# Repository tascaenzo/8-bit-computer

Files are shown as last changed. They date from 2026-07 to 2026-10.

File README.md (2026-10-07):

# CPU 8-bit

Repository di supporto alla serie didattica YouTube in cui viene progettata e costruita una CPU a 8 bit partendo dai blocchi logici fondamentali.

In questa fase il repository contiene documentazione, una prima ISA, esempi assembly, un assembler in C e strumenti di supporto per programmare le memorie della CPU.

## Contenuto

```text
.
├── docs/
├── examples/
│   └── assembly/
├── hardware/
│   ├── alu-pcb/
│   ├── data-bus-pcb/
│   ├── address-bus-pcb/
│   └── tang-nano-9k-video/
├── tools/
│   ├── assembler/
│   ├── cu-bytecode/
│   └── eeprom-programmer/
├── wiki/
│   ├── blog/
│   └── videos/
└── README.md
```

### `docs`

Contiene la documentazione tecnica della CPU:

- [`docs/isa.md`](docs/isa.md) definisce architettura, istruzioni e opcode;
- [`docs/assembly-language.md`](docs/assembly-language.md) definisce la sintassi dei programmi assembly.
- [`docs/control-unit-microcode.md`](docs/control-unit-microcode.md) definisce segnali e microsequenze della Control Unit.
- [`docs/video-hdmi.md`](docs/video-hdmi.md) definisce VRAM e uscita HDMI della Tang Nano 9K.
- [`docs/io-ps2-timer.md`](docs/io-ps2-timer.md) definisce registri I/O, tastiera PS/2 e timer della Tang Nano 9K.

### `examples/assembly`

Contiene programmi assembly didattici usati per provare l'assembler e spiegare le istruzioni della CPU.

### Schede PCB in `hardware`

Progetti KiCad e pacchetti Gerber per l'[ALU con LED e comandi locali](hardware/alu-pcb/rev-b/README.md),
il [bus dati a otto porte con monitor LED](hardware/data-bus-pcb/README.md)
e il [bus indirizzi a 16 bit](hardware/address-bus-pcb/README.md).
I due bus usano il layout slim del 7 ottobre 2026, entrambi **REV A**:
**235 × 40 mm** per i dati e **300 × 46 mm** per gli indirizzi,
con la firma «Progettato da Enzo Tasca» sul fronte, LED ravvicinati a gruppi
di quattro bit e uno switch SW1 per spegnere gli indicatori del bus.
ALU e bus dati hanno connettori dati compatibili; il bus indirizzi usa porte 2×10 dedicate. I controlli software sono
completati; i prototipi fisici devono ancora essere montati e collaudati.

### `hardware/tang-nano-9k-video`

Contiene il progetto Gowin per la Tang Nano 9K. Il primo milestone verifica
l'uscita HDMI prima di introdurre VRAM e interfaccia al bus TTL.

### `tools/assembler`

Contiene `cpu8asm`, l'assembler in C che traduce i programmi assembly in byte macchina.

### `tools/eeprom-programmer`

Contiene sketch e documentazione per programmare EEPROM parallele usate dalla CPU, come la AT28C64.

La guida passo passo per il programmatore AT28C64 con Arduino Mega e in:

```text
docs/at28c64-arduino-mega-programmer.md
```

### `tools/cu-bytecode`

Contiene `cpu8microcode`, il generatore C delle tre Control ROM e della ROM di
dispatch. La guida di build e la mappa dei bit sono in
[`tools/cu-bytecode/README.md`](tools/cu-bytecode/README.md).

### `tools/simulator-web`

Contiene il simulatore web step-by-step della ISA: permette di assemblare ed
eseguire programmi nel browser, osservando registri, flag, RAM e la memoria
video mappata nella FPGA. La guida di avvio è in
[`tools/simulator-web/README.md`](tools/simulator-web/README.md).

### `wiki/videos`

Contiene le trascrizioni autogenerate dei video della serie.

Le trascrizioni sono materiale grezzo: possono contenere errori di riconoscimento, frasi incomplete o termini tecnici interpretati male. Servono come base di lavoro per ricostruire gli argomenti trattati nei video.

### `wiki/blog`

Contiene articoli tecnici in italiano ricavati dalle trascrizioni e dagli argomenti gia affrontati.

Gli articoli seguono il percorso reale della serie e non anticipano parti non ancora consolidate.

## Argomenti documentati

Finora la documentazione copre:

- operazioni logiche della ALU: `AND`, `OR`, `XOR`, `NOR`, `NAND`, `XNOR`, `NOT`;
- pull-up, pull-down e comportamento dei livelli logici;
- buffer tri-state e collegamento al bus dati;
- somma binaria con half adder e full adder;
- complemento a due e numeri con segno;
- somma e sottrazione con il 74283;
- flag `Carry`, `Negative`, `Zero` e `Overflow`;
- operazioni di confronto tramite flag;
- codice operazione della ALU;
- segnale di clock;
- flip-flop `SR` e `D`.

## Convenzioni

- La documentazione principale e in italiano.
- I nomi tecnici possono restare in inglese quando corrispondono meglio a datasheet, segnali o architettura.
- Le trascrizioni autogenerate non sono considerate documentazione definitiva: vanno ripulite e corrette quando vengono trasformate in articoli.

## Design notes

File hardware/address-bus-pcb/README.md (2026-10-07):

# CPU8 — bus indirizzi a 16 bit, revisione A

Layout slim con LED compatti e switch del 7 ottobre 2026: **300 × 46 mm**, rispetto ai precedenti
240 × 60 mm. I due 74HCT244 seguono la fila degli otto connettori sul lato
destro. Serigrafia sul fronte: **Progettato da Enzo Tasca**. Revisione **A**.
Le piedinature elettriche restano uguali.

Scheda di distribuzione con **otto porte parallele**, **16 LED A15…A0**,
due buffer SN74HCT244N e una spia PWR. PCB **300 × 46 mm**, due strati,
componenti through-hole, altezza ridotta per una disposizione a vista nel case.

Le porte sono equivalenti. PC, MAR o IDX possono trasmettere un indirizzo;
RAM, ROM, decoder e altri moduli possono leggerlo contemporaneamente.
La scelta della sorgente è esterna: questa scheda non genera indirizzi e
non implementa il selettore della centralina.

## File da usare

- `CPU8_ADDRESS_BUS_REV_A_GERBER.zip`: file di produzione della scheda nuda.
- `CPU8_ADDRESS_BUS_REV_A_PROJECT.zip`: progetto modificabile e documentazione.
- `source/address_bus_rev_a.kicad_pro`: progetto da aprire in KiCad.
- `address_bus_rev_a_schematic.pdf`: schema elettrico, quattro pagine.
- `address_bus_rev_a_preview.png`: anteprima del PCB senza componenti montati.
- `address_bus_rev_a_layout.svg`: piste, piazzole e serigrafia.
- `BOM.csv`: componenti, package e dimensioni di montaggio.
- `verification/`: rapporti elettrici, di layout, di verifica digitale e manifest SHA-256.

I componenti vanno acquistati e saldati separatamente. Non è stato
eseguito alcun ordine presso un produttore.

## Connettori indirizzi J1…J8

Header maschi **2×10, passo 2,54 mm, non schermati**. Guardando il lato
componenti con il titolo in alto, il pin 1 quadrato è in alto a sinistra.
Le righe sono 1/2, 3/4, ecc. Collegare i cavi pin-a-pin, senza inversioni.

| Riga | Sinistra | Destra |
| --- | --- | --- |
| 1 | 1: A0 | 2: A1 |
| 2 | 3: A2 | 4: A3 |
| 3 | 5: A4 | 6: A5 |
| 4 | 7: A6 | 8: A7 |
| 5 | 9: A8 | 10: A9 |
| 6 | 11: A10 | 12: A11 |
| 7 | 13: A12 | 14: A13 |
| 8 | 15: A14 | 16: A15 |
| 9 | 17: GND | 18: GND |
| 10 | 19: GND | 20: GND |

A0 è il bit meno significativo dell'indirizzo; A15 è il più significativo.
Queste porte **non contengono +5 V** e non hanno la stessa piedinatura delle
porte da 10 pin del bus dati. A0…A15 qui indicano indirizzi, non l'operando
A della ALU: non collegare queste porte agli ingressi A/B dell'ALU.

## Alimentazione J9

Header 2×2 con pin **1/3 = +5 V**, **2/4 = GND**. È la stessa piedinatura
del J9 del bus dati e del J6 dell'ALU. Alimentare tutte le schede da una
sorgente comune a 5 V regolati e collegare le masse. I moduli ricevono
+5 V dai loro connettori di alimentazione, non attraverso le porte indirizzi.
I pin duplicati di J9 appartengono alla stessa rete.

## Monitor LED e trasmissione degli indirizzi

U1 legge A0…A7 e U2 legge A8…A15. Le loro uscite pilotano soltanto i LED
attraverso resistori da 2,2 kΩ; nessuna uscita del monitor pilota il bus.
SW1 pilota insieme i pin 1 e 19 di U1 e U2: ON li porta a GND e abilita
i 16 LED; OFF li lascia alti tramite R18 da 10 kΩ e disabilita le uscite LED.
I due buffer separano il carico dei LED dalle linee di indirizzo; **non
rigenerano il segnale lungo i collegamenti del bus**. La piedinatura segue
il [datasheet TI SN74HCT244](https://www.ti.com/lit/ds/symlink/sn74hct244.pdf).

RN1 e RN2 aggiungono un pull-down da 10 kΩ per ogni bit, con carico
nominale di 0,5 mA per linea alta a 5 V. Con la scheda da sola e senza
una sorgente, i LED indirizzo restano spenti. Questo non distingue un
indirizzo 0000 trasmesso da un bus non pilotato.

I LED sono ordinati da sinistra **A15, A14, …, A1, A0** e mostrano il valore
istantaneo, senza memorizzarlo. Con dati statici o clock manuale si legge
il numero binario; a velocità elevate si vede una luminosità media. Per
catturare un indirizzo a un preciso istante serve un latch o un analizzatore.

**Abilitare una sola sorgente di indirizzo alla volta.** Le uscite di PC,
MAR e IDX devono raggiungere il bus tramite buffer tri-state o un selettore
appropriato. Non collegare in parallelo tre uscite push-pull sempre attive.
RAM e ROM leggono gli indirizzi dai propri ingressi; i comandi di memoria
/CE, /OE, /WE e i dati D0…D7 viaggiano separatamente.

Nel progetto CPU8, `ADDR_SEL` sceglie `00=IDX`, `01=PC`, `10=MAR`,
`11=nessuna sorgente`: vedere [la centralina](../../docs/control-unit-microcode.md).
Il decoder di queste abilitazioni resta sui moduli o nella centralina,
non su questa scheda bus. La mappa degli indirizzi e la selezione RAM/ROM/I/O
restano compito dei rispettivi decoder.

Esempio di assegnazione, modificabile perché tutte le porte sono uguali:

| Porta | Modulo |
| --- | --- |
| J1 | PC, uscita tri-state |
| J2 | MAR, uscita tri-state |
| J3 | IDX, uscita tri-state |
| J4 | RAM, ingressi indirizzo |
| J5 | ROM, ingressi indirizzo |
| J6 | Decoder di indirizzi |
| J7 | Modulo I/O o video, con adattamento dei livelli dove necessario |
| J8 | Espansione o strumento di misura |

Il bus è a 5 V: per FPGA e dispositivi a 3,3 V usare adattamento dei livelli
compatibile con i dispositivi effettivi. Iniziare con pochi moduli e cavi
corti. Frequenza massima, integrità del segnale e carichi dei cavi non sono
stati misurati sul prototipo.

## LED ravvicinati e interruttore SW1

I LED hanno un interasse di **4 mm**, con **2 mm aggiuntivi ogni quattro bit**:
A15 A14 A13 A12 | A11 A10 A9 A8 | A7 A6 A5 A4 | A3 A2 A1 A0.
I LED dati/indirizzo hanno i piedini disposti verticalmente, distanti 2,54 mm:
**pin 1 catodo in alto, pin 2 anodo in basso**. PWR mantiene i piedini
orizzontali con catodo a sinistra. Le piazzole quadrate identificano il pin 1.

**SW1 = C&K SDA01H0BD**, SPST a una posizione, through-hole, file distanti
7,62 mm; pin 1 = `LED_OE_n`, pin 2 = GND. **ON chiude il contatto**.
R18 è un resistore assiale **10 kΩ**, 1/4 W, passo 7,62 mm, tra +5 V e OE_n.
Un solo switch governa tutti i buffer LED di questa scheda.

- **ON:** OE_n basso; i LED mostrano i bit del bus.
- **OFF:** OE_n alto; le uscite dei 74HCT244 sono in alta impedenza e i LED
  dei bit sono inattivi. La spia PWR resta accesa.
- L'interruttore non interrompe dati, indirizzi o alimentazione degli altri
  moduli; i pull-down del bus restano presenti. Non è un interruttore generale.

Il livello alto/basso e lo stato tri-state seguono il
[datasheet TI SN74HCT244](https://www.ti.com/lit/ds/symlink/sn74hct244.pdf).
Ingombro e piedinatura di SW1 seguono il
[datasheet C&K SDA](https://www.ckswitches.com/media/1327/sda.pdf).

## Distinta e montaggio

52 componenti: due SN74HCT244N, otto header 2×10, un header 2×2, 17 LED
verdi da 3 mm, 17 resistori da 2,2 kΩ, due reti resistive e tre condensatori, più SW1 e il pull-up R18 da 10 kΩ.
Aggiungere **due zoccoli DIP-20**, con file distanti 7,62 mm.

- U1/U2: package PDIP-20, tacca in alto; pin 1 quadrato.
- D1…D16: rispettivamente LED dei bit A0…A15. Seguire il nome A del bit
  sotto il LED: ad esempio il componente D16 è la spia A15.
- D17: spia PWR. LED passo 2,54 mm: **pin 1 catodo**, pin 2 anodo;
  la linea piatta in serigrafia indica il catodo.
- R1…R17: 2,2 kΩ, 1/4 W, passo 7,62 mm, corpo entro 6,3 × 2,5 mm.
  Usare LED ad alta efficienza: corrente nell'ordine di 1 mA.
- RN1/RN2: **SIP-9 bussed, otto resistenze da 10 kΩ**, comune al pin 1,
  passo 2,54 mm. Le reti a resistenze isolate non sono compatibili.
- C1/C2: 100 nF ceramici, passo 2,50 mm, corpo entro 4 × 3 mm.
- C3: 10 µF, almeno 16 V, passo 2,50 mm, diametro entro 5 mm;
  **pin 1 positivo**, pin 2 GND. Il PCB riporta il simbolo +.
- I pin GND sono collegati ai piani con connessioni solide: usare una
  punta da saldatura adeguata al trasferimento di calore.

## Ordine e verifiche

| Parametro | Valore |
| --- | --- |
| Dimensioni | **300 × 46 mm** |
| Materiale / spessore | FR-4 / 1,6 mm |
| Rame | Due strati, 1 oz |
| Maschera / serigrafia | Verde / bianca sul fronte |
| Finitura | HASL senza piombo o ENIG |
| Assemblaggio / stencil | Nessuno, montaggio manuale |
| Piste / clearance | 0,30 mm, restringimenti fino a 0,15 mm / 0,25 mm |
| Minimo assoluto di clearance | 0,20 mm |
| Via | Diametro 0,70 mm, foro 0,30 mm |
| Fori componenti | 0,80 e 0,90 mm, metallizzati |
| Montaggio | Quattro fori da 3,20 mm, non metallizzati |

Caricare il solo ZIP Gerber e controllare nell'anteprima del produttore
300 × 46 mm, due strati di rame e i due file di foratura.

- ERC: **0 violazioni**.
- DRC: **0 violazioni**, **0 collegamenti mancanti**.
- Parità PCB/schema: **0 problemi**.
- Verifica di **131.072 casi**, tutti i 65.536 indirizzi da 0000 a FFFF
  con SW1 ON e OFF (indicatori inattivi e porte bus invariate quando OFF),
  con controllo delle otto porte, polarità dei LED e isolamento del monitor.
- Export KiCad 10.0.7 e integrità dei pacchetti ZIP verificata.

**Il prototipo fisico deve ancora essere montato e collaudato.** Prima di
inserire gli IC verificare alimentazione e polarità degli zoccoli. Accendere
inizialmente con corrente limitata e moduli esterni scollegati; provare poi
una sola sorgente con indirizzi statici prima di aggiungere gli altri moduli.

| Indirizzo di prova | LED accesi |
| --- | --- |
| 0000 | Nessuno, PWR resta acceso |
| 8001 | A15 e A0 |
| 5555 | A14, A12, A10, A8, A6, A4, A2, A0 |
| AAAA | A15, A13, A11, A9, A7, A5, A3, A1 |
| FFFF | Tutti i 16 LED indirizzo |

Per le prove dei LED portare **SW1 ON**. Gli indirizzi nella tabella sono esadecimali. I LED non provano da soli
che una sorgente sia disabilitata o che non esista un conflitto tra driver.

Gli script in `tools/` documentano generazione e controlli. Il generatore
preserva il PCB esistente salvo `--rebuild-unrouted`; quel comando richiede
nuovo instradamento DSN/SES, controlli ed export. Per le normali modifiche
usare i sorgenti KiCad finali, preservando le piste.

## Disposizione meccanica del layout slim

- Quattro fori di montaggio da 3,2 mm: (4,4), (296,4), (4,42), (296,42) mm; origine nell'angolo superiore sinistro.
- J1…J8: pin 1 a x=10,35,60,85,110,135,160,185 mm, y=8 mm.
- U1/U2: pin 1 rispettivamente (217,8) e (242,8) mm.
- LED da sinistra A15…A0, pin 1 a x=68,72,76,80,86,90,94,98,104,108,112,116,122,126,130,134 mm e y=39 mm; alimentazione J9 a destra.
- Componenti sempre sul fronte, integrati con tacca verso l'alto. I valori
  di header, resistori, reti resistive e switch sono sul layer F.Fab.
  I riferimenti dei LED indirizzo sono su F.Fab, lasciando soltanto A15…A0 sul fronte.
- Lo spazio per i corpi dei connettori è riferito agli header non schermati
  della BOM; verificare l'ingombro dei terminali del cavo scelti per il case.

Questa revisione A sostituisce il precedente layout A da 240 × 60 mm.
Il manifest riporta layout_id `2026-10-07-slim-led-switch` per distinguerli: usare
solo i Gerber e le forature rigenerati insieme in questa consegna.

Questa consegna sostituisce anche il precedente layout slim senza SW1.
Il manifest identifica `2026-10-07-slim-led-switch`: usare gli ZIP rigenerati
insieme allo schema e alla BOM di questa versione. Le dimensioni esterne
e i fori di montaggio restano quelli del layout slim.

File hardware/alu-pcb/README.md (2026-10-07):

# CPU8 — ALU, revisione corrente B

Il progetto corrente è in [rev-b](rev-b/README.md). Include LED degli
operandi, dei flag e dell'operazione, più selezione esterna o standalone.

- [Gerber per la produzione](rev-b/CPU8_ALU_REV_B_GERBER.zip)
- [Progetto KiCad completo](rev-b/CPU8_ALU_REV_B_PROJECT.zip)
- [Istruzioni e distinta componenti](rev-b/README.md)

La revisione A e i suoi export sono stati eliminati.

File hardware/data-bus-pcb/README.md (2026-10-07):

# CPU8 — bus dati a 8 bit, revisione A

Layout slim con LED compatti e switch del 7 ottobre 2026: **235 × 40 mm**, rispetto ai precedenti 180 × 60 mm.
Il 74HCT244 segue la fila degli otto connettori sul lato destro.
Serigrafia sul fronte: **Progettato da Enzo Tasca**. Questa versione usa la
revisione **A**, come richiesto, e sostituisce il precedente layout B.
Le piedinature elettriche rimangono compatibili con ALU J4/J6.

PCB da saldare con **otto porte bidirezionali** J1…J8, **otto LED D7…D0**,
un buffer per gli indicatori e una spia PWR. Tutte le porte sono collegate
in parallelo: qualunque porta può essere usata da un modulo che legge
oppure da un modulo che scrive. Il connettore dati è compatibile con
**J4 dell'ALU revisione A** del repository.

La scheda distribuisce dati e massa. L'alimentazione del monitor entra da
J9; il clock, i comandi LOAD e le abilitazioni delle uscite viaggiano
separatamente, dalla centralina ai rispettivi moduli.

## File consegnati

- `CPU8_DATA_BUS_REV_A_GERBER.zip`: da caricare sul servizio di produzione PCB.
- `CPU8_DATA_BUS_REV_A_PROJECT.zip`: sorgenti KiCad, librerie, schema, BOM e rapporti.
- `source/data_bus_rev_a.kicad_pro`: progetto da aprire in KiCad.
- `data_bus_rev_a_schematic.pdf`: schema elettrico, tre pagine.
- `data_bus_rev_a_preview.png`: anteprima della scheda nuda, senza modelli dei componenti.
- `data_bus_rev_a_layout.svg`: piste e serigrafia.
- `BOM.csv`: distinta con valori, package e dimensioni per il montaggio.
- `verification/`: controlli elettrici, di layout, di collegamento e integrità degli export.

Lo ZIP Gerber ordina una **scheda vuota**: i componenti e gli zoccoli vanno
acquistati e saldati separatamente. Non è stato effettuato alcun ordine.

## Piedinatura

Guardando il lato componenti con il titolo in alto, il pin 1 è la piazzola
quadrata in alto a sinistra. Tutti i connettori hanno due colonne a passo
2,54 mm: righe 1/2, 3/4, 5/6, ecc.

| Porta dati J1…J8 | Colonna sinistra | Colonna destra |
| --- | --- | --- |
| Riga 1 | Pin 1: D0 | Pin 2: D1 |
| Riga 2 | Pin 3: D2 | Pin 4: D3 |
| Riga 3 | Pin 5: D4 | Pin 6: D5 |
| Riga 4 | Pin 7: D6 | Pin 8: D7 |
| Riga 5 | Pin 9: GND | Pin 10: GND |

**Le porte dati non contengono +5 V.** Usare header maschi non schermati
2×5 e cavi con collegamento pin-a-pin. Non ruotare il connettore di 180°;
controllare i cavi con il tester prima dell'accensione.

| J9 POWER_5V | Colonna sinistra | Colonna destra |
| --- | --- | --- |
| Riga 1 | Pin 1: +5 V | Pin 2: GND |
| Riga 2 | Pin 3: +5 V | Pin 4: GND |

J9 è un header 2×2 con la stessa piedinatura di J6 dell'ALU. Alimentare
monitor e moduli da una sorgente comune a **5 V regolati** e collegare le
masse. I moduli ricevono +5 V dai loro connettori di alimentazione, non
attraverso J1…J8. I pin duplicati di J9 sono la stessa rete, non due ingressi
di alimentazione indipendenti.

## Come si legge e si scrive sul bus

**Lettura:** collegare gli ingressi dati di un registro o di un altro
circuito a una porta. Quel modulo acquisisce il dato quando riceve il suo
clock/comando LOAD. Il bus non genera questi comandi.

**Scrittura:** collegare le uscite di un buffer tri-state del modulo a una
porta. La centralina abilita quel buffer quando il modulo deve trasmettere
il dato; lo disabilita negli altri momenti. Esempi sono un registro con
buffer 74HCT244/245, l'uscita della RAM opportunamente controllata o J4
dell'ALU. **Può essere abilitato un solo modulo che scrive alla volta**;
più moduli possono leggere contemporaneamente.

Non collegare direttamente sul bus uscite push-pull sempre attive di
registri o porte logiche. Questa scheda non contiene un arbitro e non
rileva due moduli che pilotano il bus contemporaneamente. Anche se i LED
mostrano un valore, non significa che le abilitazioni siano corrette.

Il monitor U1 è un [SN74HCT244N](https://www.ti.com/lit/ds/symlink/sn74hct244.pdf):
i suoi ingressi leggono il bus, le sue uscite alimentano soltanto i LED.
Il carico dei LED è quindi separato dalle linee dati. Le due abilitazioni
del monitor, pin 1 e 19, sono collegate alla rete `LED_OE_n`: **SW1 ON**
le porta a GND e abilita gli indicatori; **SW1 OFF** le lascia alte tramite
R10 da 10 kΩ e disabilita le uscite LED. Nessuna uscita attiva del monitor pilota D0…D7.

RN1 aggiunge un pull-down da 10 kΩ per bit, con carico nominale di 0,5 mA
quando un bit è a 5 V. Con questa scheda da sola e senza un trasmettitore,
i LED dati sono spenti. Gli indicatori non distinguono uno zero trasmesso
da un bus non pilotato. Con moduli esterni, verificare il carico totale e
le tensioni effettive del bus durante il collaudo.

I LED visualizzano il valore istantaneo e non lo memorizzano: sono utili
con dati statici e clock manuale. A velocità elevate l'occhio vede una
luminosità media; per catturare un byte a un preciso istante occorre un
registro o un analizzatore logico. La scheda non include un latch del display.

Gli ingressi del monitor accettano livelli TTL. Il bus resta un'interfaccia
logica a 5 V: per FPGA e altri dispositivi a 3,3 V usare adattamento dei
livelli adeguato ai dispositivi effettivi. Nessuna frequenza massima è
stata misurata. Per iniziare usare pochi moduli e cavi corti.

## Collegamento all'ALU esistente

1. Collegare **ALU J4 → BUS J1**, pin-a-pin. J2…J8 restano disponibili.
2. Alimentare **ALU J6** e **BUS J9** con la stessa sorgente a 5 V e GND.
3. Sul bus mettere **SW1 ON** per accendere gli indicatori. Sull'ALU mettere SW4 ON per gli operandi locali, inizialmente SW5 OFF.
4. Impostare A = `00000101`, B = `00000011`, OP = `0111` (ADD).
5. Abilitare l'ALU con SW5 ON: 5 + 3 = 8, quindi si accende **D3** sul bus.
6. Disabilitare l'ALU prima di abilitare un altro modulo che scrive.

Gli ingressi A/B dell'ALU, J1/J2, normalmente ricevono i valori dai
registri A e B: **non sono le porte per l'uscita dell'ALU sul bus**.
J7 dell'ALU è un'uscita del risultato interno sempre attiva: non usarla
come porta bus al posto di J4.

Con un registro collegato, il percorso è:

```text
ALU J4 ── BUS J1 ── linee D0…D7 comuni ── BUS J2 ── ingressi del registro
                     │
                     └── U1 ── resistori ── LED D7…D0
```

Per far leggere quel byte al registro, la centralina deve inviare al
registro il suo comando di acquisizione. Per farlo scrivere in un altro
momento, serve un'uscita tri-state del registro controllata separatamente.

## LED ravvicinati e interruttore SW1

I LED hanno un interasse di **4 mm**, con **2 mm aggiuntivi ogni quattro bit**:
D7 D6 D5 D4 | D3 D2 D1 D0.
I LED dati/indirizzo hanno i piedini disposti verticalmente, distanti 2,54 mm:
**pin 1 catodo in alto, pin 2 anodo in basso**. PWR mantiene i piedini
orizzontali con catodo a sinistra. Le piazzole quadrate identificano il pin 1.

**SW1 = C&K SDA01H0BD**, SPST a una posizione, through-hole, file distanti
7,62 mm; pin 1 = `LED_OE_n`, pin 2 = GND. **ON chiude il contatto**.
R10 è un resistore assiale **10 kΩ**, 1/4 W, passo 7,62 mm, tra +5 V e OE_n.
Un solo switch governa tutti i buffer LED di questa scheda.

- **ON:** OE_n basso; i LED mostrano i bit del bus.
- **OFF:** OE_n alto; le uscite dei 74HCT244 sono in alta impedenza e i LED
  dei bit sono inattivi. La spia PWR resta accesa.
- L'interruttore non interrompe dati, indirizzi o alimentazione degli altri
  moduli; i pull-down del bus restano presenti. Non è un interruttore generale.

Il livello alto/basso e lo stato tri-state seguono il
[datasheet TI SN74HCT244](https://www.ti.com/lit/ds/symlink/sn74hct244.pdf).
Ingombro e piedinatura di SW1 seguono il
[datasheet C&K SDA](https://www.ckswitches.com/media/1327/sda.pdf).

## Componenti e montaggio

33 componenti: un SN74HCT244N, otto connettori 2×5, un connettore 2×2,
nove LED verdi da 3 mm, nove resistori da 2,2 kΩ, una rete resistiva SIP-9,
un condensatore ceramico, un elettrolitico, SW1 e un pull-up da 10 kΩ. Aggiungere uno zoccolo DIP-20
con file distanti 7,62 mm. Tutti i componenti sono through-hole.

- **U1:** PDIP-20, tacca in alto e pin 1 quadrato. Non sostituire con SOIC.
- **D1…D8:** rispettivamente D0…D7; sul PCB la fila è ordinata da sinistra
  **D7, D6, D5, D4, D3, D2, D1, D0**. La sigla componente D8 identifica
  quindi il LED del bit D7: seguire il testo del bit sotto ciascun LED.
- **D9:** spia PWR. Tutti i LED hanno **pin 1 catodo**, **pin 2 anodo**;
  la linea piatta in serigrafia indica il catodo. Passo 2,54 mm.
- **R1…R9:** 2,2 kΩ, 1/4 W, passo 7,62 mm. Corrente LED nell'ordine
  di 1 mA; usare LED ad alta efficienza.
- **RN1:** rete **bussed SIP-9, otto resistenze da 10 kΩ**, comune al pin 1
  quadrato verso GND. Passo 2,54 mm. Una rete con resistenze isolate non
  è compatibile.
- **C1:** 100 nF ceramico, passo 2,50 mm, corpo entro 4 × 3 mm.
- **C2:** 10 µF, almeno 16 V, passo 2,50 mm, diametro entro 5 mm;
  **pin 1 positivo**, pin 2 GND. Il PCB riporta anche il simbolo +.
- I piani GND usano connessioni solide: saldare i pin di massa con una
  punta adeguata e sufficiente trasferimento di calore.

## Ordine PCB e verifiche

| Parametro | Valore |
| --- | --- |
| Dimensioni | **235 × 40 mm** |
| Rame | Due strati, 1 oz |
| Materiale / spessore | FR-4 / 1,6 mm |
| Maschera / serigrafia | Verde / bianca sul fronte |
| Finitura | HASL senza piombo o ENIG |
| Assemblaggio / stencil | Nessuno, montaggio manuale |
| Piste | 0,30 mm, restringimenti minimi 0,15 mm |
| Clearance | 0,25 mm; minimo assoluto di progetto 0,20 mm |
| Via | Diametro 0,70 mm, foro 0,30 mm |
| Fori componenti | 0,80 e 0,90 mm, metallizzati |
| Montaggio | Quattro fori 3,20 mm, non metallizzati |

Caricare il solo ZIP Gerber e controllare che l'anteprima del produttore
riconosca 235 × 40 mm, due strati di rame e i due file di foratura.

- ERC: **0 violazioni**.
- DRC: **0 violazioni**, **0 collegamenti mancanti**.
- Parità PCB/schema: **0 problemi**.
- Verifica di **512 casi**: 256 valori del bus × due stati di SW1; display
  corretto quando ON, uscite LED in alta impedenza quando OFF, porte bus invariate.
- Controllo dell'isolamento del monitor: nessuna sua uscita pilota il bus.
- Export KiCad 10.0.7, pacchetti con controllo d'integrità e manifest SHA-256.

**Il prototipo fisico non è ancora stato montato e collaudato.** Prima di
inserire U1 verificare polarità e alimentazione dello zoccolo. Accendere
inizialmente con alimentatore a corrente limitata e gli altri moduli
scollegati. Provare poi un solo trasmettitore, con dati statici, prima di
aggiungere registri e clock. Misurare livelli e tempi sotto carico prima
di aumentare la frequenza.

Gli script in `tools/` documentano costruzione e controlli. Il generatore
ricrea una scheda **senza piste** soltanto con `--rebuild-unrouted`;
per le normali modifiche aprire i sorgenti KiCad finali e preservare le piste.
La ricostruzione completa richiede nuovo export XML, `prepare_board.py`
con pcbnew, instradamento DSN/SES, `finish_board.py`, verifiche ed export.

## Disposizione meccanica del layout slim

- Quattro fori di montaggio da 3,2 mm: (4,4), (231,4), (4,36), (231,36) mm; origine nell'angolo superiore sinistro.
- J1…J8: pin 1 a x=10,33,56,79,102,125,148,171 mm, y=10 mm.
- U1: pin 1 a (195,10) mm; RN1 a destra dei connettori.
- LED da sinistra D7…D0, pin 1 a x=72,76,80,84,90,94,98,102 mm e y=30 mm; alimentazione J9 a destra.
- Componenti sempre sul fronte, integrati con tacca verso l'alto. I valori
  di header, rete resistiva e switch sono sul layer F.Fab. I riferimenti
  dei LED dati sono su F.Fab, lasciando soltanto D7…D0 visibili sul fronte.
- Lo spazio per i corpi dei connettori è riferito agli header non schermati
  della BOM; verificare l'ingombro dei terminali del cavo scelti per il case.

Usare solo lo ZIP Gerber di questa consegna: gli export precedenti della
revisione B non rappresentano queste dimensioni.

Questa consegna sostituisce anche il precedente layout slim senza SW1.
Il manifest identifica `2026-10-07-slim-led-switch`: usare gli ZIP rigenerati
insieme allo schema e alla BOM di questa versione. Le dimensioni esterne
e i fori di montaggio restano quelli del layout slim.

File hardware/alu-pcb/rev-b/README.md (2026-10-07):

# CPU8 — PCB ALU rev. B

Pacchetto per fabbricare una **scheda nuda da saldare**, con sorgenti KiCad.
Versione del 7 ottobre 2026: ALU combinatoria a 8 bit, logica **74HCT a 5 V**,
registri RA/RB e registro dei flag **esterni**. La revisione B aggiunge indicatori e comandi locali alla revisione A.

## File da usare

- `CPU8_ALU_REV_B_GERBER.zip`: caricare questo ZIP nel preventivatore PCB.
- `CPU8_ALU_REV_B_PROJECT.zip`: progetto modificabile e documentazione.
- `source/alu_rev_b.kicad_pro`: aprire in KiCad per accedere a schema e PCB.
- `alu_rev_b_schematic.pdf`: schema completo, con tutti i pin e le reti.
- `BOM.csv`: componenti da acquistare per il montaggio manuale.
- `alu_rev_b_preview.png`: anteprima della scheda nuda.
- `alu_rev_b_layout.svg`: visualizzazione delle piste e della serigrafia.

Lo ZIP Gerber non include i componenti: non è un ordine di assemblaggio.
Non sono stati effettuati ordini o caricamenti sui siti dei produttori.

## Parametri per l'ordine

| Parametro | Impostazione |
| --- | --- |
| Dimensioni | 290 × 300 mm |
| Materiale | FR-4 |
| Strati rame | 2 |
| Spessore | 1,6 mm |
| Rame | 1 oz |
| Maschera | Verde, entrambi i lati |
| Serigrafia | Bianca, fronte |
| Finitura | HASL senza piombo oppure ENIG |
| Assemblaggio | Nessuno; componenti saldati a mano |
| Stencil | Nessuno |
| Via | Diametro rame 0,70 mm, foro 0,30 mm |
| Fori componenti | 0,80 e 0,90 mm, metallizzati |
| Fori montaggio | Quattro fori da 3,20 mm, non metallizzati |

Le piste sono generalmente da 0,30 mm, con restringimenti locali fino a
0,15 mm. Le regole di clearance del progetto sono 0,25 mm; clearance minima
assoluta verificata 0,20 mm. Gli anelli delle via sono da 0,20 mm.
Le capacità pubblicate da [JLCPCB](https://jlcpcb.com/capabilities/Capabilities)
e [PCBWay](https://www.pcbway.com/capabilities.html) consentono queste dimensioni
con rame da 1 oz. Verificare che l'anteprima del produttore riconosca tutti
i layer e i due file di foratura e mostri 290 × 300 mm.

## Cosa contiene la scheda

Dieci operazioni, due sommatori a quattro bit in cascata, selezione del
risultato mediante otto multiplexer, buffer tri-state del bus e flag
combinatori C/Z/N/O. Nessun clock è necessario sulla scheda: i registri che
catturano dati e flag si trovano all'esterno.

La selezione mediante multiplexer modifica l'implementazione fisica descritta
negli articoli con decoder e buffer separati, mantenendo la semantica della ISA.
Non si tratta di una copia delle connessioni della millefori esistente.

| OP3 OP2 OP1 OP0 | Operazione | Risultato |
| --- | --- | --- |
| 0000 | AND | A AND B |
| 0001 | OR | A OR B |
| 0010 | XOR | A XOR B |
| 0011 | NOR | NOT(A OR B) |
| 0100 | NAND | NOT(A AND B) |
| 0101 | XNOR | NOT(A XOR B) |
| 0110 | NOT | NOT A |
| 0111 | ADD | A + B, modulo 256 |
| 1000 | SUB | A - B, modulo 256 |
| 1001 | CMP | Sottrazione interna; bus disabilitato |
| 1010–1111 | Riservate | Bus disabilitato; flag non definiti per la ISA |

C indica carry in ADD e **borrow** in SUB/CMP. Z indica risultato zero;
N è il bit 7 del risultato; O indica overflow signed. C e O sono azzerati
per le operazioni logiche. I flag derivano dal risultato interno, anche quando
il buffer del bus è disabilitato.

## LED e modalità autonoma

- **16 LED verdi** mostrano A7…A0 e B7…B0 dopo la selezione della sorgente.
- **4 LED gialli** mostrano C, Z, N e O del risultato interno.
- **10 LED blu** mostrano AND, OR, XOR, NOR, NAND, XNOR, NOT, ADD, SUB e CMP.
  Gli opcode riservati non accendono alcun LED di operazione.
- **SW4 OFF = esterna**, **SW4 ON = locale**. Sei 74HCT157 commutano tutti
  i 21 segnali: A, B, opcode e ALU_EN_n. Le due sorgenti restano separate;
  gli interruttori non portano +5 V sulle uscite dei moduli esterni.
- **SW1** imposta A, **SW2** B: da sinistra bit 7, 6, 5, 4, 3, 2, 1, 0.
  **SW3** imposta l'opcode: da sinistra OP3, OP2, OP1, OP0.
  Per ciascun contatto, OFF = 0 e ON = 1.
- **SW5 OFF** disabilita il bus in modalità locale; **SW5 ON** lo abilita.
  CMP e gli opcode riservati mantengono comunque J4 in alta impedenza.
  In modalità esterna SW5 non interviene: decide J3 pin 5.

Per il primo test standalone collegare solo J6 a 5 V regolati e GND,
lasciare J4 scollegato, mettere SW4 ON e scegliere A/B/OP mediante SW1–SW3.
Il risultato interno è disponibile su J7; i LED indicano operandi, flag e
operazione. Questa revisione non include otto LED di risultato.
Esempio ADD: SW1 = 11111111, SW2 = 00000001, SW3 = 0111:
si accendono ADD, C e Z; N/O sono spenti; J7 vale 00.

I LED di A/B/flag sono pilotati da tre buffer 74HCT244 dedicati;
i due 74HCT138 decodificano l'operazione. Ogni LED ha una resistenza da
2,2 kΩ, con corrente nell'ordine di 1 mA: usare LED ad alta efficienza.
I flag sono combinatori e non memorizzati: possono cambiare durante lo
spostamento dei DIP switch. Cambiare sorgente con il bus disabilitato
su entrambe le sorgenti e attendere l'assestamento prima della cattura.

## Connettori

Tutti i connettori hanno due colonne, passo 2,54 mm. Guardando il lato componenti,
con il testo della scheda in alto, il pin 1 è la piazzola quadrata in alto a
sinistra. La prima riga contiene 1/2, la seconda 3/4, e così via.
La piedinatura è specifica di questa scheda: preparare i cavi di conseguenza.

| Connettore | Pin | Segnali |
| --- | --- | --- |
| J1 A_INPUT | 1–8; 9–10 | A0…A7; GND, GND |
| J2 B_INPUT | 1–8; 9–10 | B0…B7; GND, GND |
| J3 CONTROL | 1, 2, 3, 4 | OP0, OP1, OP2, OP3 |
| J3 CONTROL | 5; 6–8 | ALU_EN_n; GND, GND, GND |
| J4 DATA_BUS | 1–8; 9–10 | D0…D7; GND, GND |
| J5 FLAGS_CZNO | 1–6 | C, Z, N, O, GND, GND |
| J6 POWER_5V | 1–4 | +5V, GND, +5V, GND |
| J7 RESULT_TEST | 1–8; 9–10 | R0…R7 interni; GND, GND |

ALU_EN_n = 1 disabilita l'uscita sul bus. ALU_EN_n = 0 la abilita solo
per OP 0…8; CMP e gli opcode riservati lasciano comunque D in alta impedenza.
Un pull-up da 4,7 kΩ disabilita l'uscita quando il controllo è scollegato.
A/B/opcode hanno pull-down da 10 kΩ.

J5 e J7 sono uscite push-pull: usarle come ingressi di altri circuiti o punti
di misura, senza collegarle a un bus pilotato da altre sorgenti. J4 è l'unica
uscita dati tri-state. Collegare le masse dei moduli.

Gli ingressi HCT accettano livelli TTL, ma alimentare questa scheda con 5 V
regolati; non collegare le sue uscite da 5 V direttamente a una FPGA a 3,3 V.
La compatibilità e il carico dei moduli esterni vanno verificati con le sigle
complete degli integrati effettivamente utilizzati.

## Componenti e montaggio

La distinta contiene 172 componenti: 45 IC, 45 condensatori da 100 nF, un
condensatore da 10 µF, sei reti resistive, 33 resistori, sette connettori,
30 LED e cinque DIP switch. Aggiungere **23 zoccoli DIP-14, 18 DIP-16 e quattro DIP-20**, tutti larghi 7,62 mm.
Non sostituire i package DIP con SOIC. Per i multiplexer utilizzare CD74HCT151E:
la distinzione fra uscita diretta Y (pin 5) e complementare W (pin 6) segue
il datasheet TI attuale.

- Orientare la tacca degli IC verso l'alto; il pin 1 ha piazzola quadrata.
- RN1…RN6 devono essere **reti bussed SIP-9**, comune al pin 1:
  otto resistenze da 10 kΩ verso il comune. Le reti a resistenze isolate
  non sono compatibili.
- C46 è il condensatore elettrolitico da 10 µF: **pin 1 positivo**, pin 2 GND.
- C1…C45 sono ceramici non polarizzati, passo 2,50 mm e corpo entro 4 × 3 mm.
- SW1/SW2: C&K **SDA08H0BD**; SW3: **SDA04H0BD**;
  SW4/SW5: **SDA01H0BD**, versioni through-hole. Passo contatti 2,54 mm,
  distanza fra le file 7,62 mm, contatti SPST opposti. Orientare il corpo
  come indicato in serigrafia e verificare ON prima di saldare.
- LED da 3 mm, passo 2,54 mm: **pin 1 K/catodo**, **pin 2 A/anodo**.
  Il catodo è indicato dalla linea piatta in serigrafia. Nelle spie di
  operazione il catodo è collegato al decoder, non direttamente a GND.
- R1/R3 sono 4,7 kΩ, R2 è 10 kΩ, R4…R33 sono 2,2 kΩ;
  resistori assiali 1/4 W, passo 7,62 mm.
- U34…U39: **SN74HCT157N**; U44/U45: **SN74HCT138N**;
  U33/U40/U41/U42: **SN74HCT244N**, package PDIP.
- Le connessioni al piano di massa sono solide. Saldare i pin GND con
  una punta adeguata e sufficiente trasferimento di calore.

## Verifiche effettuate e collaudo

- Simulazione statica a livello di pin degli IC su **4.194.304 combinazioni**
  A/B/OP/enable in entrambe le modalità, con sorgente inattiva complementata, comprese le operazioni valide, flag e stato del buffer.
- ERC dello schema: **0 violazioni**.
- DRC del PCB: **0 violazioni**, **0 collegamenti mancanti**.
- Corrispondenza PCB/schema: **0 problemi**.
- Esportazione Gerber e foratura tramite KiCad 10.0.7.

I rapporti sono nella cartella `verification`. Questi controlli verificano
il progetto digitale e il layout; **nessun prototipo fisico è stato montato
né collaudato**. La frequenza massima, i carichi dei cavi e i tempi di
assestamento non sono stati misurati: iniziare con operandi e opcode statici,
poi con clock manuale e misurare prima di aumentare la frequenza.

Prima di inserire gli IC, controllare il montaggio e l'alimentazione degli
zoccoli. Eseguire i primi test con un alimentatore da banco a corrente limitata.
Disabilitare l'uscita durante il cambio di opcode e attendere l'assestamento
prima che i registri esterni catturino risultato e flag. Nessun altro modulo
può pilotare J4 mentre questa ALU è abilitata.

| Operazione | A | B | R interno | C | Z | N | O |
| --- | --- | --- | --- | --- | --- | --- | --- |
| AND | A5 | 3C | 24 | 0 | 0 | 0 | 0 |
| ADD | FF | 01 | 00 | 1 | 1 | 0 | 0 |
| ADD | 7F | 01 | 80 | 0 | 0 | 1 | 1 |
| SUB | 05 | 0A | FB | 1 | 0 | 1 | 0 |
| SUB | 80 | 01 | 7F | 0 | 0 | 0 | 1 |
| CMP | 03 | 03 | 00 | 0 | 1 | 0 | 0 |

I numeri nella tabella sono esadecimali. Per CMP leggere R su J7 e verificare
che J4 resti ad alta impedenza. Per questo test usare un carico resistivo
appropriato o una sonda: il valore letto su un bus flottante non prova lo
stato tri-state.

## Riferimenti

Semantica: `docs/isa.md` e `docs/control-unit-microcode.md` del repository.
Piedinature controllate sui datasheet ufficiali:
[CD74HCT151](https://www.ti.com/lit/ds/symlink/cd74hct151.pdf),
[CD74HCT283](https://www.ti.com/lit/ds/symlink/cd74hct283.pdf),
[SN74HCT244](https://www.ti.com/lit/ds/symlink/sn74hct244.pdf),
[SN74HCT02](https://www.ti.com/lit/ds/symlink/sn74hct02.pdf),
[SN74HCT157](https://www.ti.com/lit/ds/symlink/sn74hct157.pdf),
[SN74HCT138](https://www.ti.com/lit/ds/symlink/sn74hct138.pdf),
[C&K SDA](https://www.ckswitches.com/media/1327/sda.pdf).

Gli script in `tools` documentano la generazione iniziale e le verifiche.
`build_alu.py --rebuild-unrouted` ricrea una scheda **senza piste**:
richiede nuovo instradamento, DRC, esportazione e confezionamento. Per normali
modifiche lavorare sui sorgenti KiCad finali, preservando le piste esistenti.

Per ricostruire completamente: generare il layout non instradato; esportare
`source/schematic.xml` con `kicad-cli sch export netlist --format kicadxml`;
eseguire `prepare_board.py` con il Python pcbnew di KiCad; instradare il DSN
esportato e salvare la sessione SES; eseguire `finish_board.py`; verificare
ERC, DRC con parità e simulazione; esportare nuovamente Gerber/forature prima
di usare `package_fabrication.py`. `prepare_board.py` ed `finish_board.py`
richiedono pcbnew; gli altri script usano Python standard.

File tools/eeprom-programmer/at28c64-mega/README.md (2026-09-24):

# AT28C64 Arduino Mega Programmer

Sketch Arduino per programmare una EEPROM parallela AT28C64 usando un Arduino Mega.

L'obiettivo e caricare nella EEPROM il binario prodotto dagli strumenti del progetto, per esempio l'output `.hex` generato da `cpu8asm`.

Per la guida completa passo passo, inclusa la base teorica, vedere:

```text
docs/at28c64-arduino-mega-programmer.md
```

## Struttura sorgenti

| File | Responsabilita |
| --- | --- |
| `at28c64-mega.ino` | inizializza seriale e bus EEPROM, poi chiama il gestore comandi nel `loop` |
| `include/ProgrammerConfig.h` | configurazione pin, baud rate, dimensione EEPROM e timing |
| `include/EepromBus.h` | interfaccia del modulo che controlla la EEPROM |
| `src/EepromBus.cpp` | gestisce pin, bus indirizzi, bus dati, lettura, scrittura e attesa del ciclo interno |
| `include/SerialCommands.h` | interfaccia del parser dei comandi seriali |
| `src/SerialCommands.cpp` | gestisce parsing, validazione, dump, fill e formato `.hex` di `cpu8asm` |
| `upload_reliable.py` | uploader host stop-and-wait: CRC-16, ACK, ritentativi e verifica finale |

Per una guida di studio didattica dei sorgenti, leggere:

```text
tools/eeprom-programmer/at28c64-mega/STUDY_GUIDE.md
```

## Perche Arduino Mega

La AT28C64 usa:

- 13 linee indirizzo: `A0`...`A12`;
- 8 linee dati bidirezionali: `D0`...`D7`;
- 3 segnali di controllo: `CE`, `OE`, `WE`.

Un Arduino Uno non ha abbastanza pin liberi per collegare tutto in modo diretto. Arduino Mega permette invece un collegamento semplice, senza shift register.

## Mappa pin Arduino

Questa mappa descrive i segnali logici. Prima di collegare la EEPROM controlla sempre il pinout del package reale nel datasheet della tua AT28C64.

| Segnale EEPROM | Pin Arduino Mega |
| --- | ---: |
| `A0` | `22` |
| `A1` | `23` |
| `A2` | `24` |
| `A3` | `25` |
| `A4` | `26` |
| `A5` | `27` |
| `A6` | `28` |
| `A7` | `29` |
| `A8` | `30` |
| `A9` | `31` |
| `A10` | `32` |
| `A11` | `33` |
| `A12` | `34` |
| `D0` | `35` |
| `D1` | `36` |
| `D2` | `37` |
| `D3` | `38` |
| `D4` | `39` |
| `D5` | `40` |
| `D6` | `41` |
| `D7` | `42` |
| `CE` | `43` |
| `OE` | `44` |
| `WE` | `45` |

Collegamenti alimentazione:

- `VCC` EEPROM a `5V`;
- `GND` EEPROM a `GND`;
- condensatore da `100 nF` tra `VCC` e `GND`, vicino alla EEPROM.

Per AT28C64B in package PDIP-28:

- pin `28` = `VCC`;
- pin `14` = `GND`;
- pin `27` = `WE`;
- pin `26` = `NC`, non collegare.

## Formati supportati via seriale

Apri il monitor seriale a `115200 baud`, con terminatore newline.

### Scrivere una riga prodotta da `cpu8asm`

```text
0000: 20
0001: 0A
0002: 8A
0003: 01
```

Ogni riga scrive un byte all'indirizzo indicato.

### Comandi manuali

```text
W 0000 20
P 0000 20
M P
M W
R 0000
D 0000 0010
F 0000 00FF FF
```

Significato:

| Comando | Effetto |
| --- | --- |
| `W addr byte` | scrive un byte |
| `P addr byte` | scrive un byte usando la sequenza Software Data Protection |
| `M P` | usa la scrittura protetta per le righe `.hex` incollate dopo il comando |
| `M W` | torna alla scrittura normale per le righe `.hex` |
| `R addr` | legge un byte |
| `D start count` | stampa un dump di `count` byte |
| `F start end byte` | riempie un intervallo inclusivo |
| `HELP` | stampa l'aiuto |

I numeri senza prefisso sono esadecimali e il prefisso `0x` e opzionale. Per
inserire un numero binario usa `0b`: ad esempio `W 0b0 0b10100110`.
L'output e i dump restano in esadecimale, nel formato compatibile con `cpu8asm`.

## Esempio con l'assembler

Compila un programma assembly:

```sh
tools/assembler/build/cpu8asm examples/assembly/demo.asm -o tools/assembler/build/demo
```

Poi invia il contenuto di:

```text
tools/assembler/build/demo.hex
```

allo sketch Arduino. Ogni riga `addr: byte` programma un byte della EEPROM.

## Caricamento affidabile consigliato

Non incollare un file `.hex` dal monitor seriale: durante il ciclo di scrittura
la EEPROM richiede fino a 15 ms per byte e la UART del Mega puo perdere righe
se il computer le invia senza attendere.

Usa invece `upload_reliable.py`. Accetta sia il `.hex` dell'assembler sia un
`.bin` puro (come le Control ROM). Invia blocchi di massimo 16 byte, attende
l'ACK del Mega, ritenta un blocco fallito e richiede una verifica CRC-16 dalla
EEPROM al termine di ogni intervallo contiguo.

```sh
python3 -m pip install pyserial
python3 tools/eeprom-programmer/at28c64-mega/upload_reliable.py \
  --port /dev/cu.usbmodem21201 tools/assembler/build/demo.hex
```

Per una EEPROM con Software Data Protection attiva aggiungi `--protected`.

### Control ROM generate dalla CU

Le quattro immagini sono gia binari completi da 8192 byte. Programma **una
EEPROM alla volta**, partendo dall'indirizzo zero, e applica poi l'etichetta del
file al chip fisico:

```sh
python3 tools/eeprom-programmer/at28c64-mega/upload_reliable.py \
  --port /dev/cu.usbmodemXXXX tools/cu-bytecode/build/microcode-rom0.bin
```

Ripeti lo stesso comando, cambiando il file, per:

```text
microcode-rom1.bin
microcode-rom2.bin
```

Il caricatore verifica tutti gli 8192 byte via CRC-16 prima di dichiarare
successo. Non usare `--address` per queste immagini: devono iniziare da `0000`.

## Note elettriche

- La AT28C64 lavora a 5V: usa Arduino Mega a 5V.
- Durante la lettura, i pin dati Arduino devono essere `INPUT`.
- Durante la scrittura, i pin dati Arduino devono essere `OUTPUT`.
- `OE` deve restare alto durante la scrittura.
- L'impulso di scrittura viene dato portando `WE` basso per pochi microsecondi.
- Dopo ogni scrittura lo sketch attende un ritardo fisso conservativo e poi verifica rileggendo il byte.
- Il condensatore da `100 nF` tra `VCC` e `GND` della EEPROM e fortemente consigliato anche se il circuito sembra funzionare senza.
- Se una EEPROM AT28C64B ha la Software Data Protection attiva, prova il comando
  `P addr byte` invece di `W addr byte` per scrivere un singolo byte.
- Se `P` funziona, invia `M P` prima di incollare un file `.hex`; le righe
  `0000: 20` useranno la scrittura protetta finche non invii `M W`.
- Usa `P`/`M P` solo quando serve: per una EEPROM non protetta e cablata
  correttamente bastano `W` e le righe `.hex` normali.

Non collegare la EEPROM anche alla CPU mentre la programmi, a meno che i bus della CPU siano sicuramente in alta impedenza.

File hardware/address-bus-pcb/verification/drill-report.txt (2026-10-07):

Drill report for address_bus_rev_a.kicad_pcb
Created on 2026-10-07T15:21:05

Copper Layer Stackup:
    =============================================================
    L1 :  F.Cu                      front
    L2 :  B.Cu                      back

Drill file 'address_bus_rev_a-PTH.drl' contains
    plated through holes:
    =============================================================
    T1  0.300mm  0.0118"  (199 holes))
    T2  0.800mm  0.0315"  (96 holes))
    T3  0.900mm  0.0354"  (204 holes))

    Total plated holes count 499

Drill file 'address_bus_rev_a-NPTH.drl' contains
    unplated through holes:
    =============================================================
    T1  3.200mm  0.1260"  (4 holes))

    Total unplated holes count 4

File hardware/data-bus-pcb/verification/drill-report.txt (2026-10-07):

Drill report for data_bus_rev_a.kicad_pcb
Created on 2026-10-07T15:21:03

Copper Layer Stackup:
    =============================================================
    L1 :  F.Cu                      front
    L2 :  B.Cu                      back

Drill file 'data_bus_rev_a-PTH.drl' contains
    plated through holes:
    =============================================================
    T1  0.300mm  0.0118"  (62 holes))
    T2  0.800mm  0.0315"  (53 holes))
    T3  0.900mm  0.0354"  (104 holes))

    Total plated holes count 219

Drill file 'data_bus_rev_a-NPTH.drl' contains
    unplated through holes:
    =============================================================
    T1  3.200mm  0.1260"  (4 holes))

    Total unplated holes count 4

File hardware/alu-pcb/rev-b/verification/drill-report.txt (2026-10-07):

Drill report for alu_rev_b.kicad_pcb
Created on 2026-10-07T09:27:50

Copper Layer Stackup:
    =============================================================
    L1 :  F.Cu                      front
    L2 :  B.Cu                      back

Drill file 'alu_rev_b-PTH.drl' contains
    plated through holes:
    =============================================================
    T1  0.300mm  0.0118"  (454 holes))
    T2  0.800mm  0.0315"  (316 holes))
    T3  0.900mm  0.0354"  (748 holes))

    Total plated holes count 1518

Drill file 'alu_rev_b-NPTH.drl' contains
    unplated through holes:
    =============================================================
    T1  3.200mm  0.1260"  (4 holes))

    Total unplated holes count 4

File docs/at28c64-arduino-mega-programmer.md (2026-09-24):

# Programmare una AT28C64 con Arduino Mega

Questa guida mostra il minimo necessario per leggere e scrivere una EEPROM parallela **AT28C64/AT28C64B** con lo sketch in:

```text
tools/eeprom-programmer/at28c64-mega/
```

La EEPROM contiene 8192 byte: gli indirizzi validi sono da `0000` a `1FFF`.

## Prima di iniziare

- Usa una EEPROM a 5 V e un Arduino Mega a 5 V.
- Collega **GND comune** tra Arduino ed EEPROM.
- Metti un condensatore ceramico da **100 nF** tra `VCC` (pin 28) e `GND` (pin 14), vicino al chip.
- Controlla il verso della EEPROM: il riferimento e la tacca del package, vista dall'alto.

## Collegamenti completi

Tabella riferita a una AT28C64B in package PDIP-28, vista dall'alto. I due pin `NC` non vanno collegati.

| Pin EEPROM | Segnale | Pin Arduino Mega |
| ---: | --- | ---: |
| 1 | `NC` | non collegare |
| 2 | `A12` | `34` |
| 3 | `A7` | `29` |
| 4 | `A6` | `28` |
| 5 | `A5` | `27` |
| 6 | `A4` | `26` |
| 7 | `A3` | `25` |
| 8 | `A2` | `24` |
| 9 | `A1` | `23` |
| 10 | `A0` | `22` |
| 11 | `I/O0`  | `35` |
| 12 | `I/O1`  | `36` |
| 13 | `I/O2`  | `37` |
| 14 | `GND` | `GND` |
| 15 | `I/O3`  | `38` |
| 16 | `I/O4`  | `39` |
| 17 | `I/O5`  | `40` |
| 18 | `I/O6`  | `41` |
| 19 | `I/O7`  | `42` |
| 20 | `CE` | `43` |
| 21 | `A10` | `32` |
| 22 | `OE` | `44` |
| 23 | `A11` | `33` |
| 24 | `A9` | `31` |
| 25 | `A8` | `30` |
| 26 | `NC` | non collegare |
| 27 | `WE` | `45` |
| 28 | `VCC` | `5V` |

## Il concetto essenziale

Le linee `A0`–`A12` scelgono la cella; `I/O0`–`I/O7` trasportano il byte.
Il bus dati e condiviso: durante la lettura lo guida la EEPROM, durante la scrittura lo guida Arduino. Per evitare un conflitto elettrico, lo sketch imposta sempre i pin dati in `INPUT` prima di leggere e in `OUTPUT` prima di scrivere.

| Operazione | `CE` | `OE` | `WE` | Chi guida il bus dati |
| --- | ---- | ---- | --- | --- |
| Riposo | `1`  | `1`  | `1` | nessuno |
| Lettura | `0`  | `0`  | `1` | EEPROM |
| Scrittura  | `0`  | `1`  | impulso `0` → `1` | Arduino |

`0` significa livello basso, `1` livello alto.

## Flusso di lettura

```text
Arduino: dati INPUT → imposta indirizzo → CE=0, OE=0 → attende 1 µs → legge il byte → CE=1, OE=1
EEPROM:                         vede l'indirizzo → mette il byte sul bus →         rilascia il bus
```

L'attesa di **1 µs** e il tempo di assestamento impostato nello sketch (`READ_SETTLE_US`). Serve a lasciare il tempo alla EEPROM di rendere valido il dato dopo l'abilitazione delle uscite.

Esempio nel monitor seriale:

```text
R 0000
```

## Flusso di scrittura e tempi

```text
Arduino: imposta indirizzo → dati OUTPUT e byte valido → OE=1, CE=0 → WE=0 per 10 µs → WE=1, CE=1 → attende 15 ms → rilegge e verifica
EEPROM:   riceve indirizzo e dato                            avvio scrittura       programma internamente       byte pronto
```

Il fronte di risalita di `WE` avvia la programmazione interna. Il byte non e subito disponibile: la AT28C64B indica fino a circa **10 ms**. Lo sketch aspetta **15 ms** (`WRITE_SETTLE_MS`) per avere margine, poi legge di nuovo la cella e risponde `OK` solo se il valore coincide.

L'impulso `WE` usato dallo sketch dura **10 µs** (`WRITE_PULSE_US`).

Con la scrittura normale, ogni riga inviata richiede quindi almeno circa **15 ms**, piu il tempo di invio seriale e di elaborazione. In pratica e un programmatore didattico: semplice e verificabile, non pensato per la massima velocita.

## Installazione e caricamento

Installa una sola volta Arduino CLI e il core del Mega:

```sh
brew install arduino-cli
arduino-cli core update-index
arduino-cli core install arduino:avr
```

Compila lo sketch dalla root del repository:

```sh
arduino-cli compile --fqbn arduino:avr:mega tools/eeprom-programmer/at28c64-mega
```

Trova la porta del Mega:

```sh
arduino-cli board list
```

Carica lo sketch, sostituendo la porta di esempio con la tua:

```sh
arduino-cli upload -p /dev/cu.usbmodem21101 --fqbn arduino:avr:mega tools/eeprom-programmer/at28c64-mega
```

Apri poi il monitor seriale a 115200 baud:

```sh
arduino-cli monitor -p /dev/cu.usbmodem21201 --config baudrate=115200
```

Usa il terminatore di riga newline.

## Scrivere un programma

1. Genera il file `.hex` con l'assembler:

   ```sh
   make -C tools/assembler
   tools/assembler/build/cpu8asm examples/assembly/demo.asm -o tools/assembler/build/demo
   ```

2. Nel monitor seriale incolla le righe di `tools/assembler/build/demo.hex`. Ogni riga scrive un byte:

   ```text
   0000: 20
   0001: 0A
   0002: 48
   ```

3. Per ogni byte scritto e verificato, Arduino risponde:

   ```text
   OK 0000: 20
   ```

4. Controlla il risultato con un dump dei primi 16 byte:

   ```text
   D 0000 0010
   ```

## Comandi utili

I numeri senza prefisso sono esadecimali; `0x` e facoltativo. Per usare il
binario, anteponi `0b`: per esempio `W 0b0 0b10100110` scrive il byte `A6`
all'indirizzo `0000`. Il formato di risposta e dei dump resta esadecimale.

| Comando | Esempio | Funzione |
| --- | --- | --- |
| `W addr byte` | `W 0000 AA` | scrive un byte e lo verifica |
| `R addr` | `R 0000` | legge un byte |
| `D start count` | `D 0000 0010` | stampa un dump |
| `F start end byte` | `F 0000 00FF FF` | riempie un intervallo |
| `HELP` | `HELP` | mostra tutti i comandi |

## Test iniziale

Prima di inviare un programma intero, esegui:

```text
W 0000 AA
R 0000
D 0000 0010
```

La lettura dell'indirizzo `0000` deve restituire `AA`. Se fallisce, spegni tutto e ricontrolla prima alimentazione, massa comune, condensatore, verso del chip e i tre segnali `CE`, `OE`, `WE`.

## Se la scrittura normale non funziona

Alcune AT28C64B possono avere la **Software Data Protection** attiva. In questo caso prova:

```text
P 0000 AA
R 0000
```

`P` invia prima la sequenza di sblocco `1555:AA`, `0AAA:55`, `1555:A0`, poi scrive il byte vero. Se funziona, invia `M P` prima di incollare il file `.hex`; torna alla modalita normale con `M W`.

Usa questa modalita solo se necessaria: con una EEPROM non protetta, `W` e le righe `.hex` sono sufficienti.

## Problemi tipici

| Sintomo | Controllo prioritario |
| --- | --- |
| Legge sempre `FF` | alimentazione, `CE`/`OE`, cavi dati |
| Legge sempre `00` | corti o ordine errato delle linee dati |
| Scrittura non verificata | `WE` sul pin 27, condensatore, collegamenti dati/indirizzi, protezione software |

Riferimento: [datasheet AT28C64B](https://ww1.microchip.com/downloads/en/DeviceDoc/doc0270.pdf).

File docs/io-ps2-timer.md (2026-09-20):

# Specifica I/O, tastiera PS/2 e timer — Tang Nano 9K

> **Stato:** baseline implementabile
> **Versione:** 1.0
> **Data:** 3 settembre 2026

## 1. Scopo e regole comuni

La Tang Nano 9K acquisisce una tastiera PS/2, espone eventi di tastiera e un
timer alla CPU tramite registri memory-mapped. Il programma usa `LDA` per
leggere e `STA` per scrivere; `IN` e `OUT` non sono coinvolte.

La FPGA guida `D[7:0]` solo quando `/RD=0` e l'indirizzo e' compreso fra
`0xFF00` e `0xFF0F`. Durante `/WR=0` cattura i dati ma non guida mai il bus.
Gli stessi requisiti elettrici e di durata dello strobe definiti nell'[indice
FPGA](io-video-ps2-timer.md#vincoli-elettrici-comuni) valgono anche qui.

## 2. Mappa dei registri

| Nome | Indirizzo | Accesso | Reset | Semantica |
| --- | ---: | --- | ---: | --- |
| `KEY_DATA` | `0xFF00` | R | `0x00` | Evento tastiera; la lettura consuma l'evento. |
| `KEY_STATUS` | `0xFF01` | R | `0x00` | Stato della tastiera e flag di errore. |
| `KEY_CTRL` | `0xFF02` | W | — | Cancella flag di errore. |
| — | `0xFF03` | R/W | — | Riservato: lettura `0x00`, scrittura ignorata. |
| `TIME_LO` | `0xFF04` | R | `0x00` | Byte basso del timer; acquisisce il byte alto. |
| `TIME_HI` | `0xFF05` | R | `0x00` | Byte alto acquisito dall'ultima lettura di `TIME_LO`. |
| `TIME_STATUS` | `0xFF06` | R | `0x01` | Bit 0 `ACTIVE`; gli altri bit sono zero. |
| — | `0xFF07-0xFF0F` | R/W | — | Riservato: lettura `0x00`, scrittura ignorata. |

## 3. Tastiera

### 3.1 Protocollo fisico

La FPGA riceve il protocollo PS/2 Set 2: un frame contiene start a zero, otto
bit LSB-first, parita' dispari e stop a uno. `CLK` e `DATA` sono linee
open-collector. La tastiera e' alimentata a 5 V, ma i pull-up di `CLK` e
`DATA` sul lato FPGA devono andare a 3,3 V; non applicare mai 5 V ai pin FPGA.
In prima revisione la CPU non invia comandi alla tastiera.

Il ricevitore campiona `DATA` sul fronte di discesa di `CLK`, valida start,
stop e parita' e riconosce i prefissi `E0` (esteso) e `F0` (break). Gli errori
di frame e parita' scartano il frame corrente, impostano il relativo flag
sticky e resettano il parser al prossimo start valido.

### 3.2 Codice evento interno

Il software non riceve scan-code PS/2 grezzi: riceve un byte evento.

| Intervallo/valore | Evento |
| --- | --- |
| `0x20-0x7E` | carattere ASCII stampabile |
| `0x08` | Backspace |
| `0x09` | Tab |
| `0x0D` | Enter |
| `0x1B` | Esc |
| `0x80` / `0x81` | freccia su / giu' |
| `0x82` / `0x83` | freccia sinistra / destra |
| `0x00` | nessun evento (non viene mai accodato) |

La mappa iniziale e' **US QWERTY, PS/2 Set 2**. `Shift` sinistro o destro e
`Caps Lock` sono stati interni: non producono un evento, ma trasformano le
lettere. `Shift` trasforma anche cifre e punteggiatura secondo la tastiera US.
Un make-code ripetuto dalla tastiera produce eventi ripetuti; un break-code
aggiorna lo stato dei modificatori ma non produce eventi.

| Tasti | Make-code Set 2 |
| --- | --- |
| `A-Z` | `1C 32 21 23 24 2B 34 33 43 3B 42 4B 3A 31 44 4D 15 2D 1B 2C 3C 2A 1D 22 35 1A` |
| `1-0` | `16 1E 26 25 2E 36 3D 3E 46 45` |
| spazio | `29` |
| `- = [ ] \\ ; ' , . / \`` | `4E 55 54 5B 5D 4C 52 41 49 4A 0D` |
| Backspace, Tab, Enter, Esc | `66 0D 5A 76` |
| Shift sinistro, Shift destro, Caps Lock | `12 59 58` |
| frecce su, giu', sinistra, destra | `E0 75`, `E0 72`, `E0 6B`, `E0 74` |

Le lettere sono minuscole quando `Shift XOR CapsLock = 0` e maiuscole quando
vale uno. La localizzazione italiana non e' implicita: sara' una mappa
alternativa selezionabile in una revisione futura, senza cambiare i registri.

### 3.3 Buffer e registri di tastiera

La prima revisione usa una coda di profondita' uno.

| Registro | Bit | Definizione |
| --- | --- | --- |
| `KEY_DATA` | `7:0` | Se `READY=1`, restituisce il byte pendente e azzera `READY`; altrimenti restituisce `0x00`. |
| `KEY_STATUS` | 0 | `READY`: esiste un evento non letto. |
|  | 1 | `OVERRUN`: e' arrivato un evento quando `READY=1`; il byte gia' presente viene conservato e il nuovo viene scartato. |
|  | 2 | `PARITY_ERROR`: errore sticky di parita'. |
|  | 3 | `FRAME_ERROR`: errore sticky di start/stop. |
|  | `7:4` | Sempre zero. |
| `KEY_CTRL` | 0 | Scrivere uno cancella `OVERRUN`. |
|  | 1 | Scrivere uno cancella `PARITY_ERROR` e `FRAME_ERROR`. |
|  | `7:2` | Ignorati. |

La lettura di `KEY_STATUS` non modifica alcuno stato. Una lettura di
`KEY_DATA` e' distruttiva solo quando un evento e' pendente.

## 4. Timer

Il timer e' un contatore modulo `2^16` inizializzato a zero dal reset FPGA. Con
`CLK_CPU` nominale di 1 kHz, incrementa ogni dieci fronti, cioe' a **100 Hz**
(un tick = 10 ms). `TIME_STATUS.ACTIVE` resta a uno dopo il reset finche' la
FPGA e' operativa.

Per ottenere una lettura atomica, il firmware deve leggere `TIME_LO` e subito
dopo `TIME_HI`: la lettura di `TIME_LO` restituisce il byte basso corrente e
salva nello stesso istante il byte alto nel latch; `TIME_HI` restituisce quel
latch. Il rollover completo dura 655,36 secondi.

```asm
.equ TIME_LO, 0xFF04
.equ TIME_HI, 0xFF05

LDA R0, TIME_LO     ; acquisisce anche l'alto
LDA R1, TIME_HI     ; alto coerente con R0
```

Le differenze temporali si calcolano modulo `2^16` e sono corrette per
intervalli inferiori al rollover. Se in futuro il timer dovra' avanzare a CPU
ferma, richiedera' un clock FPGA indipendente e un handshake separato: non e'
parte della versione 1.

## 5. Criteri di accettazione

1. Senza tasti, `LDA` da `KEY_DATA` restituisce `0x00` e `READY=0`.
2. Premere `A` accoda `0x61`; con Shift o Caps Lock accoda `0x41`.
3. Una seconda pressione prima della lettura conserva il primo evento e pone
   `OVERRUN=1`.
4. Leggere `KEY_DATA` consegna una volta sola l'evento e azzera `READY`.
5. Due letture `TIME_LO`, `TIME_HI` consecutive restituiscono un valore a 16
   bit coerente, anche al passaggio da `0x00FF` a `0x0100`.

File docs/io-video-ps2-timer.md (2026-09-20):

# Indice delle specifiche FPGA

> **Versione:** 1.0
> **Data:** 3 settembre 2026

La Tang Nano 9K e' il dispositivo programmabile che collega la CPU TTL ai
sottosistemi video, tastiera e timer. Le specifiche inizialmente raccolte in
questo file sono state divise per rendere indipendenti firmware, test e
cablaggio dei due blocchi.

- [Specifica video HDMI](video-hdmi.md): VRAM, formato delle celle, protocollo
  di bus e uscita HDMI.
- [Specifica I/O, PS/2 e timer](io-ps2-timer.md): registri memory-mapped,
  conversione PS/2 e timer.

## Convenzioni comuni

La CPU espone `A[15:0]`, `D[7:0]`, `/RD`, `/WR` e `CLK_CPU`. Le periferiche
sono **memory-mapped**: il software usa `LDA` e `STA`, non le istruzioni `IN`
e `OUT`.

| Intervallo | Proprietario | Riferimento |
| --- | --- | --- |
| `0x0000-0x3FFF` | RAM/ROM di sistema | piattaforma CPU |
| `0x4000-0x7FFF` | VRAM Tang Nano 9K | [video](video-hdmi.md#3-mappa-e-semantica-della-vram) |
| `0x8000-0xFEFF` | riservato | espansioni future |
| `0xFF00-0xFF0F` | registri Tang Nano 9K | [I/O](io-ps2-timer.md#2-mappa-dei-registri) |
| `0xFF10-0xFFFF` | riservato | espansioni future |

La Tang abilita le proprie uscite su `D[7:0]` soltanto per una lettura del suo
spazio di indirizzi. Durante ogni scrittura la CPU rimane l'unico pilota del
bus dati.

## Vincoli elettrici comuni

La CPU TTL e la Tang Nano 9K non devono essere collegate pin-a-pin. Tutti i
segnali CPU -> FPGA passano attraverso traslatori di livello da 5 V a 3,3 V;
`D[7:0]` usa inoltre un transceiver bidirezionale con uscita disabilitabile.
Il suo `OE` e' controllato da `FPGA_D_OE` e puo' essere attivo solo in una
lettura FPGA selezionata. Le masse devono essere comuni.

I pin concreti del connettore 2x24 e le rispettive banche I/O non fanno parte
di questa ABI: vanno assegnati nel file `.cst` dopo verifica sullo schema della
revisione fisica posseduta. Evitare JTAG, `MODE0/1` e `DONE`; rispettare la
tensione della banca. La documentazione Sipeed segnala espressamente che i
GPIO non possono superare la tensione indicata nello schema e che le linee
HDMI hanno pull-up propri.

Riferimenti hardware: [Tang Nano 9K Sipeed](https://wiki.sipeed.com/hardware/en/tang/Tang-Nano-9K/Nano-9K) e [progetto HDMI ufficiale](https://github.com/sipeed/TangNano-9K-example/tree/main/hdmi).

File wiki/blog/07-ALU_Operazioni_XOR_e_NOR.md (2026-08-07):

# ALU: operazioni XOR e NOR

Negli articoli precedenti abbiamo iniziato a costruire l'ALU della nostra CPU a 8 bit partendo dalle prime operazioni logiche: AND e OR.

Abbiamo visto che ogni operazione viene realizzata come una rete a 8 bit: gli ingressi A e B vengono elaborati bit per bit, il risultato passa attraverso un buffer tri-state e infine viene portato sul bus dati solo quando il relativo segnale di enable è attivo.

In questo articolo aggiungiamo due nuove operazioni:

- XOR
- NOR

La XOR sarà molto importante anche più avanti, perché la ritroveremo nel circuito di somma e nel meccanismo che ci permetterà di passare dalla somma alla sottrazione. La NOR, invece, ci permette di introdurre in modo pratico il concetto di uscita negata rispetto a una porta OR.

## L'operazione XOR

XOR significa exclusive OR, cioè OR esclusivo.

È una porta logica a due ingressi. L'uscita vale 1 quando gli ingressi sono diversi tra loro. L'uscita vale 0 quando gli ingressi sono uguali.

La tabella di verità della XOR è:

| A | B | OUT |
| --: | --: | --: |
| 0 | 0 | 0 |
| 0 | 1 | 1 |
| 1 | 0 | 1 |
| 1 | 1 | 0 |

Possiamo quindi leggere la XOR come una porta che risponde alla domanda:

```text
A è diverso da B?
```

Se A e B sono diversi, l'uscita è 1.

Se A e B sono uguali, l'uscita è 0.

Questa caratteristica la rende molto utile in diversi circuiti digitali. Nel nostro progetto la useremo sia come operazione logica dell'ALU, sia all'interno del circuito di somma e sottrazione.

## XOR bit a bit

Come per AND e OR, anche la XOR verrà applicata bit per bit sulle variabili A e B.

Le due variabili sono larghe 8 bit:

```text
A7 A6 A5 A4 A3 A2 A1 A0
B7 B6 B5 B4 B3 B2 B1 B0
```

La rete XOR calcolerà:

```text
OUT0 = A0 XOR B0
OUT1 = A1 XOR B1
OUT2 = A2 XOR B2
OUT3 = A3 XOR B3
OUT4 = A4 XOR B4
OUT5 = A5 XOR B5
OUT6 = A6 XOR B6
OUT7 = A7 XOR B7
```

Il risultato sarà un valore a 8 bit.

Facciamo un esempio:

```text
A = 10101010
B = 11110000
```

La XOR bit a bit produce:

```text
A      10101010
B      11110000
XOR    01011010
```

In ogni colonna il risultato vale 1 solo se i due bit sono diversi.

## Il componente 7486

Per costruire la rete XOR useremo l'integrato 7486.

Il 7486 contiene quattro porte XOR a due ingressi. Poiché dobbiamo realizzare una rete a 8 bit, useremo due integrati 7486.

La piedinatura tipica del 7486 è simile a quella già vista per 7408 e 7432:

| Porta | Ingresso A | Ingresso B | Uscita |
| ----- | ---: | ---: | -----: |
| 1 | pin 1 | pin 2 |  pin 3 |
| 2 | pin 4 | pin 5 |  pin 6 |
| 3 | pin 9 | pin 10 |  pin 8 |
| 4 | pin 12 | pin 13 | pin 11 |

Inoltre:

| Pin | Collegamento |
| --: | --- |
|  14 | +5 V |
| 7 | GND |

Come sempre, prima di montare il circuito è importante verificare il datasheet del componente specifico.

## Struttura della rete XOR a 8 bit

La rete XOR segue la stessa struttura modulare già vista:

```text
A0 ----\
       XOR ---- OUT0
B0 ----/

A1 ----\
       XOR ---- OUT1
B1 ----/

A2 ----\
       XOR ---- OUT2
B2 ----/

...

A7 ----\
       XOR ---- OUT7
B7 ----/
```

Le otto uscite della rete XOR vengono poi collegate agli ingressi di un buffer tri-state a 8 bit.

Il collegamento generale è:

```text
Switch A ----\
             7486 ---- risultato XOR ---- 74244 ---- bus dati ---- LED
Switch B ----/
```

Anche la rete XOR avrà un enable dedicato. Quando l'enable del buffer è attivo, il risultato della XOR viene trasferito sul bus dati. Quando l'enable non è attivo, la rete resta isolata dal bus.

## Test della rete XOR

Per testare la XOR possiamo partire dalla sua tabella di verità su un singolo bit:

|  A0 |  B0 | XOR |
| --: | --: | --: |
| 0 | 0 | 0 |
| 0 | 1 | 1 |
| 1 | 0 | 1 |
| 1 | 1 | 0 |

Il LED collegato al bit D0 del bus dati deve accendersi solo quando A0 e B0 sono diversi.

Poi possiamo testare l'intera rete a 8 bit.

Primo test:

```text
A = 00000000
B = 00000000
```

Risultato atteso:

```text
XOR = 00000000
```

Secondo test:

```text
A = 11111111
B = 00000000
```

Risultato atteso:

```text
XOR = 11111111
```

Terzo test:

```text
A = 11111111
B = 11111111
```

Risultato atteso:

```text
XOR = 00000000
```

Quarto test:

```text
A = 10101010
B = 01010101
```

Risultato atteso:

```text
XOR = 11111111
```

Quinto test:

```text
A = 10101010
B = 11110000
```

Risultato atteso:

```text
XOR = 01011010
```

Questi test permettono di verificare sia il comportamento logico sia l'ordine corretto dei bit sul bus.

## L'operazione NOR

Dopo la XOR possiamo aggiungere la NOR.

NOR significa NOT OR. In altre parole, è una porta OR con uscita negata.

La porta OR produce 1 quando almeno uno dei due ingressi vale 1. La porta NOR produce il risultato opposto: vale 1 solo quando entrambi gli ingressi valgono 0.

La tabella di verità della NOR è:

| A | B |  OR | NOR |
| --: | --: | --: | --: |
| 0 | 0 | 0 | 1 |
| 0 | 1 | 1 | 0 |
| 1 | 0 | 1 | 0 |
| 1 | 1 | 1 | 0 |

Quindi la NOR è alta solo nel caso:

```text
A = 0
B = 0
```

L'espressione booleana può essere scritta come:

```text
OUT = NOT(A OR B)
```

oppure:

```text
OUT = ¬(A + B)
```

Il piccolo cerchio che spesso si vede sul simbolo della porta NOR indica proprio la negazione dell'uscita.

## NOR come OR negata

È utile confrontare OR e NOR.

La OR ha questa tabella:

| A | B |  OR |
| --: | --: | --: |
| 0 | 0 | 0 |
| 0 | 1 | 1 |
| 1 | 0 | 1 |
| 1 | 1 | 1 |

La NOR è semplicemente il contrario dell'uscita OR:

| A | B | NOR |
| --: | --: | --: |
| 0 | 0 | 1 |
| 0 | 1 | 0 |
| 1 | 0 | 0 |
| 1 | 1 | 0 |

Quindi potremmo costruire una NOR anche usando una porta OR seguita da una porta NOT:

```text
A ----\
       OR ---- NOT ---- NOR
B ----/
```

Nel progetto, però, useremo direttamente un integrato che contiene porte NOR.

## Il componente 7402

Per realizzare la rete NOR useremo il 7402.

Il 7402 contiene quattro porte NOR a due ingressi. Per ottenere una rete a 8 bit useremo quindi due integrati 7402.

A differenza di 7408, 7432 e 7486, la piedinatura del 7402 è organizzata in modo diverso. Questo è un dettaglio importante da non sottovalutare.

Una piedinatura tipica è:

| Porta | Ingressi | Uscita |
| ----- | --- | -----: |
| 1 | pin 2, pin 3 |  pin 1 |
| 2 | pin 5, pin 6 |  pin 4 |
| 3 | pin 8, pin 9 | pin 10 |
| 4 | pin 11, pin 12 | pin 13 |

Inoltre:

| Pin | Collegamento |
| --: | --- |
|  14 | +5 V |
| 7 | GND |

Proprio perché la disposizione delle porte è diversa, è importante controllare con attenzione i collegamenti prima di alimentare il circuito.

## Struttura della rete NOR a 8 bit

La rete NOR a 8 bit segue lo stesso principio delle altre reti logiche:

```text
A0 ----\
       NOR ---- OUT0
B0 ----/

A1 ----\
       NOR ---- OUT1
B1 ----/

A2 ----\
       NOR ---- OUT2
B2 ----/

...

A7 ----\
       NOR ---- OUT7
B7 ----/
```

Le uscite OUT0-OUT7 entrano in un buffer tri-state.

Il collegamento generale è:

```text
Switch A ----\
             7402 ---- risultato NOR ---- 74244 ---- bus dati ---- LED
Switch B ----/
```

Anche in questo caso il buffer avrà un enable dedicato, che permetterà alla rete NOR di scrivere sul bus solo quando selezionata.

## Test della rete NOR

Partiamo dal test su un singolo bit:

|  A0 |  B0 | NOR |
| --: | --: | --: |
| 0 | 0 | 1 |
| 0 | 1 | 0 |
| 1 | 0 | 0 |
| 1 | 1 | 0 |

Il LED collegato a D0 deve accendersi solo quando A0 e B0 sono entrambi a 0.

Poi possiamo testare l'intera rete a 8 bit.

Primo test:

```text
A = 00000000
B = 00000000
```

Risultato atteso:

```text
NOR = 11111111
```

Tutti i LED del bus devono accendersi.

Secondo test:

```text
A = 11111111
B = 00000000
```

Risultato atteso:

```text
NOR = 00000000
```

Terzo test:

```text
A = 00000000
B = 11111111
```

Risultato atteso:

```text
NOR = 00000000
```

Quarto test:

```text
A = 10101010
B = 01010101
```

Risultato atteso:

```text
NOR = 00000000
```

Quinto test:

```text
A = 00001111
B = 00110000
```

Prima calcoliamo l'OR:

```text
OR = 00111111
```

Poi neghiamo il risultato:

```text
NOR = 11000000
```

Questo tipo di test è utile perché ci obbliga a ragionare sulla NOR come OR negata.

## Confronto tra OR e NOR

Una prova interessante consiste nell'usare gli stessi ingressi A e B e osservare prima il risultato della OR, poi quello della NOR.

Ad esempio:

```text
A = 00000000
B = 00000000
```

La OR produce:

```text
OR = 00000000
```

La NOR produce:

```text
NOR = 11111111
```

Altro esempio:

```text
A = 11111111
B = 00000000
```

La OR produce:

```text
OR = 11111111
```

La NOR produce:

```text
NOR = 00000000
```

Questo confronto rende evidente che la NOR è l'inversione dell'OR.

Naturalmente, per fare questo test sulla board, bisogna ricordarsi di abilitare una sola rete alla volta:

```text
enable OR  = 0, enable NOR = 1 -> vediamo OR
enable OR  = 1, enable NOR = 0 -> vediamo NOR
```

Non dobbiamo mai abilitare entrambe contemporaneamente.

## Convivenza delle reti nell'ALU

A questo punto la nostra ALU contiene quattro reti logiche:

```text
AND
OR
XOR
NOR
```

Tutte ricevono gli stessi ingressi A e B.

Tutte calcolano continuamente il proprio risultato.

Tutte hanno un buffer tri-state dedicato.

Solo la rete selezionata deve poter scrivere sul bus dati.

La struttura complessiva può essere vista così:

```mermaid
flowchart LR
    AB["A (8 bit) e B (8 bit)"] --> AND[Rete AND] & OR[Rete OR] & XOR[Rete XOR] & NOR[Rete NOR]
    AND --> BUF1[Buffer AND]
    OR --> BUF2[Buffer OR]
    XOR --> BUF3[Buffer XOR]
    NOR --> BUF4[Buffer NOR]
    BUF1 --> BUS[Bus dati 8 bit]
    BUF2 --> BUS
    BUF3 --> BUS
    BUF4 --> BUS
```

Questa organizzazione modulare ci permette di continuare ad aggiungere operazioni senza cambiare il principio generale della ALU.

## Importanza della XOR nei prossimi circuiti

Tra le due operazioni viste in questo articolo, la XOR avrà un ruolo particolarmente importante.

Nel circuito di somma binaria, la XOR verrà usata per calcolare il bit di somma tra due ingressi.

Inoltre, quando costruiremo il circuito di somma e sottrazione, useremo una rete di XOR per invertire condizionatamente i bit della variabile B. Questo ci permetterà di trasformare una somma in una sottrazione usando il complemento a due.

Quindi la XOR non è solo una delle operazioni disponibili nell'ALU, ma anche un componente interno fondamentale per costruire funzioni più complesse.

## Errori comuni

Durante il montaggio di XOR e NOR ci sono alcuni errori da evitare.

Il primo è confondere la XOR con la OR. La OR produce 1 anche quando entrambi gli ingressi sono 1. La XOR invece, nel caso 1 e 1, produce 0.

Il secondo è dimenticare che la NOR è una OR negata. Se l'OR produce 1, la NOR produce 0. Se l'OR produce 0, la NOR produce 1.

Il terzo è usare la piedinatura sbagliata per il 7402. A differenza di altri integrati, nel 7402 alcune uscite si trovano prima degli ingressi nella disposizione dei pin.

Il quarto è lasciare attivi più buffer contemporaneamente. Ogni rete deve avere il proprio enable e durante i test bisogna abilitarne una sola.

Il quinto è non verificare l'ordine dei bit. Come sempre, OUT0 deve finire su D0, OUT1 su D1 e così via.

## Conclusione

In questo articolo abbiamo aggiunto due nuove operazioni alla nostra ALU a 8 bit: XOR e NOR.

Abbiamo visto che la XOR produce 1 quando i due ingressi sono diversi, mentre la NOR è una OR con uscita negata. Abbiamo analizzato i componenti 7486 e 7402, costruendo reti a 8 bit con due integrati per ciascuna operazione.

Abbiamo poi collegato entrambe le reti al bus dati tramite buffer tri-state dedicati, mantenendo la stessa architettura modulare già usata per AND e OR.

A questo punto la nostra ALU dispone delle operazioni:

```text
AND
OR
XOR
NOR
```

Nel prossimo articolo completeremo il gruppo delle operazioni logiche di base aggiungendo NAND, XNOR e NOT.

Queste operazioni ci permetteranno di consolidare il concetto di uscita negata e di vedere come alcune funzioni possono essere costruite combinando porte già disponibili.

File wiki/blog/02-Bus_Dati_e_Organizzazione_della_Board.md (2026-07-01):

# Bus dati e organizzazione della board

Nel primo articolo abbiamo visto una panoramica generale del progetto: l'obiettivo è costruire una CPU a 8 bit partendo dai blocchi fondamentali dell'elettronica digitale. Prima di entrare nel dettaglio dell'ALU, dei registri, del clock e dell'unità di controllo, è utile preparare la base fisica su cui questi blocchi verranno collegati.

Uno degli elementi più importanti di questa base è il bus dati.

Il bus dati può essere immaginato come una strada condivisa sulla quale viaggiano i valori elaborati dai vari moduli della CPU. Nel nostro progetto sarà un bus a 8 bit, quindi formato da otto linee elettriche parallele. Ogni linea rappresenta un singolo bit: potrà trovarsi a livello logico basso, cioè 0, oppure a livello logico alto, cioè 1.

Costruire e rendere visibile il bus dati fin dall'inizio è molto utile, perché ci permette di osservare cosa sta succedendo all'interno della CPU durante i test. Per questo motivo collegheremo ogni linea del bus a un LED, in modo da visualizzare direttamente il valore binario presente sul bus.

## Cos'è un bus dati

In una CPU diversi moduli devono scambiarsi informazioni.

L'ALU deve poter scrivere il risultato di un'operazione. I registri devono poter leggere o scrivere valori. In futuro, anche altri blocchi potranno usare le stesse linee per trasferire dati.

Sarebbe poco pratico collegare ogni modulo direttamente a tutti gli altri con collegamenti separati. Il bus dati risolve questo problema creando un canale condiviso: tutti i blocchi principali possono essere collegati allo stesso insieme di linee, ma solo uno alla volta deve essere autorizzato a scrivere sul bus.

Nel nostro caso il bus dati è composto da 8 linee:

- D0, il bit meno significativo
- D1
- D2
- D3
- D4
- D5
- D6
- D7, il bit più significativo

Il bit D0 ha peso 1, D1 ha peso 2, D2 ha peso 4 e così via fino a D7, che ha peso 128 se interpretiamo il valore come numero senza segno.

Quando leggeremo un valore sul bus, dovremo quindi interpretare lo stato degli 8 bit come un numero binario.

Ad esempio:

```text
D7 D6 D5 D4 D3 D2 D1 D0
 0  0  0  0  0  0  0  1  = 1
 0  0  0  0  0  0  1  0  = 2
 0  0  0  0  0  1  0  1  = 5
 1  1  1  1  1  1  1  1  = 255, se interpretato senza segno
```

Più avanti, quando parleremo di numeri con segno e complemento a due, vedremo che lo stesso valore binario può essere interpretato anche in modo diverso. Per ora ci interessa soprattutto capire che il bus è il luogo in cui vedremo transitare i risultati prodotti dai circuiti.

## Perché visualizzare il bus con i LED

Durante la costruzione di una CPU fatta con integrati logici e collegamenti fisici, il debug è fondamentale.

Quando qualcosa non funziona, dobbiamo poter capire se il problema si trova negli ingressi, nelle uscite, nel cablaggio, nel segnale di enable o nel circuito logico vero e proprio.

Collegare un LED a ogni linea del bus dati ci permette di avere una visualizzazione immediata del valore presente sul bus:

- LED spento: bit a 0
- LED acceso: bit a 1

In questo modo possiamo leggere a colpo d'occhio il valore binario prodotto da una rete logica.

Ad esempio, se stiamo testando una rete AND e ci aspettiamo che il risultato sia `00000001`, dovremo vedere acceso solo il LED collegato al bit meno significativo. Se invece ci aspettiamo `11111111`, dovranno accendersi tutti gli 8 LED.

Questa visualizzazione sarà molto utile in tutti gli articoli successivi, perché ogni nuova rete dell'ALU verrà collegata al bus dati e potremo verificarne il comportamento osservando direttamente i LED.

## Collegamento dei LED al bus dati

Per collegare i LED al bus dati dobbiamo usare una resistenza in serie a ciascun LED, in modo da limitare la corrente.

Una configurazione semplice consiste nel collegare ogni linea del bus a un LED tramite una resistenza, ad esempio da 220 ohm. Quando la linea del bus si trova a livello logico alto, il LED si accende. Quando la linea è a livello logico basso, il LED rimane spento.

Lo schema concettuale di una singola linea è il seguente:

```text
Linea bus dati ---- resistenza ---- LED ---- massa
```

Oppure, a seconda di come si sceglie di cablare i LED, il collegamento può essere invertito. L'importante è che ogni LED abbia sempre una resistenza di limitazione della corrente.

Ripetendo questo schema per tutte le otto linee otteniamo una piccola barra di visualizzazione binaria.

Questa barra LED non è necessaria al funzionamento logico della CPU, ma è estremamente utile durante la costruzione e il collaudo. In un progetto didattico come questo, vedere fisicamente i bit che cambiano stato aiuta molto a capire cosa sta succedendo.

## Organizzazione fisica della board

Prima di iniziare a montare le singole reti logiche, conviene organizzare la board in modo chiaro.

Nel progetto useremo una superficie composta da più basette millefori, o comunque da un'area abbastanza grande da ospitare i vari integrati. L'idea è dividere fisicamente la CPU in zone funzionali.

Una possibile organizzazione è questa:

- una zona per l'alimentazione
- una zona per il bus dati
- una zona per l'ALU
- una zona per i flag
- una zona per il clock
- una zona futura per registri e controllo

Separare le aree aiuta a mantenere i collegamenti più ordinati e a rendere il circuito più facile da leggere.

All'inizio il progetto può sembrare semplice, ma con il passare degli articoli il numero di fili aumenta rapidamente. Avere una disposizione chiara fin da subito evita molta confusione nelle fasi successive.

## Alimentazione del circuito

La maggior parte degli integrati logici che useremo lavora con una tensione di alimentazione di 5 V.

Per questo motivo è utile predisporre una linea di alimentazione comune, con:

- +5 V
- massa, o GND

Queste due linee dovranno essere distribuite a tutti gli integrati presenti sulla board.

Ogni integrato avrà un pin di alimentazione e un pin di massa. È importante controllare sempre il datasheet del componente, perché la piedinatura può cambiare da integrato a integrato.

Ad esempio, molti integrati della serie 74xx a 14 pin hanno:

- pin 14 collegato a +5 V
- pin 7 collegato a massa

Altri integrati, come alcuni buffer a 20 pin, hanno invece alimentazione e massa su pin diversi.

Prima di alimentare il circuito è buona pratica controllare attentamente tutti i collegamenti. Un errore sull'alimentazione può impedire il funzionamento del circuito o, nei casi peggiori, danneggiare un integrato.

## Il bus come riferimento comune

Il bus dati diventerà un punto di riferimento per tutta la CPU.

Ogni volta che costruiremo una nuova rete logica, il risultato verrà portato verso il bus. Tuttavia, non potremo collegare direttamente tutte le uscite al bus dati, perché più circuiti potrebbero tentare di pilotare contemporaneamente le stesse linee.

Per questo motivo, tra le uscite delle reti logiche e il bus dati inseriremo dei buffer tri-state. Questi componenti permettono di abilitare una sola rete alla volta e di isolare tutte le altre.

Il bus, quindi, sarà condiviso, ma controllato.

Questa è una delle idee fondamentali del progetto: molti moduli possono essere fisicamente collegati allo stesso bus, ma solo il modulo selezionato deve poter scrivere un valore sulle linee dati.

Negli articoli successivi vedremo questo concetto in pratica quando collegheremo la prima rete logica dell'ALU, cioè l'operazione AND.

## Ordinare i collegamenti

In un progetto digitale costruito fisicamente, l'ordine dei collegamenti è importante quasi quanto lo schema logico.

Conviene usare colori diversi per distinguere i vari tipi di segnale. Ad esempio:

- rosso per +5 V
- nero o blu scuro per la massa
- giallo per le uscite verso il bus dati
- colori diversi per le variabili A e B
- un colore dedicato per i segnali di enable

Non è obbligatorio usare esattamente questi colori, ma è importante mantenere una convenzione coerente.

Quando i circuiti aumentano, avere fili colorati in modo ordinato permette di seguire più facilmente il percorso dei segnali. Anche etichettare i gruppi di cavi o gli integrati può essere molto utile.

Nel progetto, ad esempio, sarà utile distinguere chiaramente:

- gli ingressi A
- gli ingressi B
- le uscite delle porte logiche
- le uscite dei buffer verso il bus
- i segnali di enable
- i segnali di controllo

Questa attenzione all'ordine non serve solo per l'estetica. Serve soprattutto per ridurre gli errori e rendere più semplice la manutenzione del circuito.

## Primo test del bus dati

Prima di collegare l'ALU, possiamo fare un test molto semplice.

Prendiamo una delle linee del bus, ad esempio D0, e portiamola manualmente a +5 V. Il LED corrispondente dovrebbe accendersi. Riportando la linea a massa, il LED dovrebbe spegnersi.

Ripetendo il test sulle altre linee possiamo verificare che tutti gli 8 LED funzionino correttamente.

Questo test iniziale è importante perché ci permette di assicurarci che la visualizzazione del bus sia affidabile. Se in seguito una rete logica produrrà un risultato inatteso, sapremo che il problema non è nei LED del bus, ma probabilmente nella rete o nei collegamenti che la precedono.

Possiamo anche provare a simulare manualmente alcuni valori binari:

```text
00000001  -> solo D0 acceso
00000010  -> solo D1 acceso
00000101  -> D2 e D0 accesi
11111111  -> tutti i LED accesi
00000000  -> tutti i LED spenti
```

Questi test semplici aiutano a prendere confidenza con la lettura visiva del bus.

## Perché partire dal bus

Potremmo essere tentati di iniziare subito dalle porte logiche o dall'ALU, ma partire dal bus dati ha un vantaggio importante: ci permette di costruire fin da subito uno strumento di osservazione.

Ogni circuito successivo verrà verificato guardando cosa appare sul bus. Senza una visualizzazione chiara, ogni test sarebbe più complicato e richiederebbe continuamente l'uso di strumenti esterni.

Il bus dati con i LED diventa quindi una sorta di pannello di controllo minimale della CPU.

Non è ancora un vero registro, non è ancora memoria e non esegue nessuna operazione. Però ci mostra lo stato delle linee su cui viaggeranno i risultati prodotti dai vari blocchi.

Per questo motivo è uno dei primi elementi da preparare.

## Conclusione

In questo articolo abbiamo preparato la base del progetto.

Abbiamo visto cos'è un bus dati, perché nel nostro caso sarà largo 8 bit e perché è utile collegare ogni linea a un LED di debug. Abbiamo anche introdotto l'importanza dell'organizzazione fisica della board, dell'alimentazione a 5 V e della separazione ordinata dei vari segnali.

Il bus dati sarà il punto di incontro tra i diversi moduli della CPU. Su di esso vedremo comparire i risultati dell'ALU, i valori letti dai registri e, più avanti, i dati coinvolti nell'esecuzione delle istruzioni.

Nel prossimo articolo vedremo un altro aspetto fondamentale prima di collegare gli ingressi delle reti logiche: i circuiti di pull-up e pull-down.

Capiremo perché un ingresso digitale non deve mai essere lasciato flottante e come possiamo usare resistenze e switch per fornire valori logici stabili agli integrati della CPU.

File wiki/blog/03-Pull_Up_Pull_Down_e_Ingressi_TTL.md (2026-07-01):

# Pull-up, pull-down e ingressi TTL

Nel precedente articolo abbiamo visto come organizzare il bus dati della CPU e perché è utile visualizzare le sue linee con dei LED. Prima di iniziare a collegare le prime reti logiche dell'ALU, dobbiamo però affrontare un problema molto importante: come fornire valori stabili agli ingressi degli integrati digitali.

Quando useremo degli switch per impostare manualmente le variabili A e B, ogni switch dovrà produrre un valore logico chiaro: 0 oppure 1. Non possiamo permetterci ingressi lasciati scollegati o indefiniti, perché un integrato digitale deve sempre ricevere un livello logico interpretabile.

Per risolvere questo problema useremo due circuiti fondamentali: il pull-down e il pull-up.

## Il problema degli ingressi flottanti

In un circuito digitale, un ingresso dovrebbe trovarsi sempre in uno stato definito:

- livello logico basso, cioè 0
- livello logico alto, cioè 1

Il problema nasce quando un ingresso viene lasciato scollegato. In questo caso si dice che l'ingresso è flottante.

Un ingresso flottante non è collegato né a massa né a una tensione positiva stabile. Di conseguenza può assumere valori imprevedibili, captare disturbi elettrici o comportarsi in modo diverso a seconda del circuito, della breadboard, dei fili o dell'ambiente circostante.

Questo è particolarmente importante quando lavoriamo con integrati logici della famiglia TTL o CMOS. Se lasciamo un ingresso libero, non possiamo essere sicuri che venga interpretato come 0 o come 1.

In una CPU costruita con molti integrati, un singolo ingresso instabile può causare risultati errati, LED che si accendono senza motivo, operazioni sbagliate o comportamenti difficili da diagnosticare.

Per questo motivo la regola è semplice: un ingresso digitale non deve mai essere lasciato flottante.

## Switch e livelli logici

Nel nostro progetto useremo degli switch per impostare manualmente alcuni segnali.

Ad esempio, nelle prime fasi useremo switch per rappresentare le variabili A e B in ingresso all'ALU. Ogni variabile sarà composta da 8 bit, quindi avremo otto switch per A e otto switch per B.

Ogni switch deve permetterci di scegliere se il bit corrispondente vale 0 oppure 1.

A prima vista potremmo pensare di collegare lo switch direttamente a +5 V. Quando lo switch è chiuso, l'ingresso riceve un livello alto. Ma quando lo switch è aperto, cosa succede?

Succede che l'ingresso resta scollegato. Quindi diventa flottante.

Per evitare questo problema dobbiamo fare in modo che anche quando lo switch è aperto l'ingresso abbia comunque un valore definito. Ed è qui che entrano in gioco pull-down e pull-up.

## Circuito di pull-down

Il circuito di pull-down serve a mantenere un ingresso normalmente a livello basso.

Lo schema concettuale è questo:

```text
+5 V ---- switch ---- nodo di uscita ---- ingresso logico
                         |
                         R
                         |
                        GND
```

La resistenza collega il nodo di uscita a massa. Per questo motivo, quando lo switch è aperto, il nodo viene “tirato giù” verso 0 V. L'ingresso logico legge quindi uno 0.

Quando invece chiudiamo lo switch, il nodo viene collegato a +5 V. In questo caso l'ingresso legge un 1.

Il comportamento è quindi:

| Stato switch | Valore letto dall'ingresso |
| --- | --- |
| Aperto | 0 |
| Chiuso | 1 |

La resistenza è fondamentale perché evita un cortocircuito diretto tra +5 V e massa quando lo switch viene chiuso.

Senza la resistenza, chiudere lo switch potrebbe collegare direttamente alimentazione e massa, causando una corrente troppo elevata. Con la resistenza, invece, la corrente viene limitata a un valore sicuro.

Nel progetto possiamo usare, ad esempio, resistenze da 4.7 kΩ.

## Circuito di pull-up

Il circuito di pull-up funziona in modo speculare rispetto al pull-down.

In questo caso la resistenza collega il nodo di uscita a +5 V, mentre lo switch collega il nodo a massa.

Lo schema concettuale è questo:

```text
+5 V
 |
 R
 |
nodo di uscita ---- ingresso logico
 |
switch
 |
GND
```

Quando lo switch è aperto, la resistenza tira il nodo verso +5 V. L'ingresso legge quindi un 1.

Quando invece chiudiamo lo switch, il nodo viene collegato direttamente a massa e l'ingresso legge uno 0.

Il comportamento è quindi:

| Stato switch | Valore letto dall'ingresso |
| --- | --- |
| Aperto | 1 |
| Chiuso | 0 |

Anche in questo caso la resistenza è indispensabile. Quando lo switch viene chiuso, la resistenza impedisce che +5 V e massa siano collegati direttamente senza limitazione di corrente.

## Pull-down e pull-up a confronto

Entrambi i circuiti servono allo stesso scopo: garantire che un ingresso abbia sempre un valore definito.

La differenza principale è il valore predefinito dell'ingresso:

| Circuito  | Valore con switch aperto | Valore con switch chiuso |
| --- | ---: | ---: |
| Pull-down | 0 | 1 |
| Pull-up | 1 | 0 |

Nel pull-down lo stato di riposo è 0.

Nel pull-up lo stato di riposo è 1.

La scelta tra i due dipende dal comportamento che vogliamo ottenere e dal tipo di logica che stiamo usando.

Nel nostro progetto, inizialmente possiamo ragionare con entrambi gli schemi. Tuttavia, lavorando con integrati TTL, il pull-up può risultare più stabile in alcune situazioni pratiche. Per questo motivo, sugli switch usati per impostare le variabili della CPU, può essere conveniente usare una configurazione di pull-up.

## Perché gli ingressi TTL richiedono attenzione

Gli integrati TTL hanno caratteristiche elettriche specifiche.

Un livello logico basso non è semplicemente “qualsiasi tensione vicina a 0”, e un livello logico alto non è “qualsiasi tensione vicina a 5 V”. Ogni famiglia logica ha soglie precise entro cui interpreta un segnale come 0 o come 1.

Inoltre, gli ingressi TTL non si comportano esattamente come ingressi ideali. Per questo motivo è importante pilotarli con segnali ben definiti e non lasciarli mai scollegati.

Quando usiamo uno switch, il contatto meccanico apre o chiude un collegamento. Ma se non aggiungiamo una resistenza di pull-up o pull-down, almeno una delle due posizioni dello switch lascia l'ingresso senza riferimento.

Questo può portare a comportamenti casuali.

Ad esempio, una porta AND potrebbe leggere un 1 anche se pensiamo di aver lasciato l'ingresso a 0. Oppure una linea del bus potrebbe cambiare stato apparentemente senza motivo.

La stabilità degli ingressi è quindi una condizione necessaria per costruire circuiti affidabili.

## Applicazione alle variabili A e B

Nelle prime reti dell'ALU useremo due variabili principali:

- A
- B

Ogni variabile sarà larga 8 bit. Avremo quindi:

```text
A7 A6 A5 A4 A3 A2 A1 A0
B7 B6 B5 B4 B3 B2 B1 B0
```

Ogni bit verrà impostato tramite uno switch.

Questi switch dovranno essere collegati agli ingressi delle reti logiche dell'ALU: AND, OR, XOR, NOR e così via.

Per ogni linea dovremo quindi garantire un livello stabile. Se usiamo un pull-up, ogni ingresso sarà normalmente a 1 quando lo switch è aperto e passerà a 0 quando lo switch viene chiuso. Se usiamo un pull-down, il comportamento sarà opposto.

L'importante è mantenere coerenza tra il cablaggio fisico e il modo in cui leggiamo gli switch.

Se il pull-up ci dà logica invertita rispetto a ciò che ci aspettiamo visivamente dallo switch, possiamo compensare organizzando la posizione degli switch o etichettando chiaramente quale posizione corrisponde a 0 e quale a 1.

## Resistenza di pull-up o pull-down

Il valore della resistenza deve essere scelto in modo da garantire un livello logico stabile senza far circolare troppa corrente.

Un valore tipico per questi esperimenti è 4.7 kΩ.

Con una resistenza di questo tipo otteniamo un buon compromesso:

- il nodo viene portato stabilmente a 0 o a 1
- la corrente resta limitata
- lo switch può forzare facilmente il valore opposto

Valori troppo bassi farebbero circolare più corrente del necessario. Valori troppo alti potrebbero rendere il nodo più sensibile ai disturbi.

Per il nostro progetto, l'obiettivo non è ottimizzare ogni singolo parametro elettrico, ma costruire un circuito stabile, comprensibile e facile da testare.

## Esempio pratico con un bit

Immaginiamo di voler impostare il bit A0 usando un circuito di pull-down.

Quando lo switch è aperto, A0 viene collegato a massa tramite la resistenza. Quindi A0 vale 0.

Quando chiudiamo lo switch, A0 viene collegato a +5 V. Quindi A0 vale 1.

Questo bit può essere collegato, ad esempio, all'ingresso di una porta AND.

Se facciamo la stessa cosa anche per B0, possiamo testare la tabella di verità della porta AND sul bit meno significativo:

|  A0 |  B0 | AND |
| --: | --: | --: |
| 0 | 0 | 0 |
| 0 | 1 | 0 |
| 1 | 0 | 0 |
| 1 | 1 | 1 |

La cosa importante è che A0 e B0 non siano mai flottanti. In ogni momento devono essere collegati, direttamente o tramite resistenza, a un livello logico valido.

## Pull-up e logica invertita

Nel caso del pull-up bisogna ricordare che il comportamento dello switch è invertito rispetto al pull-down.

Con pull-up:

- switch aperto → ingresso a 1
- switch chiuso → ingresso a 0

Questo può sembrare meno intuitivo all'inizio, perché spesso immaginiamo lo switch chiuso come “acceso” e quindi associato a 1.

In realtà non è un problema, purché il cablaggio sia chiaro e coerente.

Molti circuiti digitali usano segnali attivi bassi, cioè segnali che si attivano quando sono a 0. Anche nel nostro progetto incontreremo spesso questa logica, ad esempio con gli enable dei buffer tri-state o con alcune uscite dei decoder.

Abituarsi a leggere segnali attivi bassi è quindi molto utile.

## Errori comuni da evitare

Quando si cablano switch e ingressi digitali, ci sono alcuni errori molto comuni.

Il primo errore è collegare lo switch a +5 V senza una resistenza verso massa. In questo caso, quando lo switch è aperto, l'ingresso resta flottante.

Il secondo errore è collegare direttamente +5 V e massa tramite lo switch, senza una resistenza di limitazione. In questo caso, chiudendo lo switch si crea un cortocircuito.

Il terzo errore è usare valori di resistenza non adatti o dimenticare che la logica può essere invertita nel caso del pull-up.

Il quarto errore è non mantenere una convenzione chiara tra bit, switch e fili. Quando avremo 8 bit per A e 8 bit per B, più i segnali di enable e le uscite verso il bus, l'ordine dei collegamenti diventerà fondamentale.

## Test degli ingressi

Prima di collegare gli switch alle reti logiche, conviene testarli uno alla volta.

Possiamo collegare temporaneamente l'uscita di uno switch a un LED, oppure leggerla con un multimetro.

Nel caso di pull-down ci aspettiamo:

```text
switch aperto  -> circa 0 V
switch chiuso  -> circa 5 V
```

Nel caso di pull-up ci aspettiamo:

```text
switch aperto  -> circa 5 V
switch chiuso  -> circa 0 V
```

Questo test semplice ci permette di verificare che ogni bit produca il livello logico corretto prima di collegarlo agli ingressi dell'ALU.

È molto meglio individuare un problema in questa fase che scoprirlo più avanti, quando il segnale sarà già collegato a più integrati.

## Perché questo passaggio è fondamentale

Pull-up e pull-down sembrano dettagli secondari, ma in realtà sono fondamentali per il funzionamento di tutta la CPU.

Una CPU è un sistema digitale composto da molti segnali. Se anche solo alcuni di questi segnali non sono ben definiti, l'intero circuito può comportarsi in modo instabile.

Prima di progettare operazioni complesse, dobbiamo quindi assicurarci che gli ingressi siano affidabili.

Questo articolo serve proprio a fissare questa regola di base: ogni ingresso deve sempre avere un valore noto.

## Conclusione

In questo articolo abbiamo visto perché gli ingressi digitali non devono mai essere lasciati flottanti.

Abbiamo introdotto i circuiti di pull-down e pull-up, analizzando il loro comportamento con uno switch. Abbiamo visto che il pull-down mantiene l'ingresso normalmente a 0, mentre il pull-up lo mantiene normalmente a 1.

Abbiamo anche discusso perché, usando integrati TTL, è importante fornire segnali stabili e ben definiti agli ingressi delle porte logiche.

Nel prossimo articolo inizieremo finalmente a costruire il primo blocco operativo dell'ALU: la rete AND a 8 bit.

Vedremo la tabella di verità della porta AND, il componente 7408, il collegamento degli ingressi A e B e il modo in cui il risultato verrà portato verso il bus dati tramite un buffer tri-state.

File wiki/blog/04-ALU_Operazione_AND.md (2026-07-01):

# ALU: operazione AND

Nei precedenti articoli abbiamo preparato le basi del progetto: abbiamo introdotto il bus dati, visto come organizzare la board e capito perché gli ingressi digitali devono essere sempre collegati a un livello logico stabile tramite circuiti di pull-up o pull-down.

A questo punto possiamo iniziare a costruire il primo vero blocco operativo della nostra CPU: l'ALU.

L'ALU, cioè Arithmetic Logic Unit, è l'unità aritmetico-logica della CPU. Il suo compito è eseguire operazioni sui dati. Alcune operazioni saranno logiche, come AND, OR, XOR, NOT. Altre saranno aritmetiche, come somma e sottrazione.

In questo articolo partiremo dall'operazione più semplice: l'AND bit a bit tra due variabili a 8 bit.

## Cos'è l'operazione AND

L'AND è una delle operazioni fondamentali dell'algebra booleana.

Lavora su due ingressi, che possiamo chiamare A e B, e produce una sola uscita. L'uscita vale 1 soltanto quando entrambi gli ingressi valgono 1. In tutti gli altri casi l'uscita vale 0.

La tabella di verità della porta AND è la seguente:

| A | B | OUT |
| --: | --: | --: |
| 0 | 0 | 0 |
| 0 | 1 | 0 |
| 1 | 0 | 0 |
| 1 | 1 | 1 |

Questa tabella ci dice che la combinazione `1 AND 1` è l'unica che produce un livello logico alto in uscita.

L'espressione booleana dell'AND si può scrivere così:

```text
OUT = A · B
```

oppure, in forma più vicina alla programmazione:

```text
OUT = A AND B
```

Nel nostro progetto non useremo una sola porta AND, ma una rete di porte AND in parallelo, una per ogni bit delle variabili A e B.

## AND bit a bit

La nostra CPU lavora con dati a 8 bit. Questo significa che le variabili A e B saranno composte da otto linee ciascuna:

```text
A7 A6 A5 A4 A3 A2 A1 A0
B7 B6 B5 B4 B3 B2 B1 B0
```

L'operazione AND verrà eseguita bit per bit:

```text
OUT0 = A0 AND B0
OUT1 = A1 AND B1
OUT2 = A2 AND B2
OUT3 = A3 AND B3
OUT4 = A4 AND B4
OUT5 = A5 AND B5
OUT6 = A6 AND B6
OUT7 = A7 AND B7
```

Il risultato sarà quindi un altro valore a 8 bit:

```text
OUT7 OUT6 OUT5 OUT4 OUT3 OUT2 OUT1 OUT0
```

Facciamo un esempio.

Supponiamo di avere:

```text
A = 10101010
B = 11110000
```

L'AND bit a bit produce:

```text
A      10101010
B      11110000
AND    10100000
```

Ogni colonna viene calcolata separatamente. Dove entrambi i bit sono 1, il risultato è 1. In tutti gli altri casi il risultato è 0.

## Il ruolo dell'AND nella CPU

L'AND può sembrare un'operazione semplice, ma è molto utile all'interno di una CPU.

Viene spesso usata per mascherare bit, cioè per mantenere solo alcune parti di un valore e azzerarne altre.

Ad esempio, se vogliamo conservare solo i quattro bit meno significativi di un valore, possiamo fare l'AND con la maschera `00001111`:

```text
A       10110110
MASK    00001111
AND     00000110
```

I bit corrispondenti agli 1 della maschera vengono mantenuti, mentre quelli corrispondenti agli 0 vengono azzerati.

Nel nostro progetto, però, la cosa più importante non è ancora l'uso software dell'AND, ma la sua implementazione hardware. Costruendo questa prima rete capiremo il modello che useremo anche per molte altre operazioni dell'ALU.

## Il componente 7408

Per realizzare l'operazione AND useremo l'integrato 7408.

Il 7408 contiene quattro porte AND a due ingressi. Ogni porta ha:

- ingresso A
- ingresso B
- uscita Y

Poiché a noi servono otto porte AND, una per ogni bit, useremo due integrati 7408.

In questo modo avremo:

- primo 7408: quattro porte AND per i bit 0, 1, 2, 3
- secondo 7408: quattro porte AND per i bit 4, 5, 6, 7

La piedinatura tipica del 7408 è organizzata in questo modo:

| Porta | Ingresso A | Ingresso B | Uscita |
| ----- | ---: | ---: | -----: |
| 1 | pin 1 | pin 2 |  pin 3 |
| 2 | pin 4 | pin 5 |  pin 6 |
| 3 | pin 9 | pin 10 |  pin 8 |
| 4 | pin 12 | pin 13 | pin 11 |

Inoltre:

| Pin | Collegamento |
| --: | --- |
|  14 | +5 V |
| 7 | GND |

Prima di collegare un integrato è sempre importante verificare il datasheet del componente specifico che si sta usando, soprattutto se si utilizzano varianti diverse della famiglia logica.

## Struttura della rete AND a 8 bit

La rete AND a 8 bit segue una struttura molto semplice.

Ogni bit della variabile A viene collegato a un ingresso di una porta AND. Il bit corrispondente della variabile B viene collegato all'altro ingresso della stessa porta.

L'uscita della porta AND rappresenta il risultato per quel bit.

Lo schema logico può essere rappresentato così:

```text
A0 ----\
       AND ---- OUT0
B0 ----/

A1 ----\
       AND ---- OUT1
B1 ----/

A2 ----\
       AND ---- OUT2
B2 ----/

...

A7 ----\
       AND ---- OUT7
B7 ----/
```

Le uscite OUT0-OUT7, però, non devono essere collegate direttamente al bus dati.

Prima devono passare attraverso un buffer tri-state.

## Perché serve un buffer verso il bus dati

Il bus dati è condiviso da più circuiti.

Oggi stiamo costruendo la rete AND, ma più avanti aggiungeremo la rete OR, la rete XOR, il sommatore, la sottrazione e altre operazioni. Tutte queste reti avranno un risultato a 8 bit e tutte dovranno poterlo mandare sul bus dati.

Se collegassimo direttamente tutte le uscite al bus, avremmo un problema: più reti potrebbero tentare di pilotare contemporaneamente le stesse linee.

Ad esempio, una rete potrebbe cercare di portare D0 a 1 mentre un'altra cerca di portarlo a 0. Questo creerebbe un conflitto elettrico.

Per evitarlo, ogni rete dell'ALU verrà collegata al bus attraverso un buffer tri-state.

Quando il buffer della rete AND è abilitato, il risultato dell'AND arriva sul bus dati.

Quando il buffer è disabilitato, le uscite della rete AND sono isolate dal bus e si trovano in alta impedenza.

Questo ci permette di avere molte reti collegate fisicamente allo stesso bus, ma una sola rete attiva alla volta.
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

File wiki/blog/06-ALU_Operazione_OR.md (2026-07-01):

# ALU: operazione OR

Nel precedente articolo abbiamo approfondito il ruolo dei buffer tri-state e abbiamo visto perché sono fondamentali per collegare più reti logiche allo stesso bus dati senza creare conflitti.

Ora possiamo aggiungere una seconda operazione alla nostra ALU: l'OR.

La struttura sarà molto simile a quella già vista per l'operazione AND. Avremo due variabili in ingresso, A e B, una rete logica a 8 bit, un buffer tri-state e infine il collegamento al bus dati.

Cambierà soltanto il tipo di porta logica utilizzata: al posto delle porte AND useremo porte OR.
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

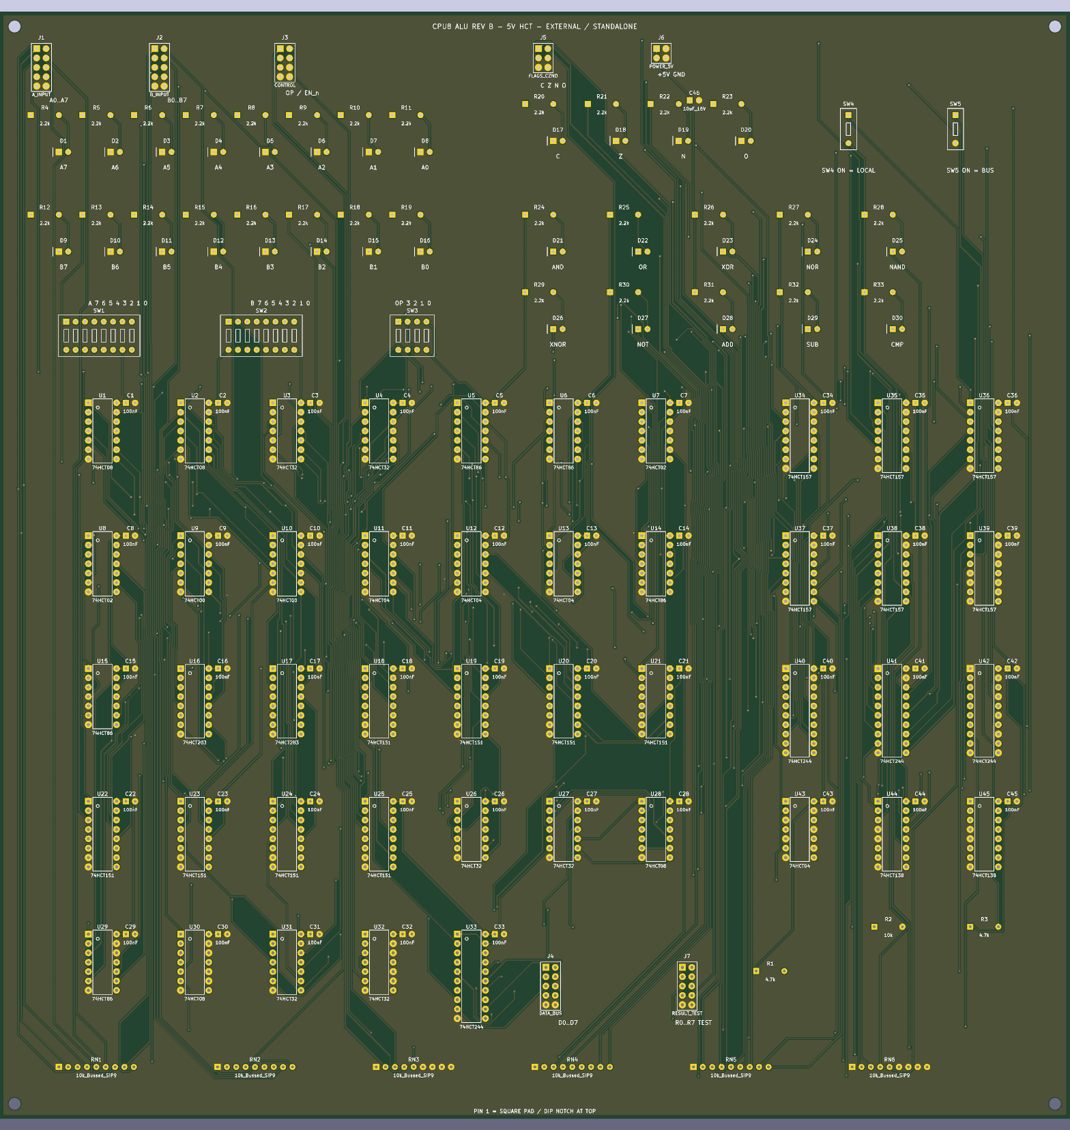
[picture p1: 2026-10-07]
hardware/alu-pcb/rev-b/alu_rev_b_preview.png

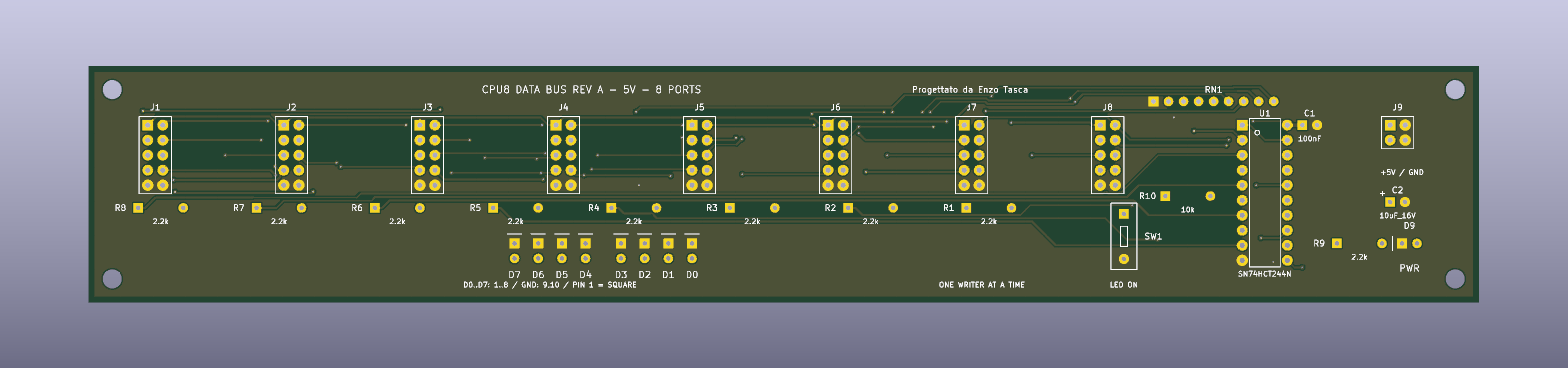
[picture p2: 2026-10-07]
hardware/data-bus-pcb/data_bus_rev_a_preview.png

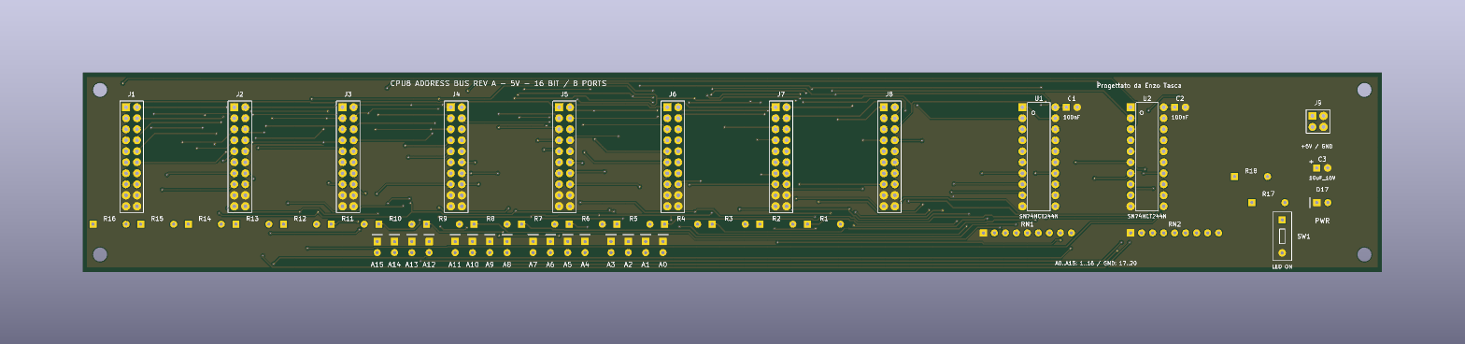
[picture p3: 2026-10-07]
hardware/address-bus-pcb/address_bus_rev_a_preview.png

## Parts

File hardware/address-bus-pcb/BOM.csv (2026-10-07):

Reference | Value | Footprint | Purpose | Mounting_requirement
U1 | SN74HCT244N | DIP-20_W7.62mm | High-impedance address sensing; isolated LED outputs | PDIP-20; rows 7.62mm; add one DIP-20 socket
U2 | SN74HCT244N | DIP-20_W7.62mm | High-impedance address sensing; isolated LED outputs | PDIP-20; rows 7.62mm; add one DIP-20 socket
J1 | ADDR1 | Header_2x10_P2.54mm | Bidirectional parallel 16-bit address port | Unshrouded 2-row male header; pitch 2.54mm
J2 | ADDR2 | Header_2x10_P2.54mm | Bidirectional parallel 16-bit address port | Unshrouded 2-row male header; pitch 2.54mm
J3 | ADDR3 | Header_2x10_P2.54mm | Bidirectional parallel 16-bit address port | Unshrouded 2-row male header; pitch 2.54mm
J4 | ADDR4 | Header_2x10_P2.54mm | Bidirectional parallel 16-bit address port | Unshrouded 2-row male header; pitch 2.54mm
J5 | ADDR5 | Header_2x10_P2.54mm | Bidirectional parallel 16-bit address port | Unshrouded 2-row male header; pitch 2.54mm
J6 | ADDR6 | Header_2x10_P2.54mm | Bidirectional parallel 16-bit address port | Unshrouded 2-row male header; pitch 2.54mm
J7 | ADDR7 | Header_2x10_P2.54mm | Bidirectional parallel 16-bit address port | Unshrouded 2-row male header; pitch 2.54mm
J8 | ADDR8 | Header_2x10_P2.54mm | Bidirectional parallel 16-bit address port | Unshrouded 2-row male header; pitch 2.54mm
J9 | POWER_5V | Header_2x2_P2.54mm | 5V power; ALU J6 / data bus J9 pinout compatible | Unshrouded 2-row male header; pitch 2.54mm
C1 | 100nF | C_Disc_P2.50mm | Local ceramic bypass | Ceramic 100nF 25V; pitch 2.50mm; body <=4x3mm
C2 | 100nF | C_Disc_P2.50mm | Local ceramic bypass | Ceramic 100nF 25V; pitch 2.50mm; body <=4x3mm
C3 | 10uF_16V | C_Radial_P2.50mm | Bulk decoupling; pin 1 positive | Electrolytic 10uF 16V; pitch 2.50mm; diameter <=5mm; pin 1 positive
RN1 | 10k_Bussed_SIP9 | SIP-9_P2.54mm | Eight 10k address pull-downs; common pin 1 | Bussed SIP-9 8x10k; common pin 1; pitch 2.54mm
RN2 | 10k_Bussed_SIP9 | SIP-9_P2.54mm | Eight 10k address pull-downs; common pin 1 | Bussed SIP-9 8x10k; common pin 1; pitch 2.54mm
R16 | 2.2k | R_Axial_P7.62mm | A15 LED current limit | Axial 1/4W 5%; pitch 7.62mm; body <=6.3x2.5mm
D16 | GREEN | LED_D3.0mm_P2.54mm_Vertical | Address bit 15 indicator | 3mm high efficiency LED; pitch 2.54mm; pin 1 cathode
R15 | 2.2k | R_Axial_P7.62mm | A14 LED current limit | Axial 1/4W 5%; pitch 7.62mm; body <=6.3x2.5mm
D15 | GREEN | LED_D3.0mm_P2.54mm_Vertical | Address bit 14 indicator | 3mm high efficiency LED; pitch 2.54mm; pin 1 cathode
R14 | 2.2k | R_Axial_P7.62mm | A13 LED current limit | Axial 1/4W 5%; pitch 7.62mm; body <=6.3x2.5mm
D14 | GREEN | LED_D3.0mm_P2.54mm_Vertical | Address bit 13 indicator | 3mm high efficiency LED; pitch 2.54mm; pin 1 cathode
R13 | 2.2k | R_Axial_P7.62mm | A12 LED current limit | Axial 1/4W 5%; pitch 7.62mm; body <=6.3x2.5mm
D13 | GREEN | LED_D3.0mm_P2.54mm_Vertical | Address bit 12 indicator | 3mm high efficiency LED; pitch 2.54mm; pin 1 cathode
R12 | 2.2k | R_Axial_P7.62mm | A11 LED current limit | Axial 1/4W 5%; pitch 7.62mm; body <=6.3x2.5mm
D12 | GREEN | LED_D3.0mm_P2.54mm_Vertical | Address bit 11 indicator | 3mm high efficiency LED; pitch 2.54mm; pin 1 cathode
R11 | 2.2k | R_Axial_P7.62mm | A10 LED current limit | Axial 1/4W 5%; pitch 7.62mm; body <=6.3x2.5mm
D11 | GREEN | LED_D3.0mm_P2.54mm_Vertical | Address bit 10 indicator | 3mm high efficiency LED; pitch 2.54mm; pin 1 cathode
R10 | 2.2k | R_Axial_P7.62mm | A9 LED current limit | Axial 1/4W 5%; pitch 7.62mm; body <=6.3x2.5mm
D10 | GREEN | LED_D3.0mm_P2.54mm_Vertical | Address bit 9 indicator | 3mm high efficiency LED; pitch 2.54mm; pin 1 cathode
R9 | 2.2k | R_Axial_P7.62mm | A8 LED current limit | Axial 1/4W 5%; pitch 7.62mm; body <=6.3x2.5mm
D9 | GREEN | LED_D3.0mm_P2.54mm_Vertical | Address bit 8 indicator | 3mm high efficiency LED; pitch 2.54mm; pin 1 cathode
R8 | 2.2k | R_Axial_P7.62mm | A7 LED current limit | Axial 1/4W 5%; pitch 7.62mm; body <=6.3x2.5mm
D8 | GREEN | LED_D3.0mm_P2.54mm_Vertical | Address bit 7 indicator | 3mm high efficiency LED; pitch 2.54mm; pin 1 cathode
R7 | 2.2k | R_Axial_P7.62mm | A6 LED current limit | Axial 1/4W 5%; pitch 7.62mm; body <=6.3x2.5mm
D7 | GREEN | LED_D3.0mm_P2.54mm_Vertical | Address bit 6 indicator | 3mm high efficiency LED; pitch 2.54mm; pin 1 cathode
R6 | 2.2k | R_Axial_P7.62mm | A5 LED current limit | Axial 1/4W 5%; pitch 7.62mm; body <=6.3x2.5mm
D6 | GREEN | LED_D3.0mm_P2.54mm_Vertical | Address bit 5 indicator | 3mm high efficiency LED; pitch 2.54mm; pin 1 cathode
R5 | 2.2k | R_Axial_P7.62mm | A4 LED current limit | Axial 1/4W 5%; pitch 7.62mm; body <=6.3x2.5mm
D5 | GREEN | LED_D3.0mm_P2.54mm_Vertical | Address bit 4 indicator | 3mm high efficiency LED; pitch 2.54mm; pin 1 cathode
R4 | 2.2k | R_Axial_P7.62mm | A3 LED current limit | Axial 1/4W 5%; pitch 7.62mm; body <=6.3x2.5mm
D4 | GREEN | LED_D3.0mm_P2.54mm_Vertical | Address bit 3 indicator | 3mm high efficiency LED; pitch 2.54mm; pin 1 cathode
R3 | 2.2k | R_Axial_P7.62mm | A2 LED current limit | Axial 1/4W 5%; pitch 7.62mm; body <=6.3x2.5mm
D3 | GREEN | LED_D3.0mm_P2.54mm_Vertical | Address bit 2 indicator | 3mm high efficiency LED; pitch 2.54mm; pin 1 cathode
R2 | 2.2k | R_Axial_P7.62mm | A1 LED current limit | Axial 1/4W 5%; pitch 7.62mm; body <=6.3x2.5mm
D2 | GREEN | LED_D3.0mm_P2.54mm_Vertical | Address bit 1 indicator | 3mm high efficiency LED; pitch 2.54mm; pin 1 cathode
R1 | 2.2k | R_Axial_P7.62mm | A0 LED current limit | Axial 1/4W 5%; pitch 7.62mm; body <=6.3x2.5mm
D1 | GREEN | LED_D3.0mm_P2.54mm_Vertical | Address bit 0 indicator | 3mm high efficiency LED; pitch 2.54mm; pin 1 cathode
R17 | 2.2k | R_Axial_P7.62mm | Power LED current limit | Axial 1/4W 5%; pitch 7.62mm; body <=6.3x2.5mm
D17 | GREEN | LED_D3.0mm_P2.54mm | 5V supply indicator | 3mm high efficiency LED; pitch 2.54mm; pin 1 cathode
SW1 | SDA01H0BD_LED_ENABLE | SW_DIP_SPST_1_P2.54_W7.62 | ON=bit LEDs enabled; OFF=bit LEDs disabled; power LED remains on | C&K SDA01H0BD SPST through-hole; rows 7.62mm; pin 1 OE_n, pin 2 GND; ON closes
R18 | 10k | R_Axial_P7.62mm | Pull-up disables LED buffers when SW1 is OFF | Axial 1/4W 5%; pitch 7.62mm; body <=6.3x2.5mm

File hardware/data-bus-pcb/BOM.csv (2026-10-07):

Reference | Value | Footprint | Purpose | Mounting_requirement
U1 | SN74HCT244N | DIP-20_W7.62mm | High-impedance bus sensing; isolated LED outputs | PDIP-20; rows 7.62mm; add one DIP-20 socket
J1 | BUS1 | Header_2x5_P2.54mm | Bidirectional data port; ALU J4 compatible | Unshrouded 2-row male header; pitch 2.54mm
J2 | BUS2 | Header_2x5_P2.54mm | Bidirectional data port; ALU J4 compatible | Unshrouded 2-row male header; pitch 2.54mm
J3 | BUS3 | Header_2x5_P2.54mm | Bidirectional data port; ALU J4 compatible | Unshrouded 2-row male header; pitch 2.54mm
J4 | BUS4 | Header_2x5_P2.54mm | Bidirectional data port; ALU J4 compatible | Unshrouded 2-row male header; pitch 2.54mm
J5 | BUS5 | Header_2x5_P2.54mm | Bidirectional data port; ALU J4 compatible | Unshrouded 2-row male header; pitch 2.54mm
J6 | BUS6 | Header_2x5_P2.54mm | Bidirectional data port; ALU J4 compatible | Unshrouded 2-row male header; pitch 2.54mm
J7 | BUS7 | Header_2x5_P2.54mm | Bidirectional data port; ALU J4 compatible | Unshrouded 2-row male header; pitch 2.54mm
J8 | BUS8 | Header_2x5_P2.54mm | Bidirectional data port; ALU J4 compatible | Unshrouded 2-row male header; pitch 2.54mm
J9 | POWER_5V | Header_2x2_P2.54mm | 5V power; ALU J6 pinout compatible | Unshrouded 2-row male header; pitch 2.54mm
C1 | 100nF | C_Disc_P2.50mm | Local ceramic bypass | Ceramic 100nF 25V; pitch 2.50mm; body <=4x3mm
C2 | 10uF_16V | C_Radial_P2.50mm | Bulk decoupling; pin 1 positive | Electrolytic 10uF 16V; pitch 2.50mm; diameter <=5mm; pin 1 positive
RN1 | 10k_Bussed_SIP9 | SIP-9_P2.54mm | Eight 10k bus pull-downs; common pin 1 | Bussed SIP-9 8x10k; common pin 1; pitch 2.54mm
R8 | 2.2k | R_Axial_P7.62mm | D7 LED current limit | Axial 1/4W 5%; pitch 7.62mm; body <=6.3x2.5mm
D8 | GREEN | LED_D3.0mm_P2.54mm_Vertical | Bus bit 7 indicator | 3mm high efficiency LED; pitch 2.54mm; pin 1 cathode
R7 | 2.2k | R_Axial_P7.62mm | D6 LED current limit | Axial 1/4W 5%; pitch 7.62mm; body <=6.3x2.5mm
D7 | GREEN | LED_D3.0mm_P2.54mm_Vertical | Bus bit 6 indicator | 3mm high efficiency LED; pitch 2.54mm; pin 1 cathode
R6 | 2.2k | R_Axial_P7.62mm | D5 LED current limit | Axial 1/4W 5%; pitch 7.62mm; body <=6.3x2.5mm
D6 | GREEN | LED_D3.0mm_P2.54mm_Vertical | Bus bit 5 indicator | 3mm high efficiency LED; pitch 2.54mm; pin 1 cathode
R5 | 2.2k | R_Axial_P7.62mm | D4 LED current limit | Axial 1/4W 5%; pitch 7.62mm; body <=6.3x2.5mm
D5 | GREEN | LED_D3.0mm_P2.54mm_Vertical | Bus bit 4 indicator | 3mm high efficiency LED; pitch 2.54mm; pin 1 cathode
R4 | 2.2k | R_Axial_P7.62mm | D3 LED current limit | Axial 1/4W 5%; pitch 7.62mm; body <=6.3x2.5mm
D4 | GREEN | LED_D3.0mm_P2.54mm_Vertical | Bus bit 3 indicator | 3mm high efficiency LED; pitch 2.54mm; pin 1 cathode
R3 | 2.2k | R_Axial_P7.62mm | D2 LED current limit | Axial 1/4W 5%; pitch 7.62mm; body <=6.3x2.5mm
D3 | GREEN | LED_D3.0mm_P2.54mm_Vertical | Bus bit 2 indicator | 3mm high efficiency LED; pitch 2.54mm; pin 1 cathode
R2 | 2.2k | R_Axial_P7.62mm | D1 LED current limit | Axial 1/4W 5%; pitch 7.62mm; body <=6.3x2.5mm
D2 | GREEN | LED_D3.0mm_P2.54mm_Vertical | Bus bit 1 indicator | 3mm high efficiency LED; pitch 2.54mm; pin 1 cathode
R1 | 2.2k | R_Axial_P7.62mm | D0 LED current limit | Axial 1/4W 5%; pitch 7.62mm; body <=6.3x2.5mm
D1 | GREEN | LED_D3.0mm_P2.54mm_Vertical | Bus bit 0 indicator | 3mm high efficiency LED; pitch 2.54mm; pin 1 cathode
R9 | 2.2k | R_Axial_P7.62mm | Power LED current limit | Axial 1/4W 5%; pitch 7.62mm; body <=6.3x2.5mm
D9 | GREEN | LED_D3.0mm_P2.54mm | 5V supply indicator | 3mm high efficiency LED; pitch 2.54mm; pin 1 cathode
SW1 | SDA01H0BD_LED_ENABLE | SW_DIP_SPST_1_P2.54_W7.62 | ON=bit LEDs enabled; OFF=bit LEDs disabled; power LED remains on | C&K SDA01H0BD SPST through-hole; rows 7.62mm; pin 1 OE_n, pin 2 GND; ON closes
R10 | 10k | R_Axial_P7.62mm | Pull-up disables LED buffers when SW1 is OFF | Axial 1/4W 5%; pitch 7.62mm; body <=6.3x2.5mm

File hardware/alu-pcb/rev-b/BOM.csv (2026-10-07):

Reference | Value | Footprint | Purpose | Part_or_requirement | Mounting_specification
U1 | 74HCT08 | DIP-14_W7.62mm | AND | 74HCT08 compatible pinout | 5V HCT; PDIP-14; rows 7.62mm; optional socket
U2 | 74HCT08 | DIP-14_W7.62mm | AND | 74HCT08 compatible pinout | 5V HCT; PDIP-14; rows 7.62mm; optional socket
U3 | 74HCT32 | DIP-14_W7.62mm | OR | 74HCT32 compatible pinout | 5V HCT; PDIP-14; rows 7.62mm; optional socket
U4 | 74HCT32 | DIP-14_W7.62mm | OR | 74HCT32 compatible pinout | 5V HCT; PDIP-14; rows 7.62mm; optional socket
U5 | 74HCT86 | DIP-14_W7.62mm | XOR | 74HCT86 compatible pinout | 5V HCT; PDIP-14; rows 7.62mm; optional socket
U6 | 74HCT86 | DIP-14_W7.62mm | XOR | 74HCT86 compatible pinout | 5V HCT; PDIP-14; rows 7.62mm; optional socket
U7 | 74HCT02 | DIP-14_W7.62mm | NOR | 74HCT02 compatible pinout | 5V HCT; PDIP-14; rows 7.62mm; optional socket
U8 | 74HCT02 | DIP-14_W7.62mm | NOR | 74HCT02 compatible pinout | 5V HCT; PDIP-14; rows 7.62mm; optional socket
U9 | 74HCT00 | DIP-14_W7.62mm | NAND | 74HCT00 compatible pinout | 5V HCT; PDIP-14; rows 7.62mm; optional socket
U10 | 74HCT00 | DIP-14_W7.62mm | NAND | 74HCT00 compatible pinout | 5V HCT; PDIP-14; rows 7.62mm; optional socket
U11 | 74HCT04 | DIP-14_W7.62mm | XNOR / NOT | 74HCT04 compatible pinout | 5V HCT; PDIP-14; rows 7.62mm; optional socket
U12 | 74HCT04 | DIP-14_W7.62mm | XNOR / NOT | 74HCT04 compatible pinout | 5V HCT; PDIP-14; rows 7.62mm; optional socket
U13 | 74HCT04 | DIP-14_W7.62mm | XNOR / NOT | 74HCT04 compatible pinout | 5V HCT; PDIP-14; rows 7.62mm; optional socket
U14 | 74HCT86 | DIP-14_W7.62mm | B complement | 74HCT86 compatible pinout | 5V HCT; PDIP-14; rows 7.62mm; optional socket
U15 | 74HCT86 | DIP-14_W7.62mm | B complement | 74HCT86 compatible pinout | 5V HCT; PDIP-14; rows 7.62mm; optional socket
U16 | 74HCT283 | DIP-16_W7.62mm | Adder bits 0..3 | CD74HCT283E | 5V HCT; PDIP-16; rows 7.62mm; optional socket
U17 | 74HCT283 | DIP-16_W7.62mm | Adder bits 4..7 | CD74HCT283E | 5V HCT; PDIP-16; rows 7.62mm; optional socket
U18 | 74HCT151 | DIP-16_W7.62mm | Result select bit 0 | CD74HCT151E | 5V HCT; PDIP-16; rows 7.62mm; optional socket
U19 | 74HCT151 | DIP-16_W7.62mm | Result select bit 1 | CD74HCT151E | 5V HCT; PDIP-16; rows 7.62mm; optional socket
U20 | 74HCT151 | DIP-16_W7.62mm | Result select bit 2 | CD74HCT151E | 5V HCT; PDIP-16; rows 7.62mm; optional socket
U21 | 74HCT151 | DIP-16_W7.62mm | Result select bit 3 | CD74HCT151E | 5V HCT; PDIP-16; rows 7.62mm; optional socket
U22 | 74HCT151 | DIP-16_W7.62mm | Result select bit 4 | CD74HCT151E | 5V HCT; PDIP-16; rows 7.62mm; optional socket
U23 | 74HCT151 | DIP-16_W7.62mm | Result select bit 5 | CD74HCT151E | 5V HCT; PDIP-16; rows 7.62mm; optional socket
U24 | 74HCT151 | DIP-16_W7.62mm | Result select bit 6 | CD74HCT151E | 5V HCT; PDIP-16; rows 7.62mm; optional socket
U25 | 74HCT151 | DIP-16_W7.62mm | Result select bit 7 | CD74HCT151E | 5V HCT; PDIP-16; rows 7.62mm; optional socket
U26 | 74HCT32 | DIP-14_W7.62mm | Opcode / output control | 74HCT32 compatible pinout | 5V HCT; PDIP-14; rows 7.62mm; optional socket
U27 | 74HCT32 | DIP-14_W7.62mm | Opcode / output control | 74HCT32 compatible pinout | 5V HCT; PDIP-14; rows 7.62mm; optional socket
U28 | 74HCT08 | DIP-14_W7.62mm | Opcode / output control | 74HCT08 compatible pinout | 5V HCT; PDIP-14; rows 7.62mm; optional socket
U29 | 74HCT86 | DIP-14_W7.62mm | Carry / overflow | 74HCT86 compatible pinout | 5V HCT; PDIP-14; rows 7.62mm; optional socket
U30 | 74HCT08 | DIP-14_W7.62mm | Carry / overflow | 74HCT08 compatible pinout | 5V HCT; PDIP-14; rows 7.62mm; optional socket
U31 | 74HCT32 | DIP-14_W7.62mm | Zero flag | 74HCT32 compatible pinout | 5V HCT; PDIP-14; rows 7.62mm; optional socket
U32 | 74HCT32 | DIP-14_W7.62mm | Zero flag | 74HCT32 compatible pinout | 5V HCT; PDIP-14; rows 7.62mm; optional socket
U33 | 74HCT244 | DIP-20_W7.62mm | Shared bus output | SN74HCT244N | 5V HCT; PDIP-20; rows 7.62mm; optional socket
U34 | 74HCT157 | DIP-16_W7.62mm | External / standalone input selection | SN74HCT157N | 5V HCT; PDIP-16; rows 7.62mm; optional socket
U35 | 74HCT157 | DIP-16_W7.62mm | External / standalone input selection | SN74HCT157N | 5V HCT; PDIP-16; rows 7.62mm; optional socket
U36 | 74HCT157 | DIP-16_W7.62mm | External / standalone input selection | SN74HCT157N | 5V HCT; PDIP-16; rows 7.62mm; optional socket
U37 | 74HCT157 | DIP-16_W7.62mm | External / standalone input selection | SN74HCT157N | 5V HCT; PDIP-16; rows 7.62mm; optional socket
U38 | 74HCT157 | DIP-16_W7.62mm | External / standalone input selection | SN74HCT157N | 5V HCT; PDIP-16; rows 7.62mm; optional socket
U39 | 74HCT157 | DIP-16_W7.62mm | External / standalone input selection | SN74HCT157N | 5V HCT; PDIP-16; rows 7.62mm; optional socket
U40 | 74HCT244 | DIP-20_W7.62mm | Operand / flag LED driver | SN74HCT244N | 5V HCT; PDIP-20; rows 7.62mm; optional socket
U41 | 74HCT244 | DIP-20_W7.62mm | Operand / flag LED driver | SN74HCT244N | 5V HCT; PDIP-20; rows 7.62mm; optional socket
U42 | 74HCT244 | DIP-20_W7.62mm | Operand / flag LED driver | SN74HCT244N | 5V HCT; PDIP-20; rows 7.62mm; optional socket
U43 | 74HCT04 | DIP-14_W7.62mm | Opcode LED decoder enable | 74HCT04 compatible pinout | 5V HCT; PDIP-14; rows 7.62mm; optional socket
U44 | 74HCT138 | DIP-16_W7.62mm | Operation LED decoder | SN74HCT138N | 5V HCT; PDIP-16; rows 7.62mm; optional socket
U45 | 74HCT138 | DIP-16_W7.62mm | Operation LED decoder | SN74HCT138N | 5V HCT; PDIP-16; rows 7.62mm; optional socket
C1 | 100nF | C_Disc_P2.50mm | Local bypass | 100nF 25V ceramic | Pitch 2.50mm; body max 4x3mm; nonpolarized
C2 | 100nF | C_Disc_P2.50mm | Local bypass | 100nF 25V ceramic | Pitch 2.50mm; body max 4x3mm; nonpolarized
C3 | 100nF | C_Disc_P2.50mm | Local bypass | 100nF 25V ceramic | Pitch 2.50mm; body max 4x3mm; nonpolarized
C4 | 100nF | C_Disc_P2.50mm | Local bypass | 100nF 25V ceramic | Pitch 2.50mm; body max 4x3mm; nonpolarized
C5 | 100nF | C_Disc_P2.50mm | Local bypass | 100nF 25V ceramic | Pitch 2.50mm; body max 4x3mm; nonpolarized
C6 | 100nF | C_Disc_P2.50mm | Local bypass | 100nF 25V ceramic | Pitch 2.50mm; body max 4x3mm; nonpolarized
C7 | 100nF | C_Disc_P2.50mm | Local bypass | 100nF 25V ceramic | Pitch 2.50mm; body max 4x3mm; nonpolarized
C8 | 100nF | C_Disc_P2.50mm | Local bypass | 100nF 25V ceramic | Pitch 2.50mm; body max 4x3mm; nonpolarized
C9 | 100nF | C_Disc_P2.50mm | Local bypass | 100nF 25V ceramic | Pitch 2.50mm; body max 4x3mm; nonpolarized
C10 | 100nF | C_Disc_P2.50mm | Local bypass | 100nF 25V ceramic | Pitch 2.50mm; body max 4x3mm; nonpolarized
C11 | 100nF | C_Disc_P2.50mm | Local bypass | 100nF 25V ceramic | Pitch 2.50mm; body max 4x3mm; nonpolarized
C12 | 100nF | C_Disc_P2.50mm | Local bypass | 100nF 25V ceramic | Pitch 2.50mm; body max 4x3mm; nonpolarized
C13 | 100nF | C_Disc_P2.50mm | Local bypass | 100nF 25V ceramic | Pitch 2.50mm; body max 4x3mm; nonpolarized
C14 | 100nF | C_Disc_P2.50mm | Local bypass | 100nF 25V ceramic | Pitch 2.50mm; body max 4x3mm; nonpolarized
C15 | 100nF | C_Disc_P2.50mm | Local bypass | 100nF 25V ceramic | Pitch 2.50mm; body max 4x3mm; nonpolarized
C16 | 100nF | C_Disc_P2.50mm | Local bypass | 100nF 25V ceramic | Pitch 2.50mm; body max 4x3mm; nonpolarized
C17 | 100nF | C_Disc_P2.50mm | Local bypass | 100nF 25V ceramic | Pitch 2.50mm; body max 4x3mm; nonpolarized
C18 | 100nF | C_Disc_P2.50mm | Local bypass | 100nF 25V ceramic | Pitch 2.50mm; body max 4x3mm; nonpolarized
C19 | 100nF | C_Disc_P2.50mm | Local bypass | 100nF 25V ceramic | Pitch 2.50mm; body max 4x3mm; nonpolarized
C20 | 100nF | C_Disc_P2.50mm | Local bypass | 100nF 25V ceramic | Pitch 2.50mm; body max 4x3mm; nonpolarized
C21 | 100nF | C_Disc_P2.50mm | Local bypass | 100nF 25V ceramic | Pitch 2.50mm; body max 4x3mm; nonpolarized
C22 | 100nF | C_Disc_P2.50mm | Local bypass | 100nF 25V ceramic | Pitch 2.50mm; body max 4x3mm; nonpolarized
C23 | 100nF | C_Disc_P2.50mm | Local bypass | 100nF 25V ceramic | Pitch 2.50mm; body max 4x3mm; nonpolarized
C24 | 100nF | C_Disc_P2.50mm | Local bypass | 100nF 25V ceramic | Pitch 2.50mm; body max 4x3mm; nonpolarized
C25 | 100nF | C_Disc_P2.50mm | Local bypass | 100nF 25V ceramic | Pitch 2.50mm; body max 4x3mm; nonpolarized
C26 | 100nF | C_Disc_P2.50mm | Local bypass | 100nF 25V ceramic | Pitch 2.50mm; body max 4x3mm; nonpolarized
C27 | 100nF | C_Disc_P2.50mm | Local bypass | 100nF 25V ceramic | Pitch 2.50mm; body max 4x3mm; nonpolarized
C28 | 100nF | C_Disc_P2.50mm | Local bypass | 100nF 25V ceramic | Pitch 2.50mm; body max 4x3mm; nonpolarized
C29 | 100nF | C_Disc_P2.50mm | Local bypass | 100nF 25V ceramic | Pitch 2.50mm; body max 4x3mm; nonpolarized
C30 | 100nF | C_Disc_P2.50mm | Local bypass | 100nF 25V ceramic | Pitch 2.50mm; body max 4x3mm; nonpolarized
C31 | 100nF | C_Disc_P2.50mm | Local bypass | 100nF 25V ceramic | Pitch 2.50mm; body max 4x3mm; nonpolarized
C32 | 100nF | C_Disc_P2.50mm | Local bypass | 100nF 25V ceramic | Pitch 2.50mm; body max 4x3mm; nonpolarized
C33 | 100nF | C_Disc_P2.50mm | Local bypass | 100nF 25V ceramic | Pitch 2.50mm; body max 4x3mm; nonpolarized
C34 | 100nF | C_Disc_P2.50mm | Local bypass | 100nF 25V ceramic | Pitch 2.50mm; body max 4x3mm; nonpolarized
C35 | 100nF | C_Disc_P2.50mm | Local bypass | 100nF 25V ceramic | Pitch 2.50mm; body max 4x3mm; nonpolarized
C36 | 100nF | C_Disc_P2.50mm | Local bypass | 100nF 25V ceramic | Pitch 2.50mm; body max 4x3mm; nonpolarized
C37 | 100nF | C_Disc_P2.50mm | Local bypass | 100nF 25V ceramic | Pitch 2.50mm; body max 4x3mm; nonpolarized
C38 | 100nF | C_Disc_P2.50mm | Local bypass | 100nF 25V ceramic | Pitch 2.50mm; body max 4x3mm; nonpolarized
C39 | 100nF | C_Disc_P2.50mm | Local bypass | 100nF 25V ceramic | Pitch 2.50mm; body max 4x3mm; nonpolarized
C40 | 100nF | C_Disc_P2.50mm | Local bypass | 100nF 25V ceramic | Pitch 2.50mm; body max 4x3mm; nonpolarized
C41 | 100nF | C_Disc_P2.50mm | Local bypass | 100nF 25V ceramic | Pitch 2.50mm; body max 4x3mm; nonpolarized
C42 | 100nF | C_Disc_P2.50mm | Local bypass | 100nF 25V ceramic | Pitch 2.50mm; body max 4x3mm; nonpolarized
C43 | 100nF | C_Disc_P2.50mm | Local bypass | 100nF 25V ceramic | Pitch 2.50mm; body max 4x3mm; nonpolarized
C44 | 100nF | C_Disc_P2.50mm | Local bypass | 100nF 25V ceramic | Pitch 2.50mm; body max 4x3mm; nonpolarized
C45 | 100nF | C_Disc_P2.50mm | Local bypass | 100nF 25V ceramic | Pitch 2.50mm; body max 4x3mm; nonpolarized
J1 | A_INPUT | Header_2x5_P2.54mm | A_INPUT | 2-row male pin header | Pitch 2.54mm; 5x2 contacts; unshrouded
J2 | B_INPUT | Header_2x5_P2.54mm | B_INPUT | 2-row male pin header | Pitch 2.54mm; 5x2 contacts; unshrouded
J3 | CONTROL | Header_2x4_P2.54mm | CONTROL | 2-row male pin header | Pitch 2.54mm; 4x2 contacts; unshrouded
J4 | DATA_BUS | Header_2x5_P2.54mm | DATA_BUS | 2-row male pin header | Pitch 2.54mm; 5x2 contacts; unshrouded
J5 | FLAGS_CZNO | Header_2x3_P2.54mm | FLAGS_CZNO | 2-row male pin header | Pitch 2.54mm; 3x2 contacts; unshrouded
J6 | POWER_5V | Header_2x2_P2.54mm | POWER_5V | 2-row male pin header | Pitch 2.54mm; 2x2 contacts; unshrouded
J7 | RESULT_TEST | Header_2x5_P2.54mm | RESULT_TEST | 2-row male pin header | Pitch 2.54mm; 5x2 contacts; unshrouded
RN1 | 10k_Bussed_SIP9 | SIP-9_P2.54mm | Input pull-downs | Bussed 8x10k SIP-9 | Common pin 1; pitch 2.54mm; isolated networks incompatible
RN2 | 10k_Bussed_SIP9 | SIP-9_P2.54mm | Input pull-downs | Bussed 8x10k SIP-9 | Common pin 1; pitch 2.54mm; isolated networks incompatible
RN3 | 10k_Bussed_SIP9 | SIP-9_P2.54mm | Input pull-downs | Bussed 8x10k SIP-9 | Common pin 1; pitch 2.54mm; isolated networks incompatible
RN4 | 10k_Bussed_SIP9 | SIP-9_P2.54mm | Input pull-downs | Bussed 8x10k SIP-9 | Common pin 1; pitch 2.54mm; isolated networks incompatible
RN5 | 10k_Bussed_SIP9 | SIP-9_P2.54mm | Input pull-downs | Bussed 8x10k SIP-9 | Common pin 1; pitch 2.54mm; isolated networks incompatible
RN6 | 10k_Bussed_SIP9 | SIP-9_P2.54mm | Input pull-downs | Bussed 8x10k SIP-9 | Common pin 1; pitch 2.54mm; isolated networks incompatible
R1 | 4.7k | R_Axial_P7.62mm | External default bus disable | 4.7k 1/4W 5% | Axial; pitch 7.62mm; body max 6.3x2.5mm
C46 | 10uF_16V | C_Radial_P2.50mm | Supply bulk | 10uF 16V electrolytic | Pitch 2.50mm; diameter max 5mm; pad 1 positive
SW1 | LOCAL_A | SW_DIP_SPST_8_P2.54_W7.62 | Local input DIP switches | SDA08H0BD | C&K; through-hole SPST; pitch 2.54mm; rows 7.62mm; 8 contacts
SW2 | LOCAL_B | SW_DIP_SPST_8_P2.54_W7.62 | Local input DIP switches | SDA08H0BD | C&K; through-hole SPST; pitch 2.54mm; rows 7.62mm; 8 contacts
SW3 | LOCAL_OP | SW_DIP_SPST_4_P2.54_W7.62 | Local input DIP switches | SDA04H0BD | C&K; through-hole SPST; pitch 2.54mm; rows 7.62mm; 4 contacts
SW4 | MODE_LOCAL | SW_DIP_SPST_1_P2.54_W7.62 | OFF=external, ON=standalone | SDA01H0BD | C&K; through-hole SPST; pitch 2.54mm; rows 7.62mm; 1 contacts
SW5 | LOCAL_BUS_ENABLE | SW_DIP_SPST_1_P2.54_W7.62 | OFF=bus disabled, ON=bus enabled in standalone | SDA01H0BD | C&K; through-hole SPST; pitch 2.54mm; rows 7.62mm; 1 contacts
R2 | 10k | R_Axial_P7.62mm | Default external mode | 10k 1/4W 5% | Axial; pitch 7.62mm; body max 6.3x2.5mm
R3 | 4.7k | R_Axial_P7.62mm | Local default bus disable | 4.7k 1/4W 5% | Axial; pitch 7.62mm; body max 6.3x2.5mm
R4 | 2.2k | R_Axial_P7.62mm | A7 LED series resistor | 2.2k 1/4W 5% | Axial; pitch 7.62mm; body max 6.3x2.5mm
D1 | GREEN | LED_D3.0mm_P2.54mm | Selected A7 indicator | GREEN high efficiency LED | Through-hole 3mm; pitch 2.54mm; pad 1 cathode; pad 2 anode
R5 | 2.2k | R_Axial_P7.62mm | A6 LED series resistor | 2.2k 1/4W 5% | Axial; pitch 7.62mm; body max 6.3x2.5mm
D2 | GREEN | LED_D3.0mm_P2.54mm | Selected A6 indicator | GREEN high efficiency LED | Through-hole 3mm; pitch 2.54mm; pad 1 cathode; pad 2 anode
R6 | 2.2k | R_Axial_P7.62mm | A5 LED series resistor | 2.2k 1/4W 5% | Axial; pitch 7.62mm; body max 6.3x2.5mm
D3 | GREEN | LED_D3.0mm_P2.54mm | Selected A5 indicator | GREEN high efficiency LED | Through-hole 3mm; pitch 2.54mm; pad 1 cathode; pad 2 anode
R7 | 2.2k | R_Axial_P7.62mm | A4 LED series resistor | 2.2k 1/4W 5% | Axial; pitch 7.62mm; body max 6.3x2.5mm
D4 | GREEN | LED_D3.0mm_P2.54mm | Selected A4 indicator | GREEN high efficiency LED | Through-hole 3mm; pitch 2.54mm; pad 1 cathode; pad 2 anode
R8 | 2.2k | R_Axial_P7.62mm | A3 LED series resistor | 2.2k 1/4W 5% | Axial; pitch 7.62mm; body max 6.3x2.5mm
D5 | GREEN | LED_D3.0mm_P2.54mm | Selected A3 indicator | GREEN high efficiency LED | Through-hole 3mm; pitch 2.54mm; pad 1 cathode; pad 2 anode
R9 | 2.2k | R_Axial_P7.62mm | A2 LED series resistor | 2.2k 1/4W 5% | Axial; pitch 7.62mm; body max 6.3x2.5mm
D6 | GREEN | LED_D3.0mm_P2.54mm | Selected A2 indicator | GREEN high efficiency LED | Through-hole 3mm; pitch 2.54mm; pad 1 cathode; pad 2 anode
R10 | 2.2k | R_Axial_P7.62mm | A1 LED series resistor | 2.2k 1/4W 5% | Axial; pitch 7.62mm; body max 6.3x2.5mm
D7 | GREEN | LED_D3.0mm_P2.54mm | Selected A1 indicator | GREEN high efficiency LED | Through-hole 3mm; pitch 2.54mm; pad 1 cathode; pad 2 anode
R11 | 2.2k | R_Axial_P7.62mm | A0 LED series resistor | 2.2k 1/4W 5% | Axial; pitch 7.62mm; body max 6.3x2.5mm
D8 | GREEN | LED_D3.0mm_P2.54mm | Selected A0 indicator | GREEN high efficiency LED | Through-hole 3mm; pitch 2.54mm; pad 1 cathode; pad 2 anode
R12 | 2.2k | R_Axial_P7.62mm | B7 LED series resistor | 2.2k 1/4W 5% | Axial; pitch 7.62mm; body max 6.3x2.5mm
D9 | GREEN | LED_D3.0mm_P2.54mm | Selected B7 indicator | GREEN high efficiency LED | Through-hole 3mm; pitch 2.54mm; pad 1 cathode; pad 2 anode
R13 | 2.2k | R_Axial_P7.62mm | B6 LED series resistor | 2.2k 1/4W 5% | Axial; pitch 7.62mm; body max 6.3x2.5mm
D10 | GREEN | LED_D3.0mm_P2.54mm | Selected B6 indicator | GREEN high efficiency LED | Through-hole 3mm; pitch 2.54mm; pad 1 cathode; pad 2 anode
R14 | 2.2k | R_Axial_P7.62mm | B5 LED series resistor | 2.2k 1/4W 5% | Axial; pitch 7.62mm; body max 6.3x2.5mm
D11 | GREEN | LED_D3.0mm_P2.54mm | Selected B5 indicator | GREEN high efficiency LED | Through-hole 3mm; pitch 2.54mm; pad 1 cathode; pad 2 anode
R15 | 2.2k | R_Axial_P7.62mm | B4 LED series resistor | 2.2k 1/4W 5% | Axial; pitch 7.62mm; body max 6.3x2.5mm
D12 | GREEN | LED_D3.0mm_P2.54mm | Selected B4 indicator | GREEN high efficiency LED | Through-hole 3mm; pitch 2.54mm; pad 1 cathode; pad 2 anode
R16 | 2.2k | R_Axial_P7.62mm | B3 LED series resistor | 2.2k 1/4W 5% | Axial; pitch 7.62mm; body max 6.3x2.5mm
D13 | GREEN | LED_D3.0mm_P2.54mm | Selected B3 indicator | GREEN high efficiency LED | Through-hole 3mm; pitch 2.54mm; pad 1 cathode; pad 2 anode
R17 | 2.2k | R_Axial_P7.62mm | B2 LED series resistor | 2.2k 1/4W 5% | Axial; pitch 7.62mm; body max 6.3x2.5mm
D14 | GREEN | LED_D3.0mm_P2.54mm | Selected B2 indicator | GREEN high efficiency LED | Through-hole 3mm; pitch 2.54mm; pad 1 cathode; pad 2 anode
R18 | 2.2k | R_Axial_P7.62mm | B1 LED series resistor | 2.2k 1/4W 5% | Axial; pitch 7.62mm; body max 6.3x2.5mm
D15 | GREEN | LED_D3.0mm_P2.54mm | Selected B1 indicator | GREEN high efficiency LED | Through-hole 3mm; pitch 2.54mm; pad 1 cathode; pad 2 anode
R19 | 2.2k | R_Axial_P7.62mm | B0 LED series resistor | 2.2k 1/4W 5% | Axial; pitch 7.62mm; body max 6.3x2.5mm
D16 | GREEN | LED_D3.0mm_P2.54mm | Selected B0 indicator | GREEN high efficiency LED | Through-hole 3mm; pitch 2.54mm; pad 1 cathode; pad 2 anode
R20 | 2.2k | R_Axial_P7.62mm | C LED series resistor | 2.2k 1/4W 5% | Axial; pitch 7.62mm; body max 6.3x2.5mm
D17 | YELLOW | LED_D3.0mm_P2.54mm | Selected C indicator | YELLOW high efficiency LED | Through-hole 3mm; pitch 2.54mm; pad 1 cathode; pad 2 anode
R21 | 2.2k | R_Axial_P7.62mm | Z LED series resistor | 2.2k 1/4W 5% | Axial; pitch 7.62mm; body max 6.3x2.5mm
D18 | YELLOW | LED_D3.0mm_P2.54mm | Selected Z indicator | YELLOW high efficiency LED | Through-hole 3mm; pitch 2.54mm; pad 1 cathode; pad 2 anode
R22 | 2.2k | R_Axial_P7.62mm | N LED series resistor | 2.2k 1/4W 5% | Axial; pitch 7.62mm; body max 6.3x2.5mm
D19 | YELLOW | LED_D3.0mm_P2.54mm | Selected N indicator | YELLOW high efficiency LED | Through-hole 3mm; pitch 2.54mm; pad 1 cathode; pad 2 anode
R23 | 2.2k | R_Axial_P7.62mm | O LED series resistor | 2.2k 1/4W 5% | Axial; pitch 7.62mm; body max 6.3x2.5mm
D20 | YELLOW | LED_D3.0mm_P2.54mm | Selected O indicator | YELLOW high efficiency LED | Through-hole 3mm; pitch 2.54mm; pad 1 cathode; pad 2 anode
R24 | 2.2k | R_Axial_P7.62mm | AND LED series resistor | 2.2k 1/4W 5% | Axial; pitch 7.62mm; body max 6.3x2.5mm
D21 | BLUE | LED_D3.0mm_P2.54mm | AND selected indicator | BLUE high efficiency LED | Through-hole 3mm; pitch 2.54mm; pad 1 cathode; pad 2 anode
R25 | 2.2k | R_Axial_P7.62mm | OR LED series resistor | 2.2k 1/4W 5% | Axial; pitch 7.62mm; body max 6.3x2.5mm
D22 | BLUE | LED_D3.0mm_P2.54mm | OR selected indicator | BLUE high efficiency LED | Through-hole 3mm; pitch 2.54mm; pad 1 cathode; pad 2 anode
R26 | 2.2k | R_Axial_P7.62mm | XOR LED series resistor | 2.2k 1/4W 5% | Axial; pitch 7.62mm; body max 6.3x2.5mm
D23 | BLUE | LED_D3.0mm_P2.54mm | XOR selected indicator | BLUE high efficiency LED | Through-hole 3mm; pitch 2.54mm; pad 1 cathode; pad 2 anode
R27 | 2.2k | R_Axial_P7.62mm | NOR LED series resistor | 2.2k 1/4W 5% | Axial; pitch 7.62mm; body max 6.3x2.5mm
D24 | BLUE | LED_D3.0mm_P2.54mm | NOR selected indicator | BLUE high efficiency LED | Through-hole 3mm; pitch 2.54mm; pad 1 cathode; pad 2 anode
R28 | 2.2k | R_Axial_P7.62mm | NAND LED series resistor | 2.2k 1/4W 5% | Axial; pitch 7.62mm; body max 6.3x2.5mm
D25 | BLUE | LED_D3.0mm_P2.54mm | NAND selected indicator | BLUE high efficiency LED | Through-hole 3mm; pitch 2.54mm; pad 1 cathode; pad 2 anode
R29 | 2.2k | R_Axial_P7.62mm | XNOR LED series resistor | 2.2k 1/4W 5% | Axial; pitch 7.62mm; body max 6.3x2.5mm
D26 | BLUE | LED_D3.0mm_P2.54mm | XNOR selected indicator | BLUE high efficiency LED | Through-hole 3mm; pitch 2.54mm; pad 1 cathode; pad 2 anode
R30 | 2.2k | R_Axial_P7.62mm | NOT LED series resistor | 2.2k 1/4W 5% | Axial; pitch 7.62mm; body max 6.3x2.5mm
D27 | BLUE | LED_D3.0mm_P2.54mm | NOT selected indicator | BLUE high efficiency LED | Through-hole 3mm; pitch 2.54mm; pad 1 cathode; pad 2 anode
R31 | 2.2k | R_Axial_P7.62mm | ADD LED series resistor | 2.2k 1/4W 5% | Axial; pitch 7.62mm; body max 6.3x2.5mm
D28 | BLUE | LED_D3.0mm_P2.54mm | ADD selected indicator | BLUE high efficiency LED | Through-hole 3mm; pitch 2.54mm; pad 1 cathode; pad 2 anode
R32 | 2.2k | R_Axial_P7.62mm | SUB LED series resistor | 2.2k 1/4W 5% | Axial; pitch 7.62mm; body max 6.3x2.5mm
D29 | BLUE | LED_D3.0mm_P2.54mm | SUB selected indicator | BLUE high efficiency LED | Through-hole 3mm; pitch 2.54mm; pad 1 cathode; pad 2 anode
R33 | 2.2k | R_Axial_P7.62mm | CMP LED series resistor | 2.2k 1/4W 5% | Axial; pitch 7.62mm; body max 6.3x2.5mm
D30 | BLUE | LED_D3.0mm_P2.54mm | CMP selected indicator | BLUE high efficiency LED | Through-hole 3mm; pitch 2.54mm; pad 1 cathode; pad 2 anode

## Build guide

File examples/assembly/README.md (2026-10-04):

# Programmi assembly

Questa cartella contiene programmi di esempio per la CPU a 8 bit.

I file `.asm` vengono assemblati dallo strumento in `tools/assembler`.

La sintassi usata negli esempi e descritta in [`docs/assembly-language.md`](../../docs/assembly-language.md). La semantica e la codifica macchina delle istruzioni sono definite in [`docs/isa.md`](../../docs/isa.md).

## Esempi disponibili

| File | Cosa mostra |
| --- | --- |
| `demo.asm` | template generale commentato con `.equ`, sezioni, label, variabili e schema della memoria |
| `01_numeric_formats.asm` | valori decimali, esadecimali e binari |
| `02_memory_and_directives.asm` | direttive, costanti, label e memoria |
| `03_add_two_numbers.asm` | somma con `RA`, `RB`, `ADD` e copia del risultato in un registro generale |
| `04_alu_operations.asm` | operazioni `AND`, `OR`, `XOR`, `NOR`, `NAND`, `XNOR`, `NOT` e `SUB` |
| `05_compare_unsigned.asm` | confronto unsigned con `CMP`, `JZ`, `JC` e `JMP` |
| `06_labels_and_two_passes.asm` | label in avanti e assemblaggio in due passate |
| `07_jump_conditions.asm` | panoramica di `JZ`, `JNZ`, `JC`, `JNC`, `JN`, `JNN`, `JO` e `JNO` |
| `cu_isa_smoke.asm` | prova fisica senza IN/OUT: SUB, CMP, JNZ, memoria diretta/IDX e HLT; scrive tre byte verificabili in RAM |

`demo.asm` non e numerato perche serve come template autonomo. Gli altri file seguono l'ordine didattico consigliato da `01` a `07`.
Riassemblare gli esempi prima di caricarli nella EPROM programma: i nuovi
opcode di `SUB` e dei salti condizionati non sono compatibili con i vecchi
binari.

## Sequenza per il video sull'assembler

Per il video dedicato all'assembler si possono mostrare `demo.asm`, `01`, `02` e `06`. I commenti possono essere letti o evidenziati mentre si analizzano le singole righe.

| File | Risultato previsto |
| --- | --- |
| `01_numeric_formats.asm` | `R0`...`R3` contengono tutti `0x2A` |
| `02_memory_and_directives.asm` | `R0` e `R1` contengono entrambi `0x0A` |
| `06_labels_and_two_passes.asm` | `R2` contiene `1` quando i valori sono uguali |

Compilazione dell'assembler:

```sh
make -C tools/assembler
```

Assemblaggio dei tre esempi dalla root del repository:

```sh
tools/assembler/build/cpu8asm examples/assembly/01_numeric_formats.asm -o tools/assembler/build/video-01
tools/assembler/build/cpu8asm examples/assembly/02_memory_and_directives.asm -o tools/assembler/build/video-02
tools/assembler/build/cpu8asm examples/assembly/06_labels_and_two_passes.asm -o tools/assembler/build/video-06
```

Dimensioni attese:

```text
01_numeric_formats.asm           9 byte
02_memory_and_directives.asm    10 byte
06_labels_and_two_passes.asm    18 byte
```

Durante la registrazione si puo seguire questa sequenza:

1. Confrontare le quattro scritture dello stesso valore in `01_numeric_formats.asm`.
2. Aprire `video-01.hex` e verificare che il byte immediato sia sempre `2A`.
3. Usare `02_memory_and_directives.asm` per distinguere istruzioni e direttive.
4. Aprire `video-02.hex` e mostrare la label `counter`, calcolata automaticamente e tradotta in `09 00` little-endian.
5. Usare `06_labels_and_two_passes.asm` per spiegare la tabella dei simboli.
6. Aprire `video-06.hex` e mostrare gli indirizzi `0F 00` per `equal` e `11 00` per `done`.

## Copertura ISA

| Area | Esempi |
| --- | --- |
| Sistema | tutti i programmi terminano con `HLT` (`0x00`); `NOP` vale `0x01` |
| Load immediate | `demo.asm` e gli esempi numerati coprono `LDI` |
| Memoria | `demo.asm` e `02_memory_and_directives.asm` coprono `LDA`, `STA`, `.data` e `.byte` |
| ALU | `03_add_two_numbers.asm` copre `ADD`; `04_alu_operations.asm` copre le altre operazioni; `05_compare_unsigned.asm` copre `CMP` |
| Salti | `05_compare_unsigned.asm` copre i salti unsigned principali; `07_jump_conditions.asm` elenca tutti i salti condizionali; `06_labels_and_two_passes.asm` mostra le label in avanti |
| Trasferimenti | `03_add_two_numbers.asm`, `04_alu_operations.asm` e `05_compare_unsigned.asm` coprono `MOV RA, Rn`, `MOV RB, Rn` e `MOV Rn, RA` |

## Esempio minimo

```asm
.code 0x0000
LDI R0, 0x0A
STA R0, counter
LDA R1, counter
HLT

.data
counter: .byte 0x00
```

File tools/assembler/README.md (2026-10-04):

# CPU8 Assembler

Assembler in C per la CPU didattica a 8 bit.

Questa prima versione implementa una pipeline minima ma funzionante: legge assembly, risolve label e costanti, genera byte macchina e scrive gli output `.bin`, `.hex`, `.bits` e `.h`.

Documentazione di riferimento:

- [`docs/assembly-language.md`](../../docs/assembly-language.md) descrive la sintassi accettata;
- [`docs/isa.md`](../../docs/isa.md) definisce semantica, formati e opcode della CPU.

## Obiettivo

Il tool dovra trasformare programmi assembly in file caricabili nella ROM/EEPROM della CPU.

Esempio:

```asm
.code 0x0000
LDI R0, 0x0A
STA R0, counter
HLT

.data
counter: .byte 0x00
```

Output generati:

- `.bin`: byte macchina raw;
- `.hex`: dump leggibile per debug;
- `.bits`: dump binario testuale per debug visivo;
- `.h`: array C/C++ da includere in uno sketch Arduino.

Gli opcode di sistema attuali sono `HLT=0x00` e `NOP=0x01`; i binari
assemblati con la codifica precedente vanno rigenerati prima dell'uso.
Anche `SUB=0x78` e i salti condizionati hanno opcode aggiornati per essere
distinguibili dalle tre Control ROM collegate a `IR[7:3]`. Non usare vecchi
binari con `SUB=0x68` o salti `0xA1..0xA7` sulla CU aggiornata.

Esempio di riga `.bits`:

```text
0000: 00100000  ; 0x20
```

In caso di errore sintattico, l'assembler prova a indicare la riga:

```text
cpu8asm: line 2: invalid MOV form; use MOV RA, Rn, MOV RB, Rn or MOV Rn, RA
```

## Comandi Make

I comandi possono essere eseguiti dalla root del repository usando `-C tools/assembler`.

| Comando | Effetto |
| --- | --- |
| `make -C tools/assembler` | compila l'assembler |
| `make -C tools/assembler test` | compila ed esegue i test |
| `make -C tools/assembler clean` | elimina la cartella di build dell'assembler |

Se sei gia dentro `tools/assembler`, i comandi equivalenti sono:

```sh
make
make test
make clean
```

### Build

Compila l'eseguibile:

```sh
make -C tools/assembler
```

Output:

```text
tools/assembler/build/cpu8asm
```

### Test

Esegue la suite di test:

```sh
make -C tools/assembler test
```

Il test:

- assembla `tests/smoke.asm`;
- assembla `tests/labels.asm`;
- assembla `tests/auto_sections.asm`, verificando `.code` e `.data` senza indirizzo;
- confronta gli `.hex` e `.bits` generati con i file in `tests/expected`;
- verifica che `tests/invalid.asm` fallisca con un errore che include il numero di riga.

### Clean

Rimuove i file compilati:

```sh
make -C tools/assembler clean
```

## Studio del codice

Per una spiegazione didattica dei file, dei moduli e del percorso consigliato di studio, leggere:

```text
tools/assembler/STUDY_GUIDE.md
```

## Uso

Se sei nella cartella `tools/assembler`:

```sh
build/cpu8asm ../../examples/assembly/demo.asm -o build/demo
```

Questo genera:

```text
build/demo.bin
build/demo.hex
build/demo.bits
build/demo.h
```

Dalla root del repository puoi usare lo stesso eseguibile con il path completo:

```sh
tools/assembler/build/cpu8asm examples/assembly/demo.asm -o tools/assembler/build/demo
```

## Struttura

```text
tools/assembler/
├── include/
│   ├── assembler.h
│   ├── errors.h
│   ├── isa.h
│   ├── output.h
│   └── parser.h
├── src/
│   ├── assembler.c
│   ├── errors.c
│   ├── isa.c
│   ├── main.c
│   ├── output.c
│   └── parser.c
├── tests/
│   ├── expected/
│   ├── invalid.asm
│   ├── labels.asm
│   └── smoke.asm
├── Makefile
├── STUDY_GUIDE.md
└── README.md
```

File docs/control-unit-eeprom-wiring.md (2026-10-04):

# Collegamenti EEPROM della Control Unit

Le tre EEPROM di controllo condividono lo stesso bus indirizzi. Il segnale
`BOOT_RUN` può utilizzare `A12` per selezionare due banchi di microcodice da
4096 byte: `0` per boot e `1` per run.

| Pin indirizzo | Segnale | Funzione |
| --- | --- | --- |
| `A0` | `µSTEP[2]` | Bit piu significativo del microstep nel cablaggio attuale. |
| `A1` | `µSTEP[1]` | Bit 1 del microstep. |
| `A2` | `µSTEP[0]` | Bit meno significativo del microstep; con `A0` e `A1` seleziona `T1..T8`. |
| `A3` | `IR[3]` | Primo dei cinque bit alti dell'opcode. |
| `A4` | `IR[4]` | Bit 4 dell'opcode. |
| `A5` | `IR[5]` | Bit 5 dell'opcode. |
| `A6` | `IR[6]` | Bit 6 dell'opcode. |
| `A7` | `IR[7]` | Bit piu significativo dell'opcode. |
| `A8` | `C` | Flag Carry/Borrow. |
| `A9` | `Z` | Flag Zero. |
| `A10` | `N` | Flag Negative. |
| `A11` | `O` | Flag Overflow. |
| `A12` | `BOOT_RUN` | Seleziona il banco boot (`0`) oppure run (`1`). |

| EEPROM | Uscite dati |
| --- | --- |
| Control ROM 0 | `ADDR_SEL_0`, `ADDR_SEL_1`, `PC_INC`, `MDR_WE`, `MDR_OE`, `RAM_WE`, `EPROM_OE`, `NEXT_FETCH` |
| Control ROM 1 | `IR_WE`, `PC_LOAD`, `MAR_L_WE`, `RF_EN`, `RF_RW`, `RA_EN`, `RA_RB_RW`, `RB_EN` |
| Control ROM 2 | `ALU_EN`, `FLAGS_WE`, `MAR_H_WE`, `RAM_OE`, `IDX_L_WE`, `IDX_H_WE`, `SYS_STEP_n`, una uscita riservata |

Il cablaggio riportato nel video 25 collega direttamente `IR[7:3]` alle cinque
linee `A3..A7`; `IR[2:0]` seleziona il registro generale e `IR[3:0]` raggiunge
il decoder ALU. Non e presente una EEPROM di dispatch nello schema mostrato.

> La ISA corrente assegna a `SUB`, `CMP` e a ciascun salto un gruppo distinto
> di `IR[7:3]`. Le tre Control ROM possono quindi produrre le sequenze e le
> condizioni sui flag senza una ROM di dispatch. L'immagine di dispatch che
> il tool genera resta **opzionale** e non va collegata nello schema attuale.
> I vecchi binari con `SUB=0x68` o `JZ..JO=0xA1..0xA7` vanno riassemblati.

> Il banco BOOT e definito: ROM 0 contiene tutti i segnali del trasferimento
> `EPROM[PC] -> bus dati -> RAM[PC]` in T1, seguito da disattivazione di `/WE_RAM`
> e incremento PC in T2 (EPROM resta abilitata), quindi
> reset del microstep in T3 con EPROM ancora abilitata. Il passaggio a RUN e il reset finale di PC
> restano azioni hardware esterne al microcodice.

Posizione e polarita elettrica delle uscite si configurano in
[`tools/cu-bytecode/config/control_signals.c`](../tools/cu-bytecode/config/control_signals.c).

## Reset all'accensione (schema proposto, da verificare sulla CPU)

Il reset iniziale **non puo essere affidato alla Control ROM**: prima che
alimentazione e indirizzi siano stabili, anche le sue uscite sono indeterminate.
Serve un generatore esterno di power-on reset a 5 V con uscita attiva bassa
`/POR`. Per tenere il reset attivo finche l'alimentazione non e stabile,
un supervisore di tensione come l'MCP809, nella
variante adatta alla soglia di alimentazione scelta, e una soluzione possibile.
Verificare piedinatura e soglia della **variante effettivamente acquistata**.

Se si vogliono usare solo componenti discreti e porte logiche, una soluzione
pratica per un'alimentazione a 5 V che sale rapidamente e un **74HC14**
(inverter con ingresso Schmitt). Valori di partenza per il chip disponibile
sulla CPU: `R = 47 kohm`, `C = 4,7 µF`.

```text
+5 V ── 47 kohm ──o────────→ 74HC14 pin 1 (ingresso inverter 1)
                   ├── 4,7 µF ── GND
                   └── 1 kohm ── pulsante NO ── GND

74HC14 pin 2 ─────────────────────────→ pin 3 (ingresso inverter 2)
74HC14 pin 4 ─────────────────────────→ /POR
74HC14 pin 14 = +5 V; pin 7 = GND; 100 nF fra pin 14 e 7.
```

Se il condensatore e elettrolitico, il positivo va al nodo `o` e il negativo
a GND. All'accensione il nodo e inizialmente basso, quindi pin 4 (`/POR`) e
basso. Il condensatore si carica attraverso la resistenza; oltre la soglia
dell'ingresso Schmitt, pin 4 passa alto e rilascia il reset. Con questi valori
il ritardo atteso e nell'ordine di qualche decimo di secondo, ma non e
preciso: dipende dalla salita dei 5 V, dalla tolleranza e perdita del
condensatore e dalle soglie effettive del 74HC14. Prima di collegare i
contatori, misurare che `/POR` resti basso all'accensione e diventi alto
**una sola volta**. Un diodo di scarica in parallelo alla resistenza, con
anodo verso il nodo `o` e catodo verso i +5 V (per esempio `1N4148` con
`330 ohm` in serie per limitare la corrente), aiuta anche dopo spegnimenti
molto brevi.

Il pulsante **normalmente aperto** (NO) aggiunge il reset manuale: premendolo,
il condensatore si scarica verso GND attraverso `1 kohm`, il pin 1 scende a
zero e il pin 4 (`/POR`) torna basso. Rilasciandolo, il condensatore si
ricarica tramite `47 kohm` e il reset si disattiva dopo il normale ritardo.
La resistenza da `1 kohm` limita la corrente di scarica del condensatore.
Non collegare il pulsante direttamente al pin 4, che e un'uscita push-pull.
Per evitare ambiguita, la linea `/POR` qui indica sia il reset automatico sia
quello manuale; non cambia lo stato di `BOOT_RUN`.

Se invece si usa un **74LS14**, che ha una corrente d'ingresso molto maggiore,
i valori di partenza diventano `R = 1 kohm` e `C = 100 µF`: non scambiare i
valori delle due famiglie senza una nuova verifica.

Questo RC **non monitora la tensione** come un supervisore: con un'alimentazione
che sale lentamente o con cadute dei 5 V non garantisce un reset affidabile.
Non usare un normale inverter privo di ingresso Schmitt direttamente sul nodo
RC, perche la transizione lenta puo provocare commutazioni multiple.

Per il contatore 74161 del microstep, usare il caricamento **sincrono** a zero:

```text
/CLR_PC[0..3] = /POR                 (tutti i 74161 del PC)
/CLR_µSTEP   = /POR
/LOAD_µSTEP  = NEXT_FETCH_n          (Control ROM 0, D7)
D,C,B,A del contatore µSTEP = 0,0,0,0

NEXT_FETCH_n = Control ROM 0, D7 (attivo basso)
```

Con `/POR=0`, PC e microstep sono forzati a zero. Dopo il rilascio di `/POR`,
`NEXT_FETCH_n=0` carica `0000` nel **solo** contatore microstep al successivo
fronte di salita del clock. Il segnale resta attivo per l'intera fase di reset;
non si autoestingue in modo asincrono. Tenere `/POR` sul `/CLR` asincrono,
separato da D7 della EEPROM: sono due uscite che non vanno unite direttamente.
`NEXT_FETCH_n` non deve resettare il PC, altrimenti il BOOT ripartirebbe da
indirizzo zero a ogni byte.

Se la scheda attuale collega D7 a `/CLR_µSTEP` tramite una porta AND con
`/POR`, la nuova sequenza RUN dedica comunque un microstep al solo reset:
la scrittura RAM e gli aggiornamenti dei registri terminano prima che D7
scenda a zero. Questa separazione **non garantisce** pero la durata del
reset asincrono autoestinguente ne l'assenza di glitch della EEPROM; per la
prova RUN finale resta raccomandato il collegamento a `/LOAD` sopra. Prima
di riprogrammare la ROM0 fisica, verificare quale cablaggio e presente.

### Arresto HLT esterno alla CU

`HLT=0x00` e `NOP=0x01` hanno entrambi `IR[7:3]=00000`. Control ROM 2
usa ora `D6` (pin DIP-28 **16**) per `SYS_STEP_n`, attivo basso:
`D6=0` solo se `BOOT_RUN=1`, `µSTEP[2:0]=001` (T2) e
`IR[7:3]=00000`. In tutti gli altri indirizzi, inclusi BOOT e T1, `D6=1`.
Le linee `IR[2:0]` restano esterne alle EEPROM. Per HLT basta una OR:

```text
µSTEP_EN = SYS_STEP_n OR IR2 OR IR1 OR IR0
```

Il risultato vale `0` solo per `HLT=0x00` in RUN/T2; collegarlo a una
**abilitazione al conteggio** del 74161 microstep (l'altra abilitazione
deve restare alta se non ha un'altra funzione). Non tagliare il clock.
`001` e T2 sui bit logici del contatore; sui pin EEPROM equivale a
`A2:A1:A0=100` con la mappatura attuale. In T2 le altre uscite CU sono
inattive e IR resta `0x00`, quindi il contatore resta fermo. Per NOP
(`IR[2:0]=001`) la OR vale `1` e il contatore raggiunge T3.
Se l'abilitazione del contatore e gia condizionata da altra logica,
combinare il risultato senza scavalcare tale condizione.

**Prima di collegare D6**, programmare e verificare la nuova immagine
`microcode-rom2.bin`: il precedente bit riservato non aveva un livello
garantito. Misurare D6 alto durante T1/BOOT e basso in RUN/T2 per il gruppo
di sistema; usare un clock che rispetti i tempi di propagazione della EEPROM
e di setup dell'ingresso enable del contatore.

Durante `/POR=0` va inoltre impedita la scrittura della RAM. Poiche T1 del
BOOT ha `/WE_RAM` attivo basso, aggiungere l'inibizione al circuito OR che
gia combina D5 con i bit alti del PC:

```text
H = PC15 OR PC14 OR PC13
/WE_RAM_fisico = ROM0_D5 OR H OR NOT(/POR)   (durante BOOT)
```

Quando `/POR=0`, `NOT(/POR)=1` e `/WE_RAM_fisico` resta alto; quando `/POR=1`,
la logica di scrittura torna quella normale. Usare un inverter e una porta OR
aggiuntiva (o una rete logicamente equivalente), non un collegamento diretto
di `/POR` al pin `/WE` della RAM. Tenere fermo anche il clock durante il reset
e consentire il primo fronte solo dopo il rilascio di `/POR` e l'assestamento
dei segnali. L'espressione con `PC15..PC13` descrive la protezione di BOOT;
in RUN la selezione RAM/VRAM deve usare l'indirizzo realmente presente sul bus.

Riferimenti hardware: [datasheet 74161/74LS161A di Texas Instruments](https://www.ti.com/lit/ds/symlink/sn74ls161a.pdf)
e [datasheet MCP809 di Microchip](https://ww1.microchip.com/downloads/en/devicedoc/11194c.pdf).
Per la variante RC: [datasheet 74HC14 di Texas Instruments](https://www.ti.com/lit/ds/symlink/sn74hc14.pdf)
e [datasheet 74LS14](https://www.ti.com/lit/ds/symlink/sn74ls14.pdf).

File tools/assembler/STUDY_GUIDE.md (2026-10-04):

# Guida allo studio dell'assembler

Questa guida serve a chi vuole capire il progetto dell'assembler partendo da zero.

L'assembler e un programma scritto in C che dovra leggere un file assembly, riconoscere le istruzioni della CPU a 8 bit e generare i byte macchina da caricare in ROM/EEPROM.

## Idea generale

Un programma assembly e testo leggibile:

```asm
LDI R0, 0x0A
HLT
```

L'assembler deve trasformarlo in byte:

```text
0x20 0x0A 0x00
```

Il lavoro dell'assembler puo essere diviso in passaggi:

1. Leggere il file `.asm`.
2. Leggere una riga alla volta.
3. Rimuovere commenti e spazi inutili.
4. Separare mnemonic e operandi.
5. Cercare il mnemonic nella tabella ISA.
6. Calcolare opcode e byte aggiuntivi.
7. Scrivere gli output finali.

## Da dove iniziare

L'ordine consigliato di lettura e:

1. `src/main.c`
2. `include/assembler.h`
3. `src/assembler.c`
4. `include/parser.h` e `src/parser.c`
5. `include/isa.h` e `src/isa.c`
6. `include/output.h` e `src/output.c`
7. `include/errors.h` e `src/errors.c`

## `src/main.c`

Questo e il punto di ingresso del programma.

Contiene la funzione:

```c
int main(int argc, char **argv)
```

Il suo compito e:

- leggere gli argomenti da terminale;
- controllare che siano corretti;
- preparare le opzioni dell'assembler;
- chiamare la funzione che assembla il file;
- chiamare la funzione che scrive gli output.

Il `main` non deve conoscere i dettagli della ISA o del formato `.bin`. Deve solo coordinare gli altri moduli.

## `include/assembler.h`

Questo file definisce le strutture principali dell'assembler.

La struttura piu importante e:

```c
typedef struct {
    uint8_t bytes[CPU8_MAX_PROGRAM_BYTES];
    size_t length;
} Cpu8Program;
```

`bytes` contiene il programma compilato in byte macchina.

`length` indica quanti byte sono stati generati davvero.

## `src/assembler.c`

Questo file contiene il cuore dell'assembler.

La versione attuale:

- aprire il file assembly;
- leggere tutte le righe;
- riconoscere label e direttive;
- usare la tabella ISA per generare gli opcode;
- riempire `Cpu8Program`.

Usa due passate:

1. La prima calcola indirizzi, label e costanti.
2. La seconda genera davvero i byte macchina.

## `include/parser.h` e `src/parser.c`

Il parser e il modulo che legge e interpreta il testo assembly.

Per ora contiene la lettura sicura di una riga:

```c
Cpu8Status cpu8_read_source_line(void *file, Cpu8SourceLine *line, int *has_line);
```

Il riconoscimento di mnemonic, operandi e direttive e implementato in `src/assembler.c`.

Esempi supportati:

```asm
LDI R0, 0x2A
MOV RA, R0
JMP 0x0100
```

e trasformarle in una forma piu facile da usare dal resto del programma.

## `include/isa.h` e `src/isa.c`

La ISA descrive le istruzioni disponibili.

Il file `src/isa.c` contiene una tabella che collega un mnemonic a un opcode:

```c
{"HLT", 0x00, 0xFF, CPU8_FORMAT_IMP, false}
{"NOP", 0x01, 0xFF, CPU8_FORMAT_IMP, false}
```

Il significato dei campi e:

- `mnemonic`: nome dell'istruzione scritta in assembly;
- `opcode_base`: valore base dell'opcode;
- `opcode_mask`: bit fissi dell'opcode;
- `format`: formato dell'istruzione;
- `uses_register`: indica se l'opcode contiene anche il codice di un registro.

Questa tabella deve restare allineata a `docs/isa.md`, che e il documento di riferimento per semantica e opcode. Le regole lessicali, le label e le direttive sono invece definite in `docs/assembly-language.md`.

## `include/output.h` e `src/output.c`

Il modulo output scrivera i file generati dall'assembler.

I formati previsti sono:

- `.bin`: byte raw da caricare in ROM/EEPROM;
- `.hex`: vista leggibile per controllare gli opcode;
- `.bits`: vista binaria testuale per controllare i bit `D7`...`D0`;
- `.h`: array C/C++ da usare in Arduino IDE.

La versione attuale scrive tutti e quattro i formati.

## `include/errors.h` e `src/errors.c`

Questi file gestiscono gli errori.

In C una funzione non puo lanciare eccezioni come in altri linguaggi. Per questo molte funzioni restituiscono un valore di tipo:

```c
Cpu8Status
```

Esempi:

```c
CPU8_OK
CPU8_ERROR_INVALID_ARGUMENT
CPU8_ERROR_IO
CPU8_ERROR_PARSE
CPU8_ERROR_ASSEMBLE
```

`cpu8_status_message` converte questi codici in messaggi leggibili.

La versione attuale mantiene anche un dettaglio testuale dell'ultimo errore, per esempio:

```text
line 2: invalid MOV form; use MOV RA, Rn, MOV RB, Rn or MOV Rn, RA
```

Questo rende piu semplice capire dove correggere il file assembly.

## Concetti C da conoscere

Per studiare questo progetto conviene conoscere:

- `main`, `argc`, `argv`;
- puntatori;
- `struct`;
- `enum`;
- array;
- stringhe C terminate da `'\0'`;
- file con `FILE`, `fopen`, `fgets`, `fclose`;
- header `.h` e implementazioni `.c`;
- compilazione con `make`.

## Stato attuale

Il progetto assembler ha una prima versione funzionante.

Supporta:

- `.code` con indirizzo esplicito oppure default `0x0000`;
- `.data` con indirizzo esplicito oppure collocazione automatica;
- `.byte`;
- `.equ`;
- label;
- numeri decimali, esadecimali e binari;
- istruzioni principali della ISA v0.1.

Le prossime parti da implementare saranno:

1. controllo piu dettagliato dei casi limite;
2. ulteriori test automatici per ogni istruzione della ISA;
3. messaggi di errore ancora piu specifici per token e operandi;
4. eventuali estensioni future della ISA.

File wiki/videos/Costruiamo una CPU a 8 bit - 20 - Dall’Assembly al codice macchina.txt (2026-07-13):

Bentornati sul mio canale YouTube. Per
chi non mi conosce, io sono Enzo. Oggi
continuiamo a parlare della CPU 8 bit e
vediamo come prendere un programma
assembly e convertirlo in un codice
binario che può essere eseguito dalla
nostra CPU. Ma prima di iniziare vi
ricordo di lasciare un mi piace,
commentare questo video e iscrivervi al
mio canale per supportare il mio lavoro.
Nello scorso video ci siamo lasciati con
l'istruction set architecture della CPU.
Abbiamo detto che comunque sono tutte le
operazioni, tutti i codici che poi si
traducono in istruzioni, operazioni che
la nostra CPU riesce ad eseguire. Ora,
ehm, a ricord di logica, dato che la CPU
riesce a leggere soltanto dei dei bit,
quindi una serie di 0 e 1, noi dovremmo
scrivere un programma con questo codice
binario e poi lo dovremmo dare impasto
alla CPU per l'esecuzione vera e
propria. Il problema è che
effettivamente andare a scrivere 0 e 1
per per una mente umana è un po'
complicato. Per questo motivo esistono
dei linguaggi come l'assembly che,
diciamo, è un linguaggio di
programmazione a basso livello, il più
basso livello possibile.
Si correla molto a come effettivamente è
costruito l'hardware che ci permette di
tradurre tutto in delle label, comunque
delle etichette, scrivere un programma
in maniera più agile e comprensibile per
un uomo e poi successivamente eh queste
etichette vengono tradotte in codice
binario, in codice macchina. che può
eseguire la CPU, perché in effetti la
CPU non riesce a leggere dei file
assembly, ma bisogna passare da un
programma chiamato assemblatore o
assembler che va a prendere questo file
che di fatto è un file di testo, lo
prende, lo traduce in
byte code in codice macchina e a quel
punto apriamo tutta una serie di bit,
quindi 0 e 1 che possono essere compresi
dalla CPU e che può facilmente seguire
la nostra CPU. In questo video proviamo
a vedere tutto il processo che ci porta
da un programma assembly a un codice
macchina che è pronto ad essere eseguito
dalla nostra CPU. Poi questo codice
macchina verrà inserito all'interno
della della eprom e poi da lì partirà
tutto il flusso, tutto il giro che
caricherà il codice all'interno della
RAM e poi l'esecuzione vera e propria
della nostra CPU.
Quindi, se vogliamo riassumere, diciamo
che l'ISA è ciò che la CPU comprende, il
linguaggio assembly è ciò che un
programmatore riesce a scrivere e poi
abbiamo l'assembler che traduce eh
effettivamente il codice scritto dal
programmatore in una serie di byte che
possono essere letti dalla nostra CPU.
Per quanto riguarda tutta la parte di
software correlata al progetto, ho
creato questo repository dove ho
inserito tutta una serie di eh file di
testo che vediamo qui sotto sotto Viki
video che sono la trascrizione
di tutti i video fatti finora,
realizzati finora, quindi diciamo che
sono i sottotitoli che genera in
automatico YouTube. Li ho presi e li ho
inseriti in questi file. Perché ho fatto
questo? Diciamo che la maggior parte del
codice che vedremo all'interno di questo
repository è generata da intelligenza
artificiale, ho utilizzato Codex. Quindi
per dare un po' di contesto all'AI ho
creato tutta questa serie di di
documenti testuali. Una volta fatto
questo, sempre tramite lei, ho creato
questa serie di articoli.
Sono dei file markdown generati dall'AI.
vi possiamo vedere come una sorta di
blog a puntate
in cui c'è una descrizione di tutti di
tutti i video, di tutto il lavoro fatto
finora. Potrebbe essere una buona base
di partenza per fare delle future
pubblicazioni in un blog. Ovviamente
vanno rivisti, corretti ed integrati con
eventuali immagini, schemi e
quant'altro.
Una volta fatto tutto questo lavoro con
l'AI, ho generato una serie di documenti
sempre in formato markdown. Uno è
relativo all'ISA, è questo documento
qui.
Diciamo che dopo che ho dato tutto
questo contesto all AI gli ho chiesto di
generare un estruction set architecture
per la CPU, ma ha generato una prima
versione che in realtà era abbastanza
generica e non era proprio correlata al
nostro caso d'uso specifico, non
rispecchiava le caratteristiche hardware
del nostro progetto. Quindi m ho chiesto
alle AI di fare una serie di modifiche.
Eh, m'ha creato una seconda versione già
più corretta, più in linea guida con il
nostro hardware. Ho corretto poi le
varie sezioni, le varie i vari pezzi che
non mi piacevano e sono arrivato a
questo documento.
Di fatto è questo qua è una sorta di
documento che va a descrivere tutto
l'ISA. Noi abbiamo visto nel video
precedente degli estratti di questo
documento. Mh, ad esempio, ho preso
tutte le varie tabelle da questo file MD
e diciamo descrivere in maniera un po'
più dettagliata e testuale
tutto quello che abbiamo visto nel video
precedente. Vi invito a leggerla se
siete interessati perché comunque vi dà
un po' più di dettaglio a livello
tecnico,
cosa che può essere sempre utile. Una
volta scritto l'ISA.md, sono passato a
un altro documento di specifica che è
assemblyelilanglanguage. MD, un altro
file di testo markdown che va a
descrivere il funzionamento e la
struttura di un programma assembly per
la nostra CPU. Quindi qua dentro abbiamo
tutte abbiamo tutta la parte di base su
come su come strutturare un programma
assembler assembly. Parte ovviamente da
da ciò che è stato dato per scontato
come presupposto sull'ISA.
Abbiamo, diciamo, tutta questa serie di
esempi per ogni singola istruzione, come
definire le label, i sistemi
numerici su cui andiamo a descrivere un
un valore numerico, quindi binario,
esadimale,
eh, e così via.
Una volta che avevamo ho fatto definire
allei tutta questa parte, quindi questa
parte documentale,
eh ho fatto scrivere sempre a una serie
di file, d' esempio assembly sono una
sorta di demo, di programmi demo, sono
sotto questa cartella, questa directory
e qui abbiamo un primo codice demo.
è tutto commentato in modo che il target
resta quello didattico, quindi leggendo
un po' i commenti possiamo capire un po'
come funziona tutto.
Fatto ciò, ho scritto ho fatto scrivere
alle AI il nostro assemblatore, quindi
il programma in C, che andrà a prendere
questi file ASM e li convertirà in del
codice binario. troviamo il progetto
dentro Tools Assembler e qui dentro
abbiamo questo progetto che è un
progetto in C, un classico progetto in
C. Abbiamo questo file MD
che eh va a descrivere il funzionalità,
va a dare un po' una guida per chi vuole
studiare comeè fatto questo codice. Va a
dare un po' una linea guida dove partire
con la lettura dei file sorgenti, la
struttura del progetto
e così via.
Ovviamente ora poi vediamo anche durante
il corso del video un po' tutti i
singoli file sorgente per vedere
effettivamente cosa fanno, però diciamo
non entrerò troppo nel dettaglio. In
ogni caso tutto il software, tutti i
file sorgenti sono stati commentati in
italiano, quindi possono essere letti
seguendo anche un po' questo file MD,
dovreste anche riuscire ad accarezzarvi
e approfondire
approfondire il tutto. Poi ci sono tutta
una serie di altri sottoprogetti che
vedremo un po' nei prossimi video. Nel
prossimo video, ad esempio, vedremo
questa parte EPROM Programmer che sono
dei
dei software che ci permettono di
programmare la IPROM, quindi è lo step
successivo. Prendo il file sorgente
assembly, lo assemblo, prendo i file
binari generati, li metto all'interno eh
di questo progetto AT28C64
M, che è un progetto fatto per Arduino,
eh mi va a generare mi va a scrivere
all'interno della IPROM effettivamente
il programma che ho costruito, però
questa parte la vediamo in un prossimo
video. L'intero repository lo metto
all'interno del Gitup e vi metto il link
in descrizione a questo video, così
comunque potete andarvi a recuperare
tutta questa parte di codice.
Io direi a questo punto di analizzare un
primo programma demo in assembly e
vedere effettivamente com'è costituito.
Troviamo questo esempio all'interno di
example assembly demo.sm.
Qui vediamo questo primo programma, già
vediamo la sintassi. Questi punti e
virgola vanno a rappresentare dei
commenti. In effetti tutta queste
stringhe che vedete in verde è solo del
testo che poi quando andremo a
assemblare il programma l'assemblatore
ignorerà, quindi è come se non ci
fossero,
però ci danno una mano e ci semplificano
la lettura di un di un programma.
Alla 27 troviamo già la prima parte di
codice che poi effettivamente viene
gestita dal nostro assemblatore.
Questa sintassi punto equ inizial value
con questo valore eh non è altro che la
definizione di una costante. In pratica
che cosa stiamo facendo? Stiamo dicendo
al nostro assemblatore, guarda che
quando andrò all'interno del mio
programma a scrivere questa etichetta
inizial value, tu devi sostituirla con
questo valore. Questo valore espresso in
esadecimale è il valore 10.
In esadecimale lo capiamo perché inizia
con 0x. Se utilizzavo ad esempio eh 0 B
e poi scrivo il valore binario, stavo
definendo lo stesso numero in binario.
Se invece scrivo 10 in questo modo, lo
sto definendo direttamente in sistema
decimale. Però comunque solitamente
quando si scrive del software in
assembly si utilizza molto spesso la
codifica esadecimale.
Invece andando avanti, questi sono altri
commenti. Sulla linea 36 abbiamo questo
blocco punto code con un indirizzo. Che
cosa a che cosa serve? Questo in pratica
indica all'assemblatore che questa è da
qui in poi inizia tutta la parte di
codice. Ricordo che siamo sotto
un'architettura di One Newman, quindi
all'interno della stessa memoria
convivono sia la parte di codice che la
parte data.
In effetti, se poi vado a scendere, vado
in fondo al nostro programma assembly,
vedo quest'altra etichetta punto data
che dice all'assemblatore, guarda, da
qui in poi inizia tutta la parte data.
Quindi è come se vado a fisicamente a
suddividere la memoria in questi due
blocchi.
Torniamo torniamo sopra.
Code. Questo è un indirizzo, è un
indirizzo di memoria. Sto dicendo
all'assemblatore, guarda che la parte di
codice inizia da questo indirizzo. In
realtà, se io eh vado a cancellare
questo questo valore, l'indirizzo, in
automatico l'assemblatore farà partire
il blocco code da zero e in automatico
poi andrà a calcolarsi tutte eh le altre
istruzioni, tutti gli indirizzi delle
altre istruzioni.
Rimettiamo tutto com'era. Qui vediamo la
vera la prima vera e propria istruzione
assembly che poi andrà a tradursi
all'interno di un valore binario di un
byte code. Abbiamo questa istruzione LR0
inizial value che cosa fa? Stiamo
caricando all'interno del registro R0 il
valore iniziale, quindi mh questa
costante.
Poi già l'ho detto, ma comunque
l'assemblatore prenderà questo valore,
lo cancellerà e lo sostituirà in tutte
le varie parti con eh 0x0a.
In effetti, se io qua scrivo 0x0a
o scrivo inal, il codice binario del
generato sarà sempre lo stesso, quindi
per la CPU non cambierà niente. Diciamo
che tutta questa serie di di istruzioni,
definire costanti e così via, aiutano lo
sviluppatore, il programmatore a
costruire un programma che sia più
facile da leggere.
Riportiamo tutto com'era.
Nella linea 46 invece stiamo prendendo
il valore contenuto all'interno del
registro R0 che avevamo precedentemente
inizializzato e lo stiamo mettendo
all'interno della variabile counter. La
variabile counter è definita sotto,
ovviamente nel blocco data perché è una
variabile è definita qui. Abbiamo la
label counter. Stiamo dicendo che ehm
una variabile da 1 byte, quindi 8 bit e
gli stiamo assegnando questo valore
iniziale.
Ovviamente la nostra CPU è 8 bit, per
ora prevediamo soltanto di gestire
variabili da 8 bit, quindi 1 byte.
Torniamo su. Questa qua invece questa
istruzione invece carica all'interno del
registro R1 ciò che è memorizzato
all'interno della variabile counter.
Successivamente abbiamo questa
istruzione che ferma la CPU e in pratica
ci va a dire a noi, guarda qua finisce
il blocco data, fermati perché se io non
metto questalt la il proprio encounter
verrebbe incrementato e andremo nella
sezione data. La sezione data contiene
eh dei dati, però ovviamente la CPU non
sa che contiene dei dati e andrebbe a
leggere questo indirizzo come se fosse
un'istruzione, quindi avere problemi
durante l'esecuzione poi della del
programma vero e proprio.
Qui abbiamo data, al solito, eh qua
stiamo dicendo da qua in poi inizia il
blocco data, non stiamo mettendo nessun
indirizzo, quindi sarà l'assemblatore
stesso a calcolare quando inizia il
blocco data all'interno della memoria,
però potevamo anche inserire un
indirizzo se volevamo noi specificare
quale indirizzo utilizzare per un blocco
rispetto a un altro. Questa è la
dichiarazione della variabile, l'abbiamo
vista l'abbiamo vista in precedenza e
poi in realtà il nostro programma
finisce perché poi il resto sono
commenti, però da notare questo commento
che va a descrivere ciò che succede poi,
come viene mappata la memoria realmente.
Ciò che ci aspettiamo dalla
compilazione, dall'assemblamento di
questo programma. Quando viene
assemblato questo programma, io mi
aspetto che venga divisa la memoria in
questi due blocchi. Questo è il blocco
code dove abbiamo le nostre varie
istruzioni
e poi abbiamo il blocco data che
contiene eh counter, la nostra variabile
counter.
Quindi abbiamo visto il file demo.sm
all'interno di questa cartella example
assembly abbiamo tutta una serie di
esempi che vanno dal 01 che è il più
semplice fino a andare a esempi un po'
più complessi. L'ultimo contiene salti
condizionali.
A questo punto io direi di provare a
assemblare questo file demo SM e vedere
effettivamente cosa esce fuori, il
binario che ne esce fuori. Per fare ciò
ci dobbiamo spostare sotto la cartella
Tools Assembler. Qui abbiamo il nostro
programma in Che è l'assemblatore.
C'ho questa directory build con questo
file CPU8 SMM che è un eseguibile.
Quindi se io ranno questo file lancio il
mio assemblatore. Però mettiamo il caso
che io scarico il progetto da zero, non
avrò questa cartella build, quindi la
vado a eliminare e eh devo compilarmi
questo progetto per ottenere
l'eseguibile. Esiste questo file Mac
file che contiene tutte le regole per
compilare da sorgenti questo programma.
Facciamo così, apro un nuovo terminale,
mi sposto dentro la directory CD Tools
Assembly Assembler e lancio il comando
make. Il comando make lancia la
compilazione. Vengono creati tutta
questa serie di file oggetto partendo
dai file punto C. Poi vengono linkati e
ottengo questo eseguibile. Se io provo
ad esempio a lanciare ora questo
eseguibile,
quindi sono sotto build CP+ 8 SMM,
parte l'eseguibile m in realtà mi dà un
errore. L'errore è perché manca input il
file SM, ti dà un suggerimento sulla
sintassi e ti dice di inserire un file
SM in input e specificare qual è la
directory di output per i file
m buildati,
quindi per i file assemblati.
Proviamo. Siamo sempre nella nella root.
Provo a dare
tools
assembly
e poi do build C+8 SMM
e poi da qua vado a dargli impasto il
mio programma a demo. Quindi vado su
example assemblydemo.sm
o per dire qual è la directory di
output.
Come directory do TMP
demo.
Ok. Eh, m'ha generato effettivamente i
binari. Sono sotto TMP e vedo questa
serie di file cosa sono. Allora,
demo.bbin è un file binario che comunque
l'editor non riesce neanche ad aprire.
potrei aprirlo come esadecimale, come
lettore,
leggerlo in modalità esadecimale editor,
vedo qualcosa, comunque ci capiamo ben
poco, è un file binario.
Poi abbiamo questo demo bits.bits bitz
in cui abbiamo gli indirizzi espressi in
codice decimale, il corrispettivo file
binario,
cioè il contenuto dell'indirizzo, quindi
abbiamo il codice binario e il
corrispettivo in esadecimale.
Poi abbiamo questo demo.
In realtà questo è stato pensato un po'
per essere utilizzato all'interno di
microcontrollori come Arduino che
potremmo utilizzare per freshare una
eprom. comunque un file in C in cui
abbiamo eh questo array CPU8 program che
è un array che contiene tutti i codici
esadecciali
della memoria che dovranno poi essere
inserite all'interno della eprom e poi
infine abbiamo questo demo.ex
Eh, quindi demo punto esadecimale
dovrebbe stare in cui abbiamo gli
indirizzi sempre espressi in codice e
poi accanto abbiamo il corrispettivo in
esate decimale a 8 bit. In effetti sono
due cifre che ne sacciale vanno a dare 8
bit di informazione. Se io prendo questo
e prendo quest'altro demo.bits che metto
a fianco, noto subito che il codice
decimale praticamente è lo stesso. Ok,
ignoriamo 0x che semplicemente ci sta
dando la codifica esadecimale. Abbiamo
anche il corrispettivo in binario. Io ho
detto al di creare questo file a Codex
quando ha generato questo codice, in
modo da poter avere un banco di prova
per confrontare effettivamente l'output
con l'ISA, in modo che vado a vedere se
effettivamente il programma assemblato
corrisponde al all l'ISAL OPT Code che
mi aspettavo, quindi per fare una serie
di confronti
Ora, nel prossimo step dobbiamo capire
effettivamente, lo faremo in un prossimo
video, quale di questi file utilizzare e
come introdurli, scriverli all'interno
nella nostra eprom.
L'ultima cosa che dobbiamo vedere in
questo video è la struttura generale del
programma assembler, come è stato
scritto. Abbiamo questi due queste due
cartelle principali, include ed src.
Dentro include abbiamo tutti i file di
intestazione punh dove abbiamo
solitamente i type e tutte le varie
funzioni che poi sono implementate
all'interno dei file C veri e propri.
Come tutti i programmi l'enter point
d'ingresso è il main.cc.
Eh, qui dentro che cosa abbiamo? Abbiamo
il main che va a prendermi gli argomenti
che passiamo dalla console, dalla Cli e
va a fare un pass sugli argomenti, va a
selezion a capire un pochettino cosa
mandiamo in input e poi lo passa agli
step successivi.
Poi abbiamo questo file parser.hhh che
fa appunto il pars delle varie
istruzioni che ci sono all'interno del
programma assembly.
Quindi abbiamo pars.h e poi pars.cc
parser.cc.
Poi eh abbiamo
assembler. C e punto H. M. Qui abbiamo
al solito le definizioni,
qui l'implementazione, qua vengono fatti
anche tutti i vari calcoli eh per
calcolare i vari indirizzi.
error.c gestisce tutti i vari errori di
sintassi quando incappa un errore di
sintassi all'interno del file assembly
e poi secondo me abbiamo output.cc che
invece
va a gestire la scrittura dei vari file
binari che abbiamo visto che abbiamo
appena abbiamo appena visto. E infine
secondo me il file più importante sono
questo ISA. ISA.
Eh, qui dentro c'è effettivamente la
tabella di conversione tra il codice
che utilizziamo all'interno del
programma assembly, quindi un codice
memonico, eh facile da ricordare con il
codice se decimale che poi eh verrà
utilizzato all'interno della della
IPROM, quindi il codice decimale
effettivo. Quindi qua viene
effettivamente fatta la conversione
verso il formato ISA che poi andrà a
leggere la CPU. Ma poi per il resto è
tutto abbastanza commentato, quindi
facilmente leggibile. È un programma
abbastanza basilare
e diciamo che è un po' tutto. Abbiamo
anche una suite di test. nei test
abbiamo tutta una serie di eh programmi
assembly e vengono viene fatto un
confronto lanciando poi l'assemblatore
dando input questi programmi e
confrontando effettivamente cosa
otteniamo in output. Quindi dovremmo
avere degli output attesi. Vediamo se
effettivamente vengono rispettati.
Quindi questa è una prima suit di test
abbastanza basilare, però comunque ci
possono aiutare e dare dire a colpo
d'occhio se c'è qualche problema
all'interno del del codice sorgente.
Io direi che per questo video è tutto.
Ci sentiamo in un prossimo video. Vi
ricordo di lasciare un mi piace,
commentare questo video e iscrivervi al
mio canale per supportare il mio lavoro.
Un saluto.

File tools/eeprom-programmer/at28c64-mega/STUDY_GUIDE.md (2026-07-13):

# Guida allo studio del programmatore AT28C64

Questa guida serve a chi vuole capire il progetto del programmatore EEPROM partendo da zero.

Il programmatore e uno sketch Arduino per Arduino Mega. Il suo compito e ricevere comandi dalla seriale e usarli per leggere o scrivere una EEPROM parallela AT28C64.

## Idea generale

La AT28C64 e una memoria parallela:

- 13 linee indirizzo selezionano una cella da `0x0000` a `0x1FFF`;
- 8 linee dati trasportano il byte letto o scritto;
- `CE`, `OE` e `WE` controllano quando il chip e attivo, quando mette dati sul bus e quando salva un byte.

Il programmatore fa questo lavoro:

1. Riceve una riga dal monitor seriale.
2. Capisce se e un comando manuale o una riga `.hex` prodotta da `cpu8asm`.
3. Se deve scrivere, imposta indirizzo e dati sui pin Arduino.
4. Genera l'impulso di scrittura su `WE`.
5. Aspetta un tempo fisso conservativo per il ciclo interno della EEPROM.
6. Rilegge il byte per verificarlo.
7. Stampa `OK` o un errore sulla seriale.

Esempio di riga accettata:

```text
0000: 20
```

Significa:

```text
indirizzo 0x0000 <- byte 0x20
```

## Da dove iniziare

L'ordine consigliato di lettura e:

1. `at28c64-mega.ino`
2. `include/ProgrammerConfig.h`
3. `include/EepromBus.h`
4. `src/EepromBus.cpp`
5. `include/SerialCommands.h`
6. `src/SerialCommands.cpp`
7. `README.md`
8. `docs/at28c64-arduino-mega-programmer.md`

## `at28c64-mega.ino`

Questo e il punto di ingresso dello sketch Arduino.

Contiene:

```cpp
void setup()
void loop()
```

`setup`:

- apre la seriale a `115200 baud`;
- inizializza il bus verso la EEPROM;
- stampa l'aiuto dei comandi.

`loop`:

- controlla continuamente se arrivano caratteri dalla seriale;
- delega il lavoro a `serialCommandsHandleInput`.

Questo file deve restare piccolo. Non deve conoscere i dettagli elettrici della EEPROM e non deve contenere il parser dei comandi.

## `include/ProgrammerConfig.h`

Questo file contiene la configurazione del programmatore.

Qui trovi:

- dimensione della EEPROM;
- baud rate seriale;
- dimensione del buffer di riga;
- pin Arduino collegati ad `A0`...`A12`;
- pin Arduino collegati a `I/O0`...`I/O7`;
- pin dei segnali `CE`, `OE`, `WE`;
- tempi usati per lettura, impulso di scrittura e attesa del ciclo interno.

Esempio:

```cpp
static const uint8_t PIN_WE = 45;
```

Se cambi cablaggio, questo e il primo file da modificare.

## `include/EepromBus.h`

Questo header espone le funzioni usate dal resto del programma per parlare con la EEPROM:

```cpp
void eepromBusBegin();
uint8_t eepromReadByte(uint16_t address);
void eepromWriteByte(uint16_t address, uint8_t value);
void eepromWriteByteProtected(uint16_t address, uint8_t value);
```

Il resto del codice non deve sapere come sono collegati i pin fisici. Deve solo poter chiedere:

- inizializza il bus;
- leggi un byte;
- scrivi un byte normale o con sequenza Software Data Protection.

## `src/EepromBus.cpp`

Questo file contiene la parte piu vicina all'hardware.

Le funzioni interne principali sono:

- `setAddress`: mette sui pin `A0`...`A12` il valore dell'indirizzo;
- `setDataBusInput`: mette i pin dati in lettura;
- `setDataBusOutput`: mette i pin dati in scrittura;
- `writeDataBus`: scrive un byte sui pin `I/O0`...`I/O7`;
- `readDataBus`: legge un byte dai pin `I/O0`...`I/O7`;
- `pulseWriteByte`: genera il ciclo elettrico di scrittura.

### Lettura

Per leggere dalla EEPROM:

```text
CE = 0
OE = 0
WE = 1
```

Arduino mette il bus dati in `INPUT`, imposta l'indirizzo, abilita la EEPROM e legge gli 8 bit.

### Scrittura

Per scrivere nella EEPROM:

```text
CE = 0
OE = 1
WE = impulso basso
```

Arduino mette il bus dati in `OUTPUT`, imposta indirizzo e byte, poi genera un breve impulso basso su `WE`.

La scrittura interna non e immediata. Per questo il codice aspetta un ritardo fisso conservativo e poi rilegge il byte per verificarlo.

## Attesa e verifica

La AT28C64B dichiara un ciclo di scrittura massimo di circa `10 ms`.
Per mantenere il programmatore semplice e leggibile, questa versione usa un'attesa fissa leggermente piu lunga.

L'idea semplificata e:

1. scrivo un byte;
2. aspetto il ciclo interno della EEPROM;
3. rileggo lo stesso indirizzo;
4. se il valore letto coincide con quello scritto, stampo `OK`.

Questa tecnica e piu lenta del data polling, ma e piu adatta a una prima versione didattica su breadboard.

## `include/SerialCommands.h`

Questo header espone il modulo che gestisce il protocollo seriale:

```cpp
void serialCommandsPrintHelp();
void serialCommandsHandleInput();
```

Il modulo seriale non deve conoscere i dettagli dei pin. Quando deve leggere o scrivere, chiama le funzioni pubbliche di `EepromBus`.

## `src/SerialCommands.cpp`

Questo file contiene il parser dei comandi seriali.

Supporta due famiglie di input.

### Formato `.hex` di `cpu8asm`

```text
0000: 20
0001: 0A
```

Questo formato e comodo per copiare direttamente l'output dell'assembler nel monitor seriale.

### Comandi manuali

```text
W 0000 20
R 0000
D 0000 0010
F 0000 00FF FF
HELP
```

Il parser fa questi passaggi:

1. accumula caratteri fino a newline;
2. rimuove spazi iniziali;
3. se trova `:`, interpreta la riga come formato `.hex`;
4. altrimenti legge il primo carattere come comando;
5. converte i numeri esadecimali;
6. valida indirizzo e byte;
7. chiama `EepromBus`;
8. stampa il risultato.

## Funzioni di supporto importanti

`parseHexValue` converte testo esadecimale in numero:

```text
00FF -> 255
0x00FF -> 255
```

`validateAddress` controlla che l'indirizzo sia nel range della AT28C64:

```text
0x0000 - 0x1FFF
```

`validateByte` controlla che il valore stia in 8 bit:

```text
0x00 - 0xFF
```

`commandWrite` scrive un byte e lo rilegge subito per verificare che la programmazione sia riuscita.

## Concetti Arduino/C++ da conoscere

Per studiare questo progetto conviene conoscere:

- `setup` e `loop`;
- `pinMode`;
- `digitalWrite`;
- `digitalRead`;
- `delayMicroseconds`;
- `millis`;
- `Serial.begin`;
- `Serial.available`;
- `Serial.read`;
- `Serial.print`;
- array;
- funzioni;
- header `.h` e implementazioni `.cpp`;
- costanti `static const`;
- tipi `uint8_t`, `uint16_t`, `uint32_t`;
- differenza tra pin in `INPUT` e pin in `OUTPUT`.

## Percorso pratico consigliato

1. Compila lo sketch senza EEPROM collegata.
2. Leggi `ProgrammerConfig.h` e confronta ogni pin con il cablaggio reale.
3. Collega solo alimentazione e segnali principali della EEPROM.
4. Prova un comando di lettura:

```text
R 0000
```

5. Scrivi un byte:

```text
W 0000 AA
```

6. Rileggilo:

```text
R 0000
```

7. Prova un dump:

```text
D 0000 0010
```

8. Solo dopo questi test invia un file `.hex` generato da `cpu8asm`.

## Stato attuale

Il programmatore ha una prima versione funzionante.

Supporta:

- scrittura byte singolo;
- lettura byte singolo;
- dump di un intervallo;
- fill di un intervallo;
- formato `.hex` prodotto da `cpu8asm`;
- verifica immediata dopo ogni scrittura;
- attesa fissa dopo ogni scrittura;
- configurazione pin centralizzata in `ProgrammerConfig.h`.

Le prossime parti da implementare possono essere:

1. invio automatico del file `.hex` da PC;
2. verifica completa della EEPROM dopo la programmazione;
3. comando per cancellare o riempire tutta la EEPROM;
4. scrittura a pagine da 64 byte;
5. supporto diretto al formato `.bin`;
6. test manuali documentati con tabella dei segnali attesi.

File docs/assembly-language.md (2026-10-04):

# Linguaggio assembly CPU 8-bit

Questa specifica descrive la sintassi del linguaggio assembly accettato da `cpu8asm`, l'assembler della CPU didattica a 8 bit.

Il linguaggio assembly e una rappresentazione testuale dei programmi. Label, costanti e direttive esistono solo nel sorgente e vengono risolte dall'assembler; la CPU esegue esclusivamente i byte macchina definiti nella [specifica della ISA](isa.md).

## Stato del documento

Questo documento e la sorgente di verita per la sintassi assembly v0.1.

Le responsabilita della documentazione sono separate in questo modo:

- [ISA](isa.md): architettura visibile al software, semantica delle istruzioni, formati e opcode;
- questo documento: sintassi di programmi, operandi, label, costanti e direttive;
- [README dell'assembler](../tools/assembler/README.md): compilazione e utilizzo dello strumento `cpu8asm`.

## Struttura di un programma

Un programma puo contenere istruzioni, commenti, label e direttive dell'assembler.

Esempio minimo:

```asm
.code 0x0000
LDI R0, 0x0A
STA R0, counter
LDA R1, counter
HLT

.data
counter: .byte 0x00
```

In questo esempio:

- il codice inizia all'indirizzo `0x0000`;
- `LDI` carica il valore `0x0A` in `R0`;
- `counter` viene collocata automaticamente nel primo indirizzo libero, `0x0009`;
- `STA` scrive il valore in memoria e `LDA` lo rilegge in `R1`;
- `HLT` genera `0x00`: nel simulatore arresta la CPU; sulla board richiede
  ROM2 `SYS_STEP_n` collegato in OR con `IR[2:0]` all'abilitazione del microstep.

Una sequenza di sorgenti ampiamente commentati, pensata per la spiegazione nel video, e disponibile nella [cartella principale degli esempi](../examples/assembly/README.md#sequenza-per-il-video-sullassembler).

## Istruzioni e formati

Ogni istruzione e composta da un mnemonic seguito dagli eventuali operandi:

```text
MNEMONIC operando1, operando2
```

Esempi dei tre formati macchina:

```asm
HLT              ; IMP: solo opcode
LDI R0, 0x2A     ; IMM8: opcode e valore immediato a 8 bit
LDA R0, 0x1234   ; ADDR16: opcode e indirizzo a 16 bit
```

La dimensione, la semantica e la codifica di ogni istruzione sono definite nella [tabella opcode della ISA](isa.md#tabella-opcode-riassuntiva).

### Operandi registro

I registri generali validi sono:

```text
R0, R1, R2, R3, R4, R5, R6, R7
```

Le istruzioni di trasferimento ammettono solamente queste forme:

```asm
MOV RA, R0
MOV RB, R1
MOV R2, RA
```

In forma generale:

```text
MOV RA, Rn
MOV RB, Rn
MOV Rn, RA
```

Il trasferimento diretto `MOV Rn, Rm` tra due registri generali non e valido, perche non e previsto dall'hardware della CPU.

### Separazione degli operandi

La virgola e la forma consigliata per separare gli operandi:

```asm
LDI R0, 0x2A
```

La versione attuale dell'assembler accetta anche la forma senza virgola:

```asm
LDI R0 0x2A
```

Gli esempi ufficiali usano sempre la virgola per migliorare la leggibilita.

## Numeri

Sono supportati quattro formati numerici:

| Sintassi | Base | Esempio |
| --- | ---: | --- |
| `0xNN` | 16 | `0x2A` |
| `$NN` | 16 | `$2A` |
| `0bNNNN` | 2 | `0b10101010` |
| `NN` | 10 | `42` |

Queste scritture rappresentano lo stesso valore:

```text
0x2A = $2A = 0b00101010 = 42
```

Negli esempi ufficiali si preferisce la notazione esadecimale con prefisso `0x`.

Un operando `imm8` deve essere compreso tra `0x00` e `0xFF`. Un indirizzo `addr16` deve essere compreso tra `0x0000` e `0xFFFF`.

## Commenti

I commenti iniziano con `;` e continuano fino alla fine della riga:

```asm
; Questa intera riga e un commento.
LDI R0, 0x2A  ; Carica 42 nel registro R0.
```

I commenti non generano byte macchina.

## Maiuscole e minuscole

Mnemonic, registri, direttive e simboli sono case-insensitive.

Queste righe sono equivalenti:

```asm
LDI R0, 0x2A
ldi r0, 0x2a
```

Gli esempi ufficiali usano mnemonic e registri in maiuscolo, direttive e label in minuscolo.

## Label

Una label associa un nome all'indirizzo dell'istruzione o del dato che segue. Non genera byte da sola.

```asm
loop:
LDI R0, 0x01
JMP loop
```

Le label possono essere usate come operandi `addr16`:

```asm
JMP start
JZ equal
LDA R0, counter
STA R0, result
```

Regole per i nomi:

- una definizione di label termina con `:`;
- il nome deve iniziare con una lettera o `_`;
- dopo il primo carattere sono ammessi lettere, numeri e `_`;
- i nomi sono case-insensitive;
- lo stesso nome non puo essere definito due volte.

Una label puo essere scritta da sola oppure prima di una istruzione o direttiva sulla stessa riga:

```asm
start:
counter: .byte 0x00
```

L'assembler usa due passate, quindi una istruzione puo fare riferimento a una label definita piu avanti nel file.

Esempio con salti condizionati:

```asm
MOV RA, R0
MOV RB, R1
CMP
JZ equal

LDI R2, 0x00
JMP done

equal:
LDI R2, 0x01

done:
HLT
```

`JZ equal` e `JMP done` vengono tradotte in salti `ADDR16`, sostituendo le label con i rispettivi indirizzi.

## Costanti simboliche

La direttiva `.equ` associa un nome a un valore numerico:

```asm
.equ SCREEN, 0x8000
.equ NEWLINE, 0x0A

LDI R0, NEWLINE
STA R0, SCREEN
```

La direttiva non genera byte macchina. Nella versione attuale, una costante usata per definire un'altra costante deve essere gia stata dichiarata.

## Direttive

Le direttive controllano il lavoro dell'assembler e non vengono eseguite dalla CPU.

| Direttiva | Effetto |
| --- | --- |
| `.code` | inizia il codice dall'indirizzo predefinito `0x0000` |
| `.code addr16` | inizia il codice dall'indirizzo indicato |
| `.data` | colloca i dati dal primo indirizzo libero dopo i byte gia generati |
| `.data addr16` | colloca i dati dall'indirizzo indicato |
| `.byte value` | scrive un byte nella posizione corrente |
| `.equ name, value`  | associa una costante simbolica a un valore |

### `.code` e `.data`

La CPU usa un'architettura di Von Neumann: codice e dati condividono la stessa memoria. `.code` e `.data` non creano memorie separate, ma cambiano solamente l'indirizzo corrente usato dall'assembler.

La forma consigliata per un programma che parte dal reset e non richiede una mappa di memoria specifica e:

```asm
.code 0x0000
start:
LDI R0, 0x01
STA R0, counter
HLT

.data
counter: .byte 0x00
```

In questo esempio il programma inizia a `0x0000`. Le istruzioni occupano sei byte, quindi `counter` viene posizionata automaticamente a `0x0006`.

L'indirizzo puo essere omesso anche da `.code`:

```asm
.code
```

In questo caso viene usato il valore predefinito `0x0000`. Negli esempi didattici si preferisce comunque `.code 0x0000`, per mostrare esplicitamente l'indirizzo iniziale del Program Counter.

La collocazione automatica richiede che la sezione `.code` venga scritta prima della sezione `.data`. Se `.data` senza indirizzo fosse usata all'inizio del file, partirebbe da `0x0000`; una successiva `.code` riporterebbe l'indirizzo a `0x0000` e potrebbe sovrascrivere i dati. La versione attuale dell'assembler non segnala ancora le sovrapposizioni tra sezioni.

Quando l'hardware richiede una mappa di memoria precisa, si puo continuare a indicare l'indirizzo dei dati:

```asm
.data 0x8000
counter: .byte 0x00
```

Per la versione v0.1 non viene usata `.org` come sintassi ufficiale.

### `.byte`

`.byte` inserisce un singolo valore a 8 bit nell'immagine di memoria:

```asm
.data 0x0100
counter: .byte 0x00
total:   .byte 0x00
flag:    .byte 0x01
```

Nella versione v0.1 ogni direttiva `.byte` accetta un solo valore. Per inserire piu byte si usano piu righe.

## Variabili

Nel linguaggio assembly v0.1 una variabile e una label associata a una cella di memoria da 8 bit:

```asm
counter: .byte 0x00
```

La CPU non conosce il concetto di variabile: vede solamente un indirizzo di memoria. Il nome simbolico viene risolto dall'assembler.

Valori e variabili a 16 bit non fanno parte della sintassi v0.1. Potranno essere rappresentati in futuro mediante coppie di byte.

## Esempio con codice e dati

Sorgente:

```asm
.code 0x0000
LDI R0, 0x05
STA R0, counter
LDA R1, counter
HLT

.data
counter: .byte 0x00
```

La parte di codice occupa gli indirizzi da `0x0000` a `0x0008`, quindi la label `counter` viene calcolata automaticamente come `0x0009`. Gli operandi a 16 bit vengono emessi in ordine little-endian, come stabilito dalla ISA:

```text
LDI R0, 0x05    -> 20 05
STA R0, counter -> 48 09 00
LDA R1, counter -> 41 09 00
HLT             -> 00
NOP             -> 01
```

La direttiva `.byte` posiziona infine il valore `0x00` all'indirizzo `0x0009`.

## Errori

L'assembler rifiuta, tra gli altri:

- mnemonic o direttive sconosciuti;
- numero errato di operandi;
- registri diversi da `R0`...`R7` dove e richiesto un registro generale;
- valori immediati che non entrano in 8 bit;
- indirizzi oltre lo spazio a 16 bit;
- label duplicate o non valide;
- simboli non definiti;
- forme `MOV` non supportate.

Quando possibile, il messaggio include il numero della riga sorgente.

## Limiti della versione v0.1

La sintassi attuale non prevede:

- macro;
- inclusione di altri file;
- espressioni aritmetiche tra simboli;
- stringhe;
- liste di valori in una singola `.byte`;
- dati multi-byte;
- indirizzamento indiretto o indicizzato.

Queste funzionalita potranno essere aggiunte senza modificare la codifica macchina delle istruzioni gia definite nella ISA.

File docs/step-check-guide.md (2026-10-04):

# Verifica manuale: 5 + 3, poi HLT

Programma: `examples/assembly/step_check.asm`. Immagine da 8 byte:
`20 05 21 03 C0 C9 67 00`.
Caricare `tools/assembler/build/step_check.hex` nella EEPROM **programma**.
Le EEPROM CU restano quelle già programmate.

## Come leggere la prova

1. Completa BOOT, poi prepara RUN con PC=0000 e contatore microstep=000,
   tramite il controllo/reset esterno previsto dalla scheda. Tieni il clock
   basso durante il cambio e lascia assestare le uscite.
2. Per ogni riga: PRIMA del fronte di esecuzione controlla microstep e segnali
   della prima tabella. DOPO il fronte e l'assestamento controlla i registri
   della seconda tabella. Le uscite CU dopo il fronte sono già quelle del
   passo seguente: non confrontarle con la riga appena eseguita.
3. Un impulso esegue un microstep, non una intera istruzione. La tabella
   descrive la sequenza funzionale a fronti corretti; eventuali clock locali
   anticipati/spuri vanno diagnosticati sul circuito.

T1=000 è il tuo T0; T2=001, T3=010, T4=011. Gli ingressi fisici EEPROM
sono invertiti: A0=µSTEP2, A1=µSTEP1, A2=µSTEP0. Gli offset EEPROM dei primi
quattro passi sono quindi 0,4,2,6.

Ogni valore dei registri e delle ROM è mostrato come **decimale / esadecimale / binario**.
Esempio: `5 / 0x05 / 00000101`. I binari si leggono da bit più significativo
a bit meno significativo (LED da sinistra a destra: bit 7..0; PC bit 15..0). `?` significa
non ancora inizializzato da questo programma: non richiediamo che il reset
azzerri tutti i registri. PC è a 16 bit, gli altri valori mostrati a 8 bit.
IR resta sull'opcode mentre vengono letti gli immediati: non deve mostrare
05 o 03. I flag sono scritti nell'ordine **C Z N O**.

## Segnali PRIMA del fronte

“Attivi” indica la funzione, non sempre un livello elettrico alto.
MDR_OE, RAM_OE, ALU_EN, NEXT_FETCH e SYS_STEP sono attivi bassi.
PC_LOAD è attivo basso e resta **inattivo (ROM1 D1=1)** per tutta la prova.
ADDR_SEL=01 sceglie PC; 11 nessuna sorgente. Le colonne ROM0/1/2 danno
anche tutti i livelli inattivi e permettono il confronto dei pin D7..D0.
In questo programma i byte non dipendono dai flag; al fetch non dipendono
neppure dal precedente contenuto di IR.

| # | Istruzione | Passo µSTEP | ADDR_SEL | Controlli attivi | ROM0 / ROM1 / ROM2 | Azione al fronte |
|---|---|---|---|---|---|---|
| 1 | LDI R0, 5 | T1 `000` | `01` | IR_WE, PC_INC, RAM_OE | ROM0: `245 / 0xF5 / 11110101`<br>ROM1: `3 / 0x03 / 00000011`<br>ROM2: `65 / 0x41 / 01000001` | Opcode → IR; PC++ |
| 2 | LDI R0, 5 | T2 `001` | `01` | MDR_WE, PC_INC, RAM_OE | ROM0: `253 / 0xFD / 11111101`<br>ROM1: `2 / 0x02 / 00000010`<br>ROM2: `65 / 0x41 / 01000001` | Immediato → MDR; PC++ |
| 3 | LDI R0, 5 | T3 `010` | `11` | MDR_OE, RF_EN, RF_RW | ROM0: `227 / 0xE3 / 11100011`<br>ROM1: `26 / 0x1A / 00011010`<br>ROM2: `73 / 0x49 / 01001001` | MDR → R0 |
| 4 | LDI R0, 5 | T4 `011` | `11` | NEXT_FETCH | ROM0: `115 / 0x73 / 01110011`<br>ROM1: `2 / 0x02 / 00000010`<br>ROM2: `73 / 0x49 / 01001001` | Carica 000 nel microstep; nessun registro dati cambia |
| 5 | LDI R1, 3 | T1 `000` | `01` | IR_WE, PC_INC, RAM_OE | ROM0: `245 / 0xF5 / 11110101`<br>ROM1: `3 / 0x03 / 00000011`<br>ROM2: `65 / 0x41 / 01000001` | Opcode → IR; PC++ |
| 6 | LDI R1, 3 | T2 `001` | `01` | MDR_WE, PC_INC, RAM_OE | ROM0: `253 / 0xFD / 11111101`<br>ROM1: `2 / 0x02 / 00000010`<br>ROM2: `65 / 0x41 / 01000001` | Immediato → MDR; PC++ |
| 7 | LDI R1, 3 | T3 `010` | `11` | MDR_OE, RF_EN, RF_RW | ROM0: `227 / 0xE3 / 11100011`<br>ROM1: `26 / 0x1A / 00011010`<br>ROM2: `73 / 0x49 / 01001001` | MDR → R1 |
| 8 | LDI R1, 3 | T4 `011` | `11` | NEXT_FETCH | ROM0: `115 / 0x73 / 01110011`<br>ROM1: `2 / 0x02 / 00000010`<br>ROM2: `73 / 0x49 / 01001001` | Carica 000 nel microstep; nessun registro dati cambia |
| 9 | MOV RA, R0 | T1 `000` | `01` | IR_WE, PC_INC, RAM_OE | ROM0: `245 / 0xF5 / 11110101`<br>ROM1: `3 / 0x03 / 00000011`<br>ROM2: `65 / 0x41 / 01000001` | Opcode → IR; PC++ |
| 10 | MOV RA, R0 | T2 `001` | `11` | RA_EN, RA_RB_RW, RF_EN | ROM0: `243 / 0xF3 / 11110011`<br>ROM1: `106 / 0x6A / 01101010`<br>ROM2: `73 / 0x49 / 01001001` | R0 → RA |
| 11 | MOV RA, R0 | T3 `010` | `11` | NEXT_FETCH | ROM0: `115 / 0x73 / 01110011`<br>ROM1: `2 / 0x02 / 00000010`<br>ROM2: `73 / 0x49 / 01001001` | Carica 000 nel microstep; nessun registro dati cambia |
| 12 | MOV RB, R1 | T1 `000` | `01` | IR_WE, PC_INC, RAM_OE | ROM0: `245 / 0xF5 / 11110101`<br>ROM1: `3 / 0x03 / 00000011`<br>ROM2: `65 / 0x41 / 01000001` | Opcode → IR; PC++ |
| 13 | MOV RB, R1 | T2 `001` | `11` | RA_RB_RW, RB_EN, RF_EN | ROM0: `243 / 0xF3 / 11110011`<br>ROM1: `202 / 0xCA / 11001010`<br>ROM2: `73 / 0x49 / 01001001` | R1 → RB |
| 14 | MOV RB, R1 | T3 `010` | `11` | NEXT_FETCH | ROM0: `115 / 0x73 / 01110011`<br>ROM1: `2 / 0x02 / 00000010`<br>ROM2: `73 / 0x49 / 01001001` | Carica 000 nel microstep; nessun registro dati cambia |
| 15 | ADD | T1 `000` | `01` | IR_WE, PC_INC, RAM_OE | ROM0: `245 / 0xF5 / 11110101`<br>ROM1: `3 / 0x03 / 00000011`<br>ROM2: `65 / 0x41 / 01000001` | Opcode → IR; PC++ |
| 16 | ADD | T2 `001` | `11` | ALU_EN, FLAGS_WE, RA_EN, RA_RB_RW | ROM0: `243 / 0xF3 / 11110011`<br>ROM1: `98 / 0x62 / 01100010`<br>ROM2: `74 / 0x4A / 01001010` | RA + RB → RA; salva flag |
| 17 | ADD | T3 `010` | `11` | NEXT_FETCH | ROM0: `115 / 0x73 / 01110011`<br>ROM1: `2 / 0x02 / 00000010`<br>ROM2: `73 / 0x49 / 01001001` | Carica 000 nel microstep; nessun registro dati cambia |
| 18 | HLT | T1 `000` | `01` | IR_WE, PC_INC, RAM_OE | ROM0: `245 / 0xF5 / 11110101`<br>ROM1: `3 / 0x03 / 00000011`<br>ROM2: `65 / 0x41 / 01000001` | Opcode → IR; PC++ |
| 19 | HLT | T2 `001` | `11` | SYS_STEP | ROM0: `243 / 0xF3 / 11110011`<br>ROM1: `2 / 0x02 / 00000010`<br>ROM2: `9 / 0x09 / 00001001` | Arresto: µSTEP_EN=0, resta in 001 |

## Registri DOPO il fronte

MAR, IDX e R2..R7 non vengono modificati da questa prova. MDR resta **3 / 0x03 / 00000011** dopo
il secondo LDI; non contiene il risultato della somma. Il risultato è in RA.

| # | PC | IR | MDR | R0 | R1 | RA | RB | C Z N O |
|---|---|---|---|---|---|---|---|---|
| 1 | `1 / 0x0001 / 0000000000000001` | `32 / 0x20 / 00100000` | ? | ? | ? | ? | ? | ? ? ? ? |
| 2 | `2 / 0x0002 / 0000000000000010` | `32 / 0x20 / 00100000` | `5 / 0x05 / 00000101` | ? | ? | ? | ? | ? ? ? ? |
| 3 | `2 / 0x0002 / 0000000000000010` | `32 / 0x20 / 00100000` | `5 / 0x05 / 00000101` | `5 / 0x05 / 00000101` | ? | ? | ? | ? ? ? ? |
| 4 | `2 / 0x0002 / 0000000000000010` | `32 / 0x20 / 00100000` | `5 / 0x05 / 00000101` | `5 / 0x05 / 00000101` | ? | ? | ? | ? ? ? ? |
| 5 | `3 / 0x0003 / 0000000000000011` | `33 / 0x21 / 00100001` | `5 / 0x05 / 00000101` | `5 / 0x05 / 00000101` | ? | ? | ? | ? ? ? ? |
| 6 | `4 / 0x0004 / 0000000000000100` | `33 / 0x21 / 00100001` | `3 / 0x03 / 00000011` | `5 / 0x05 / 00000101` | ? | ? | ? | ? ? ? ? |
| 7 | `4 / 0x0004 / 0000000000000100` | `33 / 0x21 / 00100001` | `3 / 0x03 / 00000011` | `5 / 0x05 / 00000101` | `3 / 0x03 / 00000011` | ? | ? | ? ? ? ? |
| 8 | `4 / 0x0004 / 0000000000000100` | `33 / 0x21 / 00100001` | `3 / 0x03 / 00000011` | `5 / 0x05 / 00000101` | `3 / 0x03 / 00000011` | ? | ? | ? ? ? ? |
| 9 | `5 / 0x0005 / 0000000000000101` | `192 / 0xC0 / 11000000` | `3 / 0x03 / 00000011` | `5 / 0x05 / 00000101` | `3 / 0x03 / 00000011` | ? | ? | ? ? ? ? |
| 10 | `5 / 0x0005 / 0000000000000101` | `192 / 0xC0 / 11000000` | `3 / 0x03 / 00000011` | `5 / 0x05 / 00000101` | `3 / 0x03 / 00000011` | `5 / 0x05 / 00000101` | ? | ? ? ? ? |
| 11 | `5 / 0x0005 / 0000000000000101` | `192 / 0xC0 / 11000000` | `3 / 0x03 / 00000011` | `5 / 0x05 / 00000101` | `3 / 0x03 / 00000011` | `5 / 0x05 / 00000101` | ? | ? ? ? ? |
| 12 | `6 / 0x0006 / 0000000000000110` | `201 / 0xC9 / 11001001` | `3 / 0x03 / 00000011` | `5 / 0x05 / 00000101` | `3 / 0x03 / 00000011` | `5 / 0x05 / 00000101` | ? | ? ? ? ? |
| 13 | `6 / 0x0006 / 0000000000000110` | `201 / 0xC9 / 11001001` | `3 / 0x03 / 00000011` | `5 / 0x05 / 00000101` | `3 / 0x03 / 00000011` | `5 / 0x05 / 00000101` | `3 / 0x03 / 00000011` | ? ? ? ? |
| 14 | `6 / 0x0006 / 0000000000000110` | `201 / 0xC9 / 11001001` | `3 / 0x03 / 00000011` | `5 / 0x05 / 00000101` | `3 / 0x03 / 00000011` | `5 / 0x05 / 00000101` | `3 / 0x03 / 00000011` | ? ? ? ? |
| 15 | `7 / 0x0007 / 0000000000000111` | `103 / 0x67 / 01100111` | `3 / 0x03 / 00000011` | `5 / 0x05 / 00000101` | `3 / 0x03 / 00000011` | `5 / 0x05 / 00000101` | `3 / 0x03 / 00000011` | ? ? ? ? |
| 16 | `7 / 0x0007 / 0000000000000111` | `103 / 0x67 / 01100111` | `3 / 0x03 / 00000011` | `5 / 0x05 / 00000101` | `3 / 0x03 / 00000011` | `8 / 0x08 / 00001000` | `3 / 0x03 / 00000011` | `0 0 0 0` |
| 17 | `7 / 0x0007 / 0000000000000111` | `103 / 0x67 / 01100111` | `3 / 0x03 / 00000011` | `5 / 0x05 / 00000101` | `3 / 0x03 / 00000011` | `8 / 0x08 / 00001000` | `3 / 0x03 / 00000011` | `0 0 0 0` |
| 18 | `8 / 0x0008 / 0000000000001000` | `0 / 0x00 / 00000000` | `3 / 0x03 / 00000011` | `5 / 0x05 / 00000101` | `3 / 0x03 / 00000011` | `8 / 0x08 / 00001000` | `3 / 0x03 / 00000011` | `0 0 0 0` |
| 19 | `8 / 0x0008 / 0000000000001000` | `0 / 0x00 / 00000000` | `3 / 0x03 / 00000011` | `5 / 0x05 / 00000101` | `3 / 0x03 / 00000011` | `8 / 0x08 / 00001000` | `3 / 0x03 / 00000011` | `0 0 0 0` |

## Arresto e risultato

Dopo il fetch di HLT (riga 18), IR=**0 / 0x00 / 00000000**,
PC=**8 / 0x0008 / 0000000000001000** e il contatore entra in `001`.
Le uscite della riga 19 danno ROM2 D6=0; con IR2..IR0=000 la OR vale zero.
HLT non attende un altro impulso per rendere basso il consenso: entrando
in T2 il contatore è già inibito. La riga 19 indica lo stato fermo e il
comportamento con ulteriori impulsi, non un microstep che avanza.

Conseguentemente bastano **18 fronti utili RUN** per raggiungere l'arresto.
Altri impulsi devono lasciare microstep=`001` e i registri invariati:
PC=**8 / 0x0008 / 0000000000001000**, IR=**0 / 0x00 / 00000000**,
RA=**8 / 0x08 / 00001000**, RB=**3 / 0x03 / 00000011**.
Il clock principale può continuare se è inibito soltanto il contatore.

I LED su IR verificano questa sequenza:

| Istruzione | Decimale | Esadecimale | Binario IR[7:0] |
|---|---|---|---|
| LDI R0, 5 | 32 | 0x20 | `00100000` |
| LDI R1, 3 | 33 | 0x21 | `00100001` |
| MOV RA, R0 | 192 | 0xC0 | `11000000` |
| MOV RB, R1 | 201 | 0xC9 | `11001001` |
| ADD | 103 | 0x67 | `01100111` |
| HLT | 0 | 0x00 | `00000000` |

Per verificare anche i dati usa LED/probe o misure sui registri indicati:
IR da solo non dimostra che R0, R1 e RA contengano i risultati corretti.

Tabella confrontata con i bit delle tre immagini CU attuali; programma
assemblato e verificato anche nel simulatore funzionale. Questo programma
non prova scrittura RAM, salti, CMP, IDX o tutti i casi dei flag: serve come
prima prova breve per localizzare il primo passo divergente.

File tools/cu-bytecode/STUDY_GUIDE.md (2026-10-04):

# Guida allo studio del generatore della Control Unit

`cu-bytecode` genera i binari per le tre EEPROM AT28C64 della Control Unit.
Le tre ROM condividono i 13 ingressi di indirizzo e producono, insieme, una
microistruzione da 24 bit. Esiste una funzione per costruire una tabella di
dispatch opzionale, ma l'eseguibile attuale scrive **solo tre** immagini ROM.

## Idea generale

Le linee di indirizzo condivise sono:

```text
A0..A2   = uSTEP[0..2]
A3..A7   = IR[3..7] nel cablaggio del video 25
A8..A11  = flag C, Z, N, O
A12      = BOOT_RUN
```

Le linee `D0..D7` sono invece uscite diverse per ogni EEPROM. Il generatore
prima costruisce una parola logica, dove `1` significa segnale attivo, poi usa
la configurazione fisica per trasformarla nei tre byte EEPROM, applicando
anche le polarita attive basse.

## Ordine di lettura consigliato

1. `README.md`
2. `config/control_signals.h`
3. `config/control_signals.c`
4. `config/architecture.h`
5. `include/microcode.h`
6. `src/microcode.c`
7. `src/main.c`
8. `include/output.h` e `src/output.c`
9. `tests/test_microcode.c`

## Configurazione: `config/control_signals.h`

Contiene tutte le costanti simboliche della AT28C64: pin `A0..A12`,
`IO0..IO7`, `/CE`, `/OE`, `/WE`, GND, VCC e NC. Contiene inoltre i nomi
funzionali, per esempio `CPU8_CONTROL_ROM_PIN_USTEP_0`,
`CPU8_CONTROL_ROM_PIN_FLAG_C` e `CPU8_CONTROL_ROM_PIN_D6`.

Definisce anche `ControlEepromAddressConfig`, la struttura dati per la mappa
degli ingressi comuni alle tre EEPROM.

## Configurazione: `config/control_signals.c`

Questo e il file da modificare quando cambia il cablaggio.

`CPU8_CONTROL_EEPROM_ADDRESS_CONFIGS` mappa i 13 segnali di ingresso agli
indirizzi `A0..A12`. La tabella e comune a ROM 0, ROM 1 e ROM 2.

`CPU8_CONTROL_SIGNAL_CONFIGS` mappa le uscite. Ogni riga ha questa forma:

```c
{ segnale_logico, nome, numero_rom, bit_D0_D7, pin_AT28C64, polarita }
```

Esempio:

```c
{CTRL_RAM_OE, "RAM_OE", 0, 6, CPU8_CONTROL_ROM_PIN_D6, ACTIVE_LOW}
```

Significa: ROM 0, `D6`, pin fisico 16, segnale attivo basso.

## `config/architecture.h`

Contiene i codici del selettore del bus indirizzi (`IDX`, `PC`, `MAR` o
nessuna sorgente) e i livelli di `BOOT_RUN`. Se cambia il cablaggio del
decoder, modifica questo file invece delle microsequenze.

## `include/microcode.h`

E il contratto pubblico del progetto. Dichiara:

- `ControlWord`, parola logica dei segnali;
- `ControlSignal`, le maschere dei 23 segnali;
- `MicroOp`, i microprogrammi;
- flag, modi CPU e funzioni di generazione.

## `src/microcode.c`

E il motore del generatore. `microcode_word` descrive le microsequenze di
fetch, load, store, ALU, movimenti e salti. Lo stesso file:

- converte i gruppi `IR[7:3]` in microprogrammi con `microop_for_ir_group`;
  `dispatch_opcode` serve solo alla tabella opzionale e ai test;
- valuta le condizioni usando i flag `C`, `Z`, `N`, `O`;
- verifica che non esistano contese sul data bus;
- applica la polarita fisica con `encode_control_word`;
- riempie tutte le 8192 celle delle tre ROM.

La ROM di dispatch e un'estensione opzionale rispetto al video 25 e **non
serve** nel cablaggio corrente: gli opcode attivi con microsequenze differenti
occupano gruppi `IR[7:3]` distinti. `HLT` e `NOP` condividono il gruppo, ma
la distinzione avviene con `SYS_STEP_n OR IR[2:0]` fuori dalle EEPROM.

## `src/main.c`

E il punto di ingresso di `cpu8microcode`: costruisce le immagini, le valida e
scrive `microcode-rom0.bin`, `microcode-rom1.bin` e `microcode-rom2.bin`.
L'opzione `-o` cambia il prefisso dei file.

## `include/output.h` e `src/output.c`

Gestiscono solo la scrittura binaria su disco. La separazione mantiene il
motore del microcodice indipendente dall'I/O e semplice da testare.

## `tests/test_microcode.c`

Contiene test con `assert` per dispatch, 13 ingressi comuni, microsequenze,
polarita, pin `D0..D7` e contese sul data bus.

## Compilare e generare

```sh
make -C tools/cu-bytecode
make -C tools/cu-bytecode test
make -C tools/cu-bytecode generate
```

I binari vengono creati in `tools/cu-bytecode/build/`.

## Percorso pratico

1. Confronta `CPU8_CONTROL_EEPROM_ADDRESS_CONFIGS` con il cablaggio reale.
2. Controlla i gruppi di otto uscite in `CPU8_CONTROL_SIGNAL_CONFIGS`.
3. Esegui i test prima e dopo ogni modifica.
4. Rigenera le immagini e programma una EEPROM alla volta.

## Limiti attuali

- Il BOOT copia in ciclo continuo gli 8 KiB della EPROM: il passaggio a RUN e
  l'azzeramento finale di PC restano azioni hardware esterne.
- `HLT=0x00` e `NOP=0x01` condividono `IR[7:3]`, ma ROM2 D6 emette
  `SYS_STEP_n=0` solo in RUN/T2. La OR esterna con `IR[2:0]` ferma il
  contatore microstep solo per HLT; il pin resta alto durante T1 e BOOT.
- `IDX` non ha incremento automatico: `LDX` lo ricarica esplicitamente.

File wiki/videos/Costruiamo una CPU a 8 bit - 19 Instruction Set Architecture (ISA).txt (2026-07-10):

Salve a tutti e bentornati sul mio
canale YouTube. Oggi continuiamo a
parlare della CPU a 8 bit. Parleremo
dell'istruction set. Ma prima di
iniziare vi ricordo di lasciare un mi
piace, commentare questo video e
iscrivervi al mio canale per supportare
il mio lavoro. Nei video precedenti,
quando abbiamo parlato di memoria,
abbiamo detto che le istruzioni che puoi
eseguire il nostro computer, la nostra
CPU, avranno un numero di bit che andrà
a differire a seconda dell'operazione.
Quindi abbiamo operazioni che hanno 3
byte, quindi 24 bit.
In pratica hanno i primi 8 bit che
identificano la tipologia di operazione
e poi i successivi 16 bit che sono un
indirizzo di memoria che servirà proprio
per l'esecuzione dell'operazione.
Poi abbiamo istruzioni che hanno un
codice operazione a 8 bit e un immediato
a 8 bit, quindi un totale di 16 bit, 2
byte. E poi istruzioni più semplici che
con un solo byte, quindi 8 bit di
informazioni, possono essere
rappresentate, quindi avranno solo i
primi 8 bit che rappresentano il codice
operazione. Ora noi in questo video
andremo a dettagliare tutte queste
operazioni e andremo a definire l'ISA.
ISA è un acronimo che sta per
instruction set architecture. Diciamo
quindi che abbiamo i primi 8 bit comune
a tutte le tipologie di istruzione.
L'idea è quella di dividere questi 8 bit
in due sottogruppi.
Ho diviso in questi due sottogruppi i
primi 8 bit. Abbiamo i primi 3 bit che
ho identificato con la lettera C.
sta per category che vanno a
rappresentare una sottocategoria
dell'istruzione
e poi abbiamo i successivi 5 bit che
sono specifici e dipendono dal tipo di
operazione, quindi dipenderanno
effettivamente dai primi 3 bit. Diciamo
che per capire meglio ho fatto questa
piccola tabella riassuntiva dove vado ad
analizzare i primi tre bit e vado già a
creare una sorta di macrocategorie di
istruzioni. Partiamo. Se i primi tre bit
sono a zero, quindi CC C e 00,
si tratta di operazioni di sistema
comunque di controllo. Ad esempio,
abbiamo l'Alt che ferma la CPU oppure
no, OP che dice alla CPU di non fare
nulla, di non fare nessuna operazione.
Poi abbiamo le istruzioni che iniziano
con 001 e servono a caricare un
immediato all'interno di un registro.
Poi abbiamo le operazioni 010 che fanno
riferimento alla memoria, servono a fare
il salvataggio e il caricamento di dati
presenti nella memoria verso dei
registri o viceversa.
Poi abbiamo 0 1 sono tutte le
operazioni, tutte le istruzioni legate
all'unità aritmeticologica.
100 sono istruzioni legate all'input e
all'output, quindi a futuri dispositivi
di input e output da collegare al nostro
computer. 8 bit. Poi abbiamo 10, sono
tutte le istruzioni di jump, quindi
salto condizionali oppure salti.
E poi abbiamo 10. Eh, questa categoria
serve a gestire tutte tutti i
trasferimenti tra i registri generali e
i registri RA ed RB. E infine abbiamo
111 che in realtà attualmente non è
utilizzata, però può essere utilizzata
per future espansioni. Ora proviamo a
snocciolare ogni singola macrocategoria,
ogni singola categoria e vediamo
effettivamente quali operazioni, quali
istruzioni andrà effettivamente a
includere.
Andiamo ad analizzare tutte le
operazioni relative al sistema. hanno i
primi 3 bit a zero. Ho raffigurato
questa tabella che va comunque a
riassumere tutte le operazioni
eseguibili. Abbiamo un codice operazione
in binario, abbiamo poi la conversione
esadecimale, una stringa che va a
rappresentare l'istruzione assembly che
poi utilizzeremo in un programma
assembler e poi abbiamo un una
descrizione.
Partiamo subito quindi con no che sta
per nessuna operazione. In pratica dice
alla CPU che eh per quella esecuzione
dovrà stare ferma, non dovrà fare nulla
ed ha come codice, quindi i primi 8 bit
dell'istruzione sono tutti a zero. Poi
passiamo all'istruzione di Alt che ferma
la CPU. Questa questa istruzione ha i
primi 7 bit a 0 e l'ultimo bit a 1. Lo
vediamo qui. Piccola nota 0b è la
rappresentazione indica stiamo
utilizzando la rappresentazione binaria,
invece 0x è lo stesso numero, però
rappresentato in esadecimale. Invece
tutti gli altri indirizzi, tutti gli
tutte le altre combinazioni
che vanno da uno-0 come bit finali a
tutti uno sono riservate, quindi non non
vengono utilizzate oggi, però possono
essere utilizzate in futuro se decidiamo
di espandere il set di istruzioni e
decidiamo che all'interno della
categoria di sistema dovranno esserci
altre operazioni.
Andiamo avanti. Per il codice 001,
quindi i primi 3 bit con codice 001,
abbiamo tutte le istruzioni che fanno
riferimento al caricamento di un
immediato all'interno del registro. Qui
ho fatto una piccola suddivisione del
del codice operazione, quindi dei primi
8 bit. Abbiamo i primi 3 bit che sono
sempre fissi a 001.
Poi ci sono altri due bit che ho
chiamato SS, dovrebbe essere una sorta
di sottocategorie subcategory, e poi
abbiamo altri 3 bit RR che vanno a
identificare il registro coinvolto e poi
ci sono i successivi 8 bit che sono il
valore immediato. Diciamo che SS, quindi
la subcategory,
non la utilizziamo, o meglio,
utilizziamo sulla combinazione 00,
quindi tutte le altre sono riservate,
non vengono utilizzate ad oggi. E qui
abbiamo una piccola tabella riassuntiva
che va a definire l'istruzione assembly,
il codice esadimale corrisp
corrispettivo e il codice in binario.
Analizziamo la prima, abbiamo LDI che
sta per load immediato. Andiamo a
prendere il registro R0 che sarà il
registro di destinazione e caricheremo
il valore immediato. IMM8. Qui dobbiamo
immaginare un valore numerico che sarà
l'immediato e corrisponde a questi bit.
In pratica, se poi noi andiamo a vedere
eh il codice binario generato, vediamo
che abbiamo 001
che corrisponde ai primi 3 bit, 0 che
corrisponde ai secondi 2 bit sono la
subcategory che abbiamo detto che è
sempre fissa a zero. E poi abbiamo gli
ultimi 3 bit che saranno i registri. Se
ci fate caso, partendo da R0 a finire
R7, l'unica cosa che cambia sono gli
ultimi 3 bit che identificano il
registro. Quindi partiamo da 00 e
finiamo con 11 1 che identifica R7. Il
primo registro è R0, quindi partiamo da
R0 e finiamo su R7. Sono un totale di
otto registri generali.
Passiamo alle operazioni, alle
istruzioni relative alla memoria. In
questo caso i primi 3 bit saranno su
010.
Ho mantenuto lo stesso impianto relativo
al caricamento degli immediati, quindi
abbiamo i primi 3 bit che saranno fissi
a 010,
i successivi 2 bit che vanno a
rappresentarmi la subcategory e poi
abbiamo 3 bit che rappresentano il
registro e infine 16 bit che vanno a
rappresentarmi l'indirizzo di memoria
coinvolto. In questa casistica eh i due
bit SS vengono utilizzati perché prima
erano fissi a zero. Qui ho una piccola
tabella riassuntiva che mi dice a
seconda dei bit SS e che tipo di eh
istruzioni vado a eseguire. Abbiamo che
nel caso in cui SS è a 0, quindi 00,
avremo tutte le istruzioni che prevedono
il caricamento all'interno di un
registro generale di un dato presente in
memoria. Quindi, che cosa vado a fare?
Vado a leggere all'interno
dell'indirizzo di memoria rappresentato
da questi 16 bit. Faccio la lettura e
vado a salvarmi l'informazione
all'interno del registro generale.
Invece la casistica 01 è il caso
inverso, quindi vado a fare una
scrittura all'interno della memoria,
quindi leggo ciò che è presenta
all'interno di questo registro e lo
salvo all'interno dell'indirizzo di
memoria rappresentato da questi 16
bitzione.
Tutte le altre casistiche, quindi 10 e
1, non sono utilizzate, quindi li
possiamo usare per espansioni future.
Qui abbiamo due sottotabelle che vanno a
snocciolare i casi SS00 e 01. Partiamo
con il caso ehm 00. Il caso 00, quindi
abbiamo detto che eh si tratta di eh
prendere un'informazione
presente all'interno di una cella di
memoria e salvarla all'interno di un
registro. L'istruzione assembly sarà
LDA, quindi load,
load address, quindi abbiamo R0 che è il
registro generale in questo caso e poi
abbiamo i 16 bit
all'indirizzo. Questo è il corrispettivo
in esadecimale e questo è il
corrispettivo in binario, quindi codice
macchina.
Vabbè, c'è poco da dire. Abbiamo 010 che
è la prima, sono i primi 3 bit fissi.
Poi abbiamo i successivi 2 bit 00 che
sono i bit relativi alla sottocategoria
e poi il registro che identifica 00 e eh
andiamo avanti con 001 010 e così via
fino ad arrivare all'ultimo registro che
sarà 11 1. Invece da questo lato abbiamo
l'istruzione STA che serve, come abbiamo
detto, a caricare all'interno della
memoria ciò che abbiamo salvato
all'interno di un registro.
Abbiamo sempre eh l'istruzione STA
registro e indirizzo a 16 bit, codice
esadecimale e codice binario che poi è
quello che ci interessa.
In pratica abbiamo 010 che è fisso, sono
i primi 3 bit di categoria, 01 che sarà
sempre fisso per questa tabella e va a
rappresentare la subcategory. E poi
abbiamo i registri, quindi abbiamo 00
R0 001 R1 e così via fino ad arrivare a
111 1 che rappresenta R7.
Passiamo alle istruzioni relative
all'alu. Come codice avranno 011.
Qui ho un breve sunt in cui abbiamo i
primi tre bit che sono fissi a 011.
Abbiamo questo Bit X che in realtà non
utilizziamo, lo lasciamo fisso a zero. È
una sorta di subcategory che comunque
abbiamo sempre lasciato a zero nel caso
di istruzioni relative all'alu. E poi
abbiamo questi 4 bit che vanno a
pilotare direttamente
eh la nostra alu. Quindi è il vecchio
codice operazione che di cui parlavo nei
primi video che va a identificare quale
operazione deve fare l'alu. Oggi abbiamo
uno switch che andiamo a pilotare per
selezionare l'operazione dell'alu. In
realtà in futuro dovremo staccare lo
switch e collegarlo all'interno di
questi 4 bit.
Qui abbiamo una tabella riassuntiva di
tutte le operazioni. Faccio un breve
recap sul funzionamento della nostra
alu. Nella nella nostra architettura
abbiamo detto che
l'alu farà l'operazione selezionata da
questi 4 bit e farà saranno gli ingressi
RA ed RB. Poi l'uscita sarà salvata
nuovamente in RA. Ad esempio, prendiamo
l'END, abbiamo 011 che ricordo sono i
bitia. 0 che è il nostro x e poi i 4 bit
0 che rappresentano l'istruzione end. E
il risultato sarà che all'interno del
registro RA avrò l'end tra RA ed RB.
Passiamo all'istruzione OR che avrà come
codice 001
e farà l'OR tra RA ed RB e il risultato
sarà salvato in RA e così via. Quindi
XOR che sarà 0010,
NOR che sarà eh 0011,
Nend che sarà 0100,
Snor e così via. Abbiamo tutte le
istruzioni.
Eh, piccola nota, il Note che che è 0110
ha bisogno di un solo operando, quindi R
sarà uguale al not di RA.
Poi vabbè, abbiamo ad sub compare. Per
il compare dobbiamo generare dei flag e
dobbiamo salvare questi flag all'interno
di un di un registro. E poi tutto il
resto sono ehm operazioni riservate,
quindi abbiamo tutte le combinazioni con
x
a 1 e eh tutte le combinazioni restanti
perché comunque non abbiamo completato
tutte le combinazioni con x a 0 e quindi
possiamo espandere anche la nostra alu,
quindi potremmo pensare di implementare
future operazioni all'interno della
nostra alu.
A questo punto parliamo dei salti. Il
codice
di categoria è 101,
quindi avremo 101 fisso per tutte le
combinazioni presenti in questa tabella.
Poi avremo 5 bit che vanno a
rappresentare eh i vari le varie
tipologie di salto e poi avremo i 16 bit
successivi che vanno a rappresentare
l'indirizzo di memoria a cui bisognerà
saltare.
Partiamo dal jump.
Abbiamo questo codice assembly jump
suseguito dall'indirizzo di memoria 16
bit e questo qua ci dice che la CPU
arrivata a questa istruzione deve
seguire il salto indipendentemente da
eventuali condizioni o stato di flag.
Abbiamo il codice binario che è 101 e
poi tutti i bit a 0, tutti i 5 bit
successivi a zero. Poi abbiamo
eh JZ che sta per jump, quindi salterà
soltanto se eh il flag 0 è a 1. Questa
condizione in pratica si verifica quando
RA è uguale RB, quindi è la condizione
di uguaglianza quando facciamo il
compare tra due variabili che darà come
risultato il Flex 0 a 1. Questa è
l'istruzione binaria 10 1
poi abbiamo JNZ che sta per jump if not
zero, quindi salta se m il confronto non
dà zero. In pratica vuol dire che RA è
diverso da RB e viene valutato il flag
zero che in questo caso deve essere
uguale a 0 per effettuare il salto.
Poi abbiamo JC che sta per jump if
carry. In pratica ehm salta solo se si
verifica un eventuale riporto, quindi C
= 1, ed equivale a una condizione in cui
il registro A è minore registro B. Poi
abbiamo JNC jump if not carry che in
pratica sarebbe m salta se C è uguale a
0, quindi carry ugale
ad RA mag o uguale di RB. Poi abbiamo JN
che sta per jump if negative, quindi
salta se eh il risultato è negativo. Che
cosa vuol dire? Vuol dire che il bit
negative è uguale a 1. Risultato
negativo.
JNN sta per jump if not negative. è
l'opposto del precedente, quindi salta
se n è uguale a 0, quindi il risultato
non è negativo.
Poi abbiamo eh Jof overflow, salta se
c'è stato un overflow e valuta il flag
di overflow che deve essere a uno. JNO
che sta per jump if no overflow vuol
dire che ehm si salta se il bit di
overflow, il flag di overflow è a zero,
quindi non c'è stato overflow. Tutte le
altre combinazioni invece sono
riservate, quindi espansione futura.
sui salti dobbiamo fare anche un'altra
considerazione. Possiamo dire che come
prima versione dell'ISA, quindi
Struction Set Architecture, potrebbe
andare questa tabella, però in realtà eh
possiamo anche espandere questa tabella
perché potremmo anche considerare più di
un flag contemporaneamente e
considerando più di un flag
contemporaneamente potremmo gestire
altre casistiche, però eventualmente
tutta questa parte la vediamo poi quando
sviluppiamo la control unit e vediamo se
aumentare il numero di
di istruzioni della nostra CPU. Tanto
abbiamo già detto che abbiamo una serie
di bit riservati, quindi una serie di
combinazioni che ci permettono di
espandere in futuro questo set di
istruzioni.
A questo punto vediamo i trasferimenti.
Codice di categoria CC = 10. In pratica
sono tutte quelle operazioni che
riguardano il registri RA ed RB. In
questo caso abbiamo quindi i primi 3 bit
che sono fissi a 1, poi abbiamo 2 bit
subcategory SS e un registro coinvolto,
quindi 3 bit che mi selezionano il
registro. Qui ho una tabella
riassuntiva, ad esempio eh SS00,
facciamo la copia di un registro
generale in R. Abbiamo quindi 1 che è mh
costante per tutti, per tutte le
combinazioni, 00 che è la casistica SS e
poi il registro coinvolto.
Poi abbiamo SSA01
M è la copia di RN in RB, quindi stiamo
copiando un registro generale in RB.
Infine, poi abbiamo l'ultimo caso che è
la copia di R in RN e abbiamo come SS
10. Tutte le altre combinazioni invece
sono riservate, quindi non vengono
utilizzate. Queste sono le istruzione
assembly, quindi abbiamo move RA in RN,
move RB in RN, move RN in RA, diciamo
sono abbastanza esplicative, quindi
abbastanza facili da intuire.
A questo punto l'unica combinazione che
rimane è quella relativa al alle
periferiche di input output che non
abbiamo visto nel dettaglio. Non le
abbiamo viste perché ancora non ho ben
definito questo set di istruzioni e le
vedremo più avanti quando inizieremo poi
a pensare a come far dialogare la nostra
CPU con l'esterno.
Io direi che per questo video è tutto.
In un prossimo video vedremo
effettivamente come realizzare un
programma, scrivere un programma
assembly per la nostra CPU e poi
proviamo a creare una sorta di
compilatore che va a prendere l'assembly
e lo traduce in un binario. Questo
binario poi dovrà essere inserito
all'interno di una eprom che eh poi
eseguirà la nostra CPU. Quindi vi
ricordo di iscrivervi al mio canale
YouTube, lasciare un mi piace e
commentare questo video per supportare
il mio lavoro. Un saluto.

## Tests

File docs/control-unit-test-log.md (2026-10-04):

# Verifiche della Control Unit

Questo documento raccoglie, una fase alla volta, le operazioni da provare sulla
CPU fisica, i livelli attesi e le misure effettuate. Ogni riga delle tabelle
BOOT e RUN corrisponde a un preciso intervallo temporale `T1..T8` del
contatore dei microstep. Gli ingressi `A0..A12` sono comuni alle tre Control
ROM; ogni ROM presenta contemporaneamente il proprio byte `D7..D0`.

**Stato delle misure:** da eseguire. I valori nelle tabelle sono quelli
generati dal microcodice, non letture gia effettuate sulla scheda.

**Versione della ROM0 da testare:** il binario aggiornato contiene `0x91` in
T1, `0xB5` in T2 e `0x31` in T3. Il 23 settembre 2026 la EEPROM fisica e
stata riprogrammata con questo binario: 8192 byte scritti e verifica CRC-16
finale riuscita. Il nuovo binario RUN descritto sotto **non e ancora stato
caricato nelle tre EEPROM fisiche**. Restano da misurare i livelli sulla CU.

Riferimenti: [configurazione dei pin](../tools/cu-bytecode/config/control_signals.c),
[generatore del microcodice](../tools/cu-bytecode/src/microcode.c),
[mappa completa delle uscite](control-unit-eeprom-output-map.md).

## BOOT: copia EPROM → RAM

T1, T2 e T3 sono **tre fasi temporali distinte**, una dopo l'altra; non sono
tre pin della EEPROM. Il contatore le codifica sui suoi tre bit `µSTEP[2:0]`,
che entrano nelle EEPROM come parte dell'indirizzo. La sequenza e
`T1 (000) → clock → T2 (001) → clock → T3 (010) → clock con NEXT_FETCH → T1 (000)`
se D7 pilota `/LOAD` del 74161. Sul cablaggio con `/CLR` asincrono il ritorno
puo avvenire gia durante T3: questo va misurato sulla scheda.

Il PC seleziona il bus indirizzi in tutte e tre le fasi. In T1 l'EPROM presenta
il byte e la RAM lo scrive; in T2 la RAM termina la scrittura, l'EPROM continua
a presentare il dato e il PC avanza al clock; in T3 l'EPROM continua a pilotare
il bus dati mentre la CU riporta il contatore alla fase T1.

### Tabella di verita 1 — ingressi comuni alle tre Control ROM

`0` = livello logico basso, `1` = livello logico alto. Per questa prova fissiamo
`IR[7:3]=00000` e i quattro flag a `0000`, cosi ogni ingresso e l'indirizzo
risultante hanno un valore preciso. Su tutte e tre le EEPROM la piedinatura e:
`A12` pin 1 = `BOOT_RUN`; `A11..A8` pin 21, 19, 22, 23 = `O,N,Z,C`;
`A7..A3` pin 2, 3, 4, 5, 6 = `IR[7:3]`;
`A2` pin 7 = `µSTEP[0]`, `A1` pin 8 = `µSTEP[1]`,
`A0` pin 24 = `µSTEP[2]`.

| Fase temporale | Bit logici del contatore `µSTEP[2:0]` | `A12` | `A11..A8` | `A7..A3` | `A2` | `A1` | `A0` | Indirizzo EEPROM `A12..A0` in binario |
| --- | :---: | :---: | :---: | :---: | :---: | :---: | :---: | ---: |
| **T1 — copia** | `000` | 0 | `0000` | `00000` | 0 | 0 | 0 | `0 0000 00000 000` |
| **T2 — chiusura scrittura e PC++** | `001` | 0 | `0000` | `00000` | 1 | 0 | 0 | `0 0000 00000 100` |
| **T3 — reset del microstep** | `010` | 0 | `0000` | `00000` | 0 | 1 | 0 | `0 0000 00000 010` |

I bit fisici `A2:A1:A0` passano quindi da `000` a `100` a `010`.
Se IR o flag non sono a zero, `A3..A11` seguono i loro valori reali e
l'indirizzo numerico cambia. Nel banco BOOT le uscite attese restano identiche.

### Tabella di verita 2 — uscite Control ROM 0

Ogni cella e il livello logico atteso **sul pin di uscita della Control ROM 0
durante quella fase**, non il contenuto del registro controllato. Uno `0` su
un segnale con `/` nel nome lo attiva. I pin `D7..D0` della AT28C64 DIP-28
sono rispettivamente `17, 16, 15, 14, 13, 11, 10, 9`.

| Fase temporale | `D7`<br>`NEXT_FETCH_n` | `D6`<br>`/OE_EPROM` | `D5`<br>`/WE_RAM` | `D4`<br>`/OE_MDR` | `D3`<br>`MDR_WE` | `D2`<br>`PC_INC` | `D1`<br>`ADDR_SEL_1` | `D0`<br>`ADDR_SEL_0` | Byte ROM0 `D7..D0` in binario |
| --- | :---: | :---: | :---: | :---: | :---: | :---: | :---: | :---: | ---: |
| **T1 — copia** | 1 | 0 | 0 | 1 | 0 | 0 | 0 | 1 | `10010001` |
| **T2 — chiusura scrittura e PC++** | 1 | 0 | 1 | 1 | 0 | 1 | 0 | 1 | `10110101` |
| **T3 — reset del microstep** | 0 | 0 | 1 | 1 | 0 | 0 | 0 | 1 | `00110001` |

La coppia `D1:D0=01` mantiene il PC come sorgente dell'indirizzo. I byte
`D7..D0` sono `10010001` (`0x91`) in T1, `10110101` (`0xB5`) in T2 e
`00110001` (`0x31`) in T3. Durante BOOT la Control ROM 1 genera `0x00` e la
Control ROM 2 genera `0x49`: in particolare `/OE_RAM` (ROM2 `D3`) deve restare
alto per evitare che la RAM piloti il bus dati insieme alla EPROM.

| Fase BOOT | ROM1 `D7..D0` | ROM2 `D7..D0` |
| --- | :---: | :---: |
| T1 | `00000000` | `01001001` |
| T2 | `00000000` | `01001001` |
| T3 | `00000000` | `01001001` |

La sequenza della scrittura RAM e `+5 V → 0 V → +5 V` su `/WE_RAM`:
T3 della copia precedente = alto, T1 = basso, T2 = alto. Il dato della EPROM
pilota il bus in T1, T2 e T3. Dopo l'incremento del PC, in T3 l'EPROM puo
presentare gia il byte dell'indirizzo successivo; `/WE_RAM` e alto, quindi
questo byte non deve modificare la RAM.

### Programma EPROM usato per la prova

Il 23 settembre 2026 e stato assemblato
[`examples/assembly/demo.asm`](../examples/assembly/demo.asm) e caricato nella
EEPROM programma tramite Arduino. Il primo caricamento non ha superato il CRC
finale; il secondo ha superato il CRC e una rilettura indipendente ha confermato
tutti i 10 byte seguenti. La colonna dati indica sia il valore della EPROM
programma sia quello atteso nella RAM dopo la copia:

| Indirizzo `A15..A0` (16 bit) | Dato `D7..D0` (8 bit) |
| --- | --- |
| `0000 0000 0000 0000` | `0010 0000` |
| `0000 0000 0000 0001` | `0000 1010` |
| `0000 0000 0000 0010` | `0100 1000` |
| `0000 0000 0000 0011` | `0000 1001` |
| `0000 0000 0000 0100` | `0000 0000` |
| `0000 0000 0000 0101` | `0100 0001` |
| `0000 0000 0000 0110` | `0000 1001` |
| `0000 0000 0000 0111` | `0000 0000` |
| `0000 0000 0000 1000` | `0000 0001` |
| `0000 0000 0000 1001` | `0000 0000` |

Durante il BOOT i primi dieci byte della RAM devono diventare identici ai
valori della tabella, allo stesso indirizzo. Sono stati scritti soltanto gli
indirizzi `0x0000..0x0009` della EEPROM programma: gli altri byte mantengono il loro
contenuto precedente e non costituiscono un riferimento noto per questa prova.
Questa tabella documenta la **EEPROM programma gia caricata il 23 settembre**:
il byte `0x01` a `0x0008` era il vecchio `HLT`, ma con la nuova ISA e `NOP`.
Riassemblando `demo.asm` oggi, a `0x0008` viene generato `0x00`; la tabella
della prova fisica va aggiornata solo dopo un nuovo caricamento verificato.
Con il vecchio binario non presumere che il programma si fermi: dopo il NOP
il PC leggerebbe `counter` a `0x0009`, che il programma puo aver modificato.

## Operazioni e risultati dei test BOOT

- [ ] **Power-on reset esterno (schema proposto):** all'accensione misurare
  `/POR=0`, `PC=0`, `µSTEP=000` e `/WE_RAM` **sul pin della RAM** alto;
  dopo il rilascio di `/POR`, verificare `PC=0`, `µSTEP=000` e il primo
  avanzamento solo al clock successivo. Data/misura: _da compilare_.
- [ ] **Versione ROM0:** verificare `0x91`, `0xB5`, `0x31` rispettivamente in
  T1, T2, T3. Data/misura: _da compilare_.
- [ ] **Ingressi:** misurare `BOOT_RUN=0` e `A2:A1:A0 = 000 → 100 → 010` sui
  pin delle tre Control ROM. Data/misura: _da compilare_.
- [ ] **Selezione indirizzo:** verificare `D1:D0=01` in T1, T2 e T3 e che il
  bus indirizzi segua il PC. Data/misura: _da compilare_.
- [ ] **Scrittura:** misurare `/WE_RAM` direttamente sul pin della RAM:
  basso in T1, alto in T2 e T3; controllare che `/OE_EPROM` resti basso in
  tutte e tre le fasi. Data/misura: _da compilare_.
- [ ] **Bus dati:** con un byte EPROM noto e diverso da `0x00`, verificare che
  lo stesso byte sia presente sul bus in T1 e in T2 prima del clock che
  incrementa il PC. Data/misura: _da compilare_.
- [ ] **PC:** verificare che resti fermo durante T1, avanzi di uno al clock
  previsto in T2 e resti fermo in T3. Data/misura: _da compilare_.
- [ ] **Reset microstep:** verificare `D7=0` in T3 e il ritorno a T1.
  Data/misura: _da compilare_.
- [ ] **Dato memorizzato:** rileggere la RAM all'indirizzo precedente del PC e
  confrontarla con il byte della EPROM allo stesso indirizzo; ripetere su due
  indirizzi consecutivi. Data/misura: _da compilare_.

Se il bus appare a `0` in T3 quando il byte EPROM atteso e diverso da zero,
controllare `/OE_EPROM` e l'indirizzo presentato dal PC. Se la RAM cambia
contenuto in T2 o T3, misurare `/WE_RAM` sul pin della RAM e verificare che
`/OE_RAM` resti alto durante il BOOT. La prova sul clock del PC presuppone che
`PC_INC` sia campionato una sola volta; anche la durata del reset microstep
va confermata sulla scheda reale.

## RUN: ingressi e uscite di tutte le microsequenze cablate

Queste tabelle descrivono i **tre binari generati oggi**, non tutte le
distinzioni previste dall'ISA teorica. Su ciascuna ROM `A12=1` seleziona RUN,
`A11..A8=O,N,Z,C` sono i flag e `A7..A3=IR[7:3]` identificano il gruppo.
Per gli indirizzi numerici della tabella fissiamo `O=N=Z=C=0`, salvo le righe
esplicitamente indicate con `O=1`. Per qualsiasi altra combinazione di flag,
somma all'indirizzo indicato `0x100` se `C=1`, `0x200` se `Z=1`, `0x400` se
`N=1` e `0x800` se `O=1`. Le uscite restano uguali, tranne `PC_LOAD` nel
salto `JNO`.

Come in BOOT, i bit fisici `A2:A1:A0` sono nell'ordine
`µSTEP[0]:µSTEP[1]:µSTEP[2]`: `T1=000`, `T2=100`, `T3=010`, `T4=110`,
`T5=001`, `T6=101`. Dopo l'ultima operazione c'e un microstep dedicato che
attiva solo `NEXT_FETCH`: T3 per NOP/ALU/CMP/MOV, T4 per LDI/LDX/LDA-STA IDX,
T5 per i salti, T6 per LDA/STA diretti. **A T1 IR contiene ancora l'opcode
precedente**: il nuovo opcode viene acquisito al clock che chiude T1. Per
questo T1 e identico per tutti i gruppi; da T2 in poi `A7..A3` contiene il
gruppo della nuova istruzione.

Ogni byte di uscita sotto e il livello fisico dei pin `D7..D0`, non una lista
di segnali attivi. Le posizioni si leggono cosi (un nome con `/` e attivo a
`0`; gli altri segnali sono attivi a `1`):

| ROM | `D7` | `D6` | `D5` | `D4` | `D3` | `D2` | `D1` | `D0` |
| --- | --- | --- | --- | --- | --- | --- | --- | --- |
| 0 | `NEXT_FETCH_n` | `/OE_EPROM` | `/WE_RAM` | `/OE_MDR` | `MDR_WE` | `PC_INC` | `ADDR_SEL_1` | `ADDR_SEL_0` |
| 1 | `RB_EN` | `RA_RB_RW` | `RA_EN` | `RF_RW` | `RF_EN` | `MAR_L_WE` | `PC_LOAD` | `IR_WE` |
| 2 | riservato | `SYS_STEP_n` | `IDX_H_WE` | `IDX_L_WE` | `/OE_RAM` | `MAR_H_WE` | `FLAGS_WE` | `/OE_ALU` (`ALU_EN`) |

I pin DIP-28 corrispondenti a `D7..D0` sono `17,16,15,14,13,11,10,9`.
Le uscite della ROM non includono le ulteriori porte presenti sul cablaggio:
per esempio `/WE_RAM` **sul pin della RAM** puo essere forzato alto dalla
logica di protezione indirizzi/reset anche quando ROM0 `D5=0`.

### Istruzioni e segnali di sistema: HLT, NOP, reset e ritorno al fetch

Gli opcode di sistema **implementati** sono `HLT=0x00` (`00000000`) e
`NOP=0x01` (`00000001`); entrambi appartengono al gruppo CU
`IR[7:3]=00000`. Le Control ROM non ricevono `IR[2:0]`, quindi emettono
gli stessi byte per i due opcode. L'arresto di HLT non e un'uscita delle
EEPROM: ROM2 emette `SYS_STEP_n`, mentre la distinzione HLT/NOP avviene
nella logica cablata esterna, **da collegare e verificare sulla CPU fisica**.
I byte ROM qui sotto sono generati dal tool; il cablaggio di `µSTEP_EN` e
`/POR` e uno schema previsto, non una
misura gia confermata. Gli opcode `0x02..0x07` condividono per ora
la stessa sequenza delle ROM, ma sono riservati e non vanno considerati
istruzioni di sistema implementate. Anche `0x08..0x1F` sono riservati
nella ISA e nei binari attuali eseguono un NOP fisico come gruppo diverso.

I segnali coinvolti sono i seguenti; `µSTEP_EN` indica l'abilitazione al
conteggio del 74161, **non** il suo ingresso di clock.

| Segnale | Provenienza | Livello/effetto da verificare |
| --- | --- | --- |
| `BOOT_RUN` | esterno, EEPROM `A12` | `0` seleziona BOOT, `1` seleziona RUN; HLT deve agire solo in RUN. |
| `/POR` | circuito di reset esterno | Nello schema proposto, basso azzera PC e microstep tramite `/CLR` e inibisce `/WE_RAM` sul pin della RAM; non e un'uscita EEPROM. |
| `IR_WE` | ROM1 `D0` | Alto solo nel fetch T1: l'IR acquisisce il nuovo opcode al clock che chiude T1. |
| `PC_INC` | ROM0 `D2` | Alto nel fetch T1: il PC avanza anche quando l'opcode letto e HLT. |
| `/OE_RAM` | ROM2 `D3` | Basso nel fetch T1 per presentare l'opcode al bus dati; alto in T2/T3 di questo gruppo. |
| `NEXT_FETCH_n` | ROM0 `D7` | Alto in T1/T2; basso in T3 per chiedere il ritorno a T1. Con `/LOAD` del 74161 il ritorno avviene al clock che chiude T3. |
| `SYS_STEP_n` | ROM2 `D6`, pin 16 | Basso solo in RUN, gruppo `IR[7:3]=00000`, T2; alto durante BOOT, T1 e T3. |
| `µSTEP_EN` | OR esterno verso il 74161 | `1` lascia contare; `0` mantiene T2. Non interrompere direttamente il filo del clock. |

Formula della logica prevista, assumendo che non esistano altri motivi per
disabilitare il contatore:

```text
µSTEP_EN = SYS_STEP_n OR IR2 OR IR1 OR IR0
```

Il livello alto di `SYS_STEP_n` in T1 e indispensabile: dopo reset, o durante il fetch, l'IR puo
ancora contenere `0x00` **prima** di aver acquisito l'opcode corrente. Per
queste misure `O=N=Z=C=0`, dunque `A11..A8=0000`; i flag non cambiano le
uscite del gruppo di sistema. In T2/T3 `A7..A3=00000`; il valore fisico
`A2:A1:A0=100` corrisponde al T2 logico `001` per la mappatura attuale.

| Istruzione/fase | IR dopo il fetch | `BOOT_RUN` | `µSTEP[2:0]` | EEPROM `A2:A1:A0` | Indirizzo EEPROM con flag `0000` | `SYS_STEP_n` | `µSTEP_EN` |
| --- | :---: | :---: | :---: | :---: | ---: | :---: | :---: |
| Fetch comune T1 | precedente, poi nuovo al clock | 1 | `000` | `000` | `0x1000 + 8G_precedente` | 1 | 1 |
| HLT T2 | `00000000` | 1 | `001` | `100` | `0x1004` | 0 | 0 |
| NOP T2 | `00000001` | 1 | `001` | `100` | `0x1004` | 0 | 1 |
| NOP T3 | `00000001` | 1 | `010` | `010` | `0x1002` | 1 | 1 |
| Riservati `0x02..0x07`, T2/T3 | `00000xxx` | 1 | `001`/`010` | `100`/`010` | `0x1004`/`0x1002` | 0/1 | 1 |

Per HLT la riga T3 esiste **nel binario delle ROM**, ma non deve essere
raggiunta se l'OR e collegato: il contatore resta in T2. Per NOP T3 e
raggiunta e `NEXT_FETCH_n=0`; con `/LOAD` sincrono e dati paralleli `0000`,
il clock successivo riporta il microstep a T1. Se D7 e ancora collegato
a `/CLR` asincrono, il ritorno puo avvenire gia durante T3 e la durata
dell'impulso va misurata.

| Fase | ROM0 `D7..D0` | ROM1 `D7..D0` | ROM2 `D7..D0` | Controlli attivi della CU | Comportamento esterno |
| --- | :---: | :---: | :---: | --- | --- |
| T1, fetch comune | `11110101` (`0xF5`) | `00000001` (`0x01`) | `01000001` (`0x41`) | `ADDR_SEL=PC`, `/OE_RAM=0`, `IR_WE=1`, `PC_INC=1` | Il nuovo IR vale `0x00` o `0x01` solo **dopo** il clock; PC punta al byte seguente. |
| T2, HLT | `11110011` (`0xF3`) | `00000000` (`0x00`) | `00001001` (`0x09`) | Nessuna lettura/scrittura; `SYS_STEP_n=0` | `µSTEP_EN=0`: T2 resta stabile ai clock successivi. |
| T2, NOP | `11110011` (`0xF3`) | `00000000` (`0x00`) | `00001001` (`0x09`) | Identico a HLT per le EEPROM | `IR0=1` tiene `µSTEP_EN=1`: al clock il microstep diventa T3. |
| T3, NOP | `01110011` (`0x73`) | `00000000` (`0x00`) | `01001001` (`0x49`) | Solo `NEXT_FETCH_n=0`; nessuna scrittura | Il ritorno a T1 dipende dal collegamento `/LOAD` o `/CLR` del microstep. |

In T2 di HLT/NOP le uscite attive basse `/WE_RAM`, `/OE_EPROM`, `/OE_MDR`,
`/OE_RAM` e `/OE_ALU` sono tutte alte (inattive); `IR_WE`, `PC_INC`,
`PC_LOAD`, `MDR_WE`, `RF_EN`, `RA_EN`, `RB_EN`, `FLAGS_WE`, `MAR_*_WE` e
`IDX_*_WE` sono basse. Il PC ha gia avanzato in T1 e deve rimanere fermo
durante T2. Il reset `/POR` resta indipendente da HLT e deve poter
riportare PC e microstep allo stato iniziale.

Prove da registrare separatamente dalla tabella teorica:

- [ ] **Decode:** applicare `IR=0x00`, `RUN=1`, T2 e misurare `SYS_STEP_n=0` e
  `µSTEP_EN=0`; ripetere con `IR=0x01` e ottenere `SYS_STEP_n=0`, `µSTEP_EN=1`.
  Data/misura: _da compilare_.
- [ ] **Qualificatori:** con `IR=0x00`, verificare `SYS_STEP_n=1` durante BOOT e
  durante T1 RUN; con `IR=0x02..0x07`, verificare `SYS_STEP_n=0` ma `µSTEP_EN=1` in T2.
  Data/misura: _da compilare_.
- [ ] **HLT reale:** caricare un programma terminato da `0x00`; al fetch
  verificare `IR=0x00`, PC avanzato di uno e microstep bloccato in T2
  anche dopo altri fronti di clock, senza scritture RAM/registri.
  Data/misura: _da compilare_.
- [ ] **NOP reale:** con `0x01`, verificare T1 → T2 → T3 → T1 e il PC
  incrementato una sola volta; in T3 misurare ROM0 `D7=0`.
  Data/misura: _da compilare_.
- [ ] **Reset dall'arresto:** con HLT bloccato in T2, applicare `/POR=0` e
  verificare PC=0, microstep=000 e `/WE_RAM` fisico alto; dopo il rilascio
  ripartire dal fetch senza un arresto dovuto al vecchio contenuto dell'IR.
  Data/misura: _da compilare_.

La prova HLT richiede il **nuovo binario del programma**: la EEPROM
programma descritta nella tabella BOOT sopra contiene ancora `0x01` a
`0x0008` e quindi, con questa ISA, esegue NOP. Lo scambio di opcode non
modifica la sequenza dei due opcode, che condividono il gruppo CU. La nuova
uscita `SYS_STEP_n` modifica pero il binario di **ROM2**, da rigenerare e
riprogrammare prima della prova fisica; ROM0 e ROM1 non cambiano per questo.

### Tabella di verita RUN 1 — ingressi comuni alle tre EEPROM

In tutte le righe ordinarie `A12=1`, `A11..A8=0000`. La colonna
`µSTEP[2:0]` e il valore del contatore; `A2:A1:A0` mostra invece i livelli
che si misurano sui pin fisici delle EEPROM. `G` significa un qualsiasi
gruppo `IR[7:3]` a cinque bit. La riga T1 usa il gruppo **precedente**;
`0x1000` e solo l'esempio con gruppo precedente e flag entrambi a zero.

| Microsequenza | Fase | `µSTEP[2:0]` | `A7..A3` | `A2:A1:A0` | Indirizzo (flag indicati) |
| --- | :---: | :---: | :---: | :---: | ---: |
| Fetch comune | T1 | `000` | `G precedente` | `000` | `0x1000 + 8G` |
| HLT / NOP, uscite CU comuni | T2 | `001` | `00000` | `100` | `0x1004` |
| HLT / NOP, uscite CU comuni | T3 reset | `010` | `00000` | `010` | `0x1002` |
| LDI Rn, imm8 | T2 | `001` | `00100` | `100` | `0x1024` |
| LDI Rn, imm8 | T3 | `010` | `00100` | `010` | `0x1022` |
| LDI Rn, imm8 | T4 reset | `011` | `00100` | `110` | `0x1026` |
| LDA Rn, [addr16] | T2 | `001` | `01000` | `100` | `0x1044` |
| LDA Rn, [addr16] | T3 | `010` | `01000` | `010` | `0x1042` |
| LDA Rn, [addr16] | T4 | `011` | `01000` | `110` | `0x1046` |
| LDA Rn, [addr16] | T5 | `100` | `01000` | `001` | `0x1041` |
| LDA Rn, [addr16] | T6 reset | `101` | `01000` | `101` | `0x1045` |
| STA Rn, [addr16] | T2 | `001` | `01001` | `100` | `0x104C` |
| STA Rn, [addr16] | T3 | `010` | `01001` | `010` | `0x104A` |
| STA Rn, [addr16] | T4 | `011` | `01001` | `110` | `0x104E` |
| STA Rn, [addr16] | T5 | `100` | `01001` | `001` | `0x1049` |
| STA Rn, [addr16] | T6 reset | `101` | `01001` | `101` | `0x104D` |
| LDA Rn, [IDX] | T2 | `001` | `01010` | `100` | `0x1054` |
| LDA Rn, [IDX] | T3 | `010` | `01010` | `010` | `0x1052` |
| LDA Rn, [IDX] | T4 reset | `011` | `01010` | `110` | `0x1056` |
| STA Rn, [IDX] | T2 | `001` | `01011` | `100` | `0x105C` |
| STA Rn, [IDX] | T3 | `010` | `01011` | `010` | `0x105A` |
| STA Rn, [IDX] | T4 reset | `011` | `01011` | `110` | `0x105E` |
| ALU | T2 | `001` | `01100` | `100` | `0x1064` |
| ALU | T3 reset | `010` | `01100` | `010` | `0x1062` |
| SUB (`0x78`) | T2 | `001` | `01111` | `100` | `0x107C` |
| SUB (`0x78`) | T3 reset | `010` | `01111` | `010` | `0x107A` |
| CMP | T2 | `001` | `01101` | `100` | `0x106C` |
| CMP | T3 reset | `010` | `01101` | `010` | `0x106A` |
| JMP addr16 | T2 | `001` | `10100` | `100` | `0x10A4` |
| JMP addr16 | T3 | `010` | `10100` | `010` | `0x10A2` |
| JMP addr16 | T4 | `011` | `10100` | `110` | `0x10A6` |
| JMP addr16 | T5 reset | `100` | `10100` | `001` | `0x10A1` |
| JNO addr16, `O=0` | T2 | `001` | `10101` | `100` | `0x10AC` |
| JNO addr16, `O=0` | T3 | `010` | `10101` | `010` | `0x10AA` |
| JNO addr16, `O=0` | T4 | `011` | `10101` | `110` | `0x10AE` |
| JNO addr16, `O=0` | T5 reset | `100` | `10101` | `001` | `0x10A9` |
| JNO addr16, `O=1` | T2 | `001` | `10101` | `100` | `0x18AC` |
| JNO addr16, `O=1` | T3 | `010` | `10101` | `010` | `0x18AA` |
| JNO addr16, `O=1` | T4 | `011` | `10101` | `110` | `0x18AE` |
| JNO addr16, `O=1` | T5 reset | `100` | `10101` | `001` | `0x18A9` |
| MOV RA, Rn | T2 | `001` | `11000` | `100` | `0x10C4` |
| MOV RA, Rn | T3 reset | `010` | `11000` | `010` | `0x10C2` |
| MOV RB, Rn | T2 | `001` | `11001` | `100` | `0x10CC` |
| MOV RB, Rn | T3 reset | `010` | `11001` | `010` | `0x10CA` |
| MOV Rn, RA | T2 | `001` | `11010` | `100` | `0x10D4` |
| MOV Rn, RA | T3 reset | `010` | `11010` | `010` | `0x10D2` |
| LDX addr16 | T2 | `001` | `11011` | `100` | `0x10DC` |
| LDX addr16 | T3 | `010` | `11011` | `010` | `0x10DA` |
| LDX addr16 | T4 reset | `011` | `11011` | `110` | `0x10DE` |
| Altri gruppi (NOP fisico) | T2 | `001` | `G altro` | `100` | `0x1004 + 8G` |
| Altri gruppi (NOP fisico) | T3 reset | `010` | `G altro` | `010` | `0x1002 + 8G` |
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

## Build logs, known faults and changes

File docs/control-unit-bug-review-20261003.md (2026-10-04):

# Verifica del generatore e dei binari CU — 3 ottobre 2026

Verificata la copia di lavoro corrente, comprese le modifiche locali. Non
modificati sorgenti di produzione, test del repository o immagini destinate
alle EEPROM. Le prove con configurazioni alterate sono isolate in
`/tmp/cpu8-review-20261003`.

## Aggiornamento dopo conferma del cablaggio

Il proprietario ha confermato PC_LOAD attivo basso e ha riprogrammato soltanto
ROM1. La configurazione del generatore è quindi corretta; il punto 1 sotto
era una discordanza dei test e della documentazione, non un bug del binario.
Test CU, audit indipendente e tabella delle uscite sono stati allineati.
I test CU e l’audit delle 8192 parole/1376 sequenze passano nel repository.
La sola inversione di PC_LOAD cambia esclusivamente ROM1: non richiede
la riprogrammazione di ROM0 o ROM2. Il contenuto reale di ROM2 resta da
verificare per diagnosticare l’arresto prima del fetch.

## Esito iniziale

La tabella HLT non arresta la CPU al primo microstep. Le microsequenze stabili
sono coerenti con l'ISA documentata se PC_LOAD viene interpretato attivo basso.
Esistono però una discordanza di polarità fra sorgente e specifica, due difetti
degli strumenti e rischi temporali non risolti. Non è dimostrata la correttezza
elettrica del sistema o il contenuto delle EEPROM montate sulla CPU.

## Risultati e riproduzione

- Ricompilazione forzata del generatore: riuscita.
- Test CU originali: falliscono in `test_microcode.c:273` (SUB ROM1 atteso
  `60`, effettivo `62`).
- Test CU in copia temporanea: tutti passano dopo aver cambiato solo le attese
  conseguenti alla polarità PC_LOAD (`60→62`, `00→02`, decodifica del bit
  PC_LOAD invertita). Nessuna microsequenza modificata.
- Audit indipendente dei binari esistenti: fallisce con la mappa originale
  PC_LOAD attivo alto. In copia temporanea, cambiando soltanto la polarità
  di PL a basso, passa su 8192 parole, 86 opcode ISA × 16 flag = 1376 sequenze,
  tutti gli otto step, BOOT e HLT per tutti i 256 opcode.
- Rigenerazione in `/tmp`: identica byte per byte alle tre immagini esistenti.
- Test assembler: passano; simulatore web: 21/21; modello supervisore BOOT: 4/4.
  Questi ultimi controlli non simulano il timing dei binari sulla scheda.

```sh
make -B -C tools/cu-bytecode all test
tools/cu-bytecode/build/cpu8microcode -o /tmp/cpu8-review-20261003/microcode
python3 tools/cu-bytecode/tests/audit_rom_timing.py tools/cu-bytecode/build/microcode
python3 /tmp/cpu8-review-20261003/audit_rom_timing.py tools/cu-bytecode/build/microcode
make -C /tmp/cpu8-review-20261003/cu test
make -C tools/assembler test
npm --prefix tools/simulator-web test
python3 tools/cu-bytecode/tests/test_boot_supervisor.py
```

## 1. Polarità PC_LOAD incoerente — priorità alta

`config/control_signals.c:55` configura ROM1 D1 ACTIVE_LOW. La tabella
`docs/control-unit-eeprom-output-map.md:74`, i test e l'audit originale lo
interpretano ACTIVE_HIGH. La differenza rispetto alla polarità alta è D1
invertito in tutte le 8192 celle di ROM1. Gli hash di ROM0 e ROM2 coincidono
con quelli del precedente audit del 28 settembre; ROM1 è diversa.

Se il circuito richiede un comando alto, ROM1 carica il PC nei passi sbagliati
e non lo carica nei salti presi. Se D1 pilota un ingresso di caricamento attivo
basso direttamente, la configurazione può essere corretta: in quel caso sono
test, audit e documentazione da aggiornare. Non scegliere una polarità senza
verificare il percorso elettrico D1→PC e gli eventuali inverter.

Questo difetto non modifica D6 di ROM2 e non dimostra la causa dell'HLT precoce.

## 2. STA/STAI: indirizzo e dato rilasciati insieme alla chiusura di /WE

`src/microcode.c:268` e `:315`: STA T5 e STAI T3 selezionano MAR/IDX,
abilitano MDR e attivano RAM_WE contemporaneamente. Nel passo successivo,
NEXT_FETCH disabilita la scrittura e rilascia indirizzo e dato nella stessa
transizione. Manca una fase esplicita di preparazione e mantenimento dei bus.

L'audit segnala entrambe le transizioni. È un rischio temporale concreto,
non una prova di corruzione: la sua manifestazione dipende dai ritardi reali.
Preparazione → scrittura → chiusura con bus mantenuti → ritorno rientra negli
otto step, ma serve anche qualificare /WE contro i transitori delle ROM.

## 3. Configurazione degli indirizzi non validata — difetto riprodotto

`validate_signal_config()` verifica le uscite ma non verifica che i 13
ingressi indirizzo siano una permutazione completa di segnali e pin validi.
`microcode_address()` ignora un pin sconosciuto e combina duplicati con OR.
`build_control_roms()` non rileva celle duplicate o mancanti; il buffer nel
main non è inizializzato.

In copia temporanea, assegnando µSTEP0 allo stesso pin di µSTEP1:
validazione e generazione restituiscono successo, ma 4096 celle di ROM0
rimangono al valore sentinella precedente alla generazione. Nel main tali
celle possono contenere dati indeterminati. La configurazione attuale non
presenta duplicati: questo non altera i tre binari verificati oggi.

Correzione: validare unicità, completezza e validità degli ingressi e verificare
che ogni indirizzo sia scritto esattamente una volta.

## 4. Dipendenze Make incomplete — difetto riprodotto

`Makefile:24` non include `include/microcode.h` nelle dipendenze degli oggetti
di produzione; `:34` non lo include nelle dipendenze del test. Anche
`include/output.h` manca per i consumatori.

In copia temporanea, dopo build completa, aggiornare il timestamp di
microcode.h fa ricompilare solo control_signals.o e rilinkare il generatore:
microcode.o, main.o e il test restano vecchi. Modificare enum o maschere nel
header può quindi produrre un eseguibile incoerente e riutilizzare test vecchi.
La ricompilazione forzata eseguita oggi esclude questo problema dai binari
esaminati. Usare dipendenze automatiche o elencare tutti gli header consumati.

## HLT e ordine dei microstep

Cablaggio previsto: A0=µSTEP2, A1=µSTEP1, A2=µSTEP0. Gli offset fisici dei
passi logici 0..7 sono `0,4,2,6,1,5,3,7`, non `0,1,2,3,4,5,6,7`.

Esempio RUN, IR=00, flag=0:

| µSTEP logico | Nome progetto | Indirizzo EEPROM | ROM0 | ROM1 | ROM2 | D6 ROM2 |
| --- | --- | --- | --- | --- | --- | --- |
| 000 | T1 (fetch; T0 nella domanda) | 1000 | F5 | 03 | 41 | 1 |
| 001 | T2 (HLT) | 1004 | F3 | 02 | 09 | 0 |
| 010 | T3 (ritorno NOP) | 1002 | 73 | 02 | 49 | 1 |

D6 è alto in tutto BOOT e in tutti i fetch, per ogni IR e flag. È basso solo
nel secondo passo RUN del gruppo IR[7:3]=00000. La OR con IR[2:0] arresta
soltanto opcode 00. Pertanto l'arresto con µSTEP realmente 000 non è causato
da un byte HLT errato in questa ROM2. Restano da misurare i livelli ai pin,
verificare il contenuto del chip montato e gli ingressi del contatore.

## Questioni che richiedono lo schema o misure

- Enable grezzi delle ROM combinati con clock mediante AND possono generare
  fronti locali aggiuntivi se cambiano mentre il clock è alto. È già descritto
  nell'audit temporale del 28 settembre; i test funzionali non lo escludono.
- CMP abilita solo FLAGS_WE: valido se i flag sono disponibili sul risultato
  ALU interno con il buffer CPU disabilitato; da verificare sul circuito.
- Il cambio BOOT→RUN non azzera autonomamente PC e microstep nel microcodice:
  richiede il controllo/reset esterno documentato. Il modello del supervisore
  non prova che il circuito reale implementi tale passaggio.

## Identificazione delle immagini esaminate

Tutte da 8192 byte. SHA-256:

```text
ROM0 bcd68d8330227aaab5fe3195cb19cef1b6a31963cf08d59ad3ec47118bd2fff3
ROM1 16f14126654ba83568b82573219d1dd35ba458f64795f2503c81eea46d5dc114
ROM2 f0748d039591f55060a6eab2e96dd69f5fdd4f9bc5aef1a25f6c2ea12115c01d
```

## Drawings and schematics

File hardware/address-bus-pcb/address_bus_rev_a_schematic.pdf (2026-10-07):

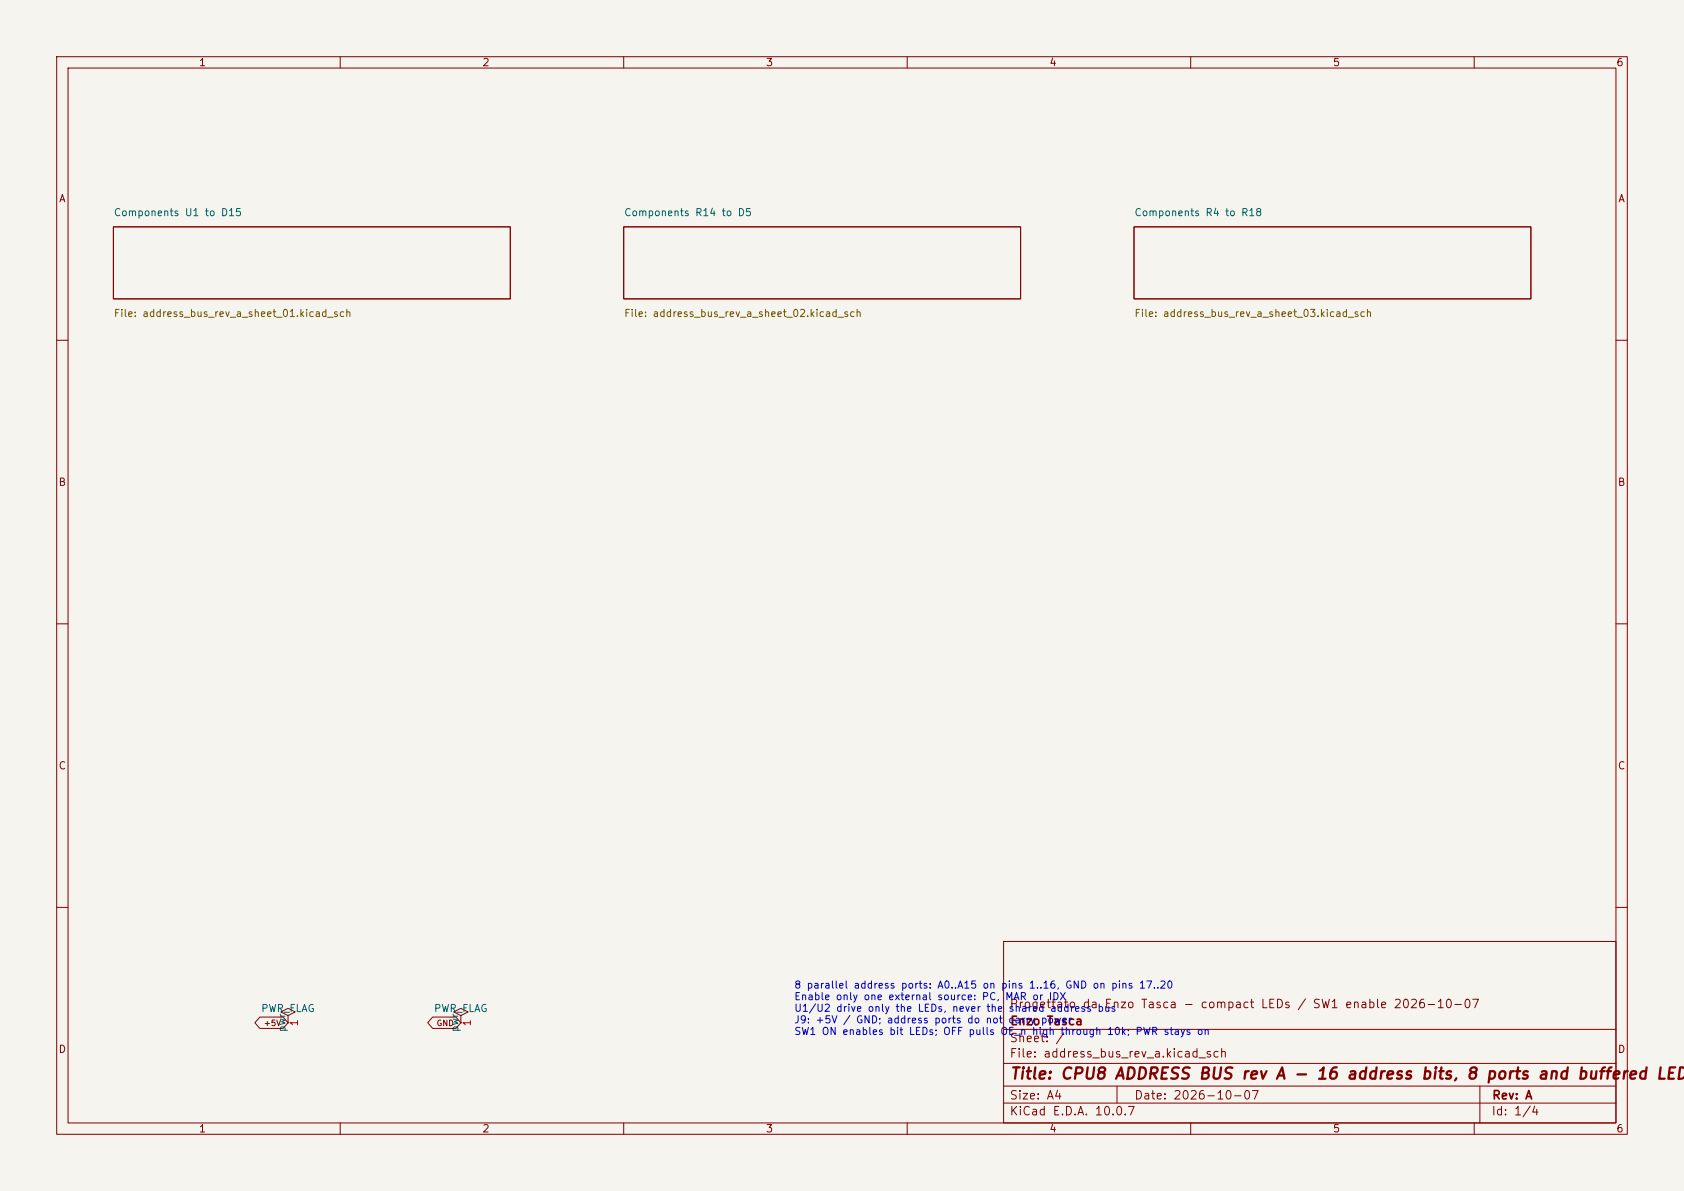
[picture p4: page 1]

Progettato da Enzo Tasca - compact LEDs / SW1 enable 2026-10-07
Enzo Tasca
Sheet: /
File: address_bus_rev_a.kicad_sch
Title: CPU8 ADDRESS BUS rev A - 16 address bits, 8 ports and buffered LEDs

Size: A4 | Rev: A
KiCad E.D.A. 10.0.7 | Id: 1/4

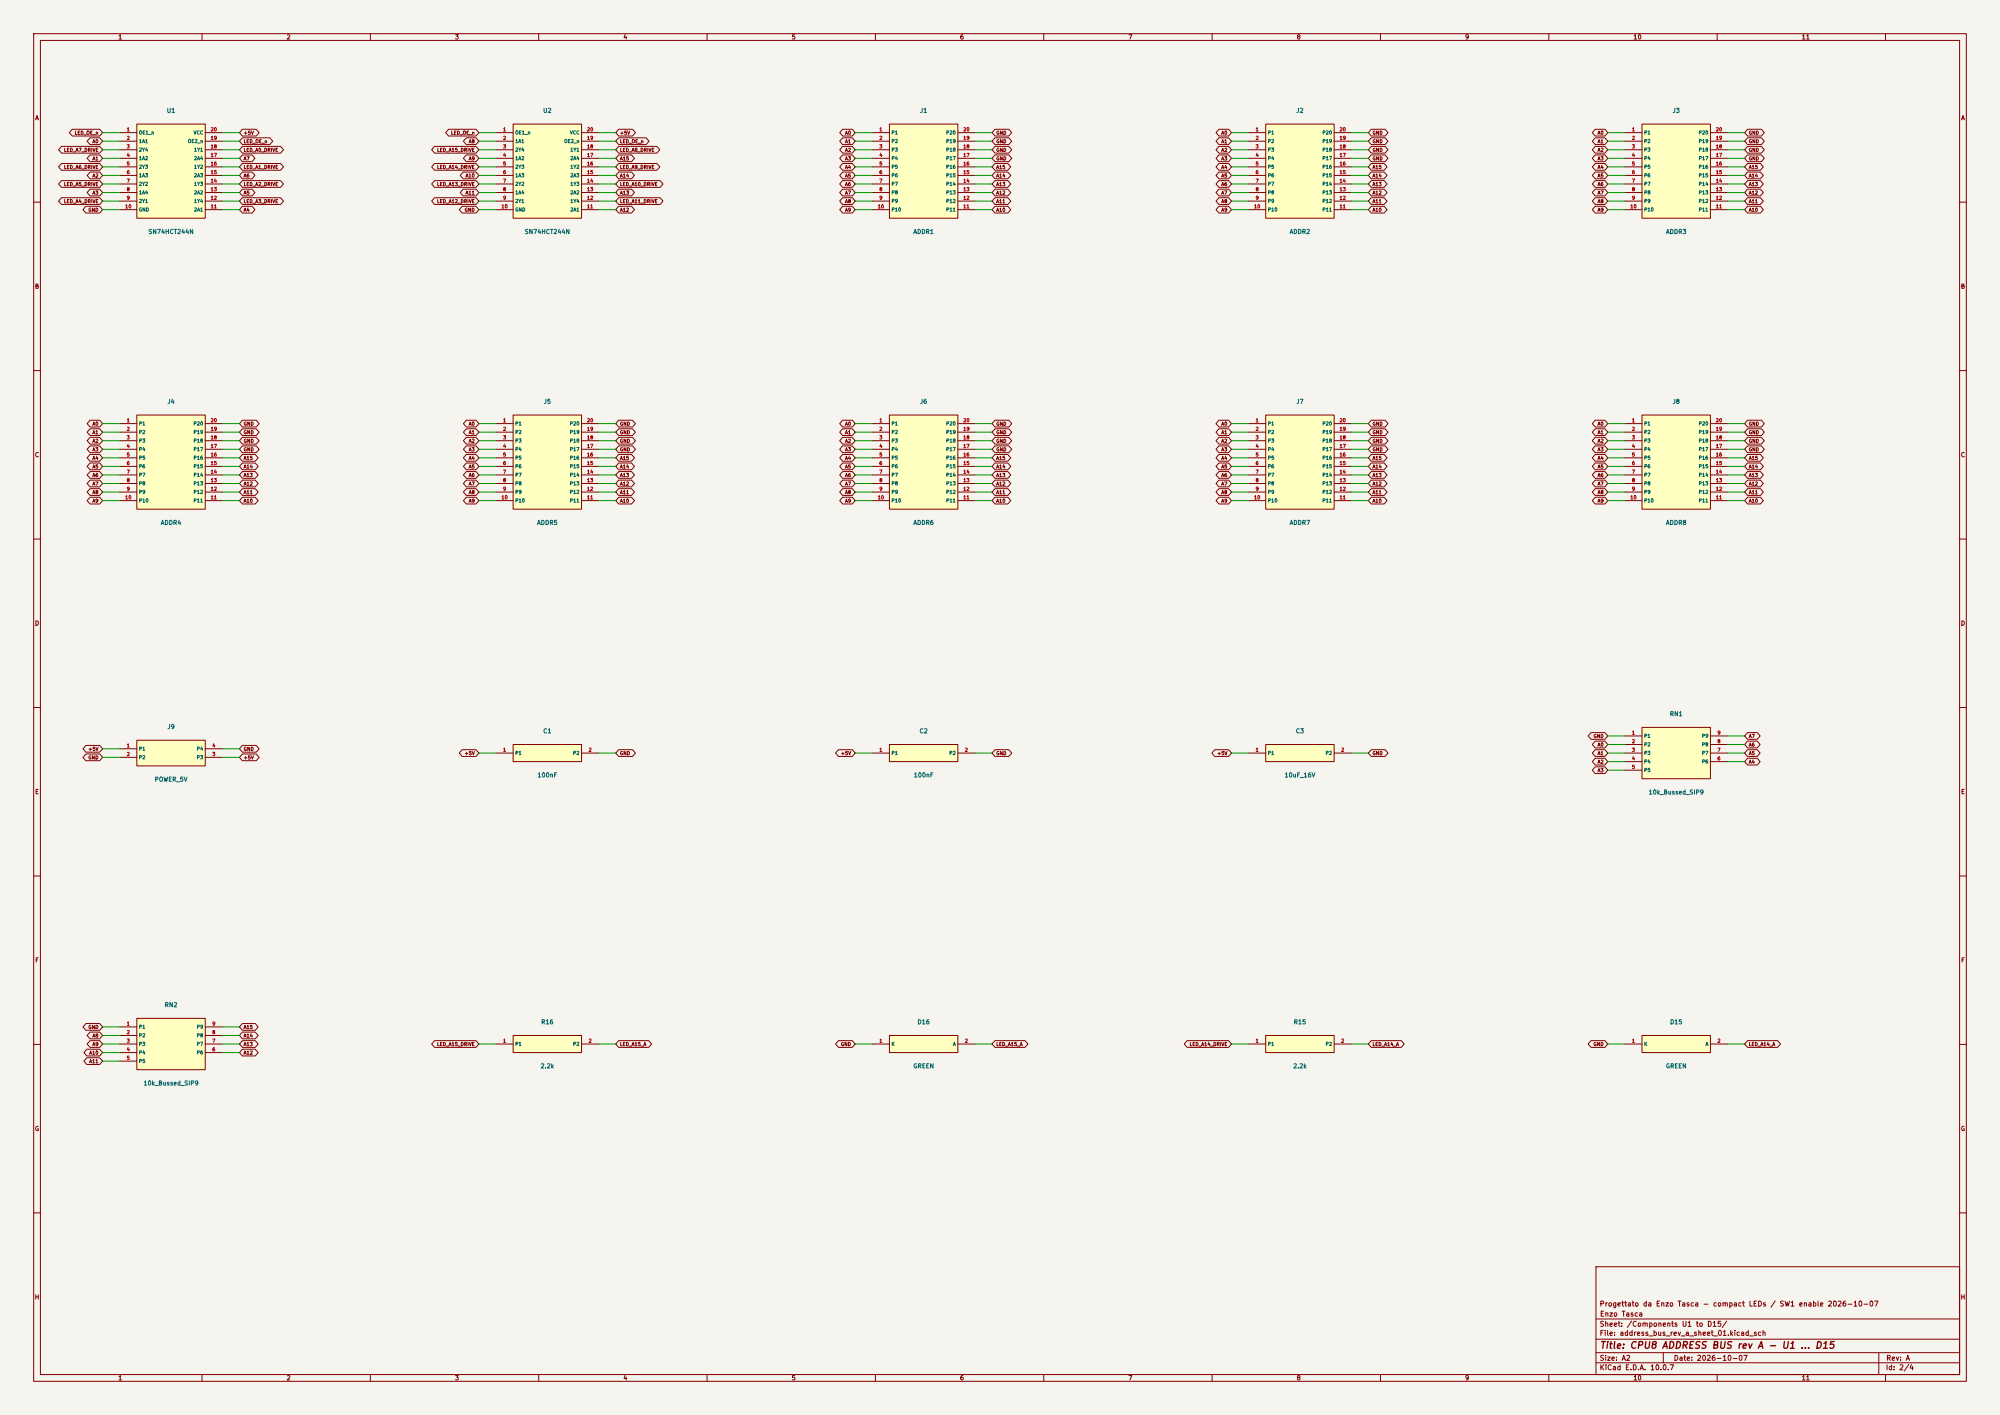
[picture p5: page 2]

Progettato da Enzo Tasca - compact LEDs / SW1 enable 2026-10-07
Enzo Tasca
Sheet: /Components U1 to D15/
File: address_bus_rev_a_sheet_01.kicad_sch
Title: CPU8 ADDRESS BUS rev A - U1 ... D15

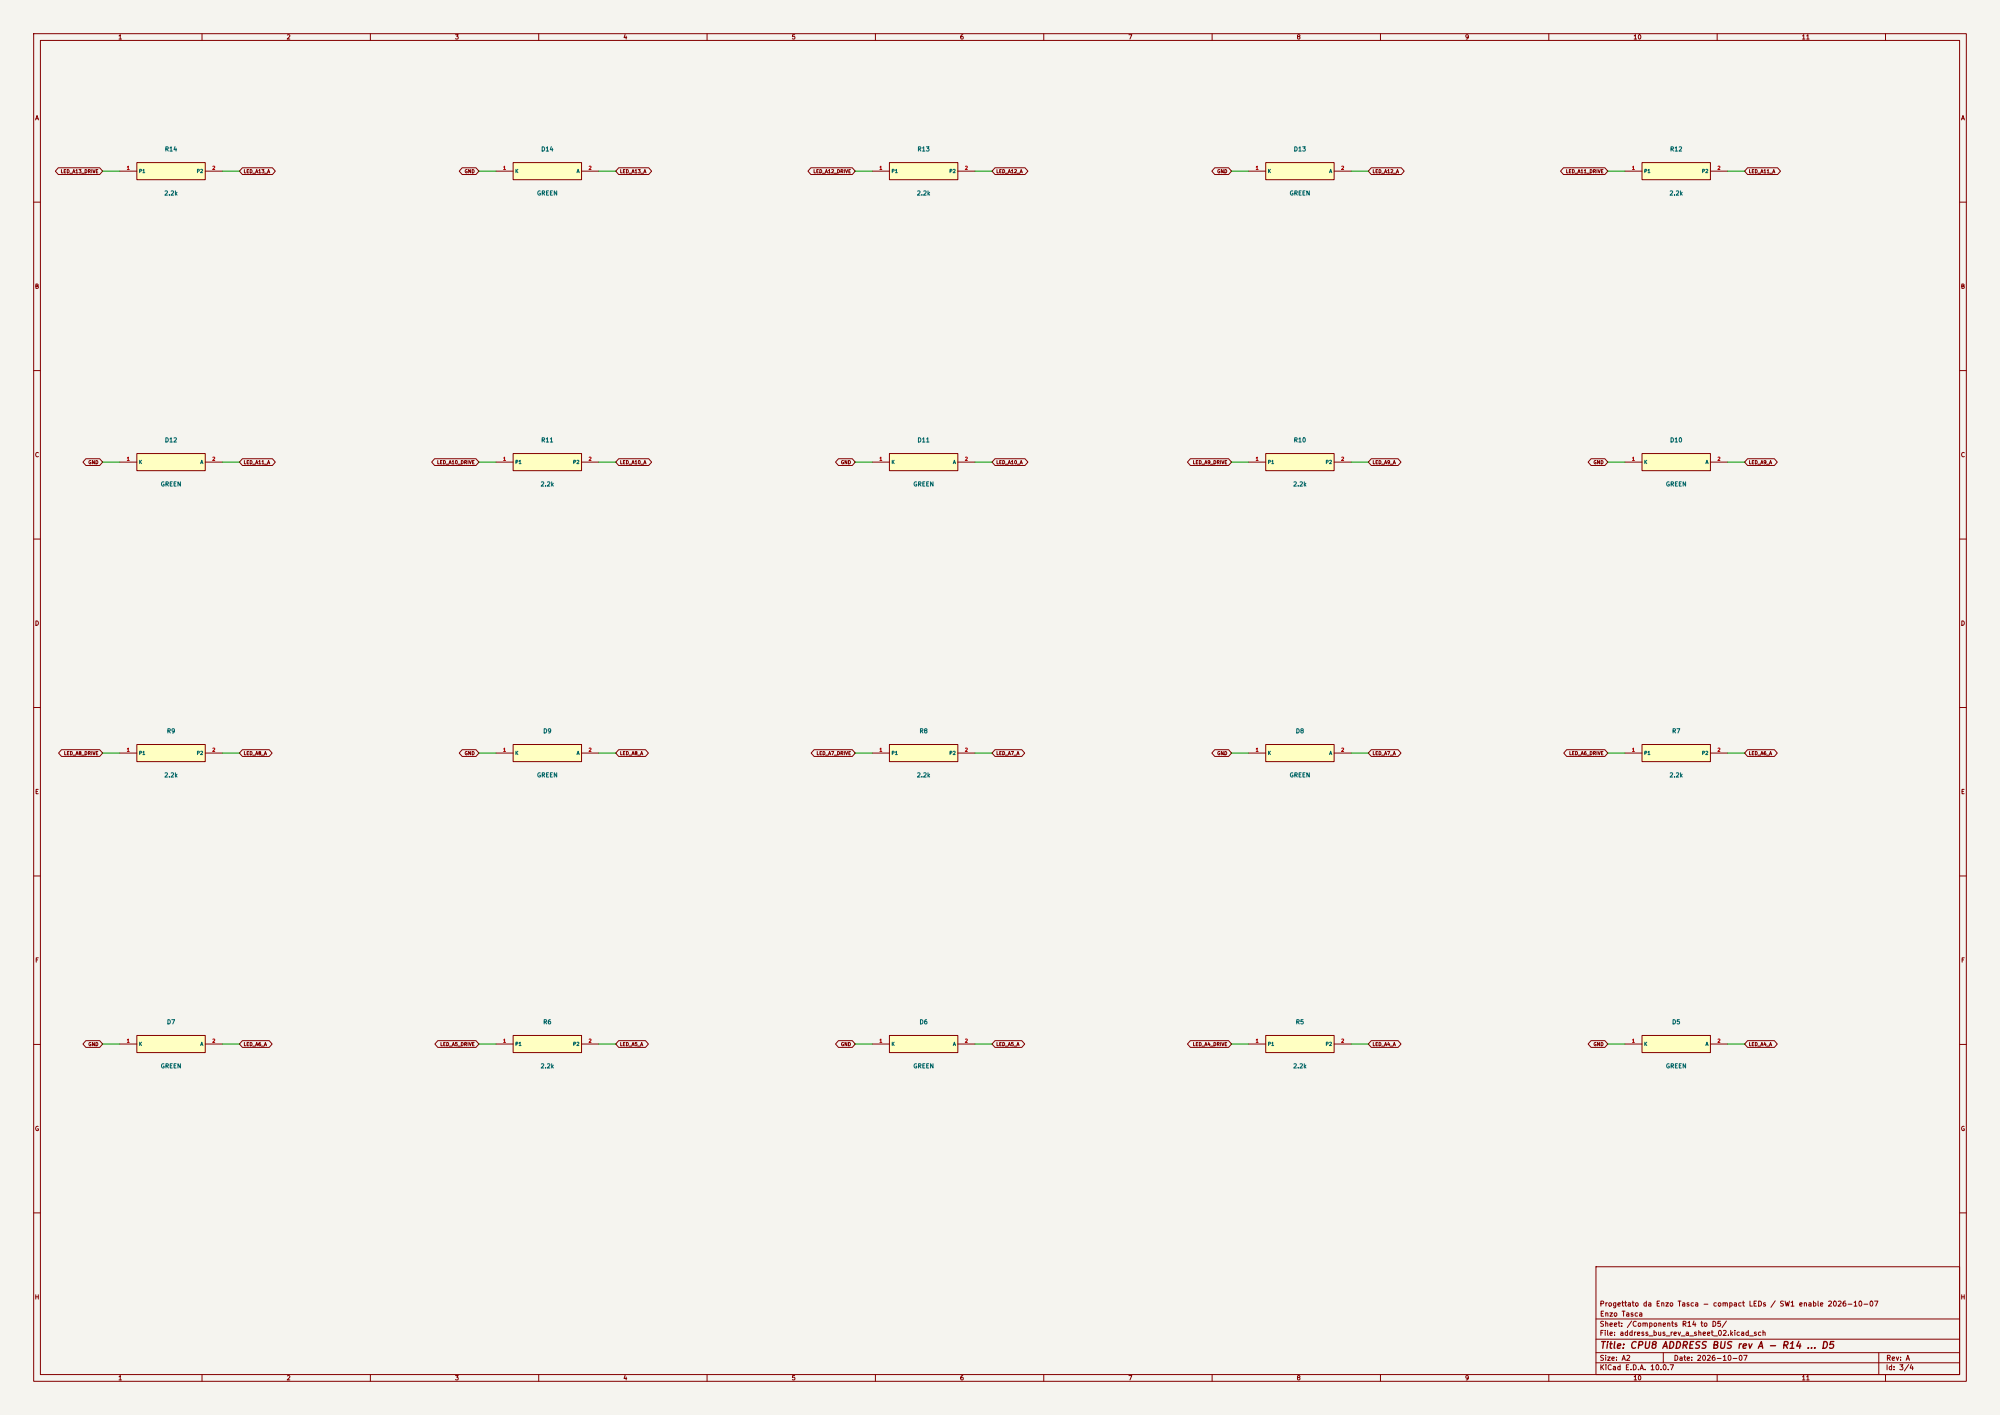
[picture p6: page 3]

Sheet: /Components R14 to D5/
File: address_bus_rev_a_sheet_02.kicad_sch
Title: CPU8 ADDRESS BUS rev A - R14 ... D5

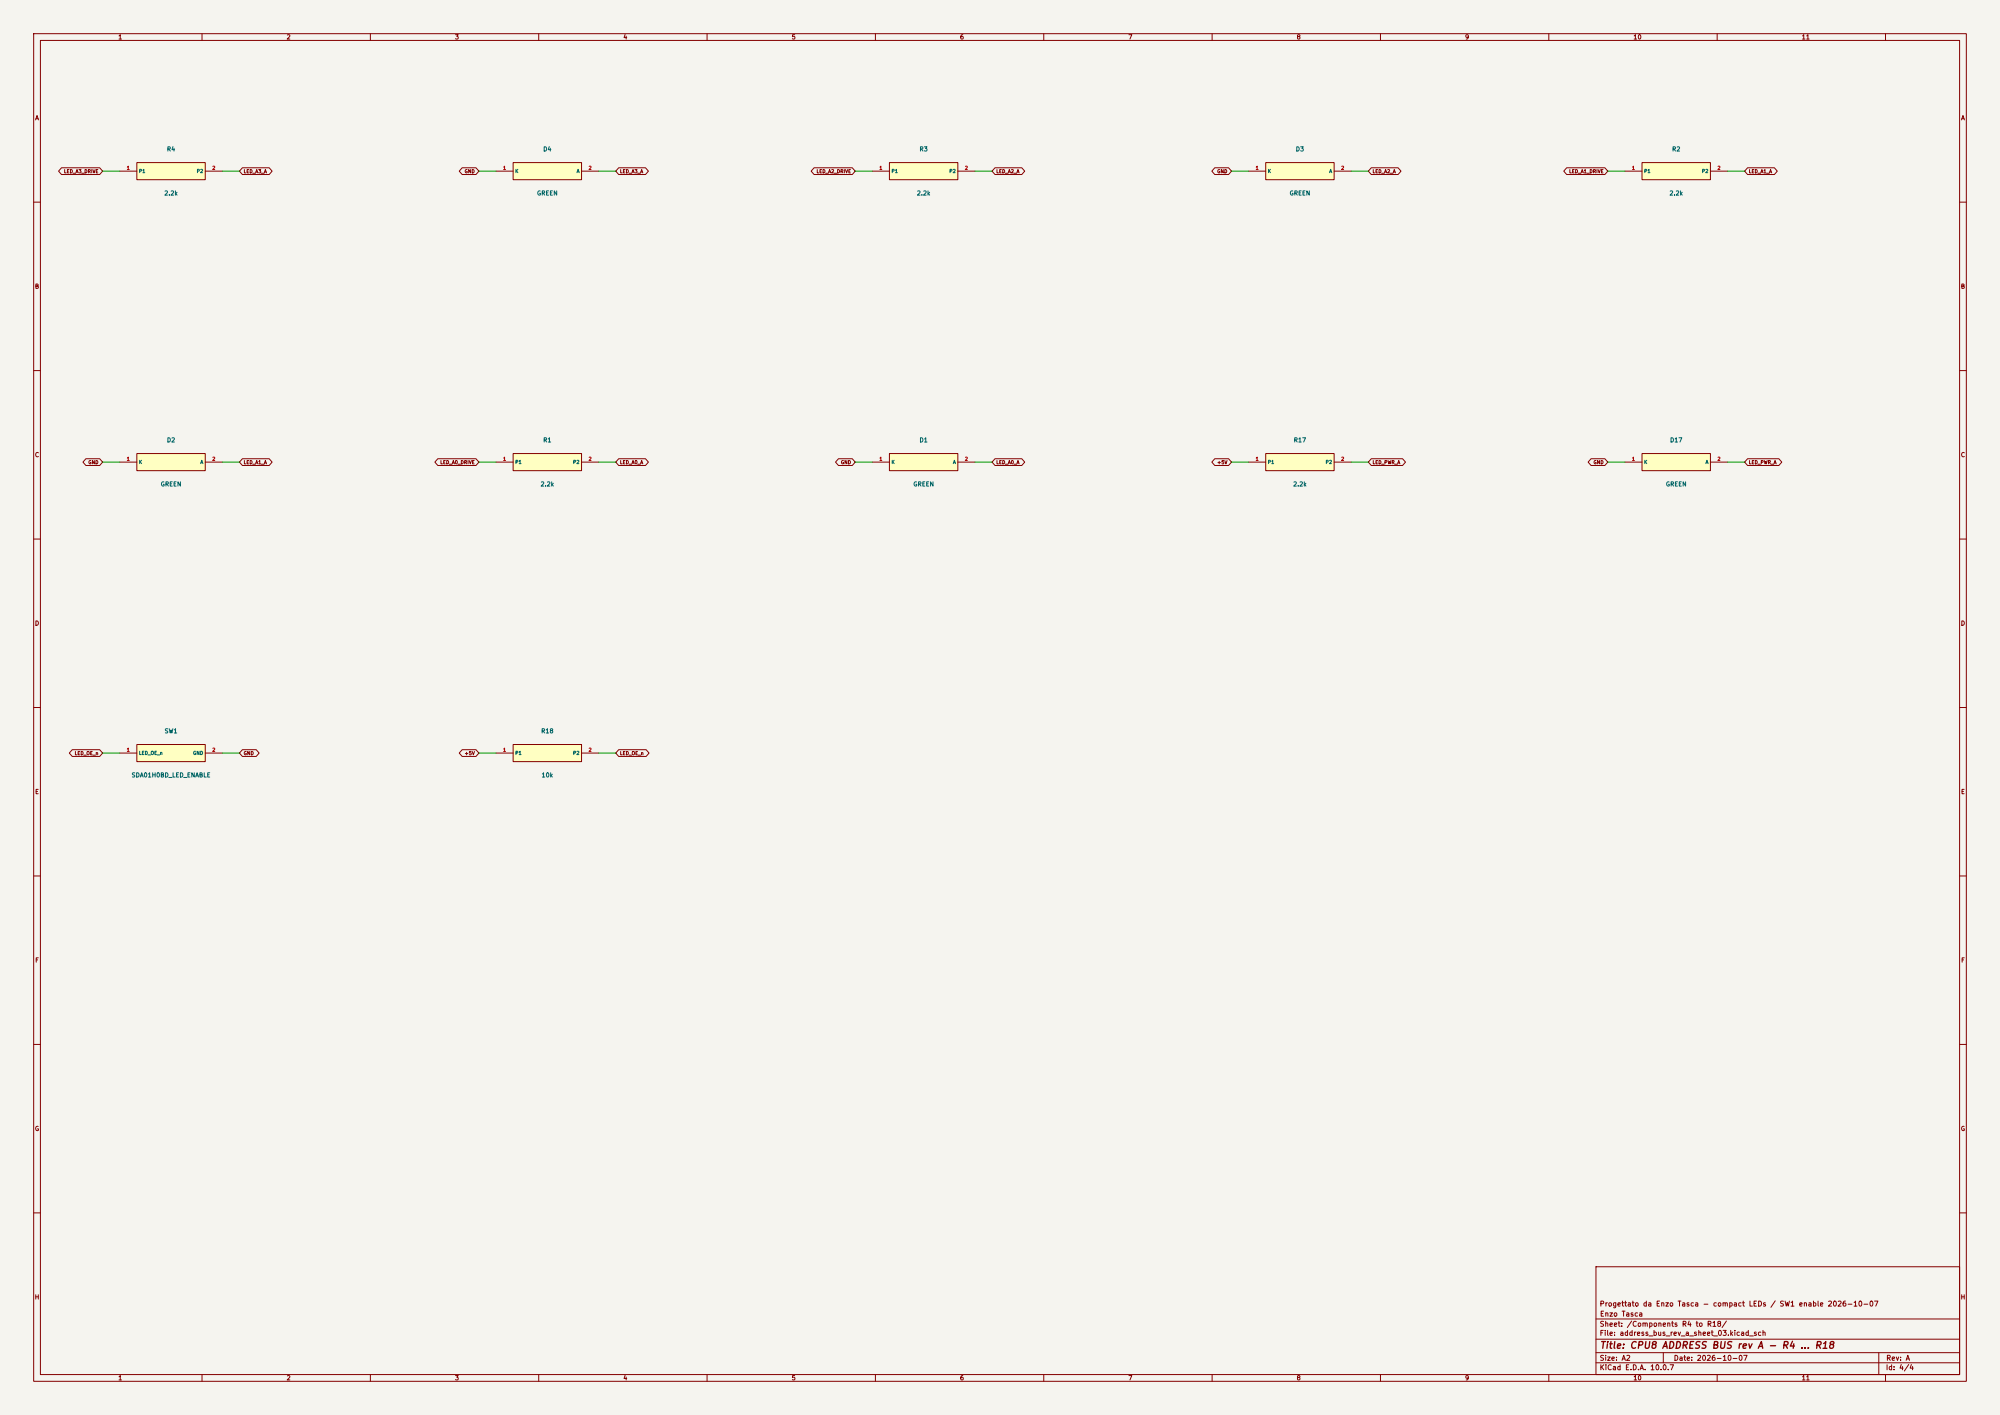
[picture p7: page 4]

Sheet: /Components R4 to R18/
File: address_bus_rev_a_sheet_03.kicad_sch
Title: CPU8 ADDRESS BUS rev A - R4 ... R18

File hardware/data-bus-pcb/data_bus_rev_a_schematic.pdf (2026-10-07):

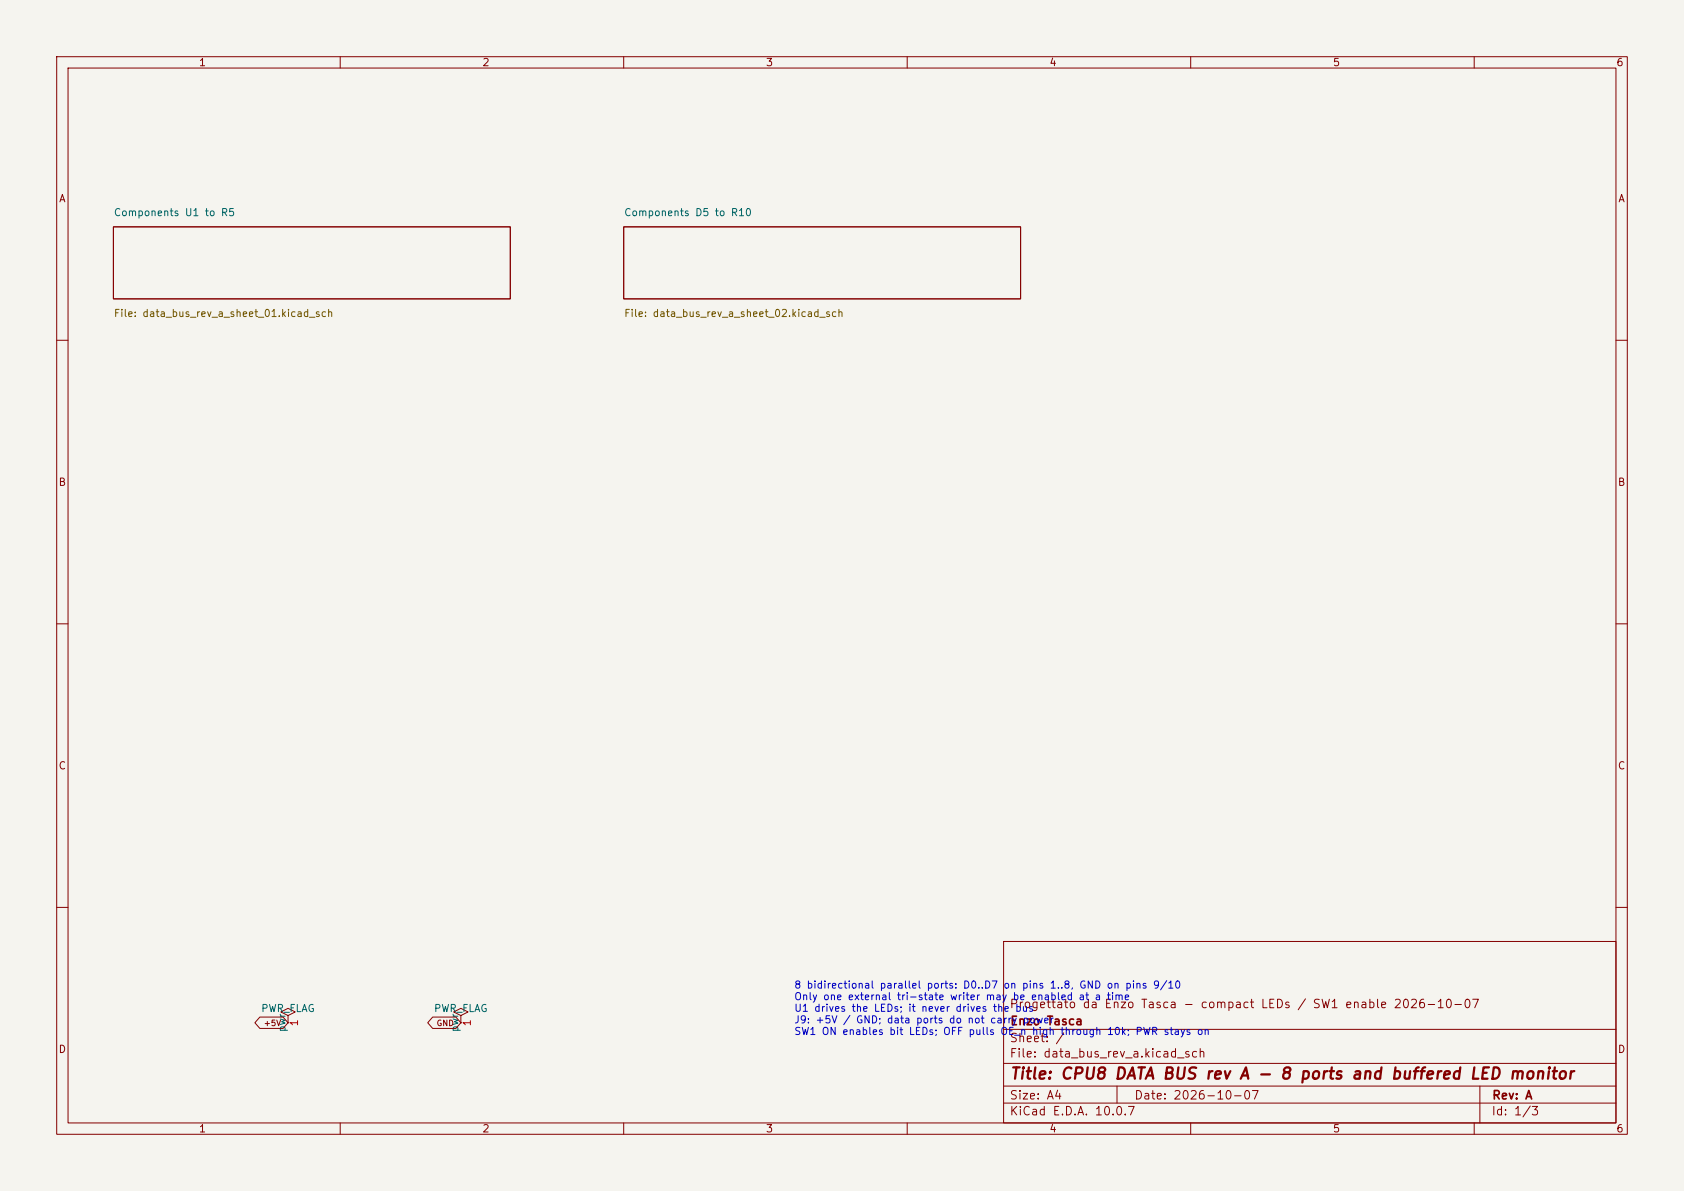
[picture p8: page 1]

Only one external tri-state writer may be enabled at a time U1 drives the LEDs; it never drives the bus

Progettato da Enzo Tasca - compact LEDs / SW1 enable 2026-10-07
Enzo Tasca
Sheet: /
File: data_bus_rev_a.kicad_sch
Title: CPU8 DATA BUS rev A - 8 ports and buffered LED monitor

J9: +5V / GND; data ports do not carry power SW1 ON enables bit LEDs; OFF pulls OE_n high through 10k; PWR stays on

Size: A4 | Rev: A
KiCad E.D.A. 10.0.7 | Id: 1/3

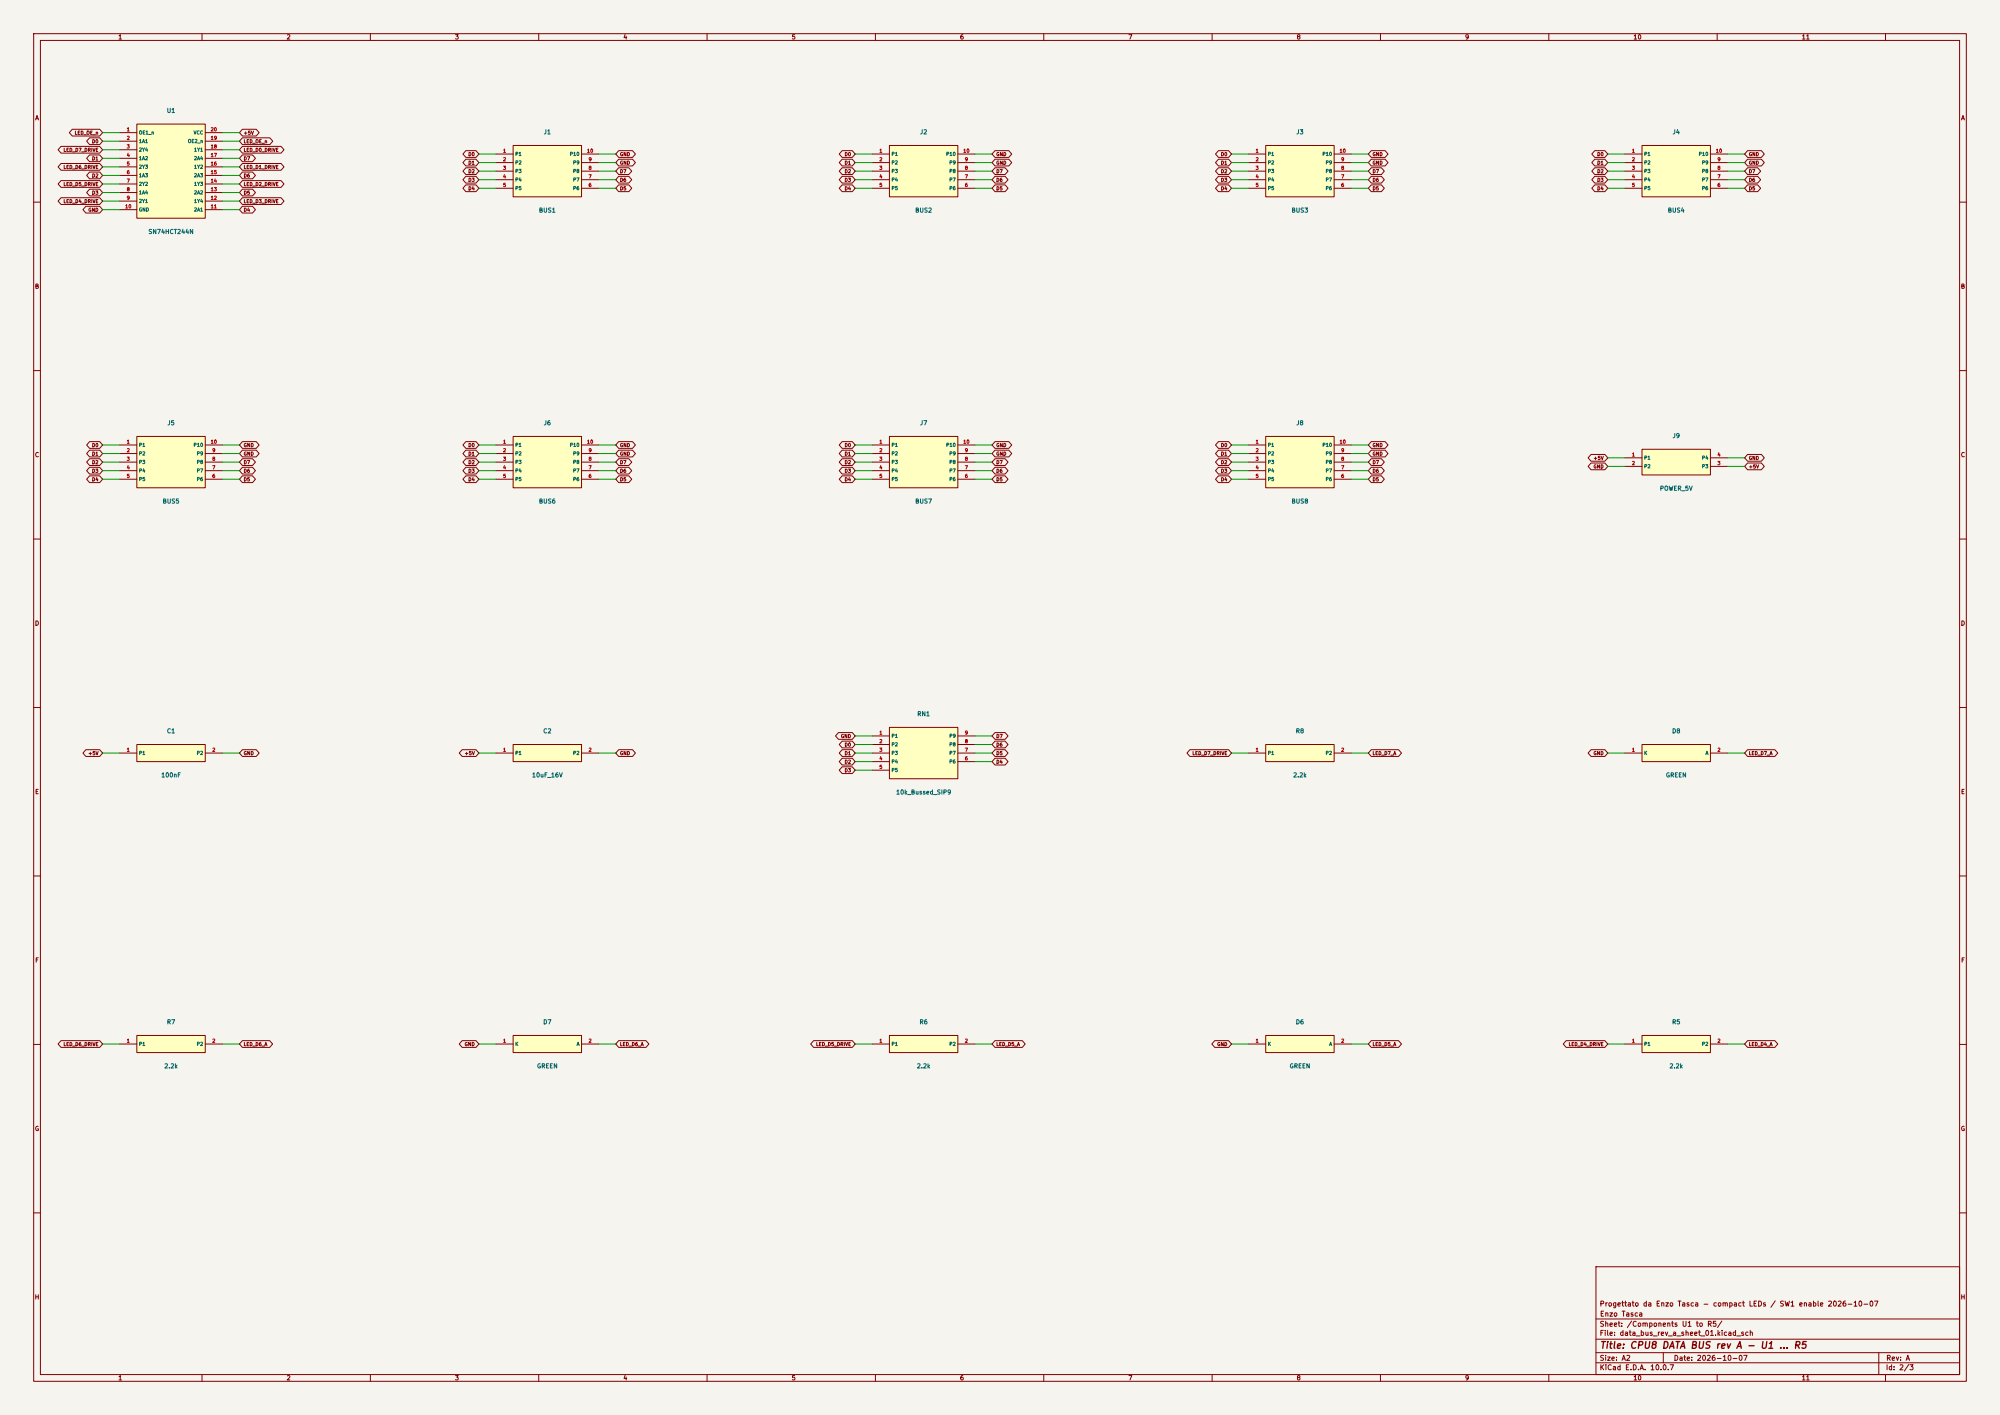
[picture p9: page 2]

Progettato da Enzo Tasca - compact LEDs / SW1 enable 2026-10-07
Enzo Tasca
Sheet: /Components U1 to R5/
File: data_bus_rev_a_sheet_01.kicad_sch
Title: CPU8 DATA BUS rev A - U1 ... R5

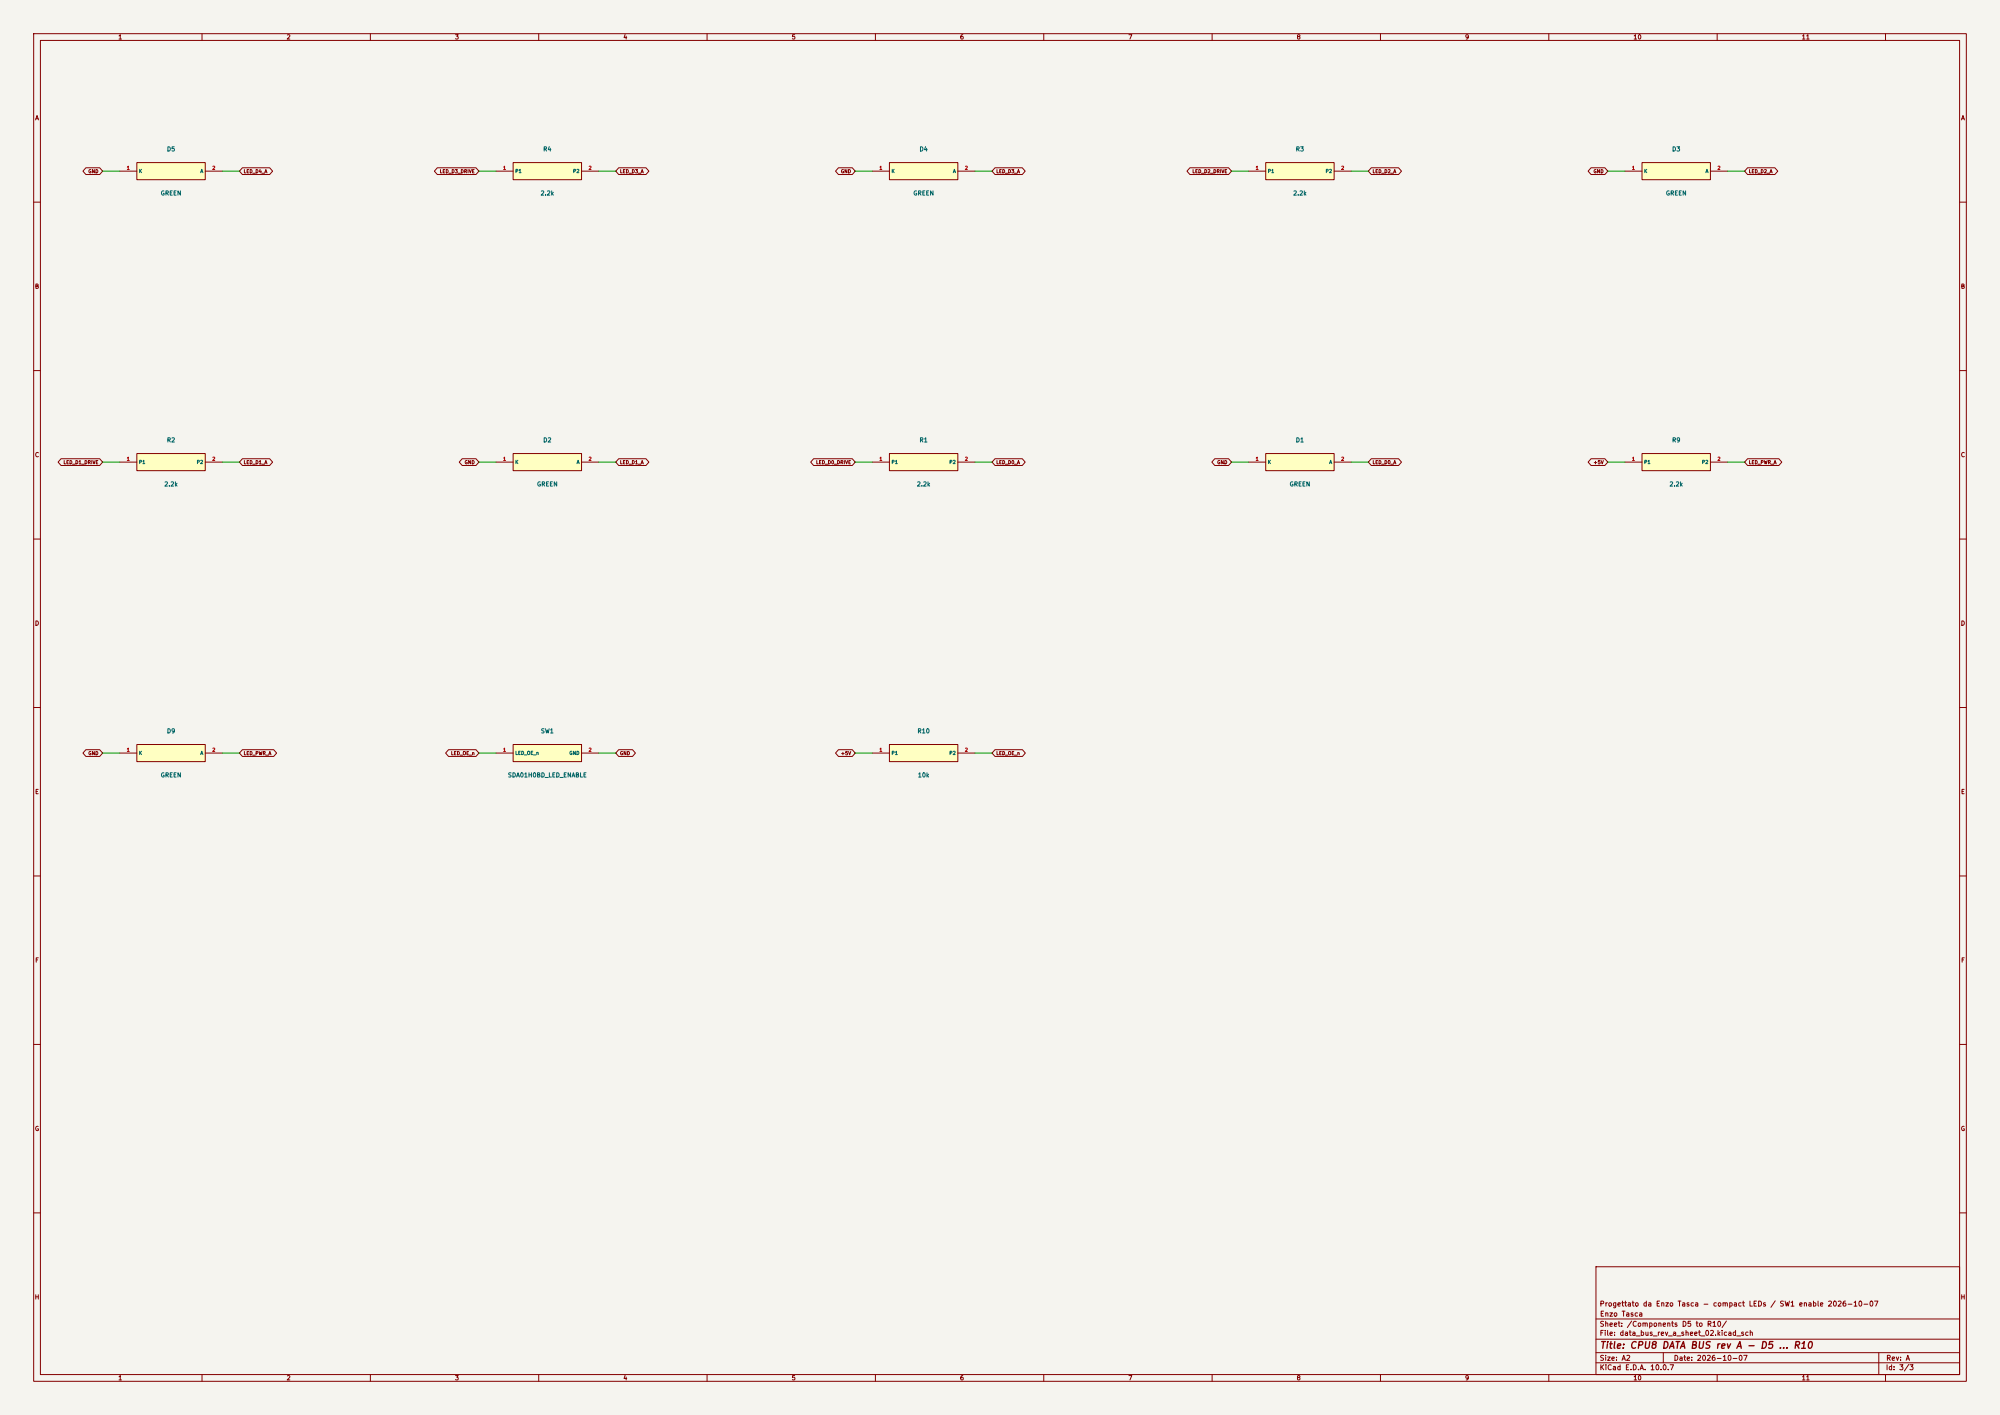
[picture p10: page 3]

Progettato da Enzo Tasca - compact LEDs / SW1 enable 2026-10-07
Enzo Tasca
Sheet: /Components D5 to R10/
File: data_bus_rev_a_sheet_02.kicad_sch
Title: CPU8 DATA BUS rev A - D5 ... R10

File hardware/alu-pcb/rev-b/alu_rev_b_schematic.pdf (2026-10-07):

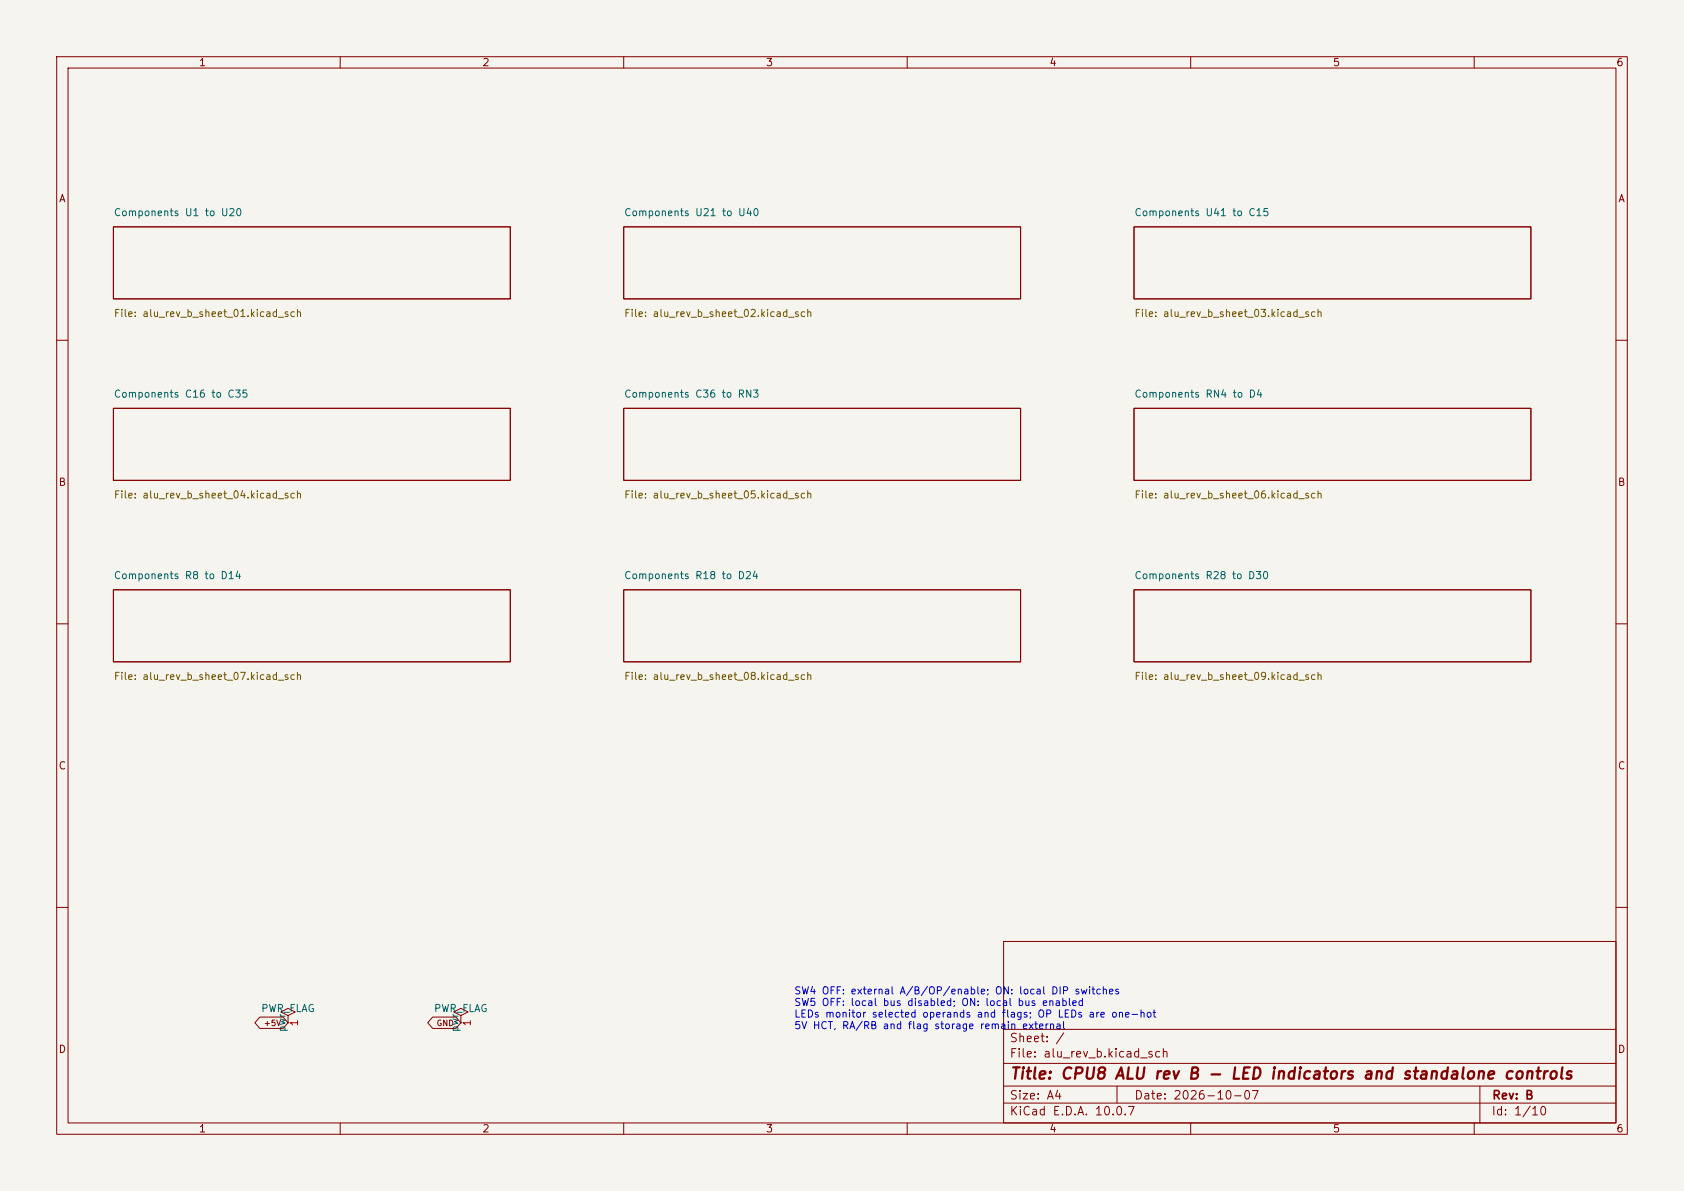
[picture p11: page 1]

LEDs monitor selected operands and flags; OP LEDs are one-hot 5V HCT, RA/RB and flag storage remain external

Sheet: /
File: alu_rev_b.kicad_sch
Title: CPU8 ALU rev B - LED indicators and standalone controls

Size: A4 | Rev: B
KiCad E.D.A. 10.0.7 | Id: 1/10

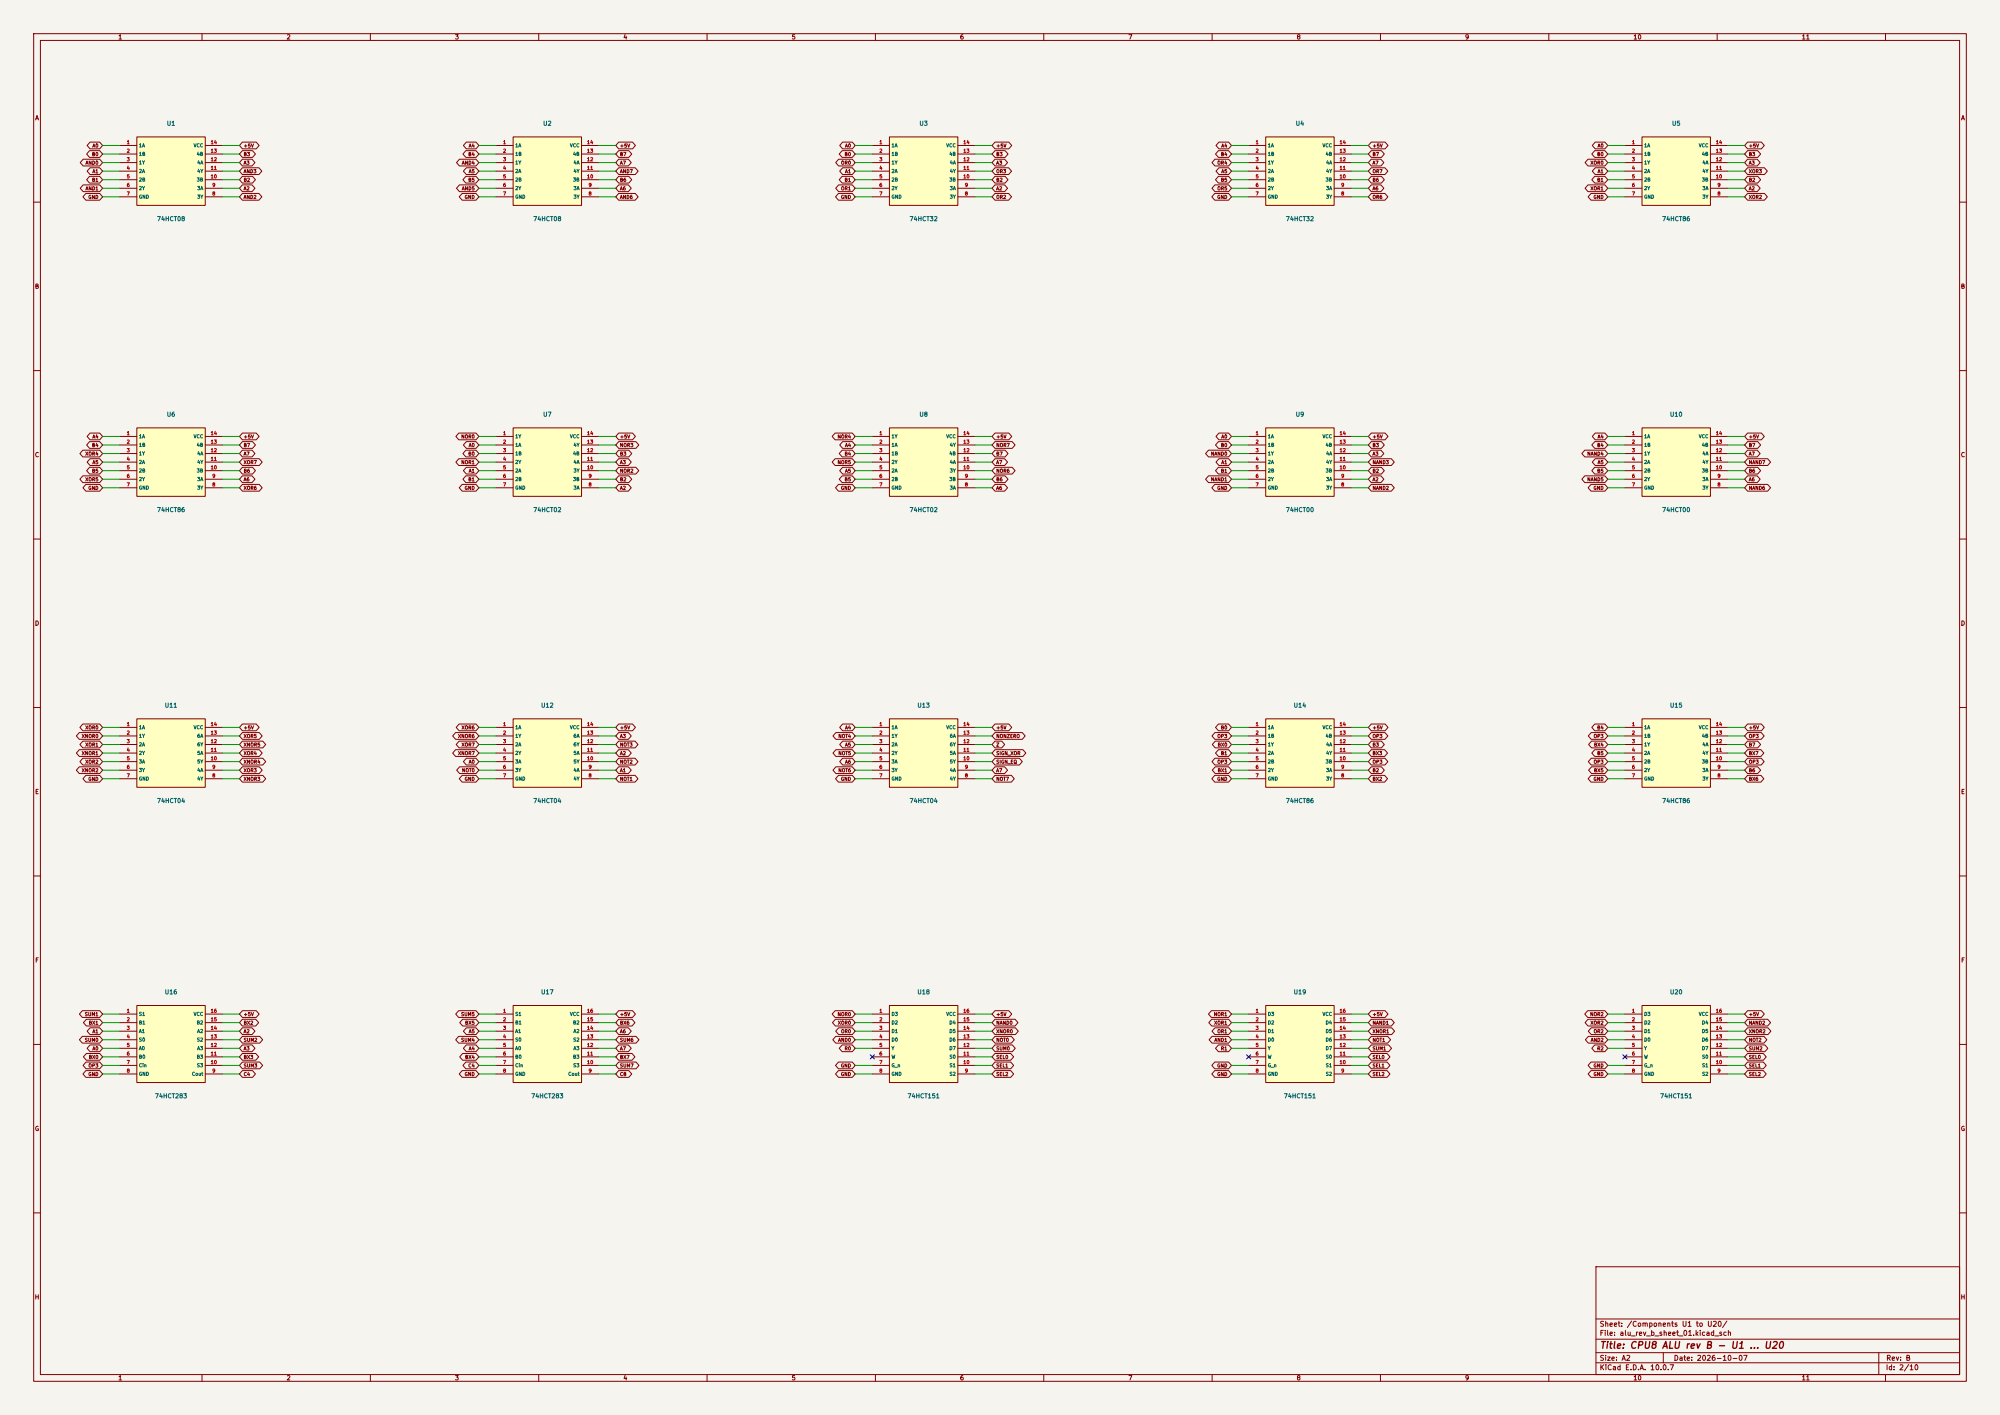
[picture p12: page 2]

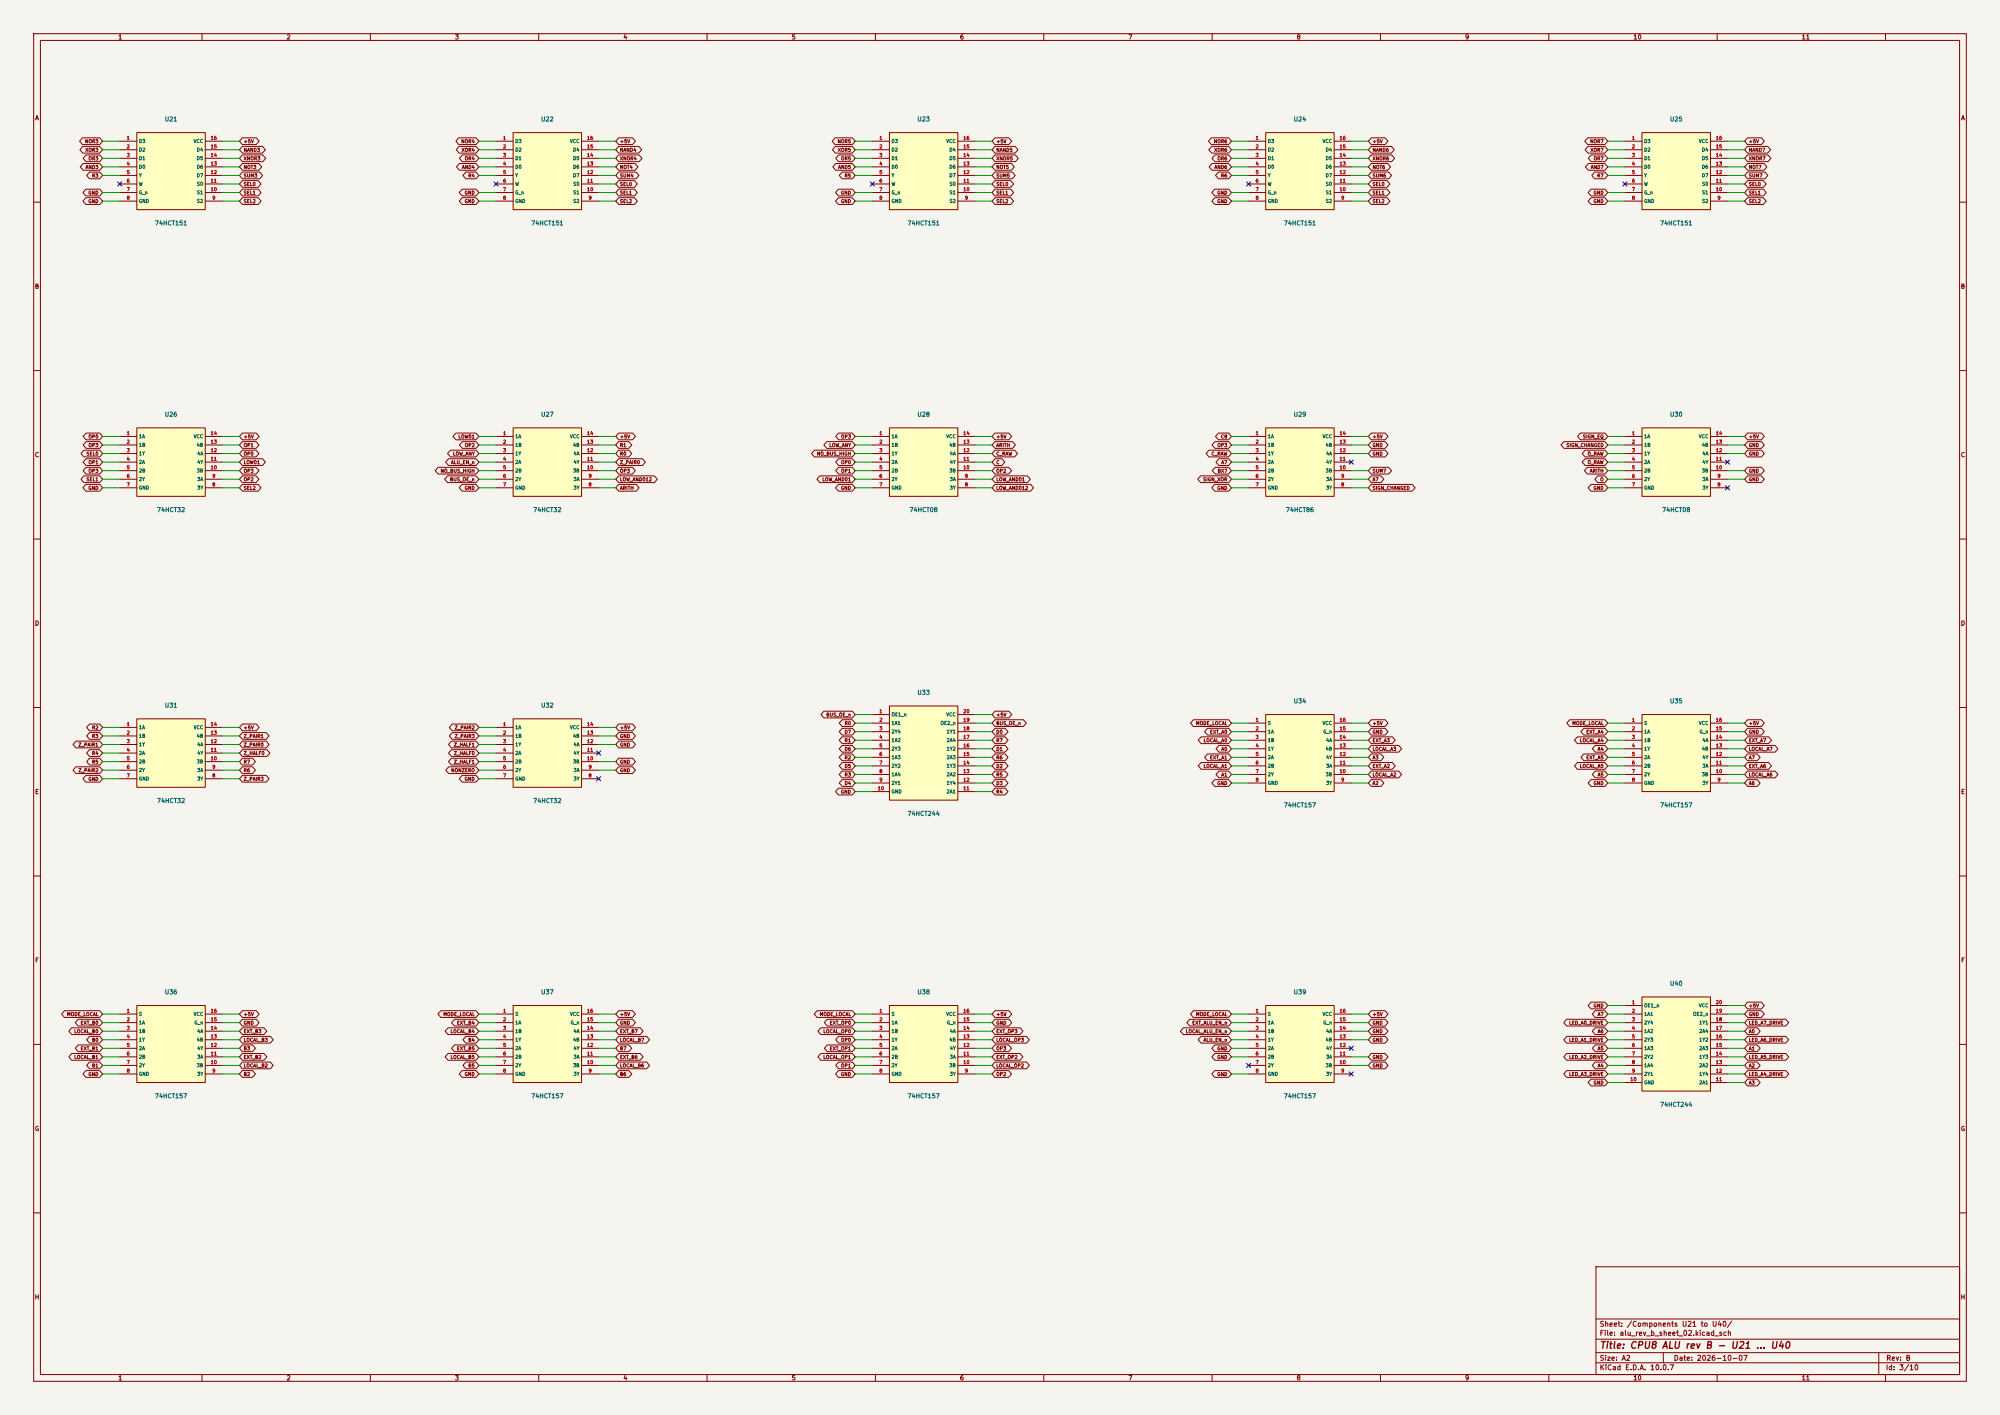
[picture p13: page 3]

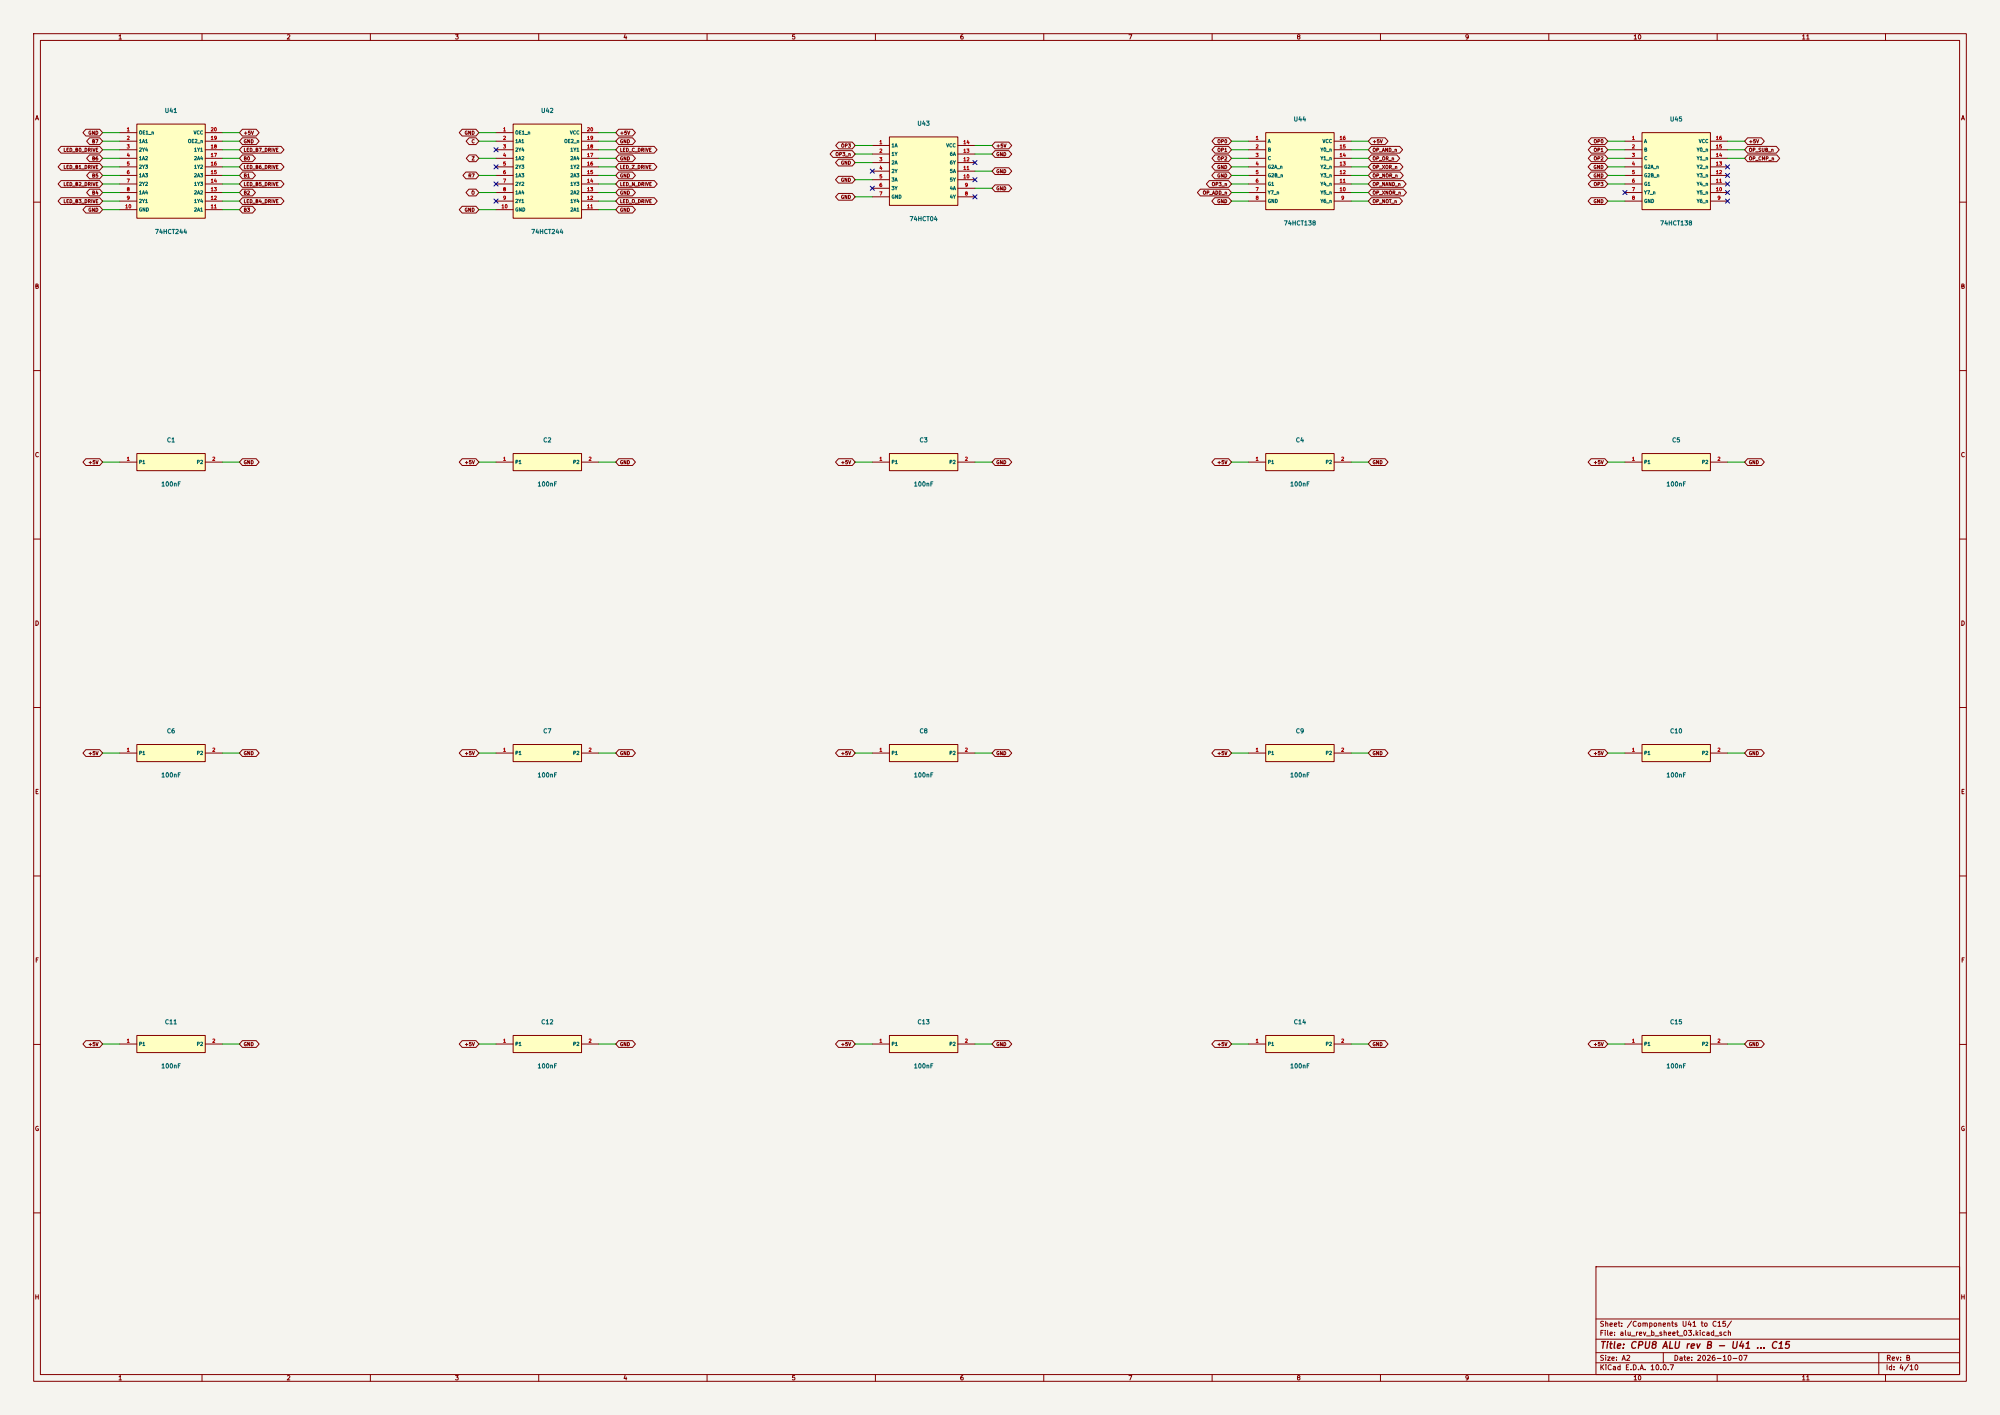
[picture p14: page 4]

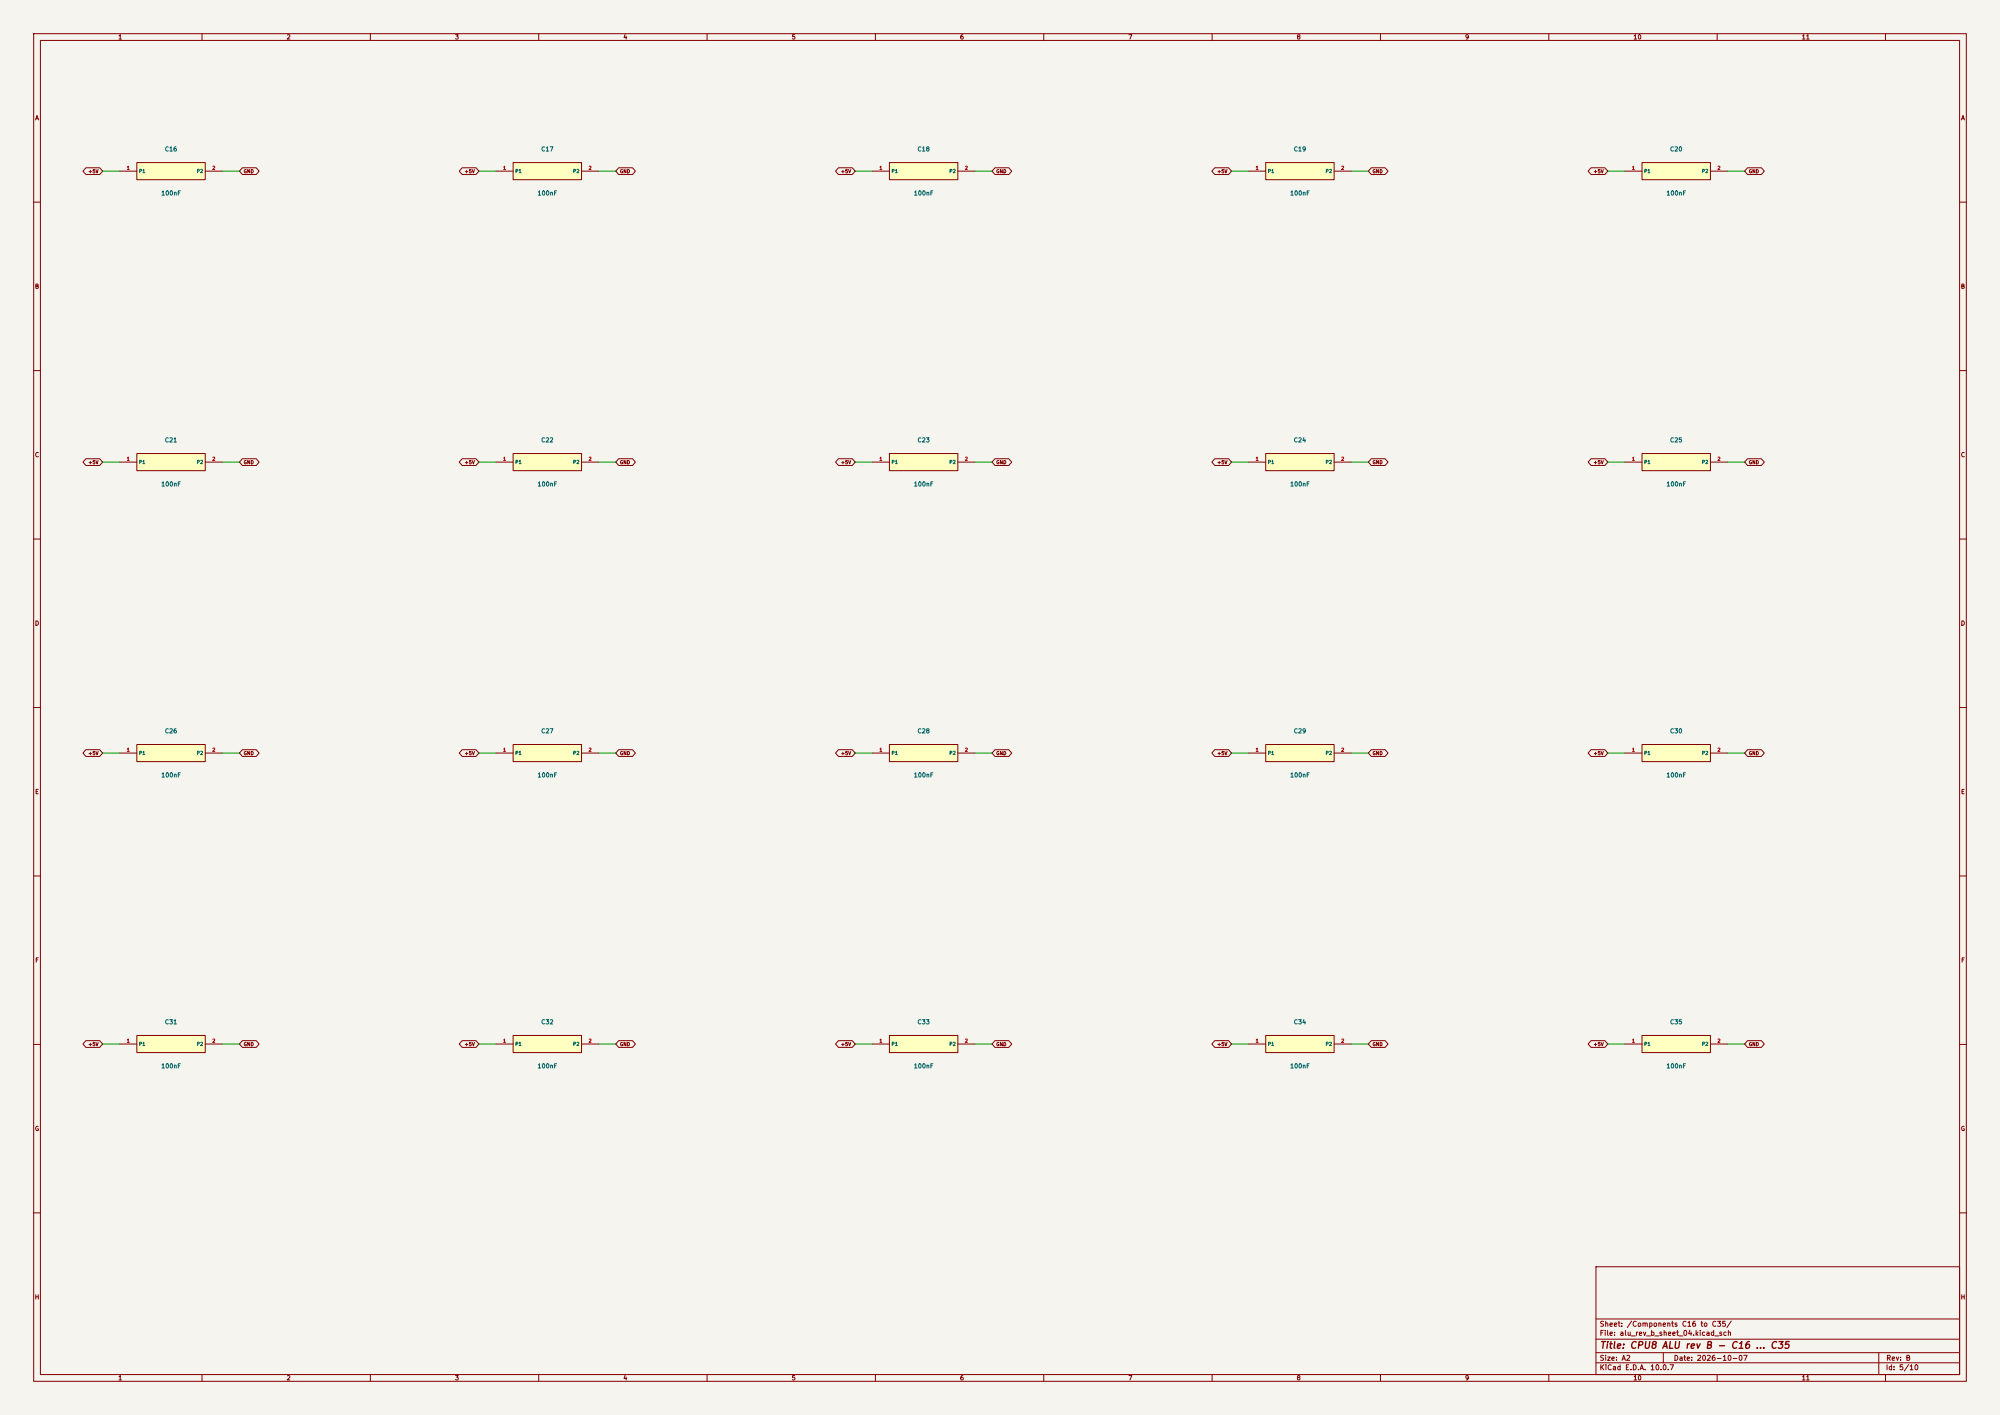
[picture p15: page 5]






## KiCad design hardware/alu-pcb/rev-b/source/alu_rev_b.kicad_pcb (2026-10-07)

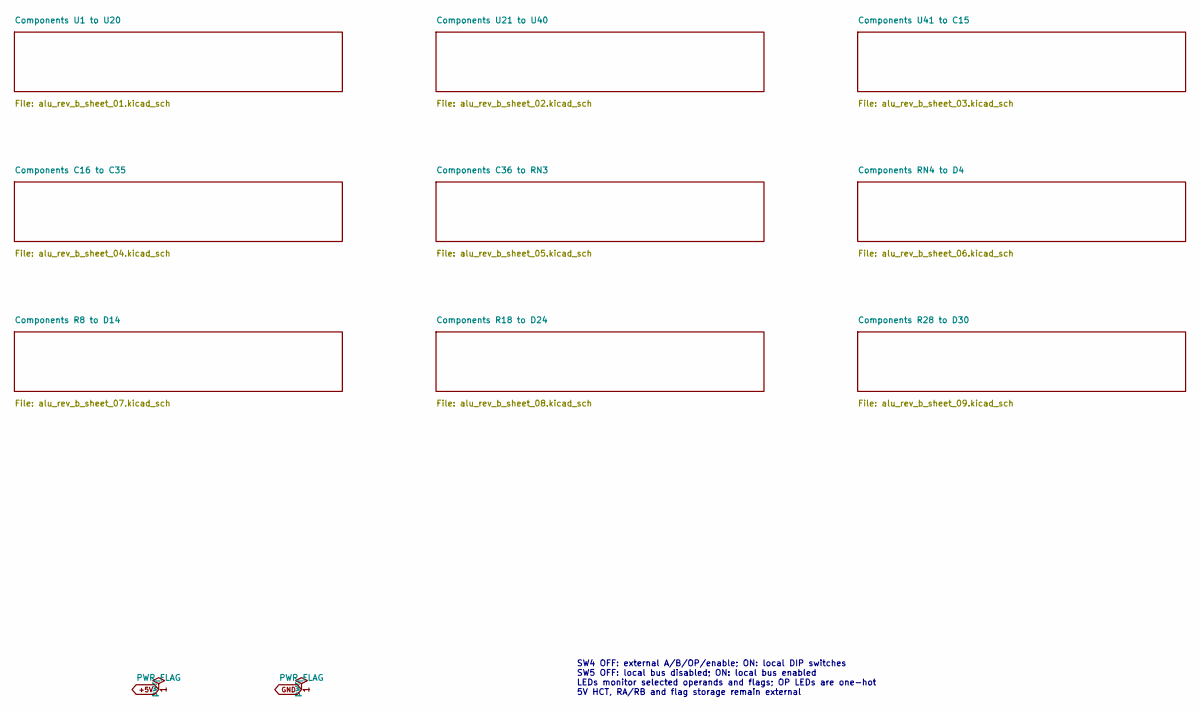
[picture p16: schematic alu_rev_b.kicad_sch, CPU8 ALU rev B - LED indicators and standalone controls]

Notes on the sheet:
SW4 OFF: external A/B/OP/enable; ON: local DIP switches SW5 OFF: local bus disabled; ON: local bus enabled LEDs monitor selected operands and flags; OP LEDs are one-hot 5V HCT, RA/RB and flag storage remain external

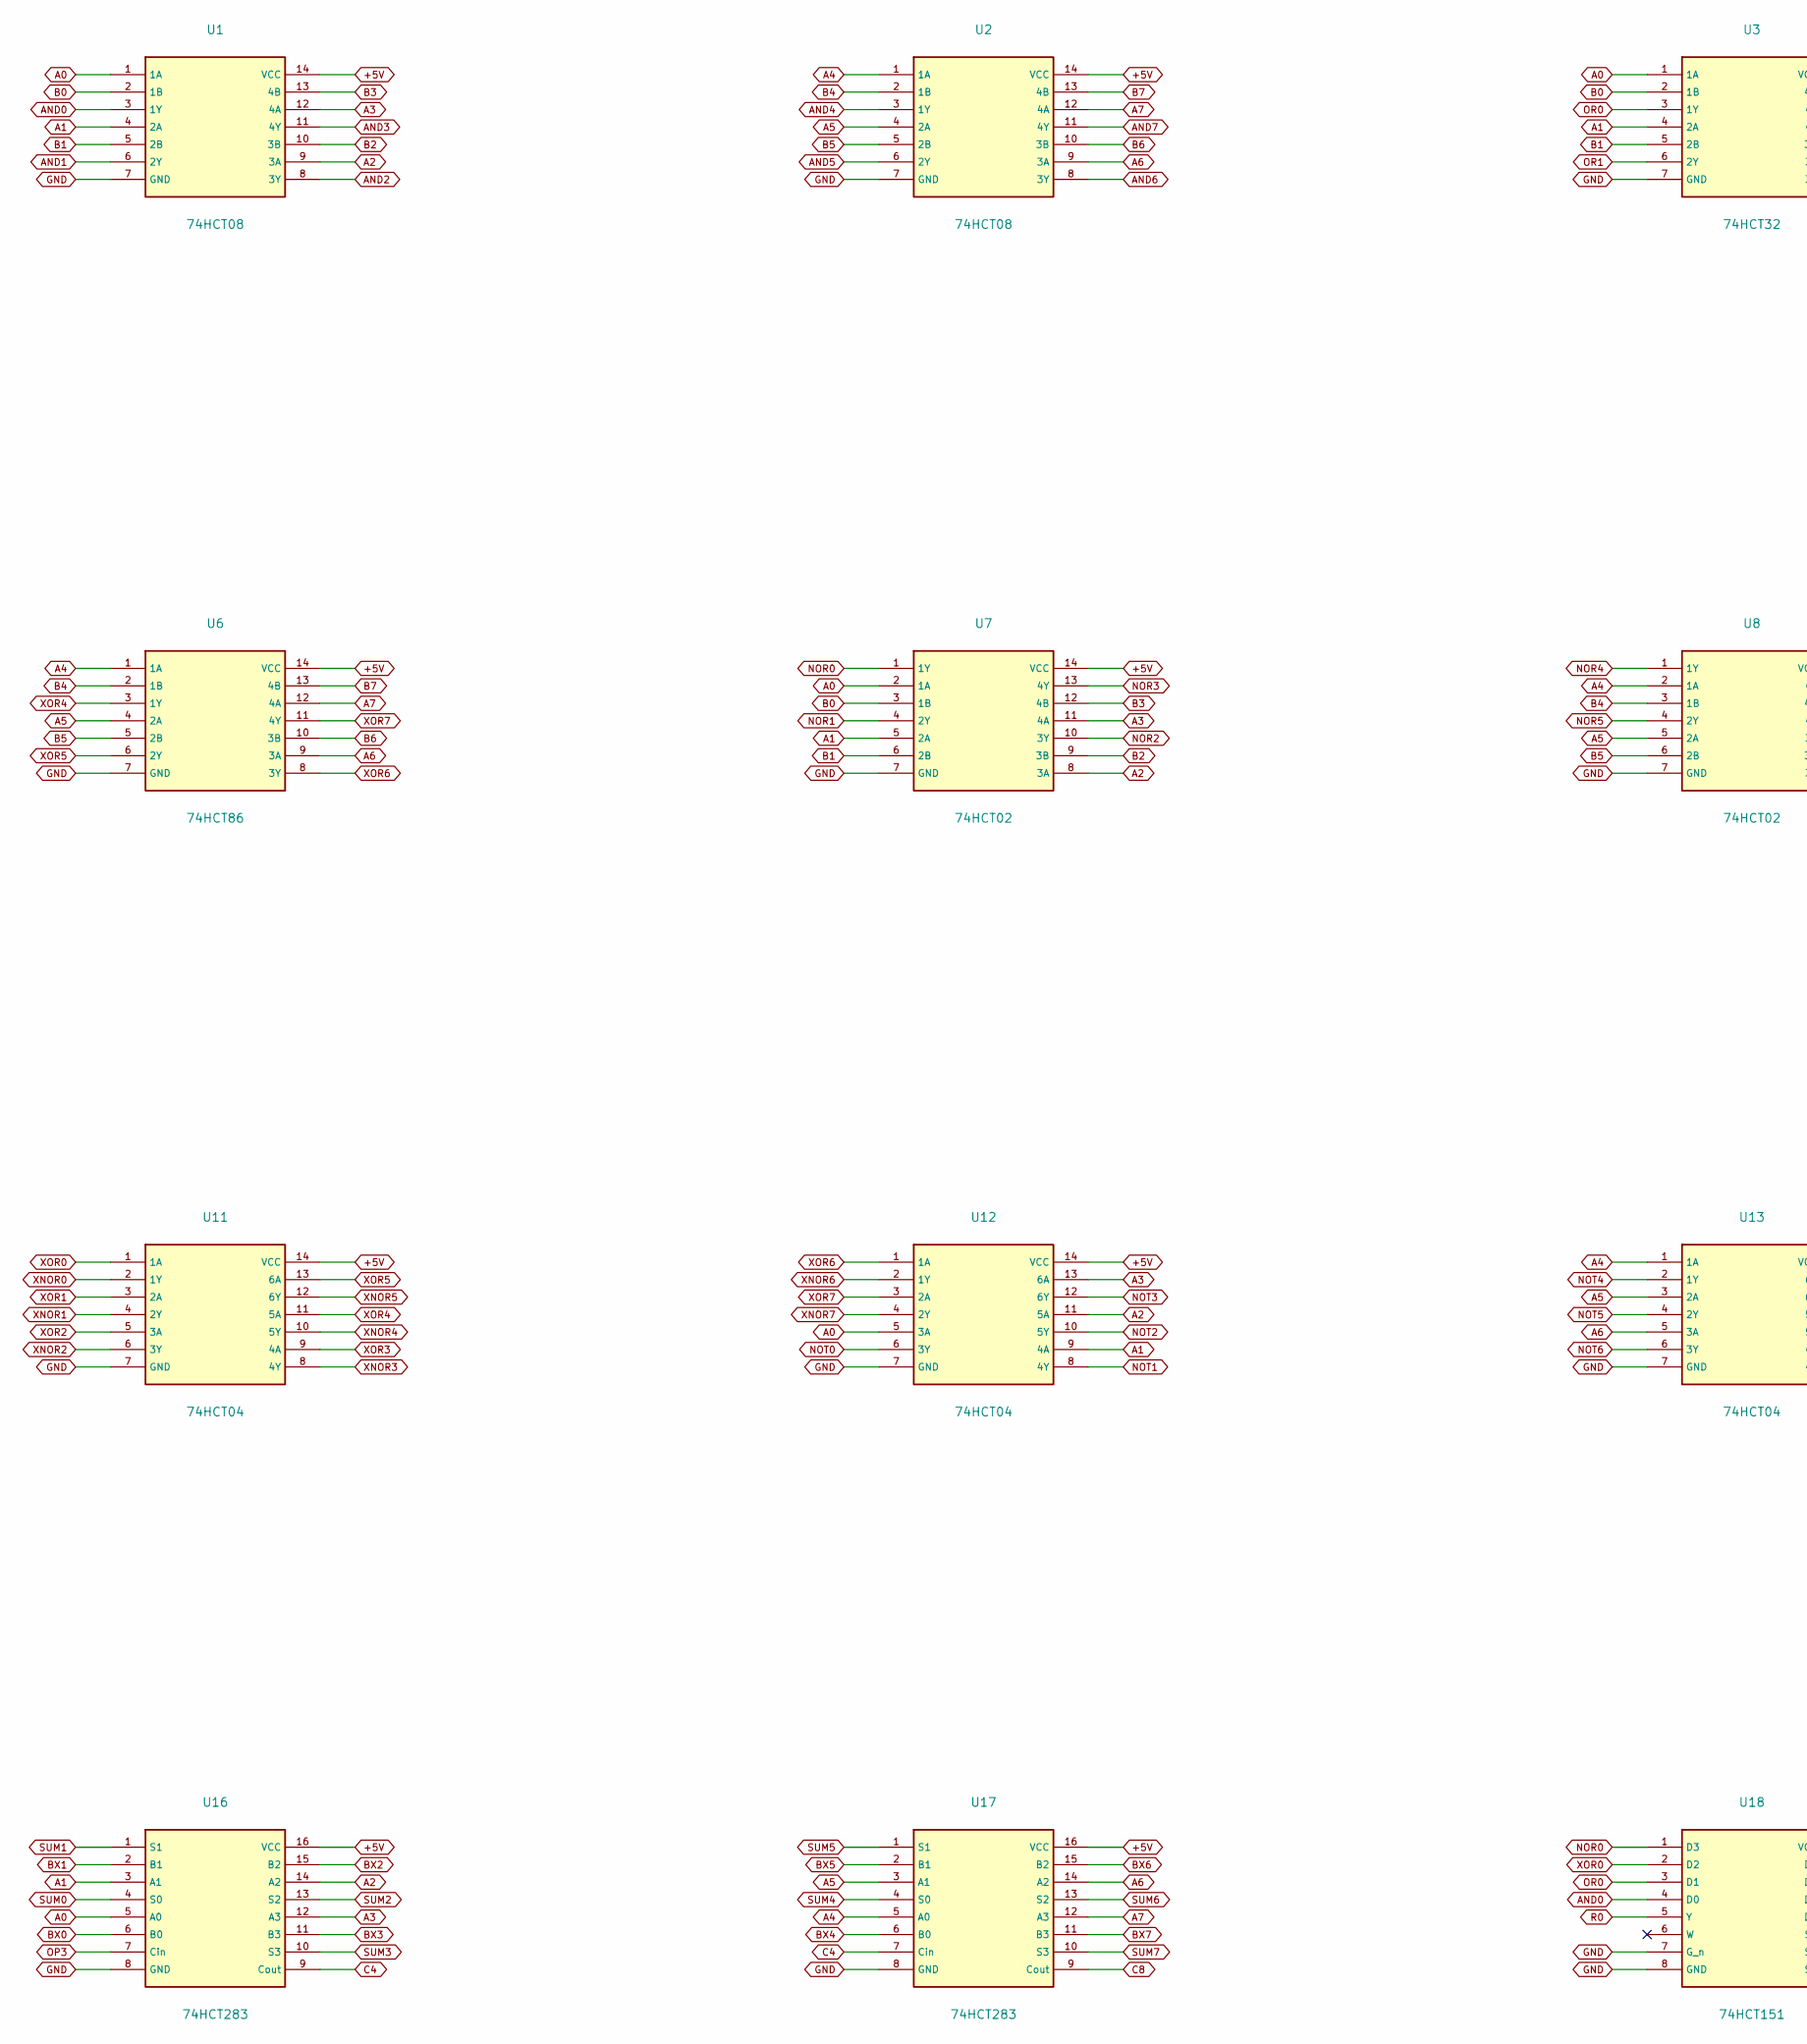
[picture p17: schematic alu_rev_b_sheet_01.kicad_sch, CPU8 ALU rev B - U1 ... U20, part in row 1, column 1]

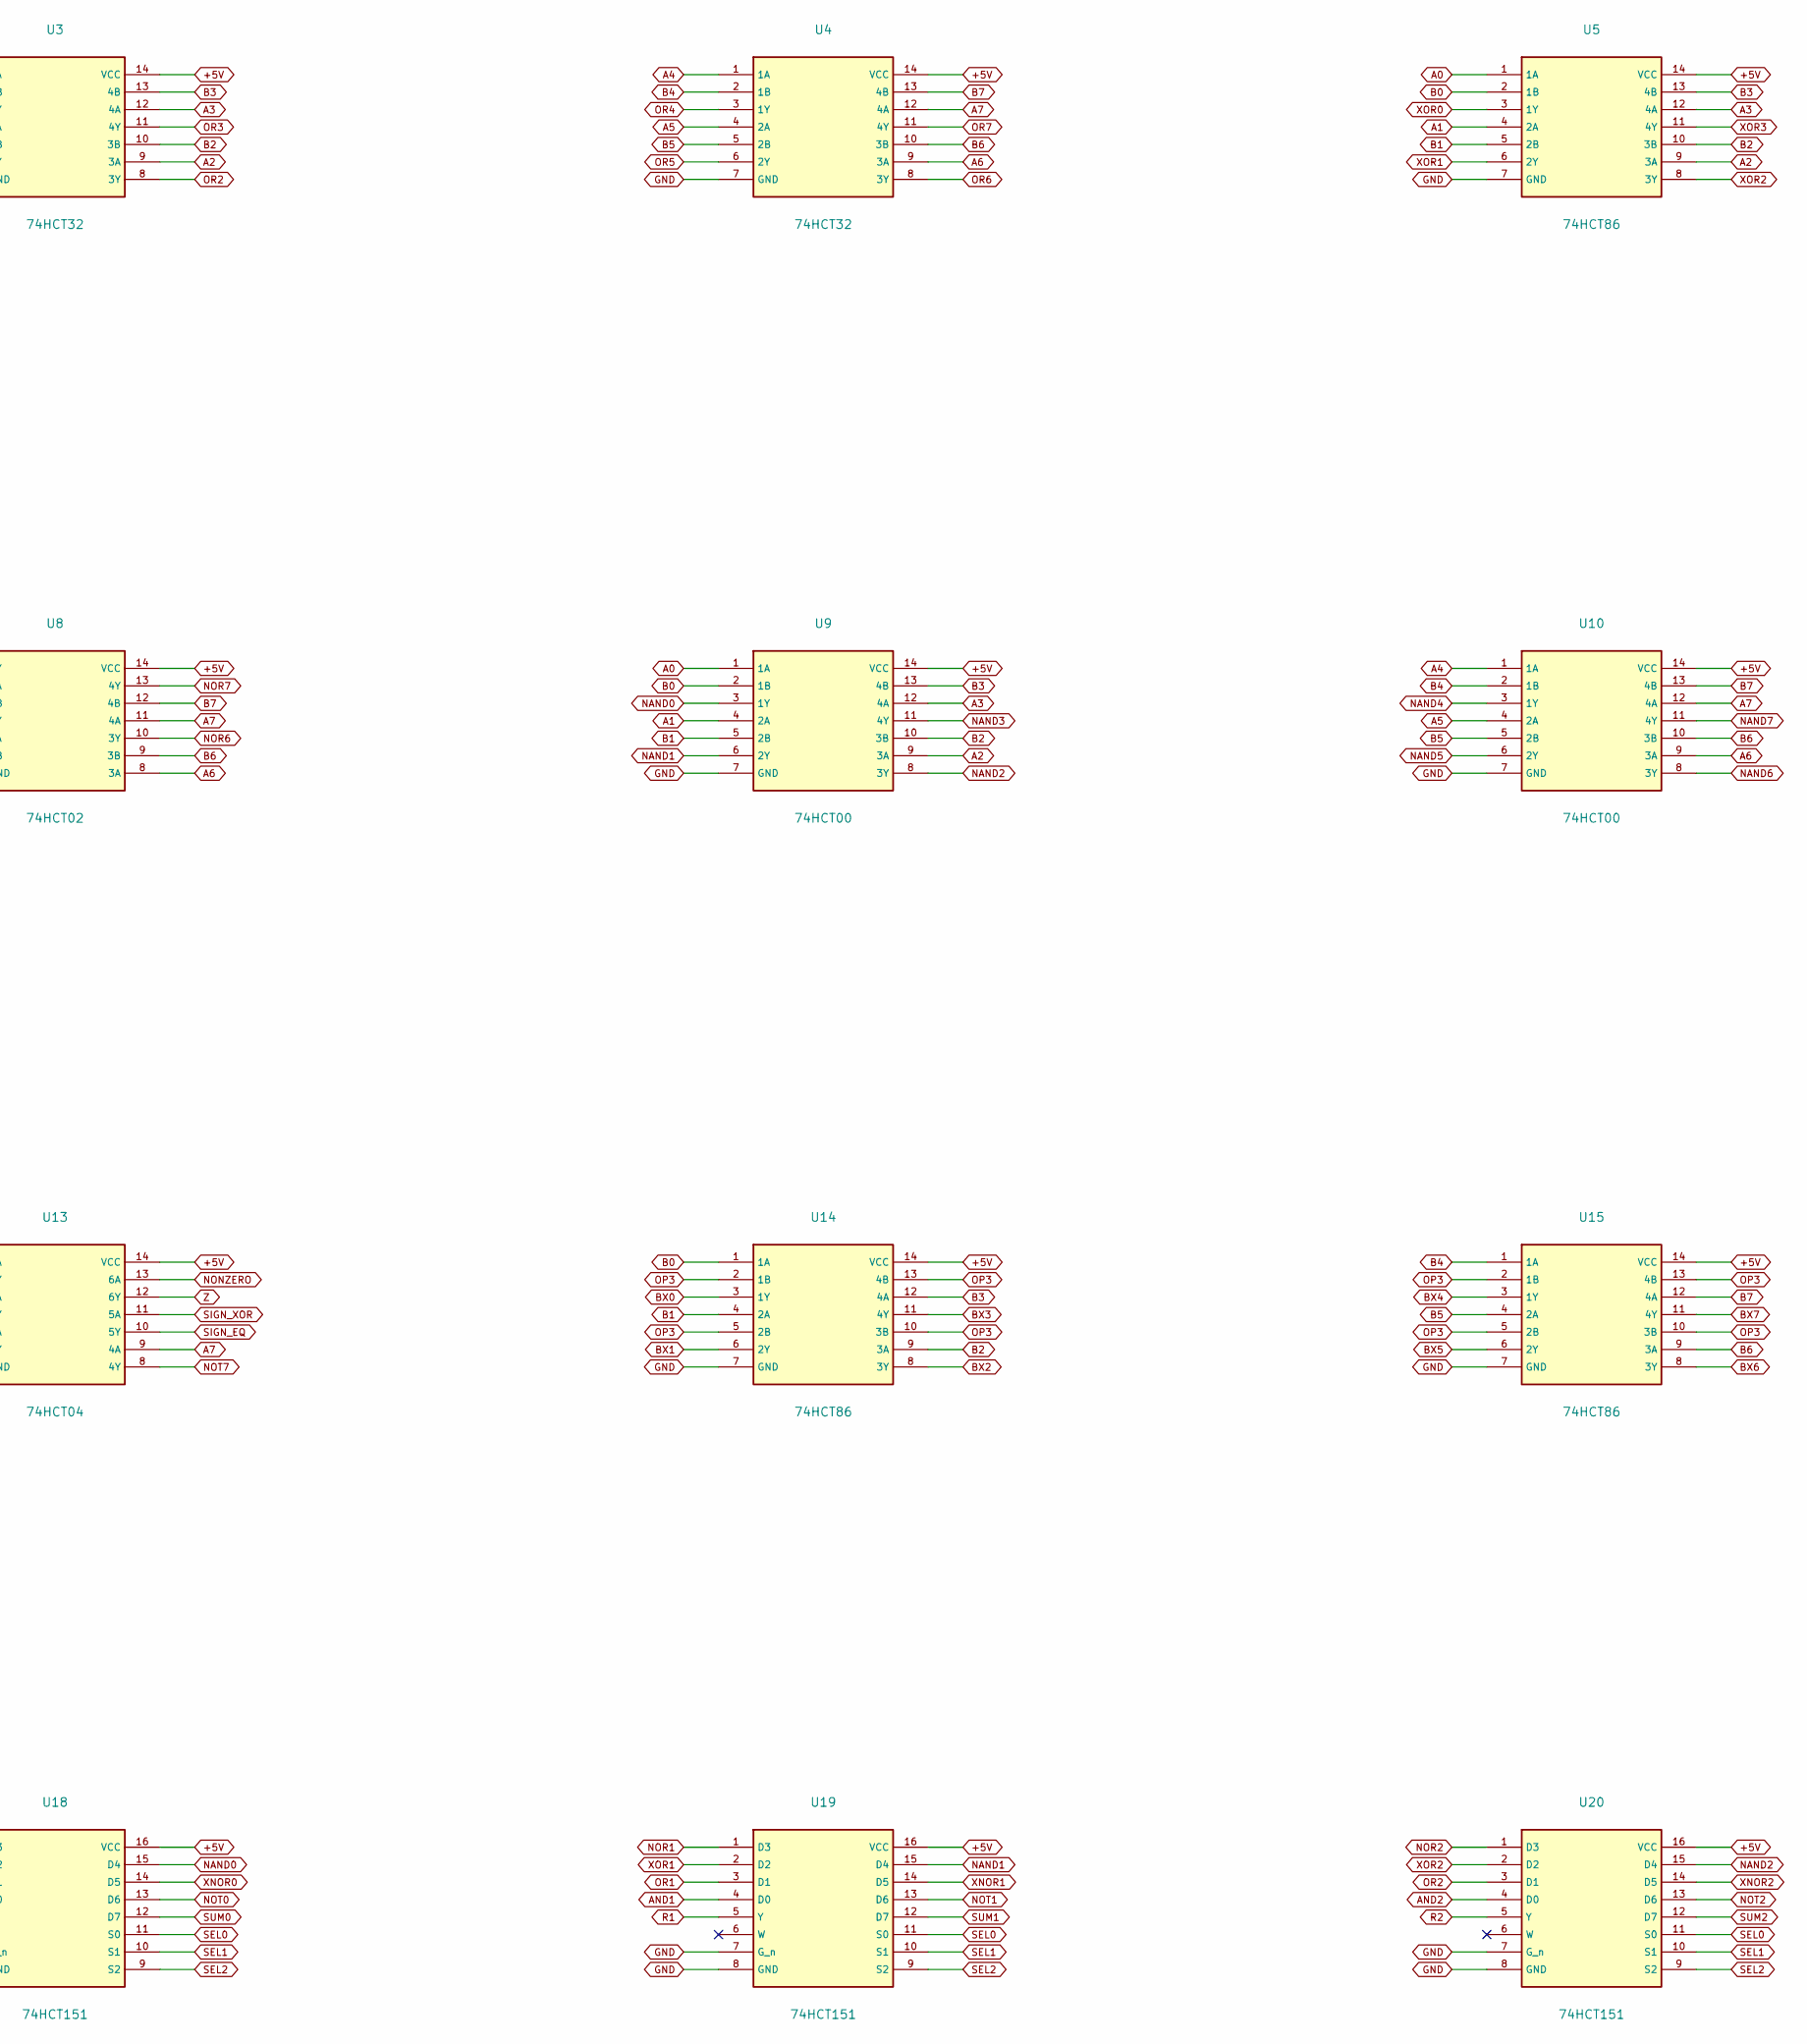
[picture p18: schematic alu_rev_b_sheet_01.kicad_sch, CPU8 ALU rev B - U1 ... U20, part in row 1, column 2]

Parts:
U1, U2: 74HCT08; DIP-14_W7.62mm
U3, U4: 74HCT32; DIP-14_W7.62mm
U5, U6, U14, U15: 74HCT86; DIP-14_W7.62mm
U7, U8: 74HCT02; DIP-14_W7.62mm
U9, U10: 74HCT00; DIP-14_W7.62mm
U11, U12, U13: 74HCT04; DIP-14_W7.62mm
U16, U17: 74HCT283; DIP-16_W7.62mm
U18, U19, U20: 74HCT151; DIP-16_W7.62mm

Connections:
+5V: U1.14 (VCC), U2.14 (VCC), U3.14 (VCC), U4.14 (VCC), U5.14 (VCC), U6.14 (VCC), U7.14 (VCC), U8.14 (VCC), U9.14 (VCC), U10.14 (VCC), U11.14 (VCC), U12.14 (VCC), U13.14 (VCC), U14.14 (VCC), U15.14 (VCC), U16.16 (VCC), U17.16 (VCC), U18.16 (VCC), U19.16 (VCC), U20.16 (VCC); also elsewhere on the board
A0: U1.1 (1A), U3.1 (1A), U5.1 (1A), U7.2 (1A), U9.1 (1A), U12.5 (3A), U16.5 (A0); also elsewhere on the board
A1: U1.4 (2A), U3.4 (2A), U5.4 (2A), U7.5 (2A), U9.4 (2A), U12.9 (4A), U16.3 (A1); also elsewhere on the board
A2: U1.9 (3A), U3.9 (3A), U5.9 (3A), U7.8 (3A), U9.9 (3A), U12.11 (5A), U16.14 (A2); also elsewhere on the board
A3: U1.12 (4A), U3.12 (4A), U5.12 (4A), U7.11 (4A), U9.12 (4A), U12.13 (6A), U16.12 (A3); also elsewhere on the board
A4: U2.1 (1A), U4.1 (1A), U6.1 (1A), U8.2 (1A), U10.1 (1A), U13.1 (1A), U17.5 (A0); also elsewhere on the board
A5: U2.4 (2A), U4.4 (2A), U6.4 (2A), U8.5 (2A), U10.4 (2A), U13.3 (2A), U17.3 (A1); also elsewhere on the board
A6: U2.9 (3A), U4.9 (3A), U6.9 (3A), U8.8 (3A), U10.9 (3A), U13.5 (3A), U17.14 (A2); also elsewhere on the board
A7: U2.12 (4A), U4.12 (4A), U6.12 (4A), U8.11 (4A), U10.12 (4A), U13.9 (4A), U17.12 (A3); also elsewhere on the board
AND0: U1.3 (1Y), U18.4 (D0)
AND1: U1.6 (2Y), U19.4 (D0)
AND2: U1.8 (3Y), U20.4 (D0)
AND3: U1.11 (4Y); also elsewhere on the board
AND4: U2.3 (1Y); also elsewhere on the board
AND5: U2.6 (2Y); also elsewhere on the board
AND6: U2.8 (3Y); also elsewhere on the board
AND7: U2.11 (4Y); also elsewhere on the board
B0: U1.2 (1B), U3.2 (1B), U5.2 (1B), U7.3 (1B), U9.2 (1B), U14.1 (1A); also elsewhere on the board
B1: U1.5 (2B), U3.5 (2B), U5.5 (2B), U7.6 (2B), U9.5 (2B), U14.4 (2A); also elsewhere on the board
B2: U1.10 (3B), U3.10 (3B), U5.10 (3B), U7.9 (3B), U9.10 (3B), U14.9 (3A); also elsewhere on the board
B3: U1.13 (4B), U3.13 (4B), U5.13 (4B), U7.12 (4B), U9.13 (4B), U14.12 (4A); also elsewhere on the board
B4: U2.2 (1B), U4.2 (1B), U6.2 (1B), U8.3 (1B), U10.2 (1B), U15.1 (1A); also elsewhere on the board
B5: U2.5 (2B), U4.5 (2B), U6.5 (2B), U8.6 (2B), U10.5 (2B), U15.4 (2A); also elsewhere on the board
B6: U2.10 (3B), U4.10 (3B), U6.10 (3B), U8.9 (3B), U10.10 (3B), U15.9 (3A); also elsewhere on the board
B7: U2.13 (4B), U4.13 (4B), U6.13 (4B), U8.12 (4B), U10.13 (4B), U15.12 (4A); also elsewhere on the board
BX0: U14.3 (1Y), U16.6 (B0)
BX1: U14.6 (2Y), U16.2 (B1)
BX2: U14.8 (3Y), U16.15 (B2)
BX3: U14.11 (4Y), U16.11 (B3)
BX4: U15.3 (1Y), U17.6 (B0)
BX5: U15.6 (2Y), U17.2 (B1)
BX6: U15.8 (3Y), U17.15 (B2)
BX7: U15.11 (4Y), U17.11 (B3); also elsewhere on the board
C4: U16.9 (Cout), U17.7 (Cin)
C8: U17.9 (Cout); also elsewhere on the board
GND: U1.7 (GND), U2.7 (GND), U3.7 (GND), U4.7 (GND), U5.7 (GND), U6.7 (GND), U7.7 (GND), U8.7 (GND), U9.7 (GND), U10.7 (GND), U11.7 (GND), U12.7 (GND), U13.7 (GND), U14.7 (GND), U15.7 (GND), U16.8 (GND), U17.8 (GND), U18.7 (G_n), U18.8 (GND), U19.7 (G_n), U19.8 (GND), U20.7 (G_n), U20.8 (GND); also elsewhere on the board
NAND0: U9.3 (1Y), U18.15 (D4)
NAND1: U9.6 (2Y), U19.15 (D4)
NAND2: U9.8 (3Y), U20.15 (D4)
NAND3: U9.11 (4Y); also elsewhere on the board
NAND4: U10.3 (1Y); also elsewhere on the board
NAND5: U10.6 (2Y); also elsewhere on the board
NAND6: U10.8 (3Y); also elsewhere on the board
NAND7: U10.11 (4Y); also elsewhere on the board
NONZERO: U13.13 (6A); also elsewhere on the board
NOR0: U7.1 (1Y), U18.1 (D3)
NOR1: U7.4 (2Y), U19.1 (D3)
NOR2: U7.10 (3Y), U20.1 (D3)
NOR3: U7.13 (4Y); also elsewhere on the board
NOR4: U8.1 (1Y); also elsewhere on the board
NOR5: U8.4 (2Y); also elsewhere on the board
NOR6: U8.10 (3Y); also elsewhere on the board
NOR7: U8.13 (4Y); also elsewhere on the board
NOT0: U12.6 (3Y), U18.13 (D6)
NOT1: U12.8 (4Y), U19.13 (D6)
NOT2: U12.10 (5Y), U20.13 (D6)
NOT3: U12.12 (6Y); also elsewhere on the board
NOT4: U13.2 (1Y); also elsewhere on the board
NOT5: U13.4 (2Y); also elsewhere on the board
NOT6: U13.6 (3Y); also elsewhere on the board
NOT7: U13.8 (4Y); also elsewhere on the board
OP3: U14.2 (1B), U14.5 (2B), U14.10 (3B), U14.13 (4B), U15.2 (1B), U15.5 (2B), U15.10 (3B), U15.13 (4B), U16.7 (Cin); also elsewhere on the board
OR0: U3.3 (1Y), U18.3 (D1)
OR1: U3.6 (2Y), U19.3 (D1)
OR2: U3.8 (3Y), U20.3 (D1)
OR3: U3.11 (4Y); also elsewhere on the board
OR4: U4.3 (1Y); also elsewhere on the board
OR5: U4.6 (2Y); also elsewhere on the board
OR6: U4.8 (3Y); also elsewhere on the board
OR7: U4.11 (4Y); also elsewhere on the board
R0: U18.5 (Y); also elsewhere on the board
R1: U19.5 (Y); also elsewhere on the board
R2: U20.5 (Y); also elsewhere on the board
SEL0: U18.11 (S0), U19.11 (S0), U20.11 (S0); also elsewhere on the board
SEL1: U18.10 (S1), U19.10 (S1), U20.10 (S1); also elsewhere on the board
SEL2: U18.9 (S2), U19.9 (S2), U20.9 (S2); also elsewhere on the board
SIGN_EQ: U13.10 (5Y); also elsewhere on the board
SIGN_XOR: U13.11 (5A); also elsewhere on the board
SUM0: U16.4 (S0), U18.12 (D7)
SUM1: U16.1 (S1), U19.12 (D7)
SUM2: U16.13 (S2), U20.12 (D7)
SUM3: U16.10 (S3); also elsewhere on the board
SUM4: U17.4 (S0); also elsewhere on the board
SUM5: U17.1 (S1); also elsewhere on the board
SUM6: U17.13 (S2); also elsewhere on the board
SUM7: U17.10 (S3); also elsewhere on the board
XNOR0: U11.2 (1Y), U18.14 (D5)
XNOR1: U11.4 (2Y), U19.14 (D5)
XNOR2: U11.6 (3Y), U20.14 (D5)
XNOR3: U11.8 (4Y); also elsewhere on the board
XNOR4: U11.10 (5Y); also elsewhere on the board
XNOR5: U11.12 (6Y); also elsewhere on the board
XNOR6: U12.2 (1Y); also elsewhere on the board
XNOR7: U12.4 (2Y); also elsewhere on the board
XOR0: U5.3 (1Y), U11.1 (1A), U18.2 (D2)
XOR1: U5.6 (2Y), U11.3 (2A), U19.2 (D2)
XOR2: U5.8 (3Y), U11.5 (3A), U20.2 (D2)
XOR3: U5.11 (4Y), U11.9 (4A); also elsewhere on the board
XOR4: U6.3 (1Y), U11.11 (5A); also elsewhere on the board
XOR5: U6.6 (2Y), U11.13 (6A); also elsewhere on the board
XOR6: U6.8 (3Y), U12.1 (1A); also elsewhere on the board
XOR7: U6.11 (4Y), U12.3 (2A); also elsewhere on the board
Z: U13.12 (6Y); also elsewhere on the board

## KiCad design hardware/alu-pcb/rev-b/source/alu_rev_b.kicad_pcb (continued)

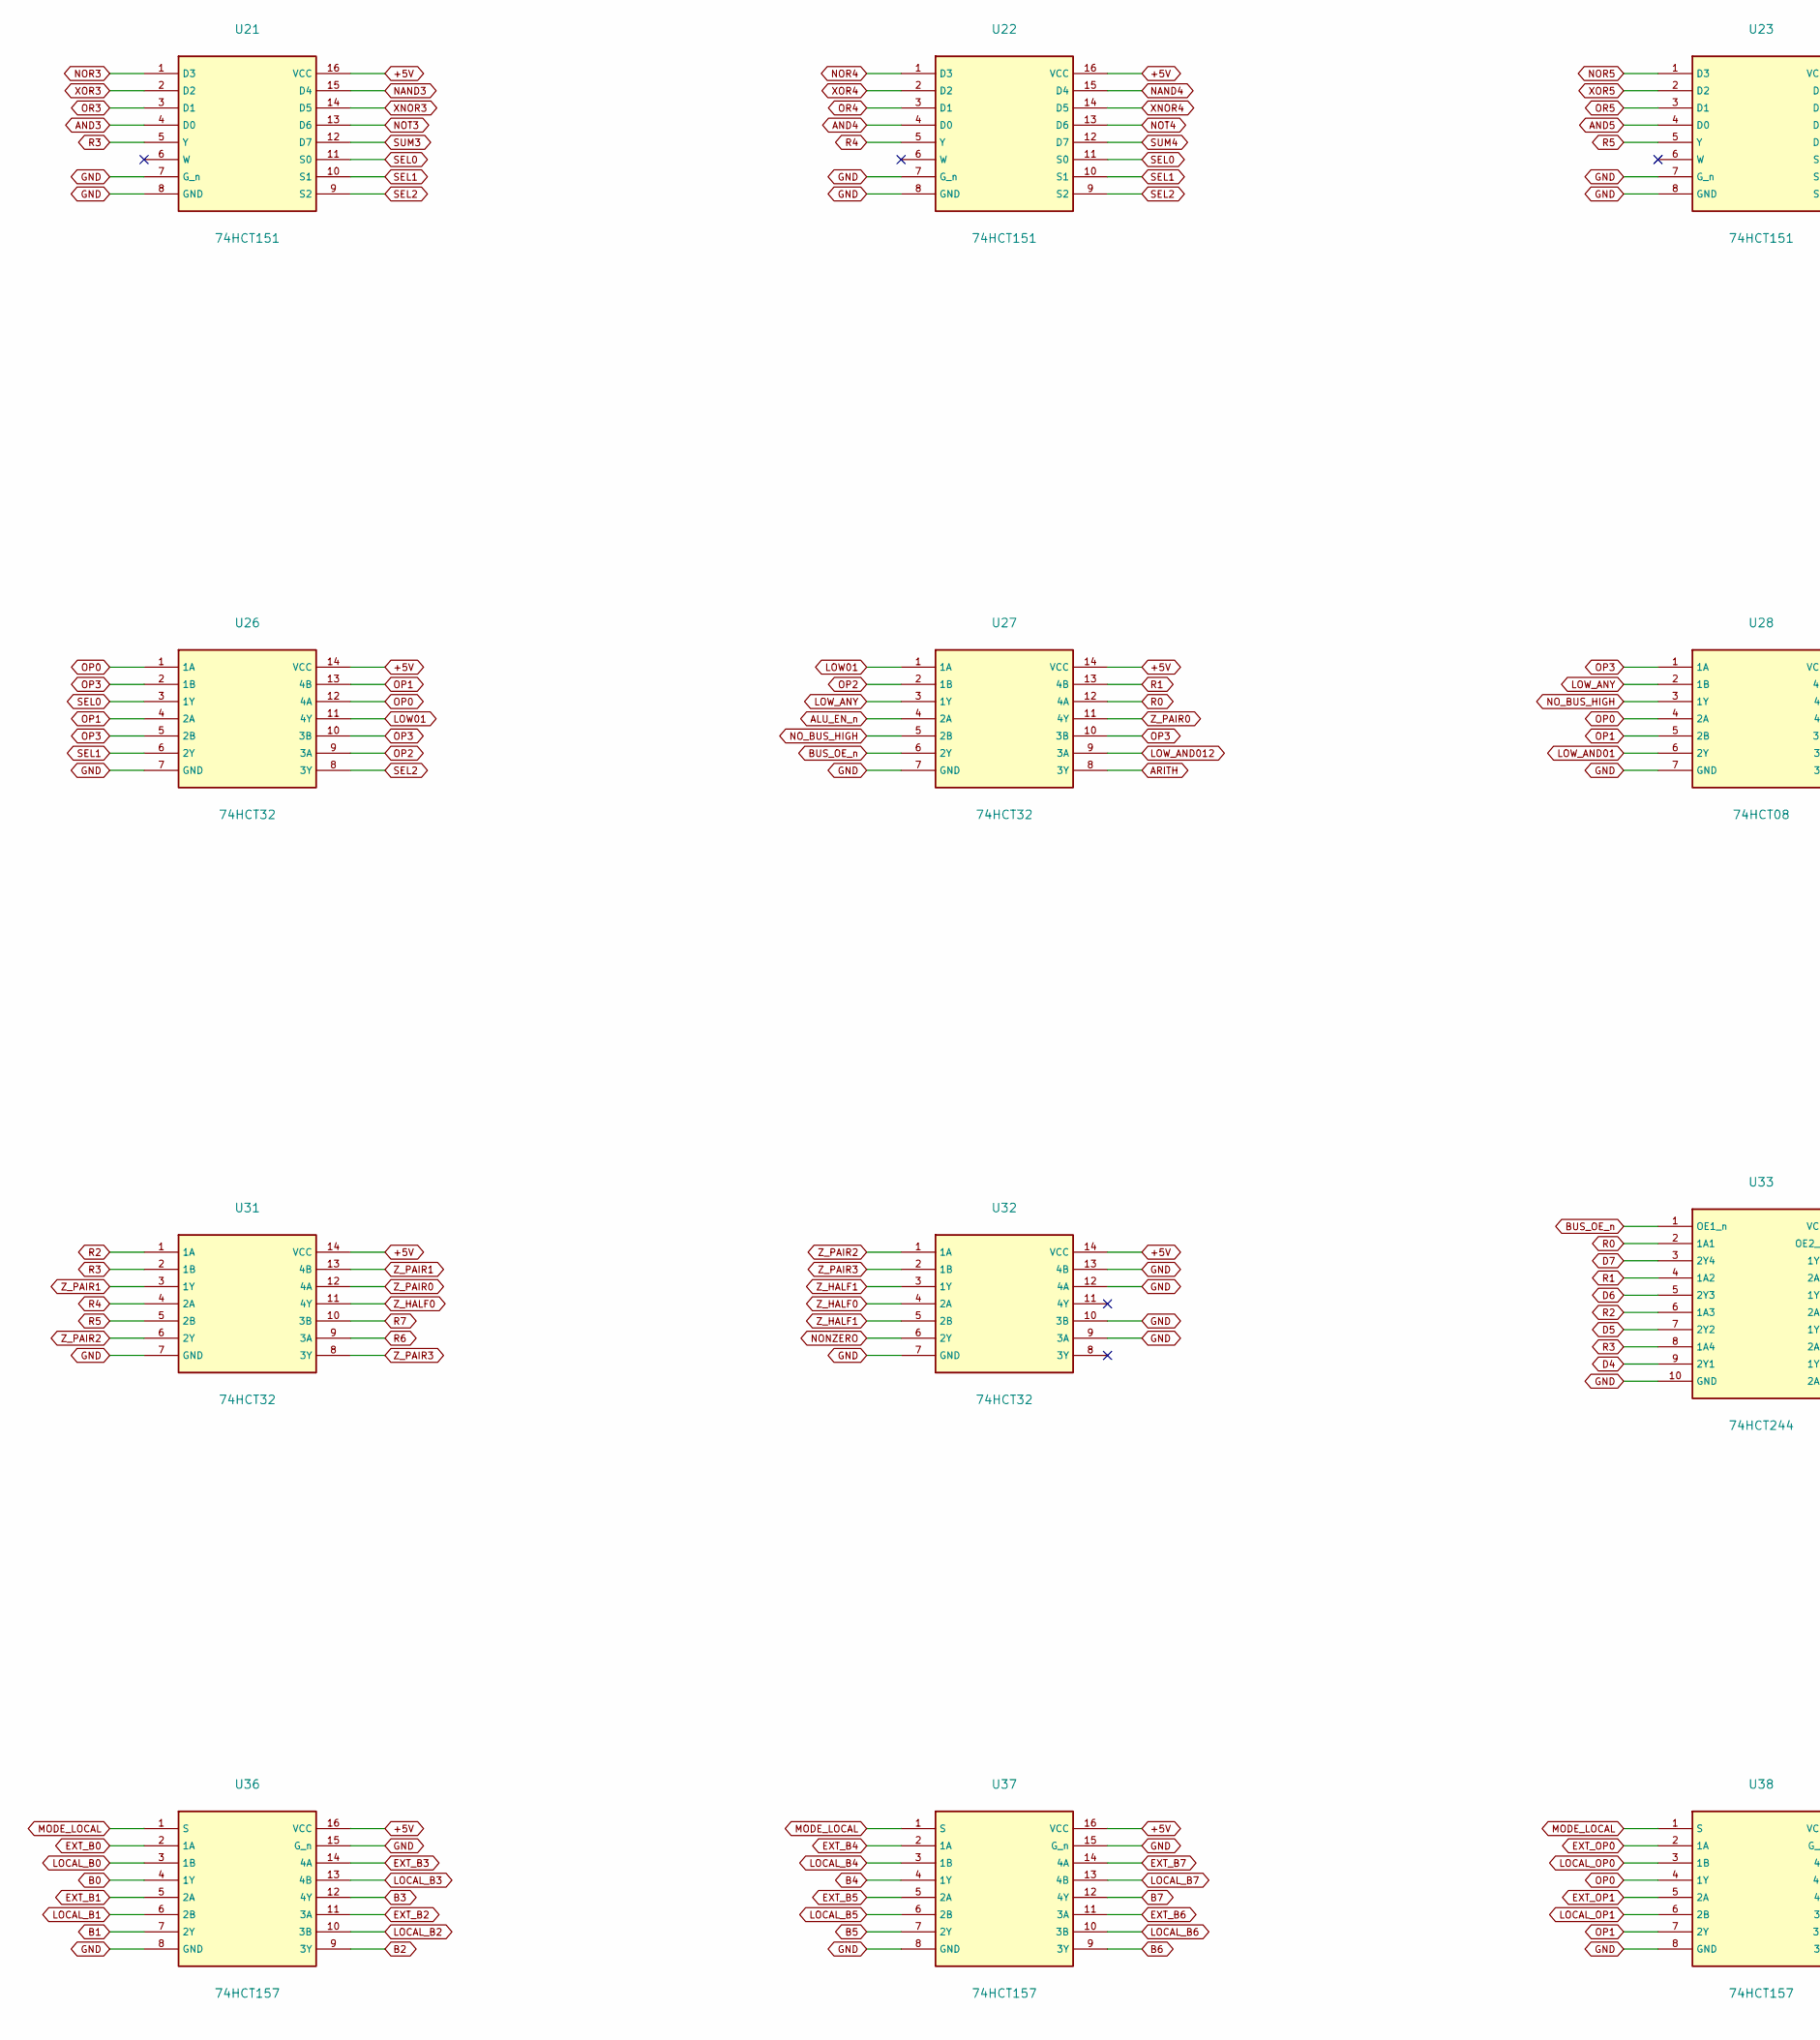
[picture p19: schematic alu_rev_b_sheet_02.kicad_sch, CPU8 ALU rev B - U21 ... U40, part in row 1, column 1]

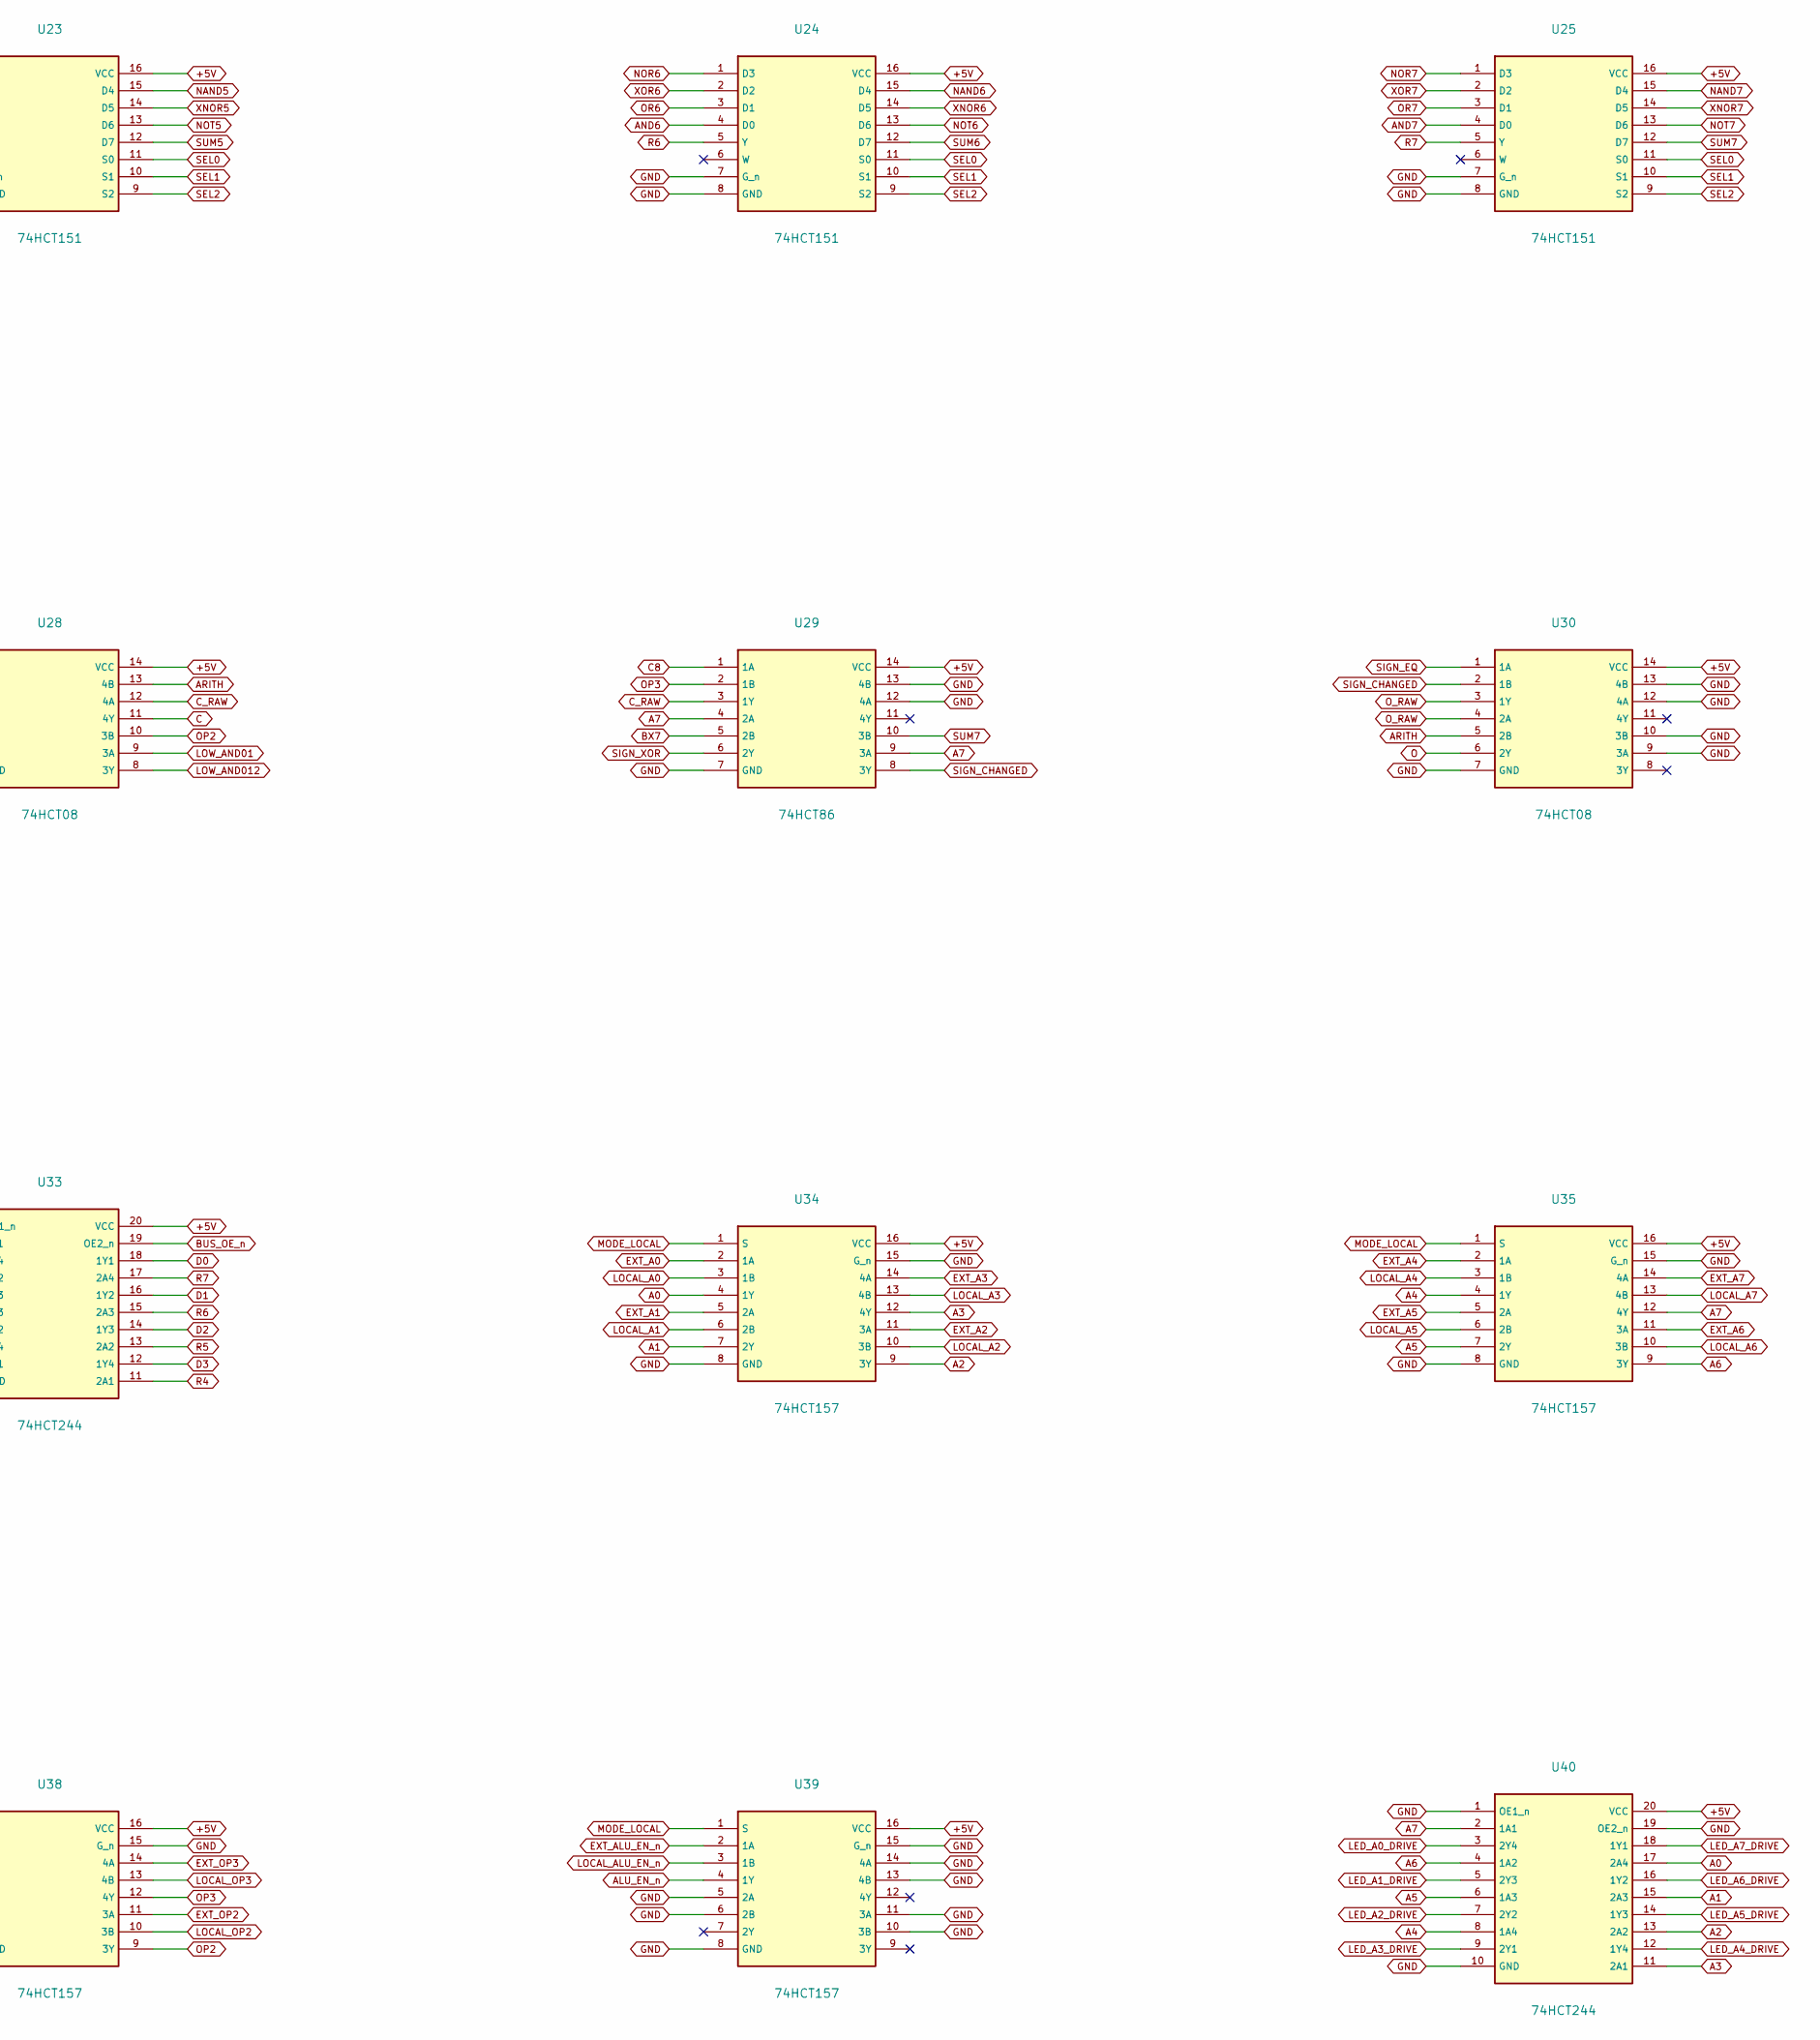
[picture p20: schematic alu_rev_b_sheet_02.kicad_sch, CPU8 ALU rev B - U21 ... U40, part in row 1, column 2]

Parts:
U21, U22, U23, U24, U25: 74HCT151; DIP-16_W7.62mm
U26, U27, U31, U32: 74HCT32; DIP-14_W7.62mm
U28, U30: 74HCT08; DIP-14_W7.62mm
U29: 74HCT86; DIP-14_W7.62mm
U33, U40: 74HCT244; DIP-20_W7.62mm
U34, U35, U36, U37, U38, U39: 74HCT157; DIP-16_W7.62mm

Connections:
+5V: U21.16 (VCC), U22.16 (VCC), U23.16 (VCC), U24.16 (VCC), U25.16 (VCC), U26.14 (VCC), U27.14 (VCC), U28.14 (VCC), U29.14 (VCC), U30.14 (VCC), U31.14 (VCC), U32.14 (VCC), U33.20 (VCC), U34.16 (VCC), U35.16 (VCC), U36.16 (VCC), U37.16 (VCC), U38.16 (VCC), U39.16 (VCC), U40.20 (VCC); also elsewhere on the board
A0: U34.4 (1Y), U40.17 (2A4); also elsewhere on the board
A1: U34.7 (2Y), U40.15 (2A3); also elsewhere on the board
A2: U34.9 (3Y), U40.13 (2A2); also elsewhere on the board
A3: U34.12 (4Y), U40.11 (2A1); also elsewhere on the board
A4: U35.4 (1Y), U40.8 (1A4); also elsewhere on the board
A5: U35.7 (2Y), U40.6 (1A3); also elsewhere on the board
A6: U35.9 (3Y), U40.4 (1A2); also elsewhere on the board
A7: U29.4 (2A), U29.9 (3A), U35.12 (4Y), U40.2 (1A1); also elsewhere on the board
ALU_EN_n: U27.4 (2A), U39.4 (1Y)
AND3: U21.4 (D0); also elsewhere on the board
AND4: U22.4 (D0); also elsewhere on the board
AND5: U23.4 (D0); also elsewhere on the board
AND6: U24.4 (D0); also elsewhere on the board
AND7: U25.4 (D0); also elsewhere on the board
ARITH: U27.8 (3Y), U28.13 (4B), U30.5 (2B)
B0: U36.4 (1Y); also elsewhere on the board
B1: U36.7 (2Y); also elsewhere on the board
B2: U36.9 (3Y); also elsewhere on the board
B3: U36.12 (4Y); also elsewhere on the board
B4: U37.4 (1Y); also elsewhere on the board
B5: U37.7 (2Y); also elsewhere on the board
B6: U37.9 (3Y); also elsewhere on the board
B7: U37.12 (4Y); also elsewhere on the board
BUS_OE_n: U27.6 (2Y), U33.1 (OE1_n), U33.19 (OE2_n)
BX7: U29.5 (2B); also elsewhere on the board
C: U28.11 (4Y); also elsewhere on the board
C8: U29.1 (1A); also elsewhere on the board
C_RAW: U28.12 (4A), U29.3 (1Y)
D0: U33.18 (1Y1); also elsewhere on the board
D1: U33.16 (1Y2); also elsewhere on the board
D2: U33.14 (1Y3); also elsewhere on the board
D3: U33.12 (1Y4); also elsewhere on the board
D4: U33.9 (2Y1); also elsewhere on the board
D5: U33.7 (2Y2); also elsewhere on the board
D6: U33.5 (2Y3); also elsewhere on the board
D7: U33.3 (2Y4); also elsewhere on the board
EXT_A0: U34.2 (1A); also elsewhere on the board
EXT_A1: U34.5 (2A); also elsewhere on the board
EXT_A2: U34.11 (3A); also elsewhere on the board
EXT_A3: U34.14 (4A); also elsewhere on the board
EXT_A4: U35.2 (1A); also elsewhere on the board
EXT_A5: U35.5 (2A); also elsewhere on the board
EXT_A6: U35.11 (3A); also elsewhere on the board
EXT_A7: U35.14 (4A); also elsewhere on the board
EXT_ALU_EN_n: U39.2 (1A); also elsewhere on the board
EXT_B0: U36.2 (1A); also elsewhere on the board
EXT_B1: U36.5 (2A); also elsewhere on the board
EXT_B2: U36.11 (3A); also elsewhere on the board
EXT_B3: U36.14 (4A); also elsewhere on the board
EXT_B4: U37.2 (1A); also elsewhere on the board
EXT_B5: U37.5 (2A); also elsewhere on the board
EXT_B6: U37.11 (3A); also elsewhere on the board
EXT_B7: U37.14 (4A); also elsewhere on the board
EXT_OP0: U38.2 (1A); also elsewhere on the board
EXT_OP1: U38.5 (2A); also elsewhere on the board
EXT_OP2: U38.11 (3A); also elsewhere on the board
EXT_OP3: U38.14 (4A); also elsewhere on the board
GND: U21.7 (G_n), U21.8 (GND), U22.7 (G_n), U22.8 (GND), U23.7 (G_n), U23.8 (GND), U24.7 (G_n), U24.8 (GND), U25.7 (G_n), U25.8 (GND), U26.7 (GND), U27.7 (GND), U28.7 (GND), U29.7 (GND), U29.12 (4A), U29.13 (4B), U30.7 (GND), U30.9 (3A), U30.10 (3B), U30.12 (4A), U30.13 (4B), U31.7 (GND), U32.7 (GND), U32.9 (3A), U32.10 (3B), U32.12 (4A), U32.13 (4B), U33.10 (GND), U34.8 (GND), U34.15 (G_n), U35.8 (GND), U35.15 (G_n), U36.8 (GND), U36.15 (G_n), U37.8 (GND), U37.15 (G_n), U38.8 (GND), U38.15 (G_n), U39.5 (2A), U39.6 (2B), U39.8 (GND), U39.10 (3B), U39.11 (3A), U39.13 (4B), U39.14 (4A), U39.15 (G_n), U40.1 (OE1_n), U40.10 (GND), U40.19 (OE2_n); also elsewhere on the board
LED_A0_DRIVE: U40.3 (2Y4); also elsewhere on the board
LED_A1_DRIVE: U40.5 (2Y3); also elsewhere on the board
LED_A2_DRIVE: U40.7 (2Y2); also elsewhere on the board
LED_A3_DRIVE: U40.9 (2Y1); also elsewhere on the board
LED_A4_DRIVE: U40.12 (1Y4); also elsewhere on the board
LED_A5_DRIVE: U40.14 (1Y3); also elsewhere on the board
LED_A6_DRIVE: U40.16 (1Y2); also elsewhere on the board
LED_A7_DRIVE: U40.18 (1Y1); also elsewhere on the board
LOCAL_A0: U34.3 (1B); also elsewhere on the board
LOCAL_A1: U34.6 (2B); also elsewhere on the board
LOCAL_A2: U34.10 (3B); also elsewhere on the board
LOCAL_A3: U34.13 (4B); also elsewhere on the board
LOCAL_A4: U35.3 (1B); also elsewhere on the board
LOCAL_A5: U35.6 (2B); also elsewhere on the board
LOCAL_A6: U35.10 (3B); also elsewhere on the board
LOCAL_A7: U35.13 (4B); also elsewhere on the board
LOCAL_ALU_EN_n: U39.3 (1B); also elsewhere on the board
LOCAL_B0: U36.3 (1B); also elsewhere on the board
LOCAL_B1: U36.6 (2B); also elsewhere on the board
LOCAL_B2: U36.10 (3B); also elsewhere on the board
LOCAL_B3: U36.13 (4B); also elsewhere on the board
LOCAL_B4: U37.3 (1B); also elsewhere on the board
LOCAL_B5: U37.6 (2B); also elsewhere on the board
LOCAL_B6: U37.10 (3B); also elsewhere on the board
LOCAL_B7: U37.13 (4B); also elsewhere on the board
LOCAL_OP0: U38.3 (1B); also elsewhere on the board
LOCAL_OP1: U38.6 (2B); also elsewhere on the board
LOCAL_OP2: U38.10 (3B); also elsewhere on the board
LOCAL_OP3: U38.13 (4B); also elsewhere on the board
LOW01: U26.11 (4Y), U27.1 (1A)
LOW_AND01: U28.6 (2Y), U28.9 (3A)
LOW_AND012: U27.9 (3A), U28.8 (3Y)
LOW_ANY: U27.3 (1Y), U28.2 (1B)
MODE_LOCAL: U34.1 (S), U35.1 (S), U36.1 (S), U37.1 (S), U38.1 (S), U39.1 (S); also elsewhere on the board
NAND3: U21.15 (D4); also elsewhere on the board
NAND4: U22.15 (D4); also elsewhere on the board
NAND5: U23.15 (D4); also elsewhere on the board
NAND6: U24.15 (D4); also elsewhere on the board
NAND7: U25.15 (D4); also elsewhere on the board
NONZERO: U32.6 (2Y); also elsewhere on the board
NOR3: U21.1 (D3); also elsewhere on the board
NOR4: U22.1 (D3); also elsewhere on the board
NOR5: U23.1 (D3); also elsewhere on the board
NOR6: U24.1 (D3); also elsewhere on the board
NOR7: U25.1 (D3); also elsewhere on the board
NOT3: U21.13 (D6); also elsewhere on the board
NOT4: U22.13 (D6); also elsewhere on the board
NOT5: U23.13 (D6); also elsewhere on the board
NOT6: U24.13 (D6); also elsewhere on the board
NOT7: U25.13 (D6); also elsewhere on the board
NO_BUS_HIGH: U27.5 (2B), U28.3 (1Y)
O: U30.6 (2Y); also elsewhere on the board
OP0: U26.1 (1A), U26.12 (4A), U28.4 (2A), U38.4 (1Y); also elsewhere on the board
OP1: U26.4 (2A), U26.13 (4B), U28.5 (2B), U38.7 (2Y); also elsewhere on the board
OP2: U26.9 (3A), U27.2 (1B), U28.10 (3B), U38.9 (3Y); also elsewhere on the board
OP3: U26.2 (1B), U26.5 (2B), U26.10 (3B), U27.10 (3B), U28.1 (1A), U29.2 (1B), U38.12 (4Y); also elsewhere on the board
OR3: U21.3 (D1); also elsewhere on the board
OR4: U22.3 (D1); also elsewhere on the board
OR5: U23.3 (D1); also elsewhere on the board
OR6: U24.3 (D1); also elsewhere on the board
OR7: U25.3 (D1); also elsewhere on the board
O_RAW: U30.3 (1Y), U30.4 (2A)
R0: U27.12 (4A), U33.2 (1A1); also elsewhere on the board
R1: U27.13 (4B), U33.4 (1A2); also elsewhere on the board
R2: U31.1 (1A), U33.6 (1A3); also elsewhere on the board
R3: U21.5 (Y), U31.2 (1B), U33.8 (1A4); also elsewhere on the board
R4: U22.5 (Y), U31.4 (2A), U33.11 (2A1); also elsewhere on the board
R5: U23.5 (Y), U31.5 (2B), U33.13 (2A2); also elsewhere on the board
R6: U24.5 (Y), U31.9 (3A), U33.15 (2A3); also elsewhere on the board
R7: U25.5 (Y), U31.10 (3B), U33.17 (2A4); also elsewhere on the board
SEL0: U21.11 (S0), U22.11 (S0), U23.11 (S0), U24.11 (S0), U25.11 (S0), U26.3 (1Y); also elsewhere on the board
SEL1: U21.10 (S1), U22.10 (S1), U23.10 (S1), U24.10 (S1), U25.10 (S1), U26.6 (2Y); also elsewhere on the board
SEL2: U21.9 (S2), U22.9 (S2), U23.9 (S2), U24.9 (S2), U25.9 (S2), U26.8 (3Y); also elsewhere on the board
SIGN_CHANGED: U29.8 (3Y), U30.2 (1B)
SIGN_EQ: U30.1 (1A); also elsewhere on the board
SIGN_XOR: U29.6 (2Y); also elsewhere on the board
SUM3: U21.12 (D7); also elsewhere on the board
SUM4: U22.12 (D7); also elsewhere on the board
SUM5: U23.12 (D7); also elsewhere on the board
SUM6: U24.12 (D7); also elsewhere on the board
SUM7: U25.12 (D7), U29.10 (3B); also elsewhere on the board
XNOR3: U21.14 (D5); also elsewhere on the board
XNOR4: U22.14 (D5); also elsewhere on the board
XNOR5: U23.14 (D5); also elsewhere on the board
XNOR6: U24.14 (D5); also elsewhere on the board
XNOR7: U25.14 (D5); also elsewhere on the board
XOR3: U21.2 (D2); also elsewhere on the board
XOR4: U22.2 (D2); also elsewhere on the board
XOR5: U23.2 (D2); also elsewhere on the board
XOR6: U24.2 (D2); also elsewhere on the board
XOR7: U25.2 (D2); also elsewhere on the board
Z_HALF0: U31.11 (4Y), U32.4 (2A)
Z_HALF1: U32.3 (1Y), U32.5 (2B)
Z_PAIR0: U27.11 (4Y), U31.12 (4A)
Z_PAIR1: U31.3 (1Y), U31.13 (4B)
Z_PAIR2: U31.6 (2Y), U32.1 (1A)
Z_PAIR3: U31.8 (3Y), U32.2 (1B)

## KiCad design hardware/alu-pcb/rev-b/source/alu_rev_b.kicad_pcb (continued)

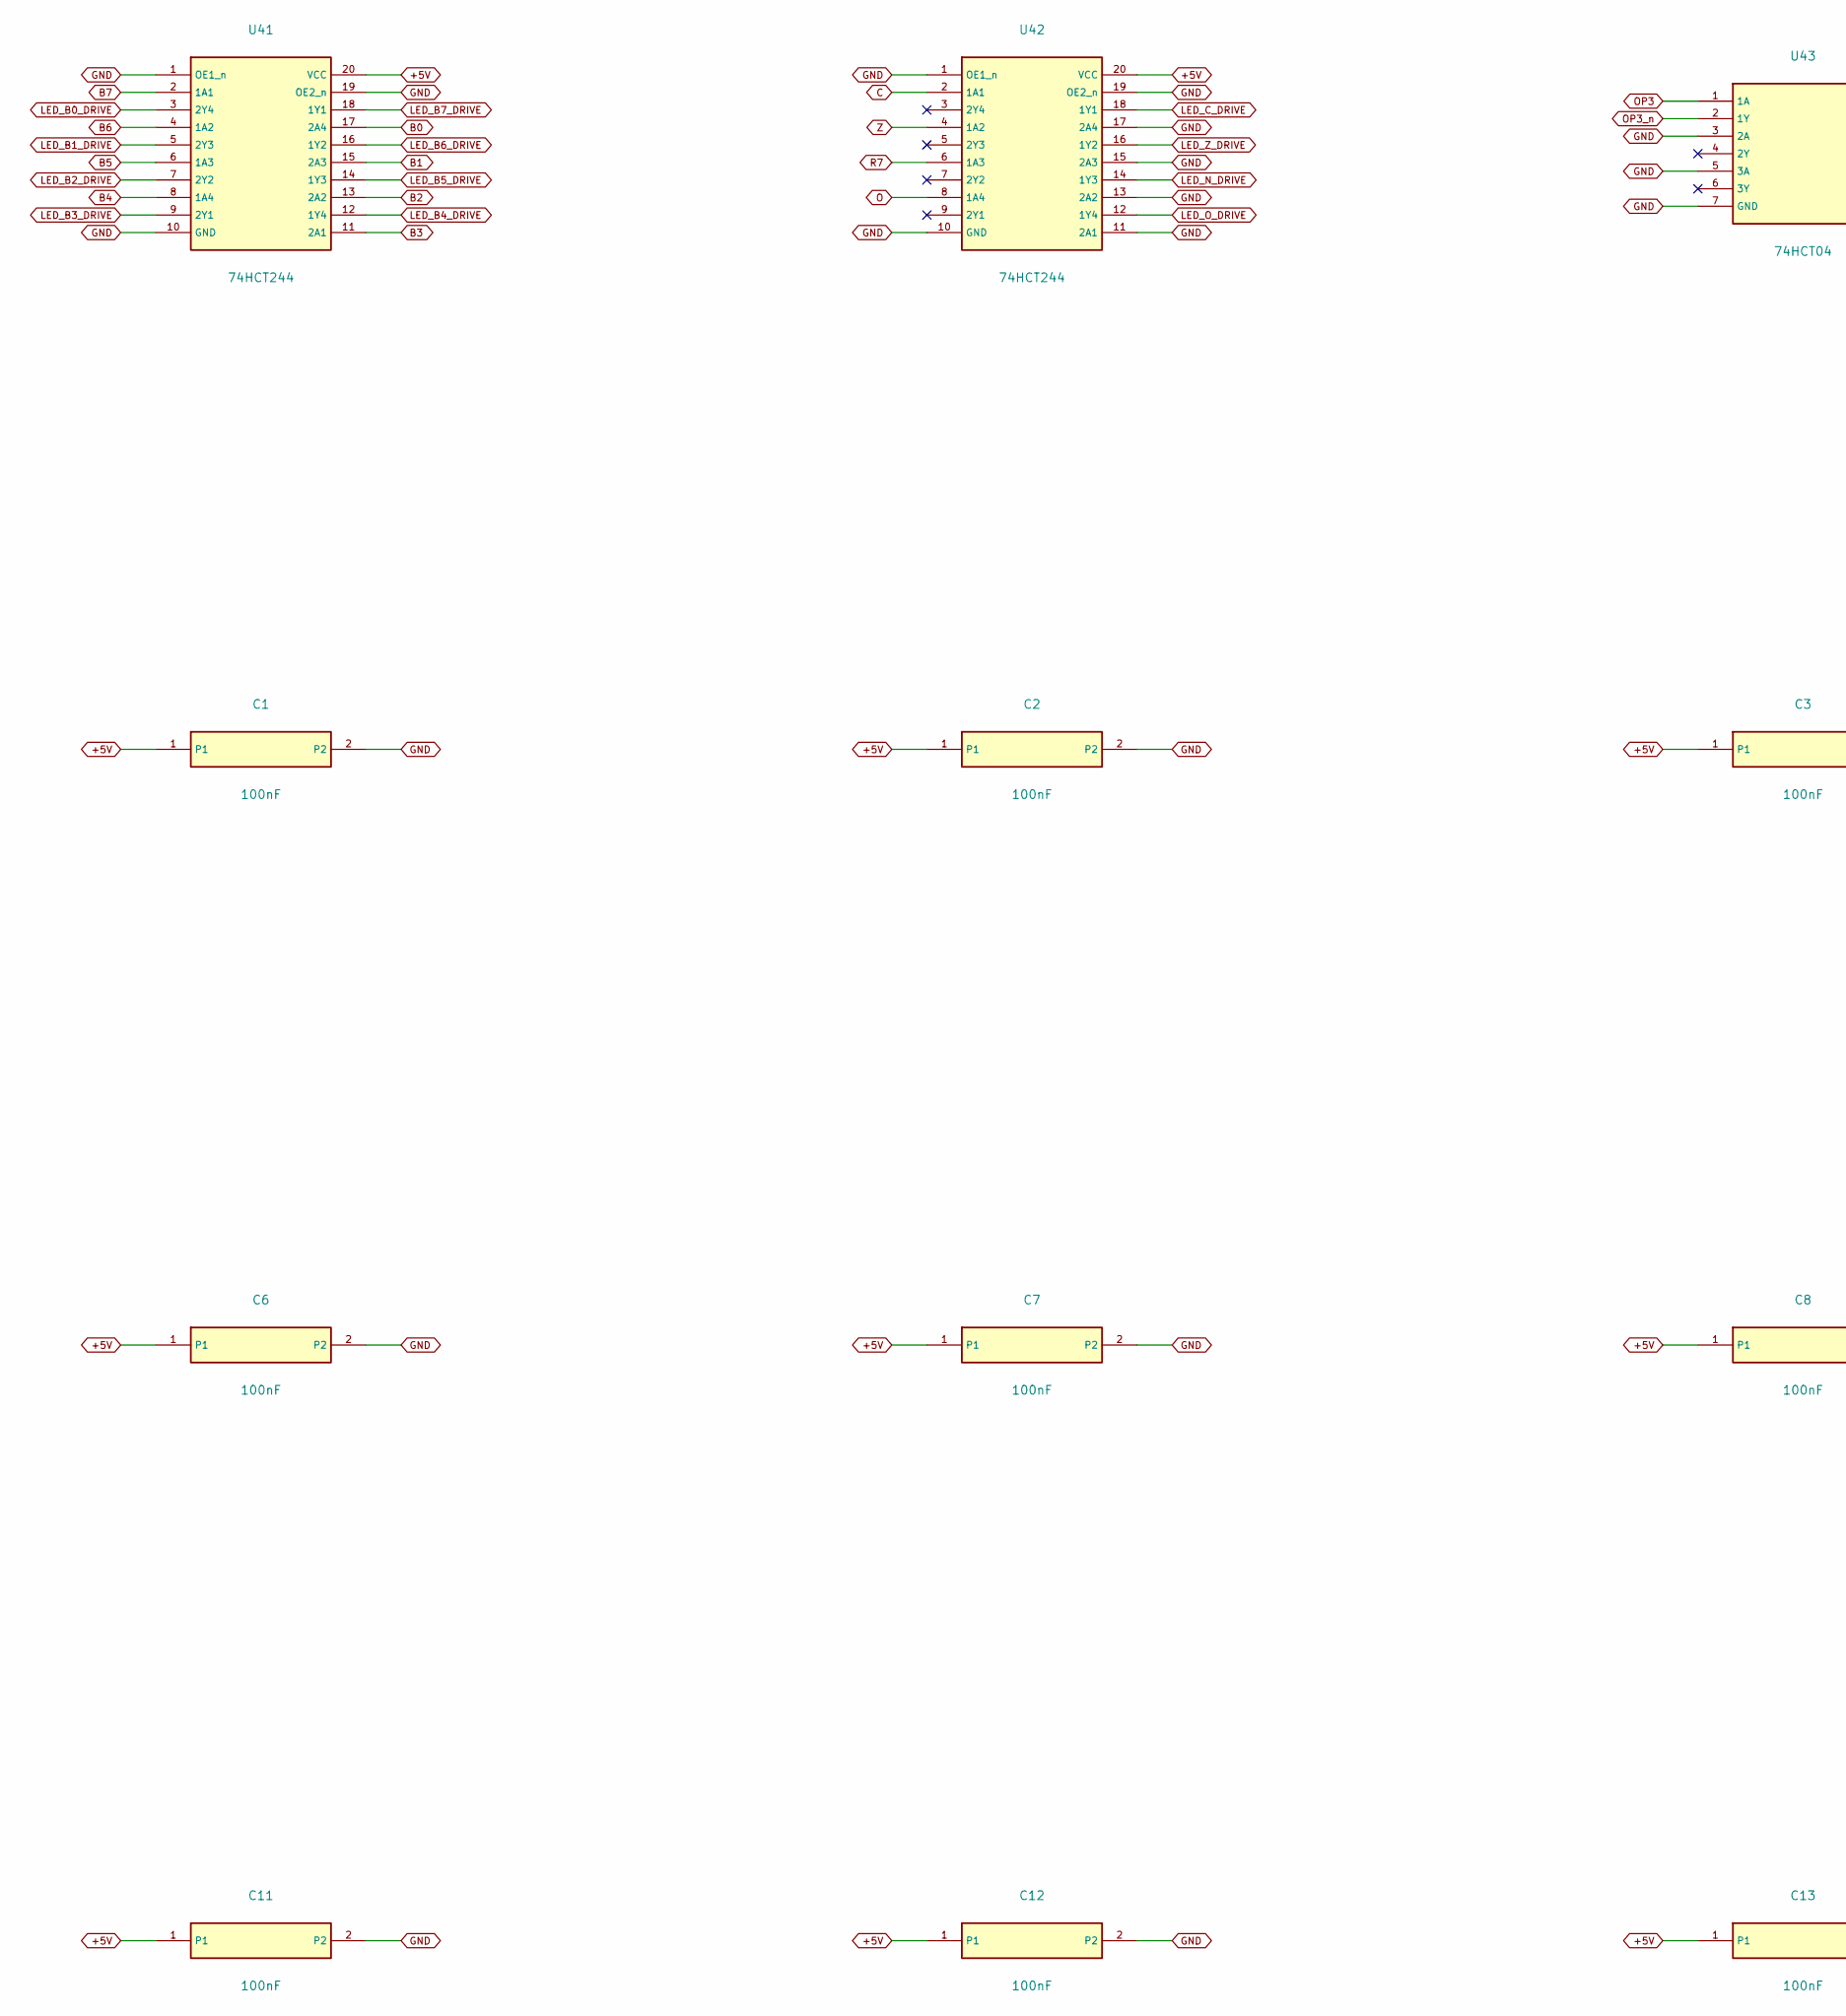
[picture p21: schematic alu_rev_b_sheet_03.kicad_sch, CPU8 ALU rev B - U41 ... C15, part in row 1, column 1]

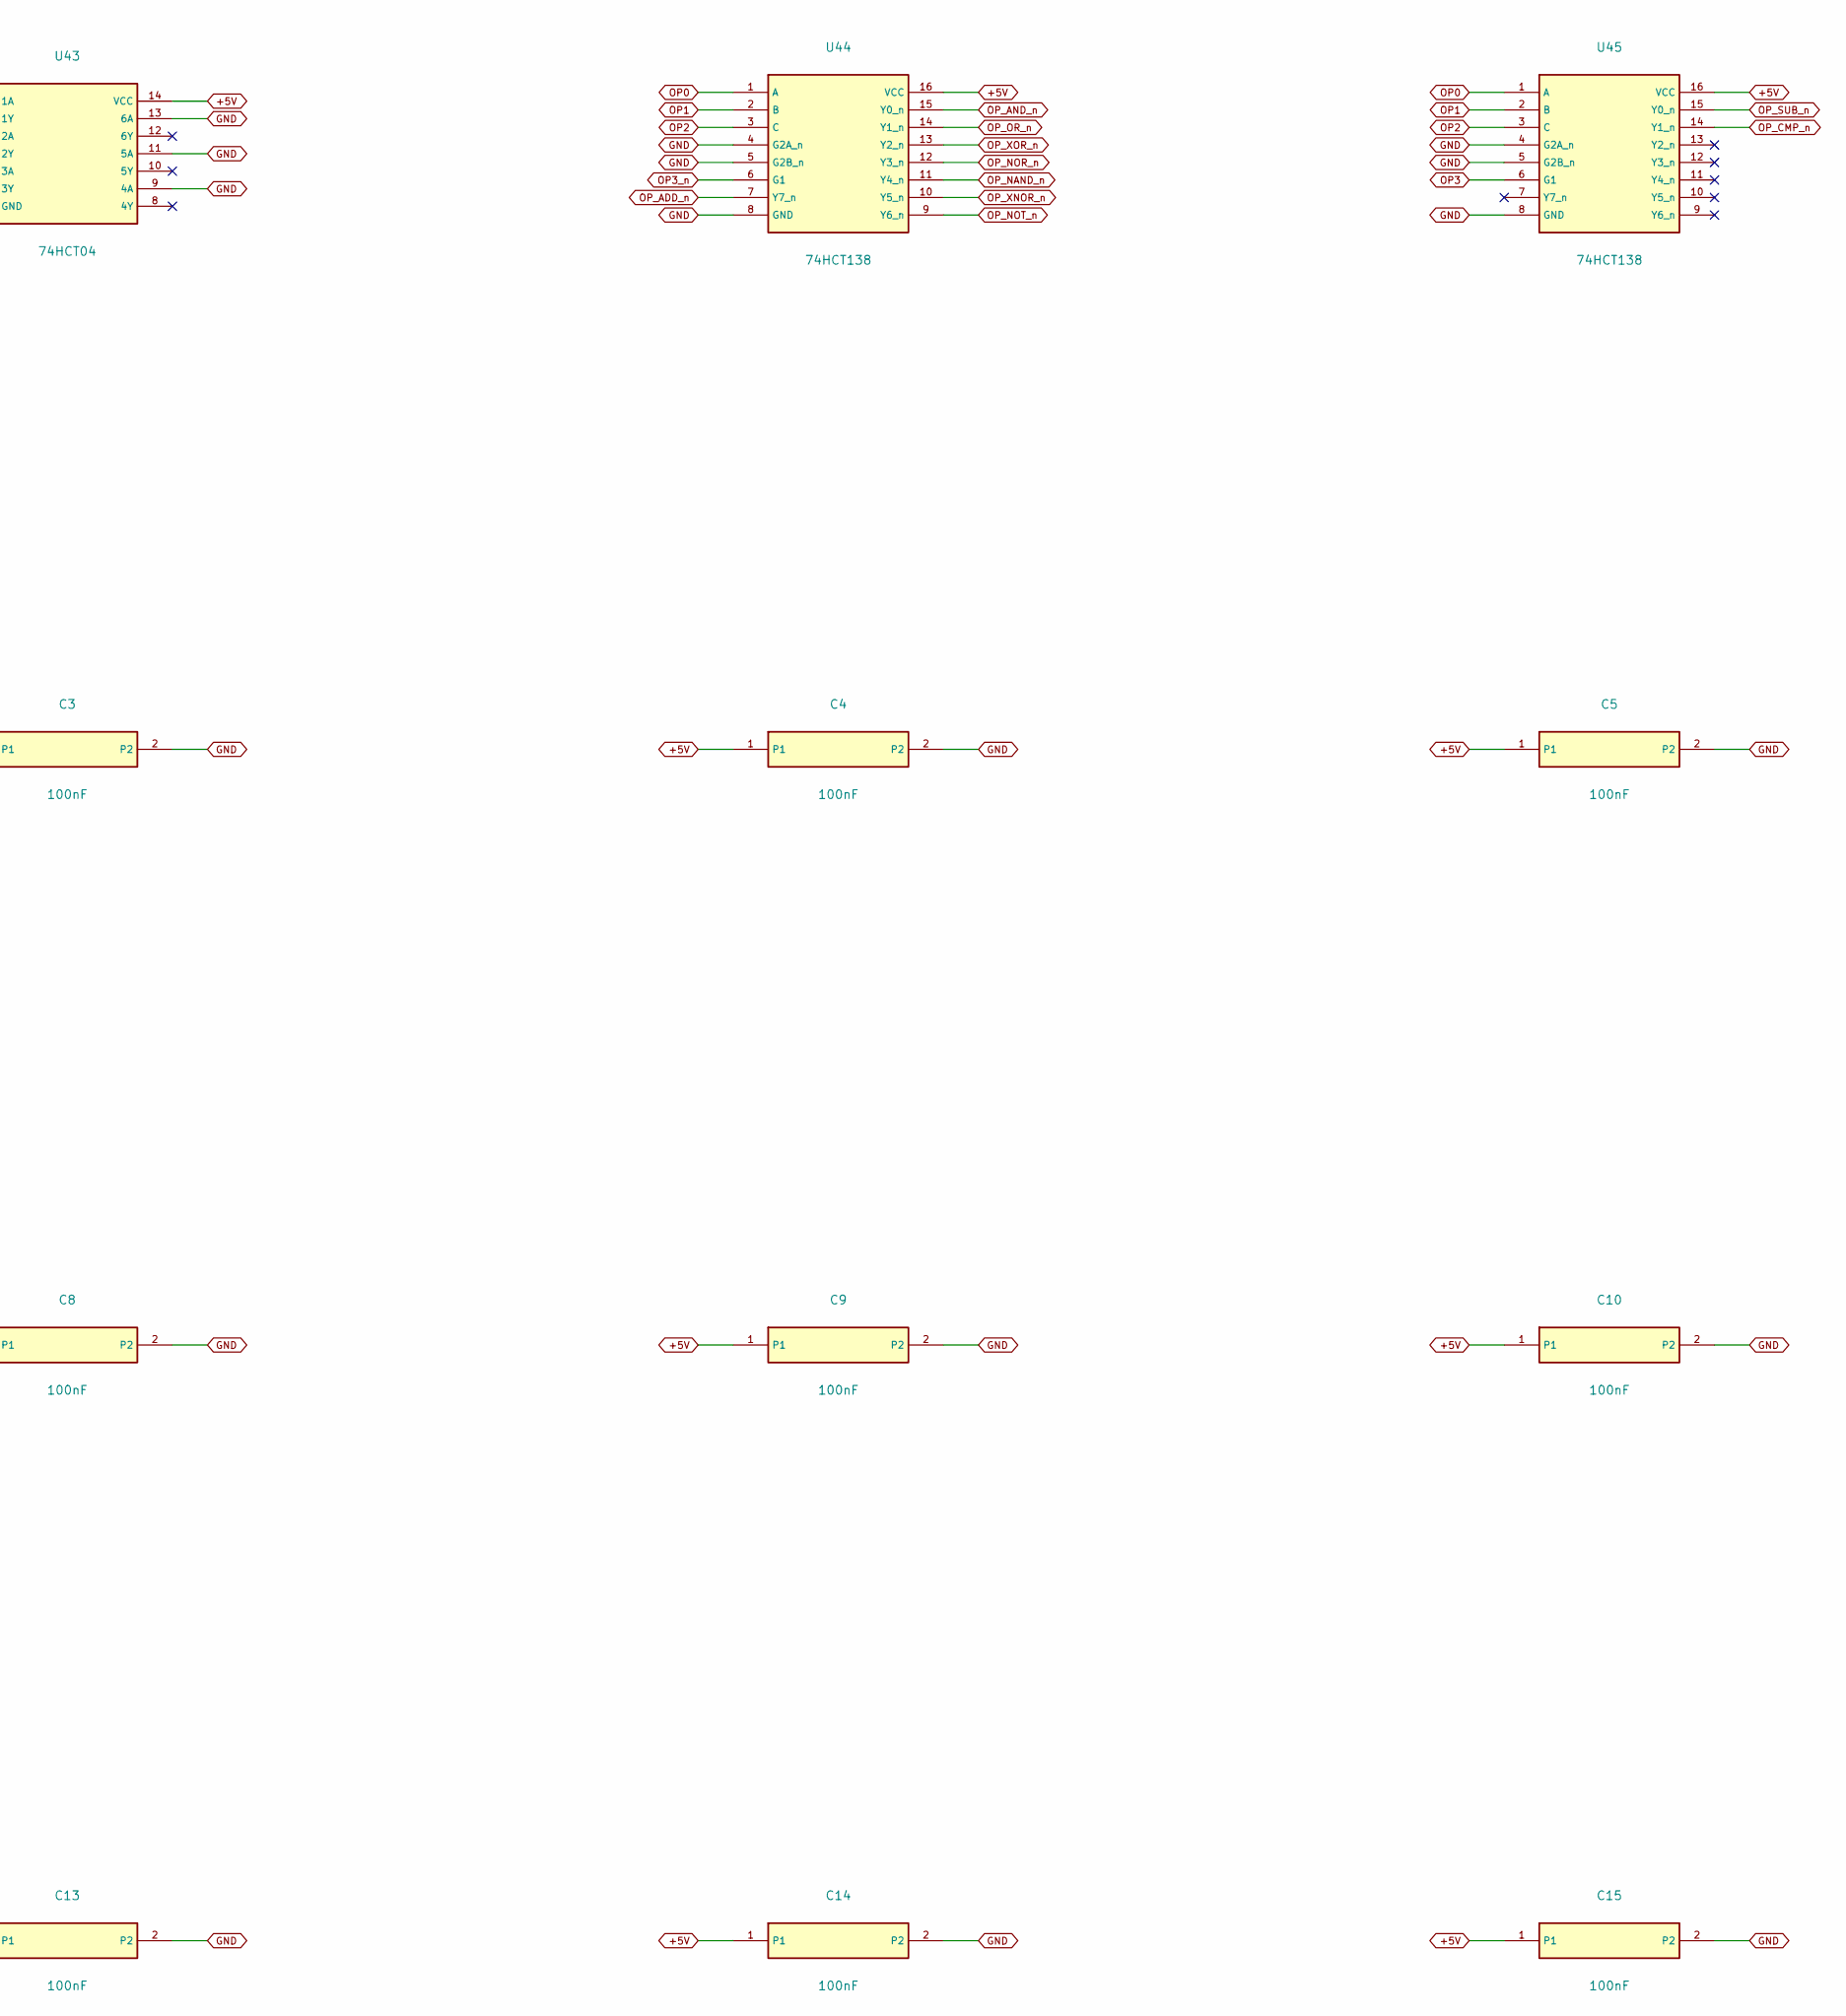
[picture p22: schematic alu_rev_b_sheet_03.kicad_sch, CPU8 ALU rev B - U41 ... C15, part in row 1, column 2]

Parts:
C1, C2, C3, C4, C5, C6, C7, C8, C9, C10, C11, C12, C13, C14, C15: 100nF; C_Disc_P2.50mm
U41, U42: 74HCT244; DIP-20_W7.62mm
U43: 74HCT04; DIP-14_W7.62mm
U44, U45: 74HCT138; DIP-16_W7.62mm

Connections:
+5V: C1.1, C2.1, C3.1, C4.1, C5.1, C6.1, C7.1, C8.1, C9.1, C10.1, C11.1, C12.1, C13.1, C14.1, C15.1, U41.20 (VCC), U42.20 (VCC), U43.14 (VCC), U44.16 (VCC), U45.16 (VCC); also elsewhere on the board
B0: U41.17 (2A4); also elsewhere on the board
B1: U41.15 (2A3); also elsewhere on the board
B2: U41.13 (2A2); also elsewhere on the board
B3: U41.11 (2A1); also elsewhere on the board
B4: U41.8 (1A4); also elsewhere on the board
B5: U41.6 (1A3); also elsewhere on the board
B6: U41.4 (1A2); also elsewhere on the board
B7: U41.2 (1A1); also elsewhere on the board
C: U42.2 (1A1); also elsewhere on the board
GND: C1.2, C2.2, C3.2, C4.2, C5.2, C6.2, C7.2, C8.2, C9.2, C10.2, C11.2, C12.2, C13.2, C14.2, C15.2, U41.1 (OE1_n), U41.10 (GND), U41.19 (OE2_n), U42.1 (OE1_n), U42.10 (GND), U42.11 (2A1), U42.13 (2A2), U42.15 (2A3), U42.17 (2A4), U42.19 (OE2_n), U43.3 (2A), U43.5 (3A), U43.7 (GND), U43.9 (4A), U43.11 (5A), U43.13 (6A), U44.4 (G2A_n), U44.5 (G2B_n), U44.8 (GND), U45.4 (G2A_n), U45.5 (G2B_n), U45.8 (GND); also elsewhere on the board
LED_B0_DRIVE: U41.3 (2Y4); also elsewhere on the board
LED_B1_DRIVE: U41.5 (2Y3); also elsewhere on the board
LED_B2_DRIVE: U41.7 (2Y2); also elsewhere on the board
LED_B3_DRIVE: U41.9 (2Y1); also elsewhere on the board
LED_B4_DRIVE: U41.12 (1Y4); also elsewhere on the board
LED_B5_DRIVE: U41.14 (1Y3); also elsewhere on the board
LED_B6_DRIVE: U41.16 (1Y2); also elsewhere on the board
LED_B7_DRIVE: U41.18 (1Y1); also elsewhere on the board
LED_C_DRIVE: U42.18 (1Y1); also elsewhere on the board
LED_N_DRIVE: U42.14 (1Y3); also elsewhere on the board
LED_O_DRIVE: U42.12 (1Y4); also elsewhere on the board
LED_Z_DRIVE: U42.16 (1Y2); also elsewhere on the board
O: U42.8 (1A4); also elsewhere on the board
OP0: U44.1 (A), U45.1 (A); also elsewhere on the board
OP1: U44.2 (B), U45.2 (B); also elsewhere on the board
OP2: U44.3 (C), U45.3 (C); also elsewhere on the board
OP3: U43.1 (1A), U45.6 (G1); also elsewhere on the board
OP3_n: U43.2 (1Y), U44.6 (G1)
OP_ADD_n: U44.7 (Y7_n); also elsewhere on the board
OP_AND_n: U44.15 (Y0_n); also elsewhere on the board
OP_CMP_n: U45.14 (Y1_n); also elsewhere on the board
OP_NAND_n: U44.11 (Y4_n); also elsewhere on the board
OP_NOR_n: U44.12 (Y3_n); also elsewhere on the board
OP_NOT_n: U44.9 (Y6_n); also elsewhere on the board
OP_OR_n: U44.14 (Y1_n); also elsewhere on the board
OP_SUB_n: U45.15 (Y0_n); also elsewhere on the board
OP_XNOR_n: U44.10 (Y5_n); also elsewhere on the board
OP_XOR_n: U44.13 (Y2_n); also elsewhere on the board
R7: U42.6 (1A3); also elsewhere on the board
Z: U42.4 (1A2); also elsewhere on the board

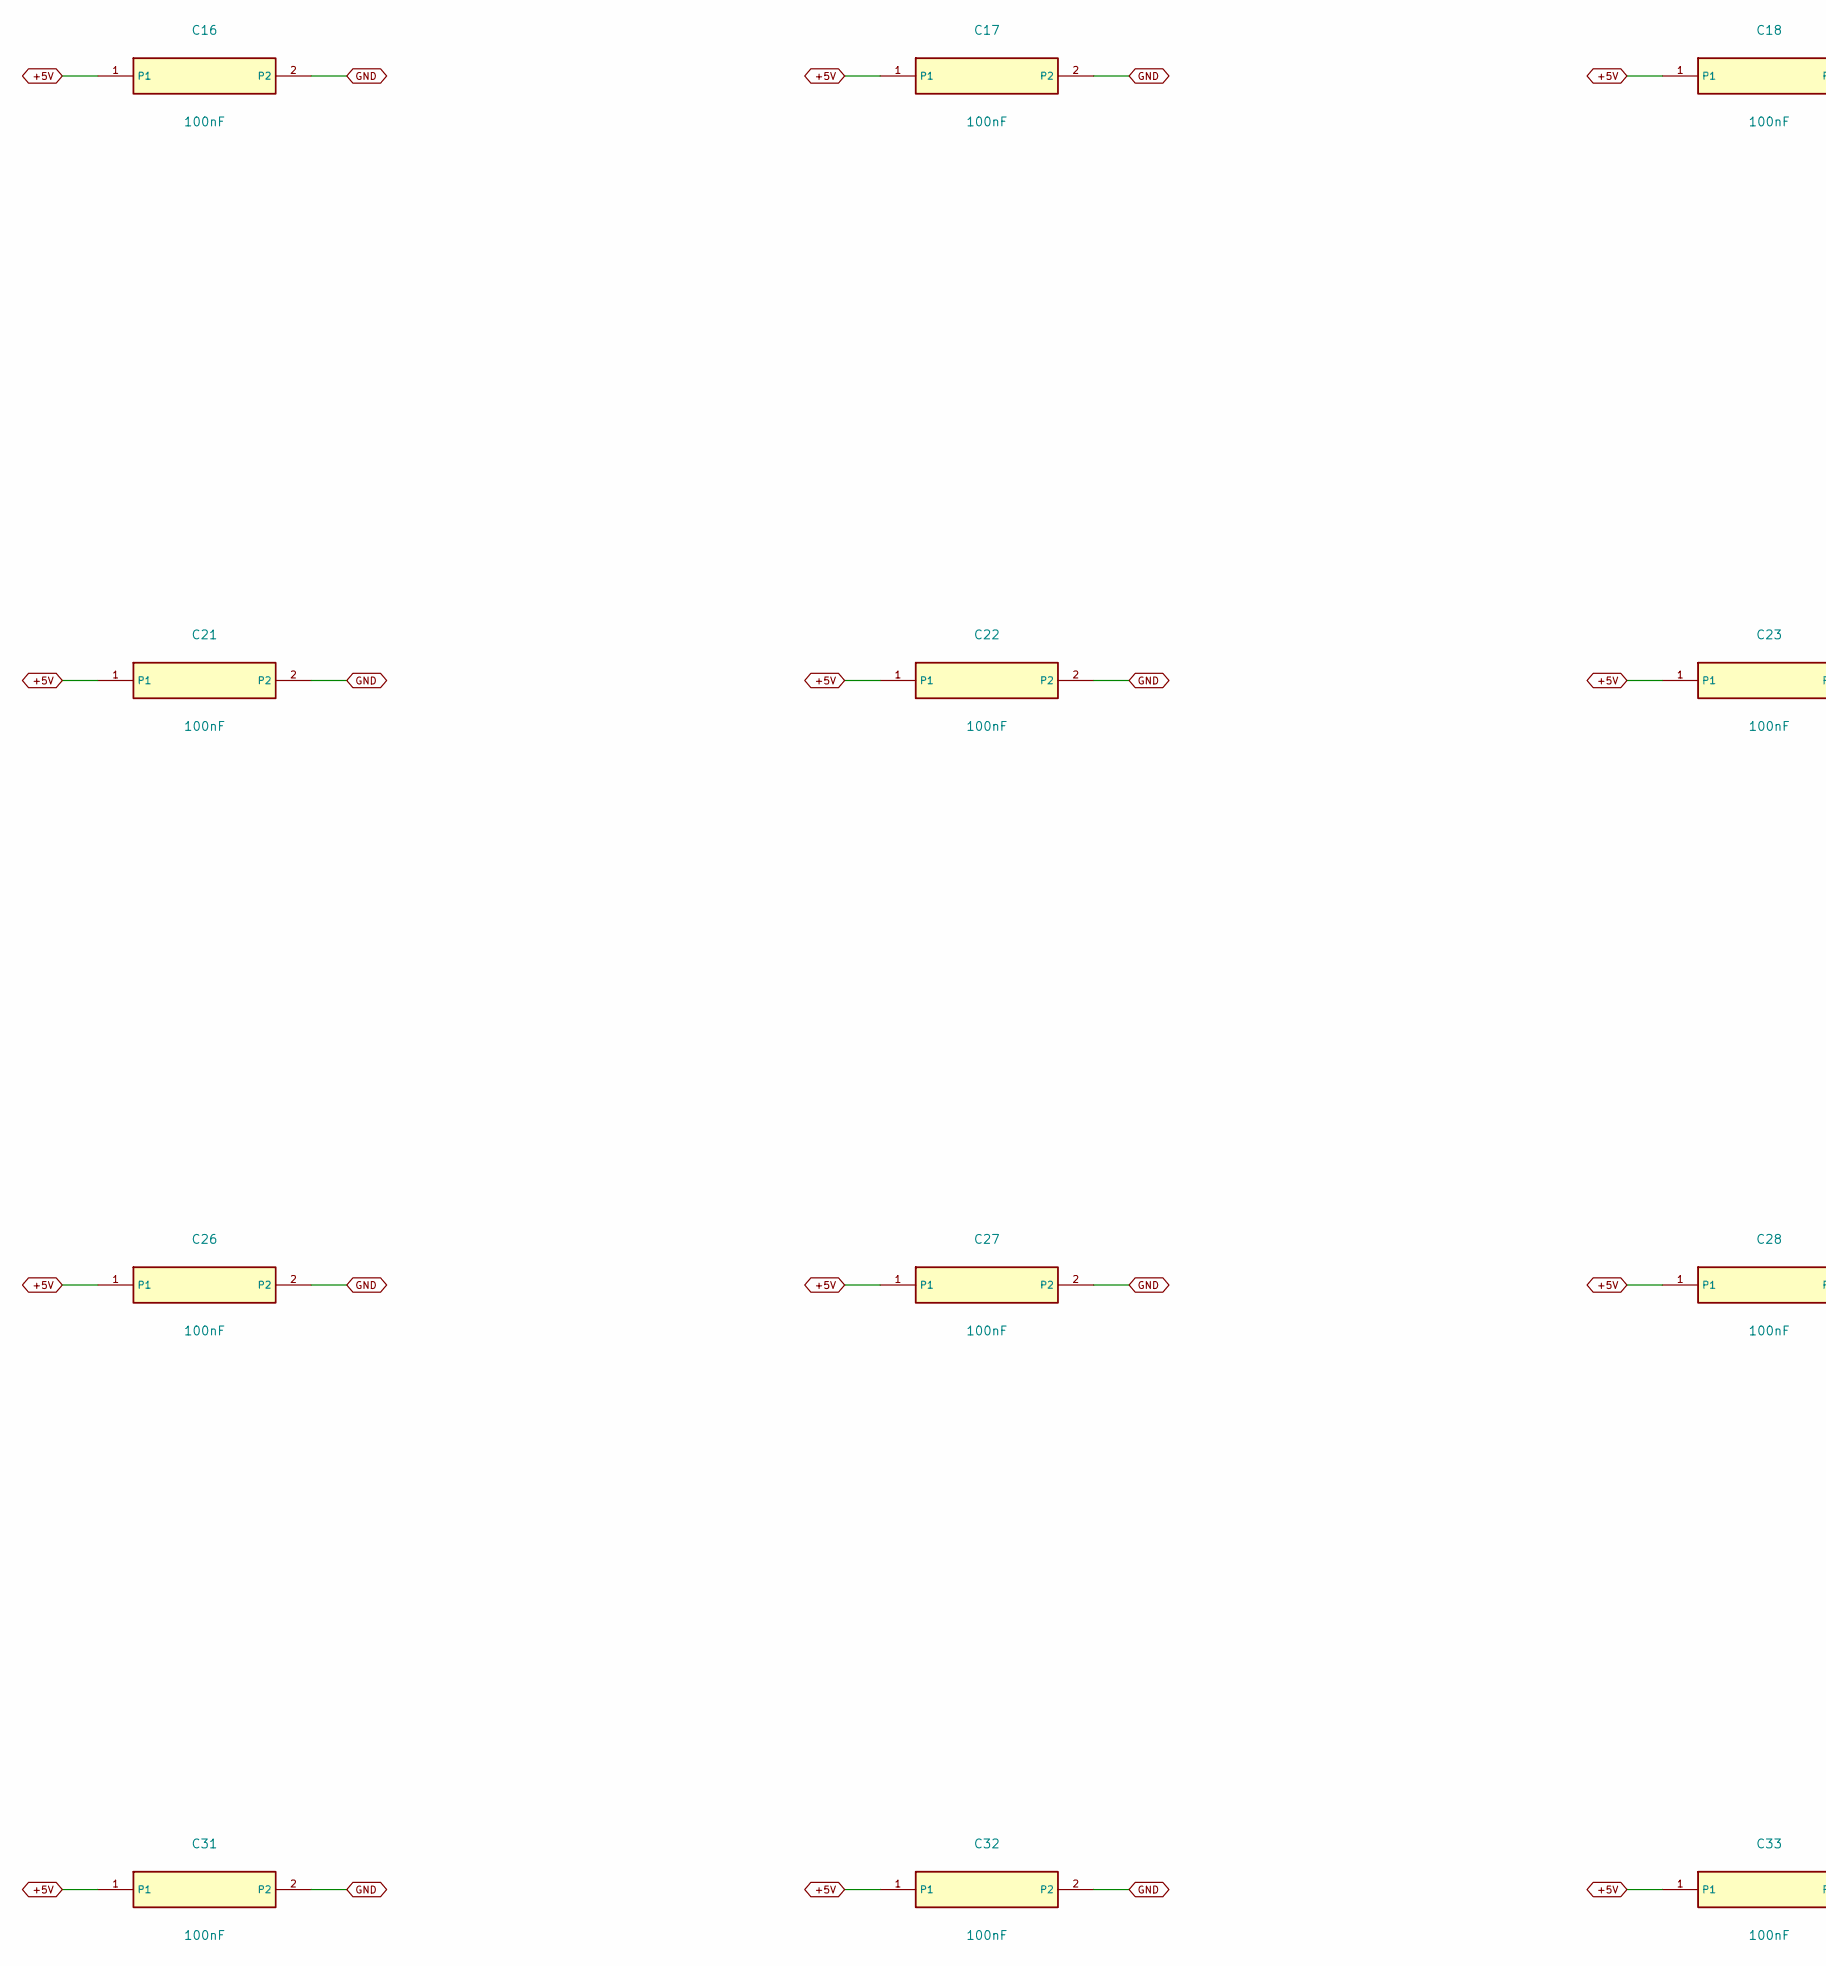
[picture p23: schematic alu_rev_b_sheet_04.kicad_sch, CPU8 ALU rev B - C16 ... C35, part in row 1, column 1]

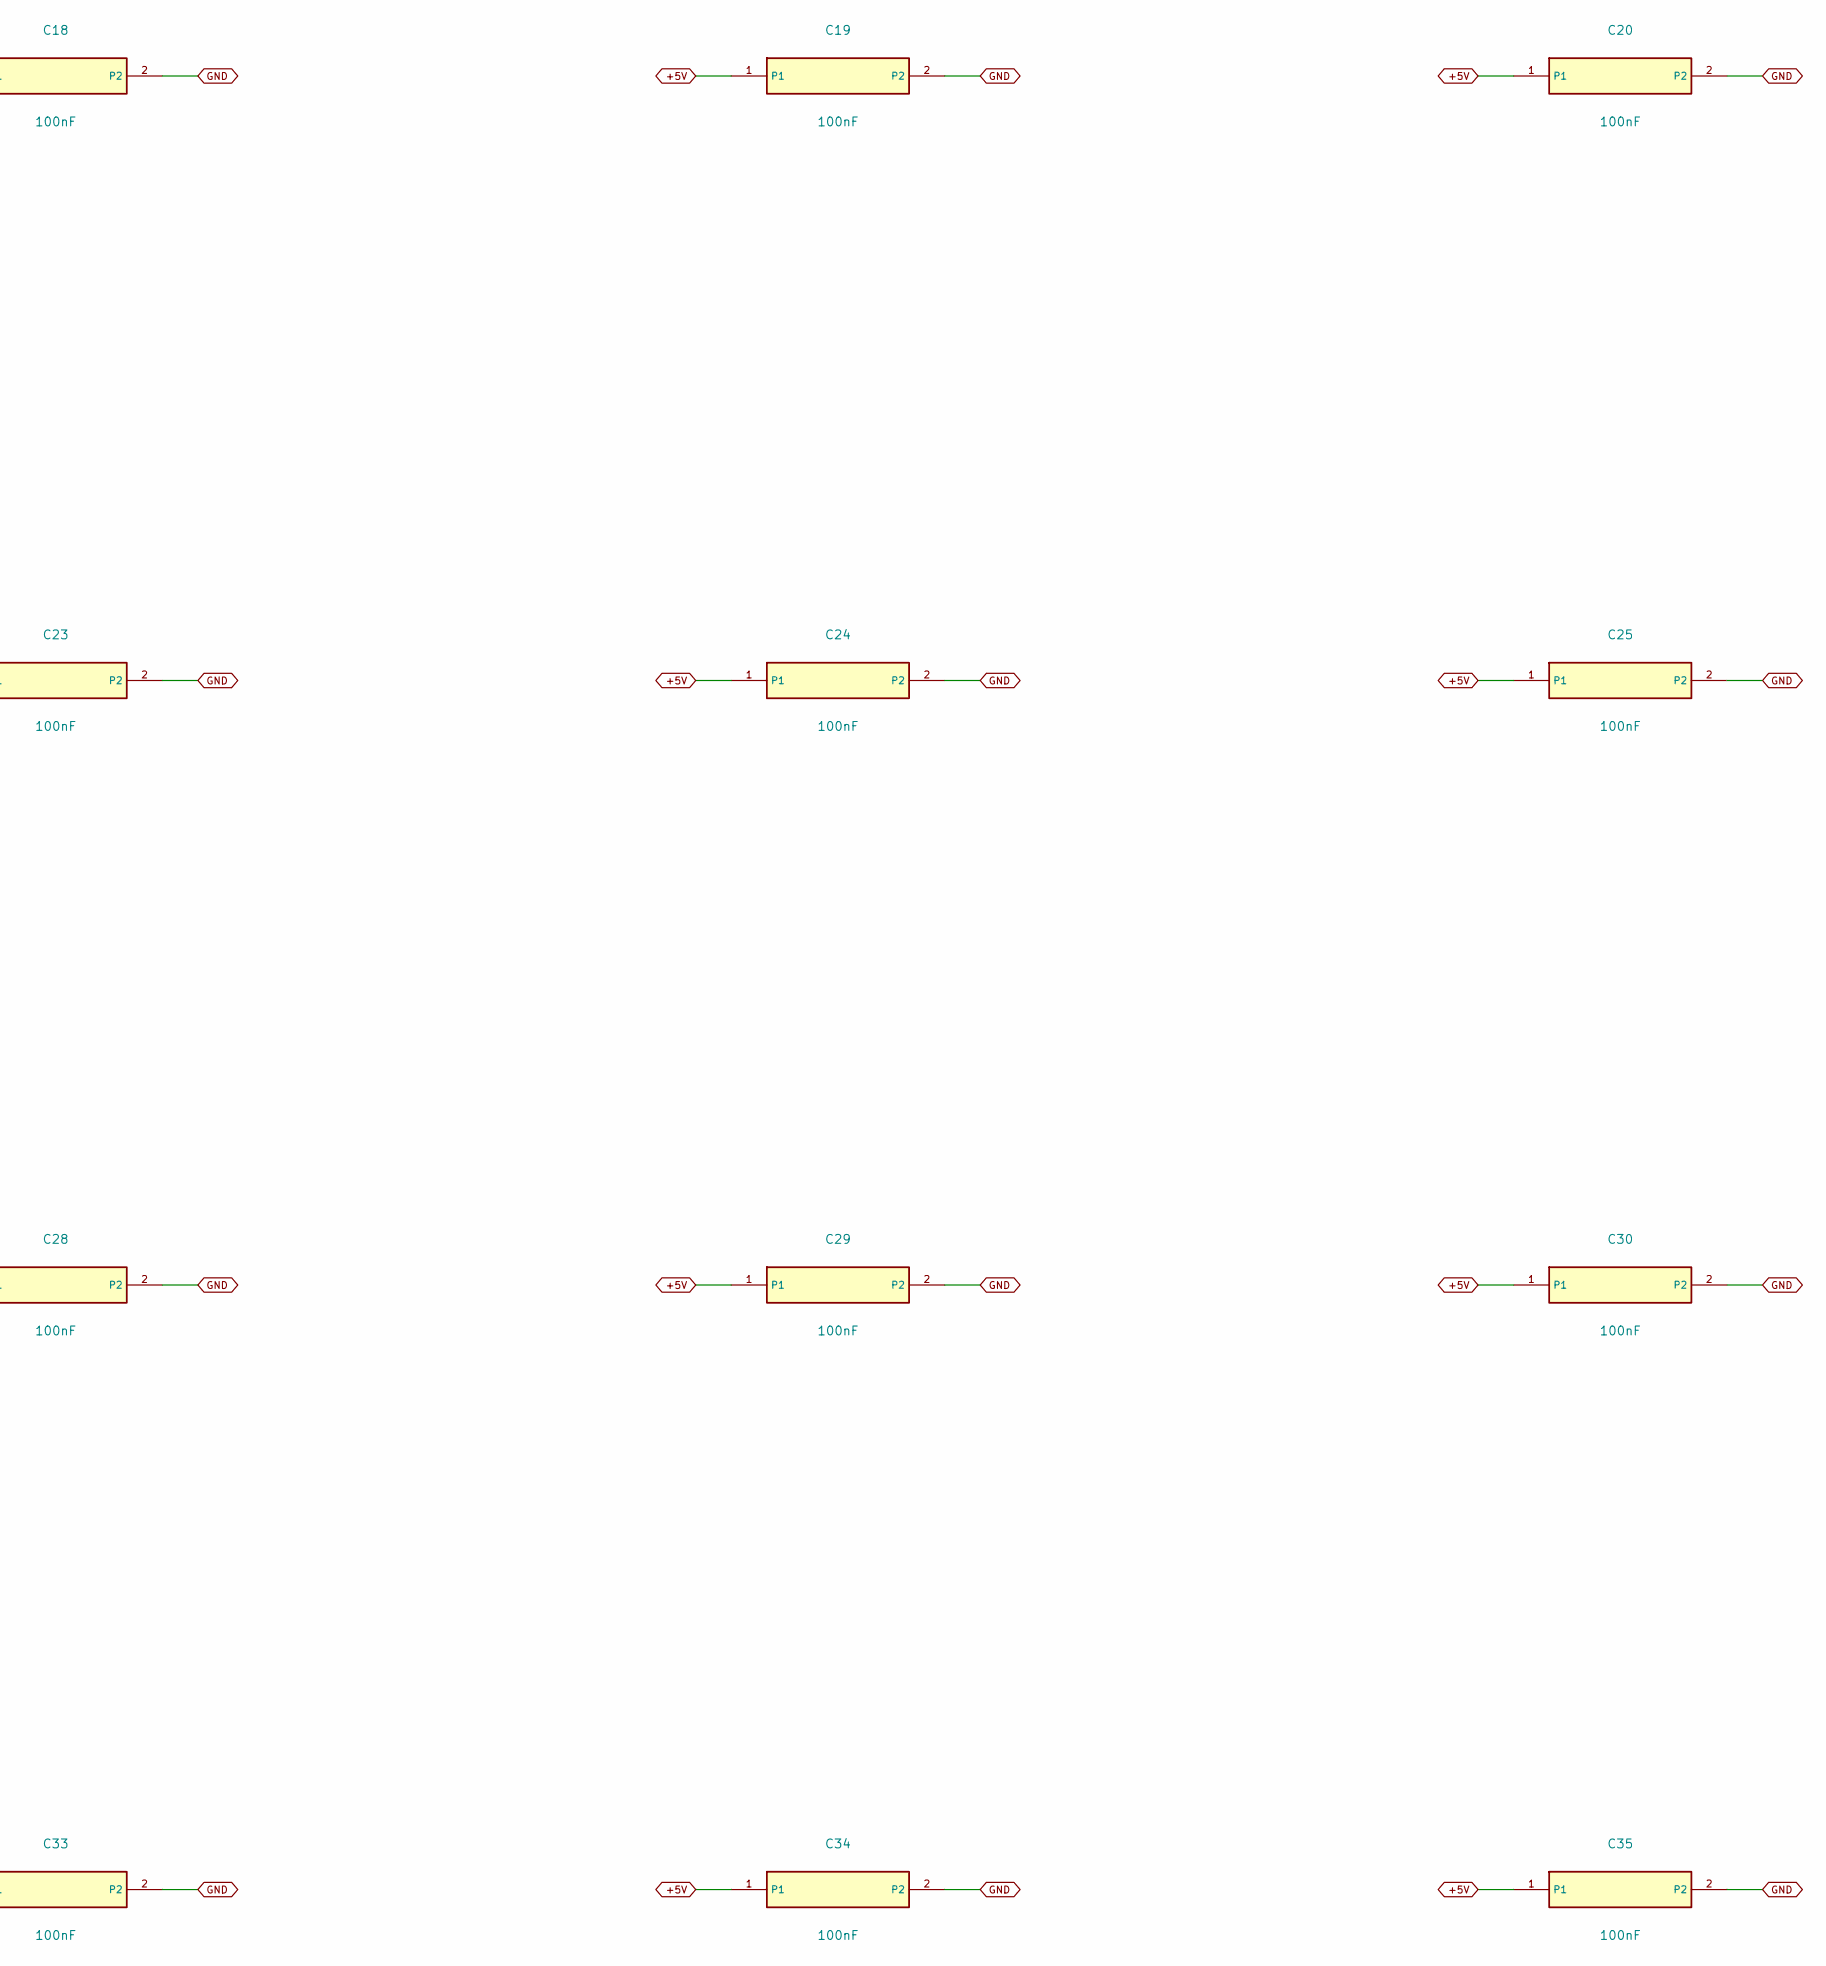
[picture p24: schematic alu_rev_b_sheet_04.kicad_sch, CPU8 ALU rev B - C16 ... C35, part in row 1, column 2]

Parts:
C16, C17, C18, C19, C20, C21, C22, C23, C24, C25, C26, C27, C28, C29, C30, C31, C32, C33, C34, C35: 100nF; C_Disc_P2.50mm

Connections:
+5V: C16.1, C17.1, C18.1, C19.1, C20.1, C21.1, C22.1, C23.1, C24.1, C25.1, C26.1, C27.1, C28.1, C29.1, C30.1, C31.1, C32.1, C33.1, C34.1, C35.1; also elsewhere on the board
GND: C16.2, C17.2, C18.2, C19.2, C20.2, C21.2, C22.2, C23.2, C24.2, C25.2, C26.2, C27.2, C28.2, C29.2, C30.2, C31.2, C32.2, C33.2, C34.2, C35.2; also elsewhere on the board

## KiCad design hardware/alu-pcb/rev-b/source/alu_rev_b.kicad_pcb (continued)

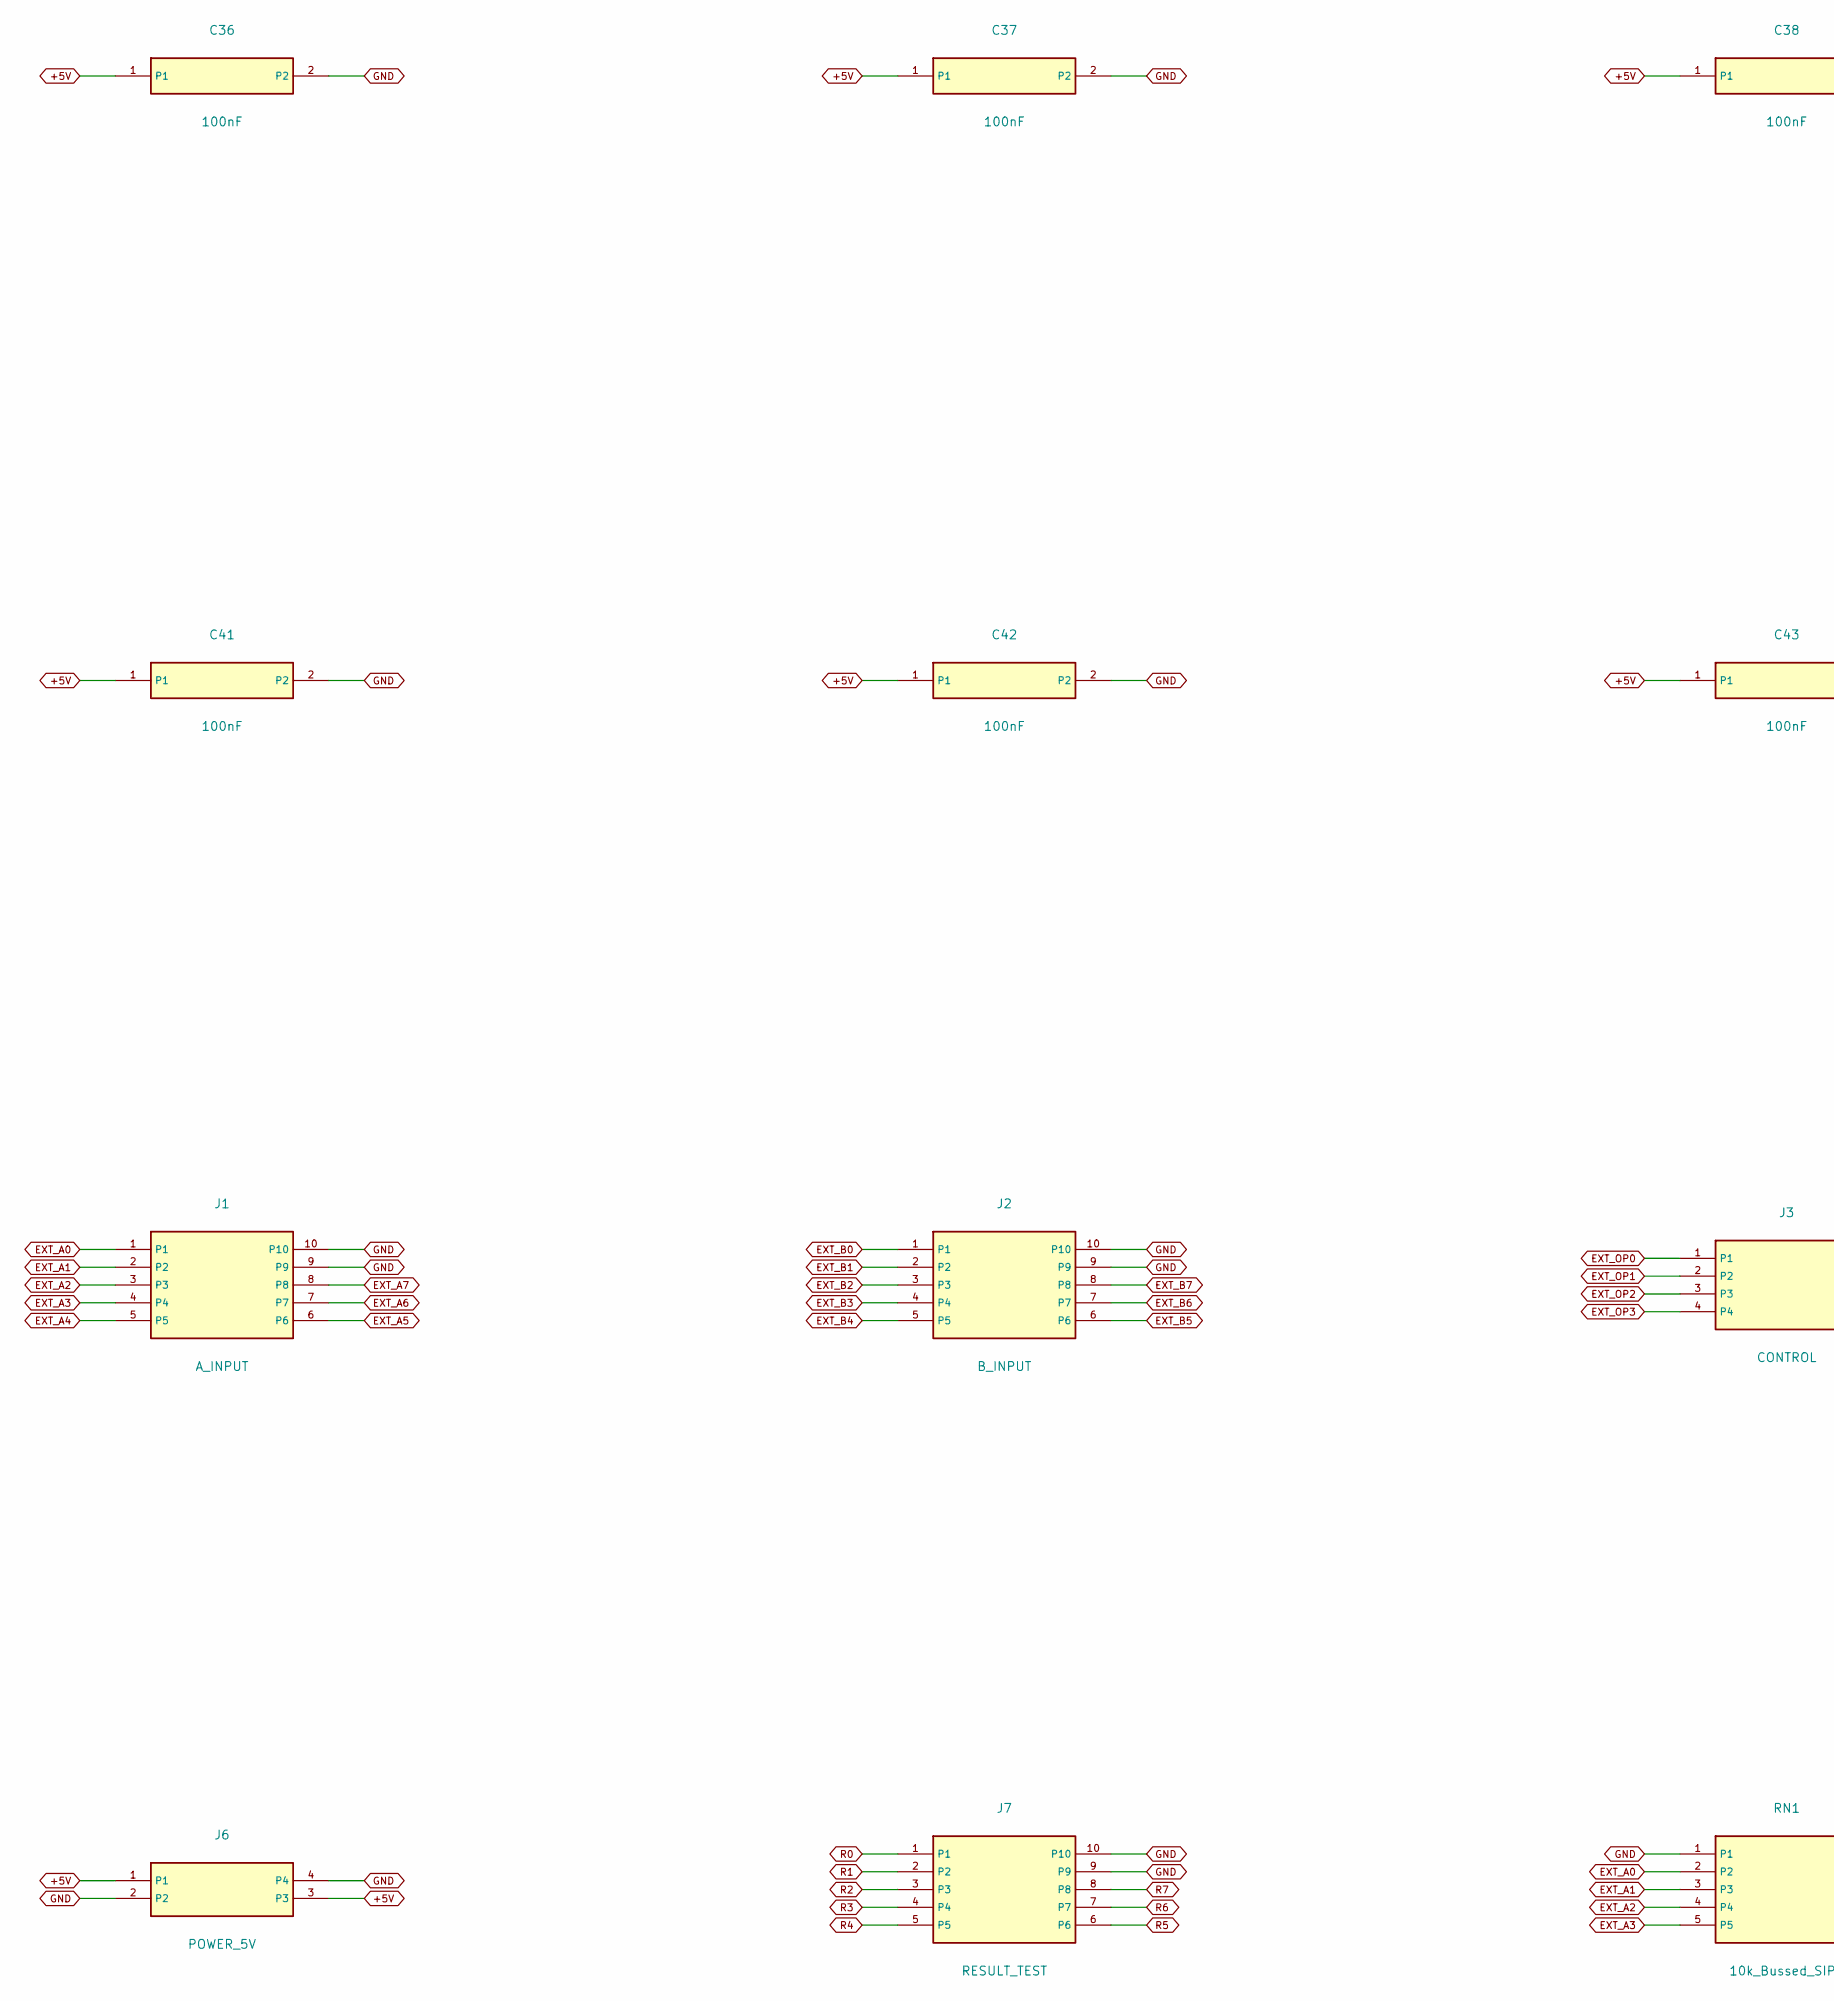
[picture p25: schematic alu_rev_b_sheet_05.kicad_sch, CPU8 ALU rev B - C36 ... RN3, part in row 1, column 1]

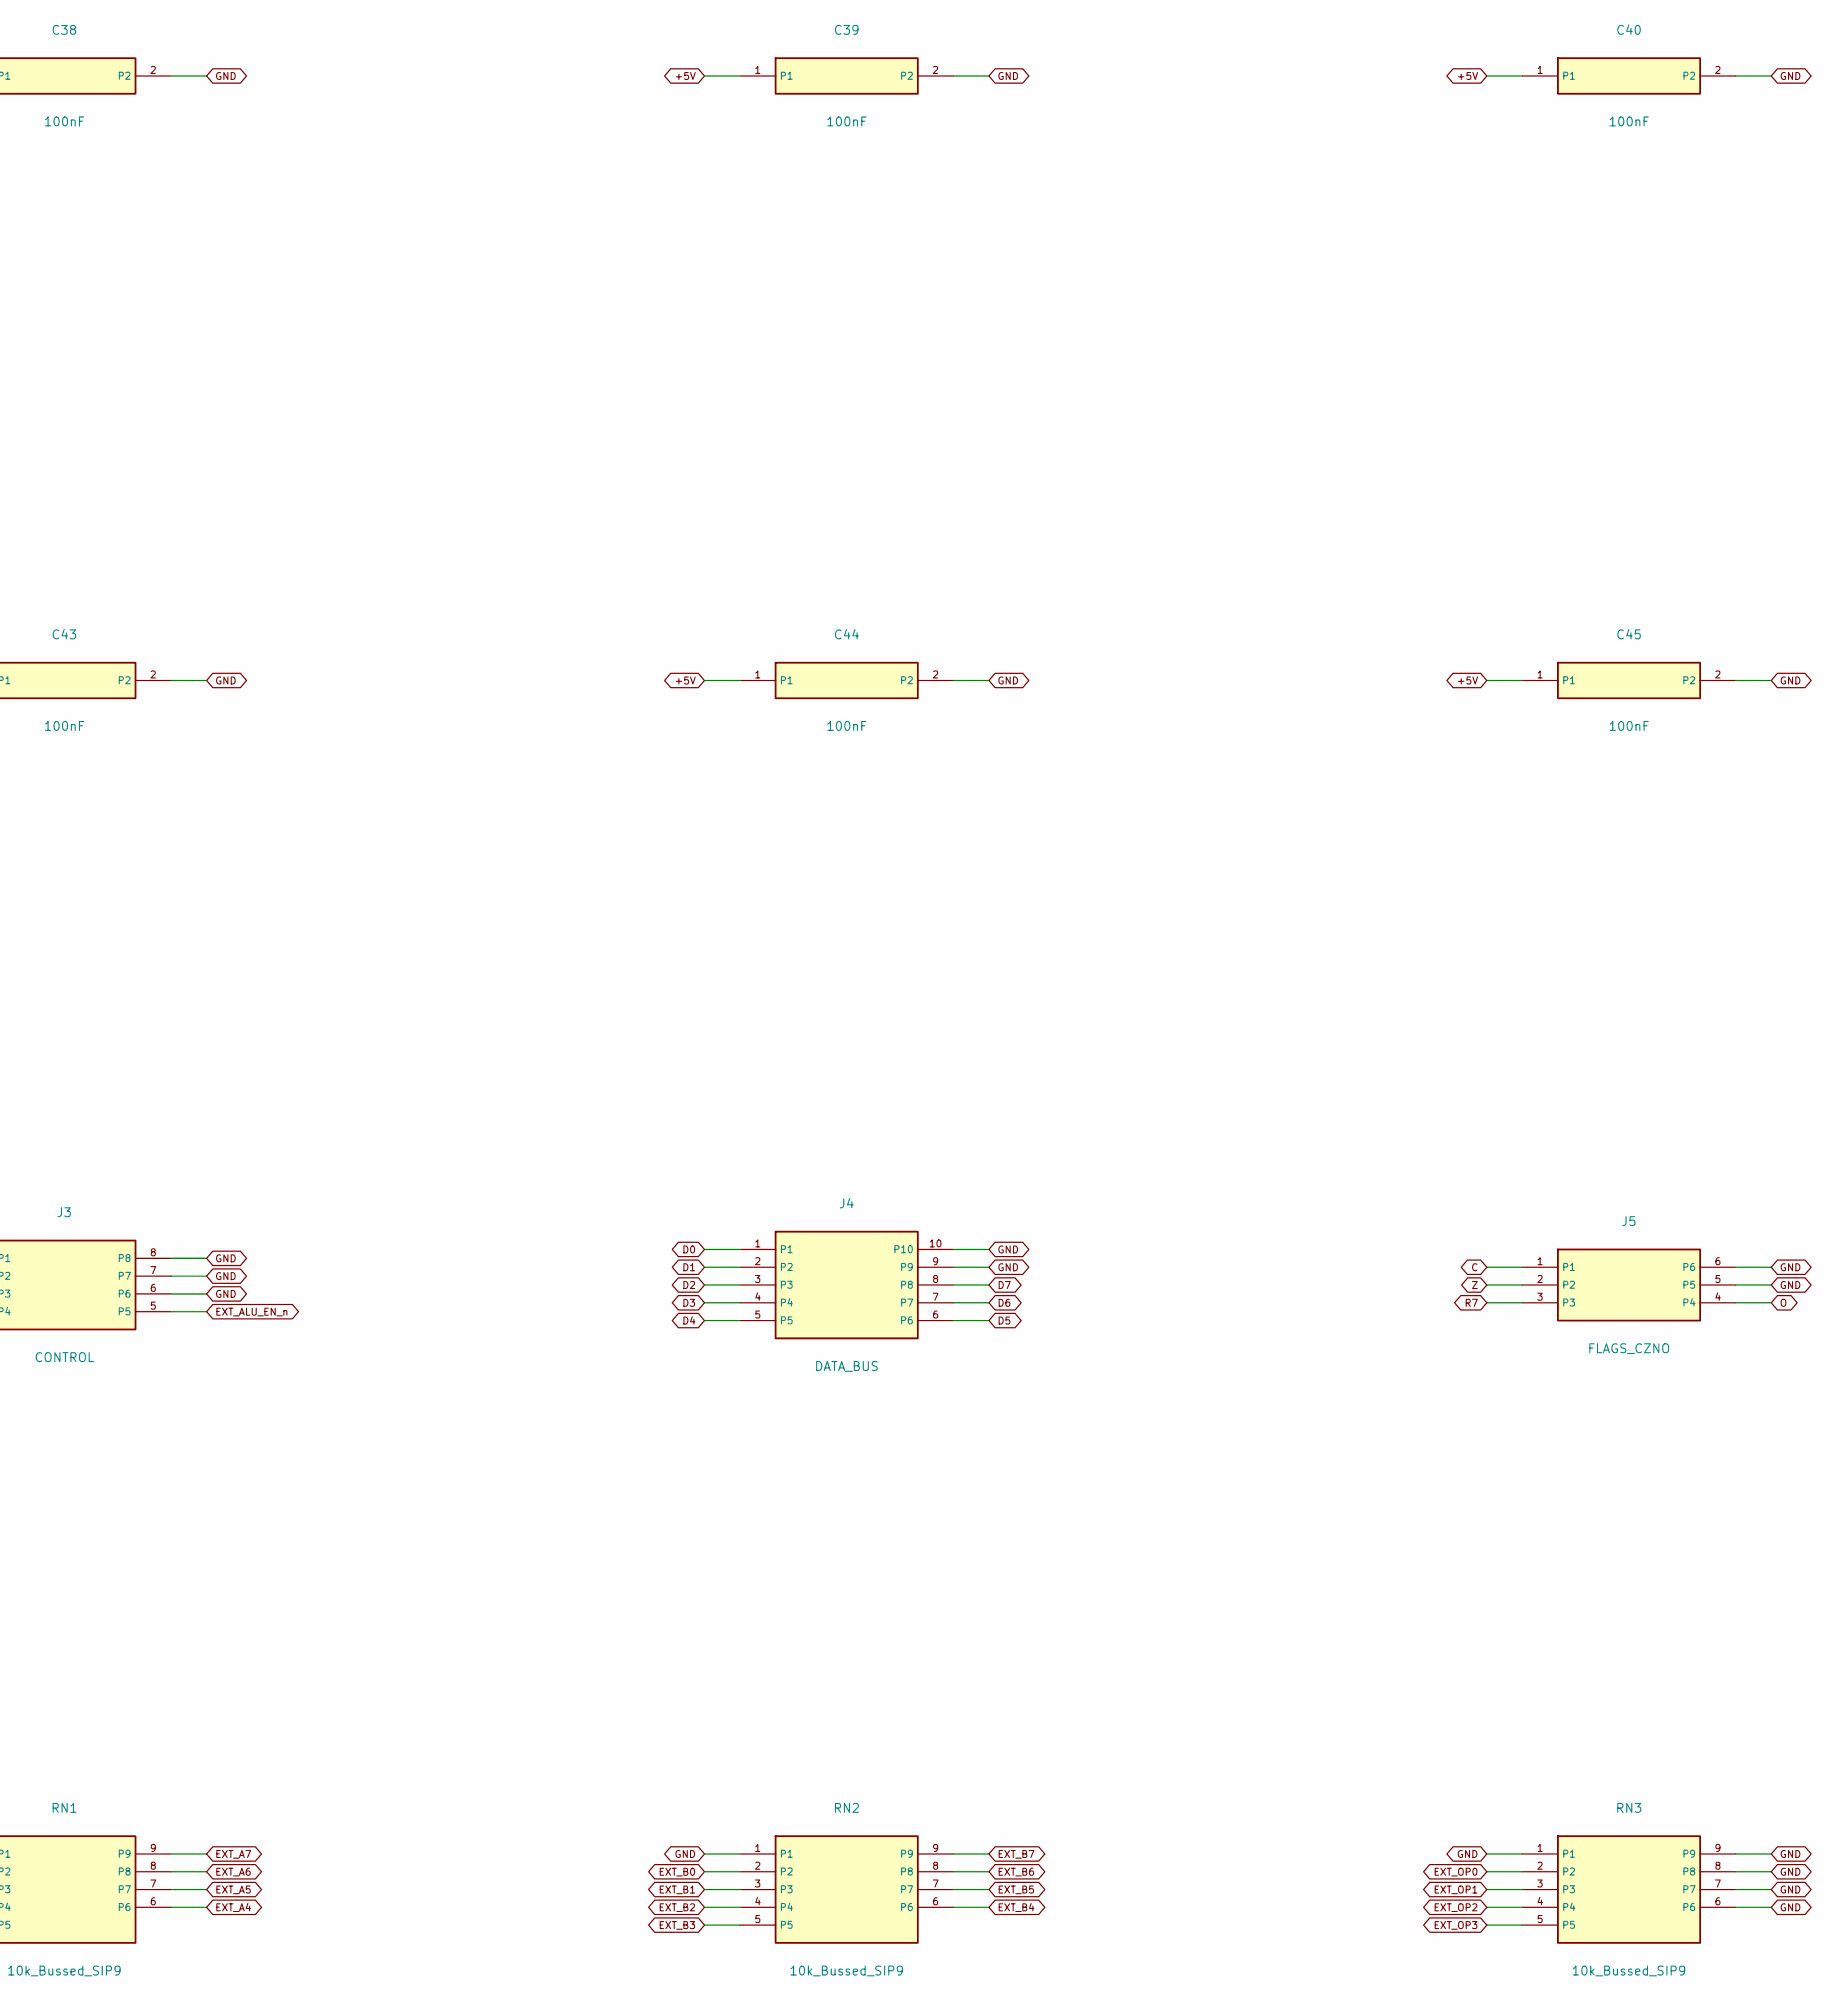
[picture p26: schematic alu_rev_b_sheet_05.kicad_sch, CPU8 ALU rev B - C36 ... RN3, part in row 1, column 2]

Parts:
C36, C37, C38, C39, C40, C41, C42, C43, C44, C45: 100nF; C_Disc_P2.50mm
J1: A_INPUT; Header_2x5_P2.54mm
J2: B_INPUT; Header_2x5_P2.54mm
J3: CONTROL; Header_2x4_P2.54mm
J4: DATA_BUS; Header_2x5_P2.54mm
J5: FLAGS_CZNO; Header_2x3_P2.54mm
J6: POWER_5V; Header_2x2_P2.54mm
J7: RESULT_TEST; Header_2x5_P2.54mm
RN1, RN2, RN3: 10k_Bussed_SIP9; SIP-9_P2.54mm

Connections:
+5V: C36.1, C37.1, C38.1, C39.1, C40.1, C41.1, C42.1, C43.1, C44.1, C45.1, J6.1, J6.3; also elsewhere on the board
C: J5.1; also elsewhere on the board
D0: J4.1; also elsewhere on the board
D1: J4.2; also elsewhere on the board
D2: J4.3; also elsewhere on the board
D3: J4.4; also elsewhere on the board
D4: J4.5; also elsewhere on the board
D5: J4.6; also elsewhere on the board
D6: J4.7; also elsewhere on the board
D7: J4.8; also elsewhere on the board
EXT_A0: J1.1, RN1.2; also elsewhere on the board
EXT_A1: J1.2, RN1.3; also elsewhere on the board
EXT_A2: J1.3, RN1.4; also elsewhere on the board
EXT_A3: J1.4, RN1.5; also elsewhere on the board
EXT_A4: J1.5, RN1.6; also elsewhere on the board
EXT_A5: J1.6, RN1.7; also elsewhere on the board
EXT_A6: J1.7, RN1.8; also elsewhere on the board
EXT_A7: J1.8, RN1.9; also elsewhere on the board
EXT_ALU_EN_n: J3.5; also elsewhere on the board
EXT_B0: J2.1, RN2.2; also elsewhere on the board
EXT_B1: J2.2, RN2.3; also elsewhere on the board
EXT_B2: J2.3, RN2.4; also elsewhere on the board
EXT_B3: J2.4, RN2.5; also elsewhere on the board
EXT_B4: J2.5, RN2.6; also elsewhere on the board
EXT_B5: J2.6, RN2.7; also elsewhere on the board
EXT_B6: J2.7, RN2.8; also elsewhere on the board
EXT_B7: J2.8, RN2.9; also elsewhere on the board
EXT_OP0: J3.1, RN3.2; also elsewhere on the board
EXT_OP1: J3.2, RN3.3; also elsewhere on the board
EXT_OP2: J3.3, RN3.4; also elsewhere on the board
EXT_OP3: J3.4, RN3.5; also elsewhere on the board
GND: C36.2, C37.2, C38.2, C39.2, C40.2, C41.2, C42.2, C43.2, C44.2, C45.2, J1.9, J1.10, J2.9, J2.10, J3.6, J3.7, J3.8, J4.9, J4.10, J5.5, J5.6, J6.2, J6.4, J7.9, J7.10, RN1.1, RN2.1, RN3.1, RN3.6, RN3.7, RN3.8, RN3.9; also elsewhere on the board
O: J5.4; also elsewhere on the board
R0: J7.1; also elsewhere on the board
R1: J7.2; also elsewhere on the board
R2: J7.3; also elsewhere on the board
R3: J7.4; also elsewhere on the board
R4: J7.5; also elsewhere on the board
R5: J7.6; also elsewhere on the board
R6: J7.7; also elsewhere on the board
R7: J5.3, J7.8; also elsewhere on the board
Z: J5.2; also elsewhere on the board

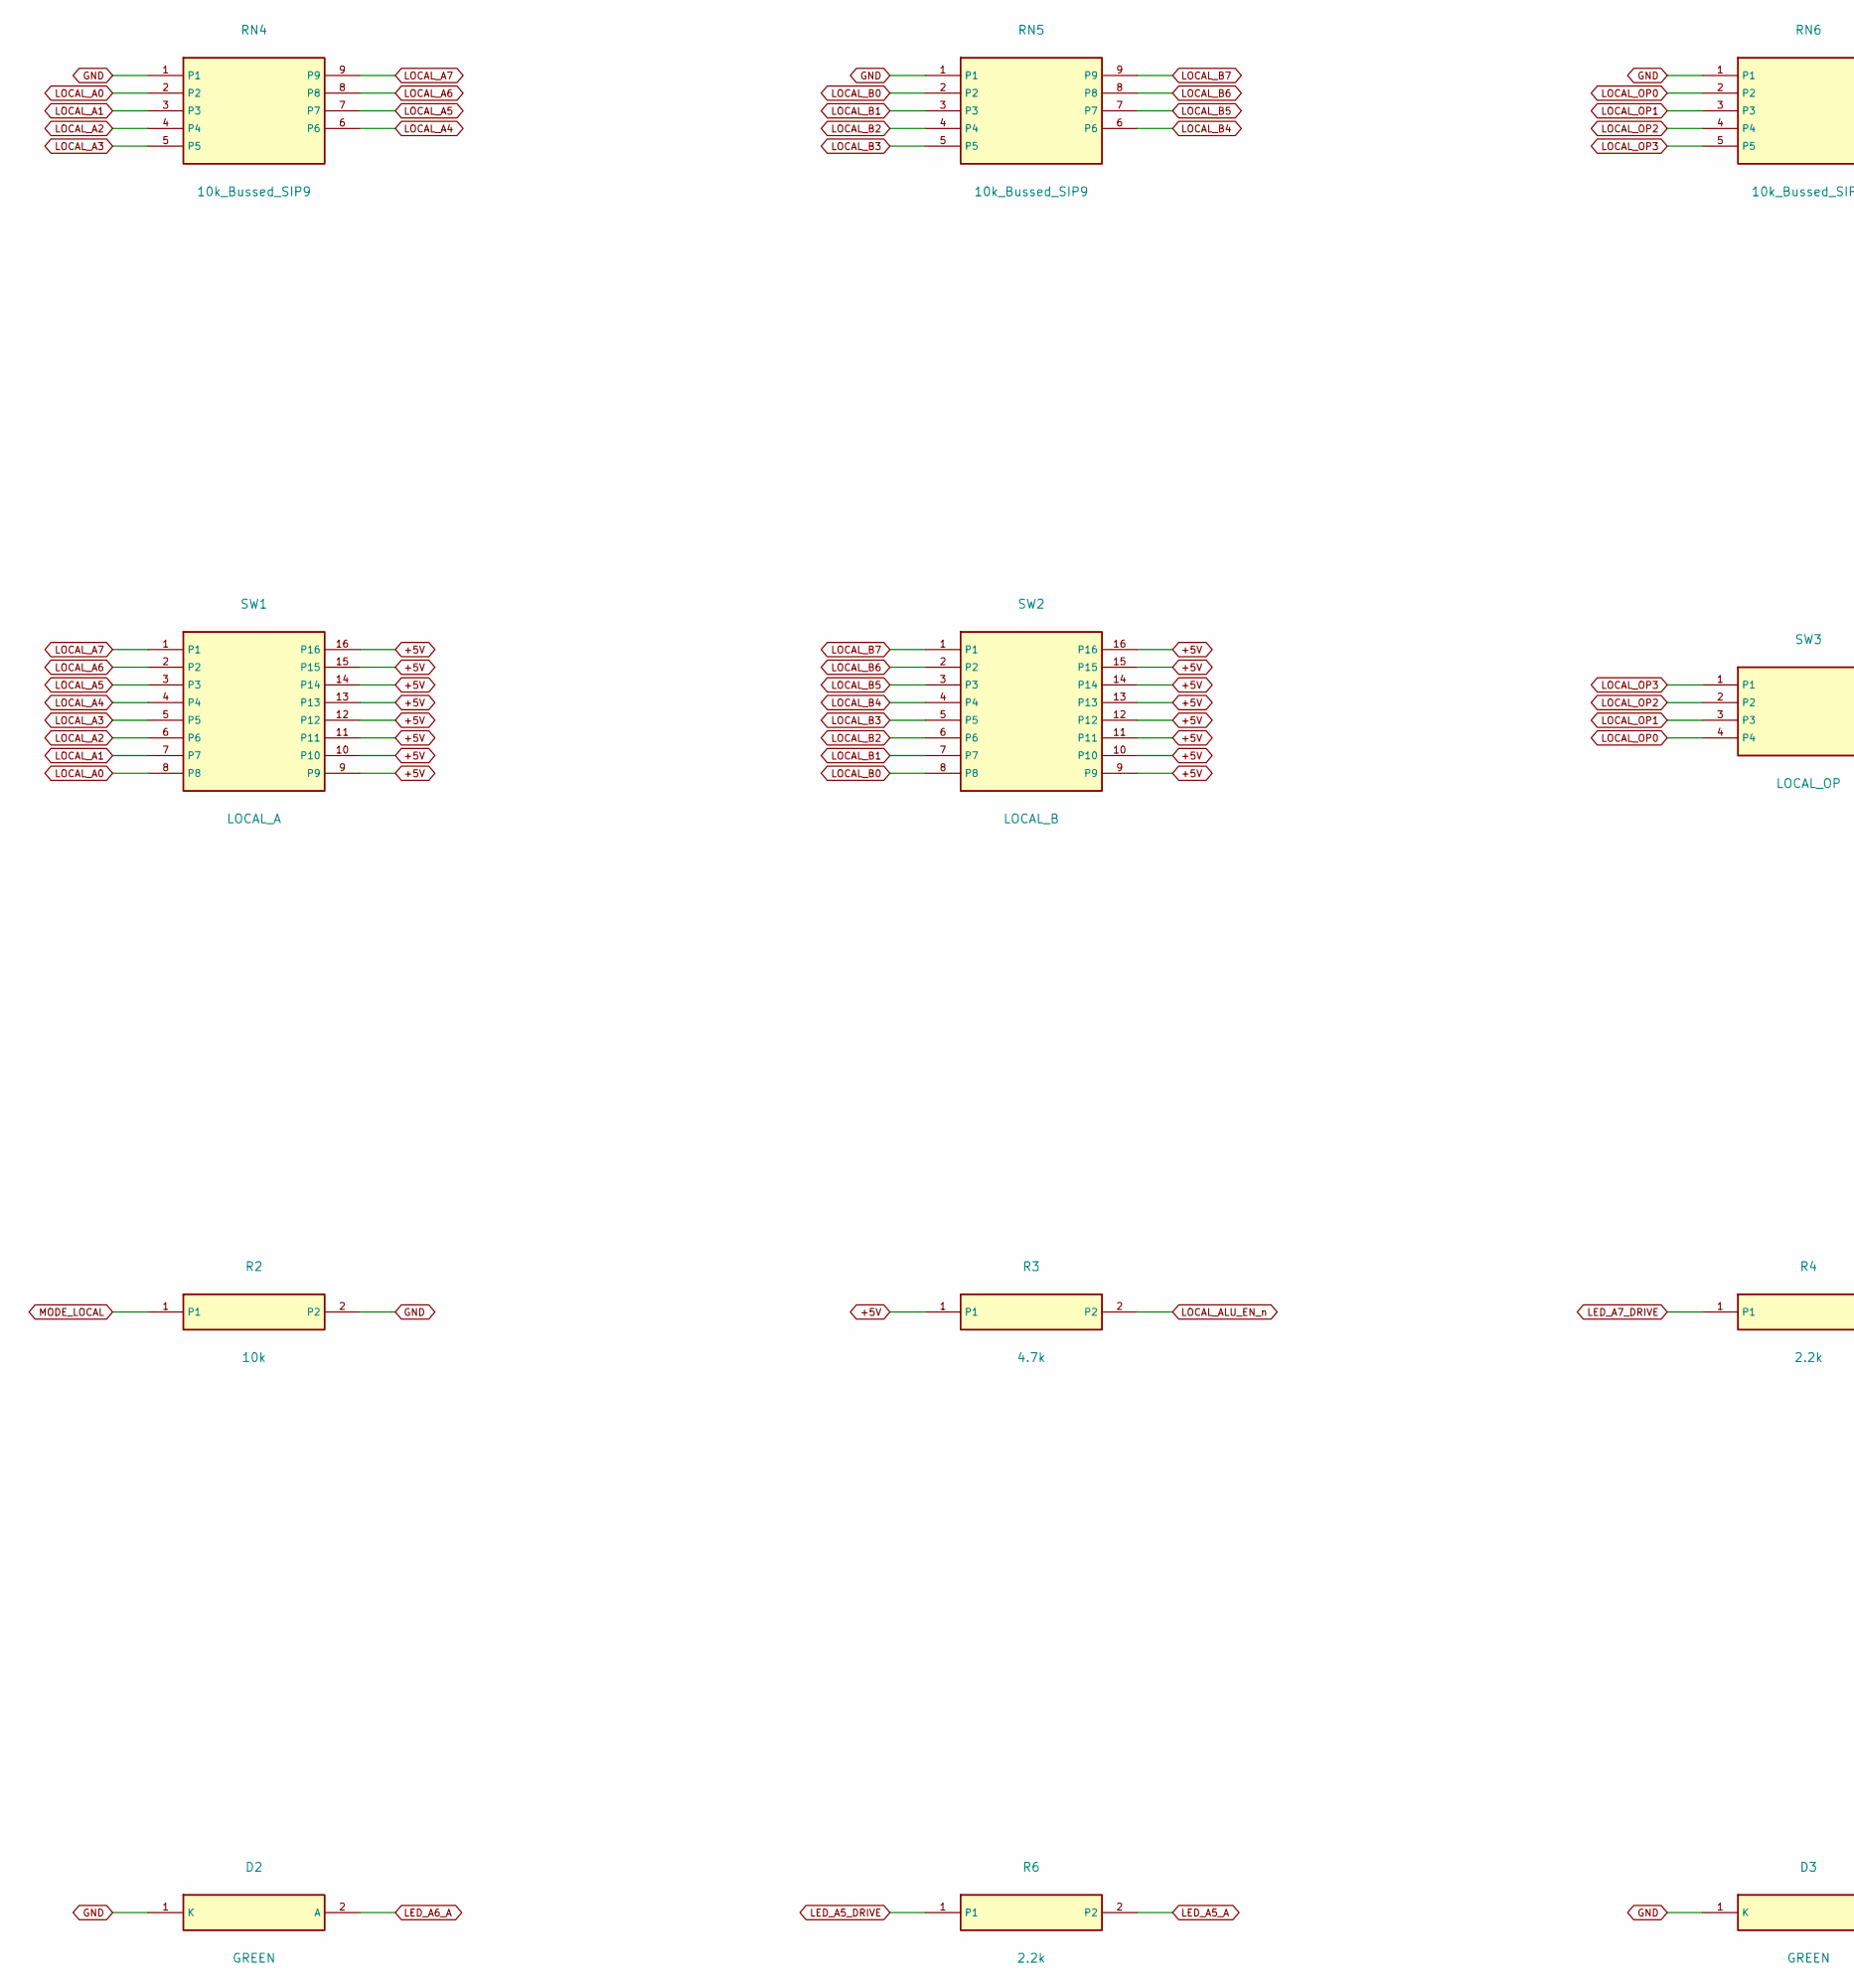
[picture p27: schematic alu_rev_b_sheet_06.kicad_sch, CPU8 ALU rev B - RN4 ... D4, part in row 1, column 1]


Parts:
C46: 10uF_16V; C_Radial_P2.50mm
D1, D2, D3, D4: GREEN; LED_D3.0mm_P2.54mm
R1, R3: 4.7k; R_Axial_P7.62mm
R2: 10k; R_Axial_P7.62mm
R4, R5, R6, R7: 2.2k; R_Axial_P7.62mm
RN4, RN5, RN6: 10k_Bussed_SIP9; SIP-9_P2.54mm
SW1: LOCAL_A; SW_DIP_SPST_8_P2.54_W7.62
SW2: LOCAL_B; SW_DIP_SPST_8_P2.54_W7.62
SW3: LOCAL_OP; SW_DIP_SPST_4_P2.54_W7.62
SW4: MODE_LOCAL; SW_DIP_SPST_1_P2.54_W7.62
SW5: LOCAL_BUS_ENABLE; SW_DIP_SPST_1_P2.54_W7.62

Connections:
+5V: C46.1, R1.1, R3.1, SW1.9, SW1.10, SW1.11, SW1.12, SW1.13, SW1.14, SW1.15, SW1.16, SW2.9, SW2.10, SW2.11, SW2.12, SW2.13, SW2.14, SW2.15, SW2.16, SW3.5, SW3.6, SW3.7, SW3.8, SW4.2; also elsewhere on the board
EXT_ALU_EN_n: R1.2; also elsewhere on the board
GND: C46.2, D1.1 (K), D2.1 (K), D3.1 (K), D4.1 (K), R2.2, RN4.1, RN5.1, RN6.1, RN6.6, RN6.7, RN6.8, RN6.9, SW5.2; also elsewhere on the board
LED_A4_A: D4.2 (A), R7.2
LED_A4_DRIVE: R7.1; also elsewhere on the board
LED_A5_A: D3.2 (A), R6.2
LED_A5_DRIVE: R6.1; also elsewhere on the board
LED_A6_A: D2.2 (A), R5.2
LED_A6_DRIVE: R5.1; also elsewhere on the board
LED_A7_A: D1.2 (A), R4.2
LED_A7_DRIVE: R4.1; also elsewhere on the board
LOCAL_A0: RN4.2, SW1.8; also elsewhere on the board
LOCAL_A1: RN4.3, SW1.7; also elsewhere on the board
LOCAL_A2: RN4.4, SW1.6; also elsewhere on the board
LOCAL_A3: RN4.5, SW1.5; also elsewhere on the board
LOCAL_A4: RN4.6, SW1.4; also elsewhere on the board
LOCAL_A5: RN4.7, SW1.3; also elsewhere on the board
LOCAL_A6: RN4.8, SW1.2; also elsewhere on the board
LOCAL_A7: RN4.9, SW1.1; also elsewhere on the board
LOCAL_ALU_EN_n: R3.2, SW5.1; also elsewhere on the board
LOCAL_B0: RN5.2, SW2.8; also elsewhere on the board
LOCAL_B1: RN5.3, SW2.7; also elsewhere on the board
LOCAL_B2: RN5.4, SW2.6; also elsewhere on the board
LOCAL_B3: RN5.5, SW2.5; also elsewhere on the board
LOCAL_B4: RN5.6, SW2.4; also elsewhere on the board
LOCAL_B5: RN5.7, SW2.3; also elsewhere on the board
LOCAL_B6: RN5.8, SW2.2; also elsewhere on the board
LOCAL_B7: RN5.9, SW2.1; also elsewhere on the board
LOCAL_OP0: RN6.2, SW3.4; also elsewhere on the board
LOCAL_OP1: RN6.3, SW3.3; also elsewhere on the board
LOCAL_OP2: RN6.4, SW3.2; also elsewhere on the board
LOCAL_OP3: RN6.5, SW3.1; also elsewhere on the board
MODE_LOCAL: R2.1, SW4.1; also elsewhere on the board

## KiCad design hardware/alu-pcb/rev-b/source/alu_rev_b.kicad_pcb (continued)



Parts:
D5, D6, D7, D8, D9, D10, D11, D12, D13, D14: GREEN; LED_D3.0mm_P2.54mm
R8, R9, R10, R11, R12, R13, R14, R15, R16, R17: 2.2k; R_Axial_P7.62mm

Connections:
GND: D5.1 (K), D6.1 (K), D7.1 (K), D8.1 (K), D9.1 (K), D10.1 (K), D11.1 (K), D12.1 (K), D13.1 (K), D14.1 (K); also elsewhere on the board
LED_A0_A: D8.2 (A), R11.2
LED_A0_DRIVE: R11.1; also elsewhere on the board
LED_A1_A: D7.2 (A), R10.2
LED_A1_DRIVE: R10.1; also elsewhere on the board
LED_A2_A: D6.2 (A), R9.2
LED_A2_DRIVE: R9.1; also elsewhere on the board
LED_A3_A: D5.2 (A), R8.2
LED_A3_DRIVE: R8.1; also elsewhere on the board
LED_B2_A: D14.2 (A), R17.2
LED_B2_DRIVE: R17.1; also elsewhere on the board
LED_B3_A: D13.2 (A), R16.2
LED_B3_DRIVE: R16.1; also elsewhere on the board
LED_B4_A: D12.2 (A), R15.2
LED_B4_DRIVE: R15.1; also elsewhere on the board
LED_B5_A: D11.2 (A), R14.2
LED_B5_DRIVE: R14.1; also elsewhere on the board
LED_B6_A: D10.2 (A), R13.2
LED_B6_DRIVE: R13.1; also elsewhere on the board
LED_B7_A: D9.2 (A), R12.2
LED_B7_DRIVE: R12.1; also elsewhere on the board

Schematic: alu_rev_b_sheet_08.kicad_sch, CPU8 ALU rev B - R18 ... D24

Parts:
D15, D16: GREEN; LED_D3.0mm_P2.54mm
D17, D18, D19, D20: YELLOW; LED_D3.0mm_P2.54mm
D21, D22, D23, D24: BLUE; LED_D3.0mm_P2.54mm
R18, R19, R20, R21, R22, R23, R24, R25, R26, R27: 2.2k; R_Axial_P7.62mm

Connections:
+5V: R24.1, R25.1, R26.1, R27.1; also elsewhere on the board
GND: D15.1 (K), D16.1 (K), D17.1 (K), D18.1 (K), D19.1 (K), D20.1 (K); also elsewhere on the board
LED_AND_A: D21.2 (A), R24.2
LED_B0_A: D16.2 (A), R19.2
LED_B0_DRIVE: R19.1; also elsewhere on the board
LED_B1_A: D15.2 (A), R18.2
LED_B1_DRIVE: R18.1; also elsewhere on the board
LED_C_A: D17.2 (A), R20.2
LED_C_DRIVE: R20.1; also elsewhere on the board
LED_NOR_A: D24.2 (A), R27.2
LED_N_A: D19.2 (A), R22.2
LED_N_DRIVE: R22.1; also elsewhere on the board
LED_OR_A: D22.2 (A), R25.2
LED_O_A: D20.2 (A), R23.2
LED_O_DRIVE: R23.1; also elsewhere on the board
LED_XOR_A: D23.2 (A), R26.2
LED_Z_A: D18.2 (A), R21.2
LED_Z_DRIVE: R21.1; also elsewhere on the board
OP_AND_n: D21.1 (K); also elsewhere on the board
OP_NOR_n: D24.1 (K); also elsewhere on the board
OP_OR_n: D22.1 (K); also elsewhere on the board
OP_XOR_n: D23.1 (K); also elsewhere on the board

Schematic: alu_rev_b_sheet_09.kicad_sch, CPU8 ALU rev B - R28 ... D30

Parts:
D25, D26, D27, D28, D29, D30: BLUE; LED_D3.0mm_P2.54mm
R28, R29, R30, R31, R32, R33: 2.2k; R_Axial_P7.62mm

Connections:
+5V: R28.1, R29.1, R30.1, R31.1, R32.1, R33.1; also elsewhere on the board
LED_ADD_A: D28.2 (A), R31.2
LED_CMP_A: D30.2 (A), R33.2
LED_NAND_A: D25.2 (A), R28.2
LED_NOT_A: D27.2 (A), R30.2
LED_SUB_A: D29.2 (A), R32.2
LED_XNOR_A: D26.2 (A), R29.2
OP_ADD_n: D28.1 (K); also elsewhere on the board
OP_CMP_n: D30.1 (K); also elsewhere on the board
OP_NAND_n: D25.1 (K); also elsewhere on the board
OP_NOT_n: D27.1 (K); also elsewhere on the board
OP_SUB_n: D29.1 (K); also elsewhere on the board
OP_XNOR_n: D26.1 (K); also elsewhere on the board


Board: 2 copper layers, 290.0 x 300.0 mm, 172 parts (0 on the bottom side), 242 nets.

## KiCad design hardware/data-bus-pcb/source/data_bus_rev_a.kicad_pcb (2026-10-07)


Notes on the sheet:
8 bidirectional parallel ports: D0..D7 on pins 1..8, GND on pins 9/10 Only one external tri-state writer may be enabled at a time U1 drives the LEDs; it never drives the bus J9: +5V / GND; data ports do not carry power SW1 ON enables bit LEDs; OFF pulls OE_n high through 10k; PWR stays on



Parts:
C1: 100nF; C_Disc_P2.50mm
C2: 10uF_16V; C_Radial_P2.50mm
D6, D7, D8: GREEN; LED_D3.0mm_P2.54mm_Vertical
J1: BUS1; Header_2x5_P2.54mm
J2: BUS2; Header_2x5_P2.54mm
J3: BUS3; Header_2x5_P2.54mm
J4: BUS4; Header_2x5_P2.54mm
J5: BUS5; Header_2x5_P2.54mm
J6: BUS6; Header_2x5_P2.54mm
J7: BUS7; Header_2x5_P2.54mm
J8: BUS8; Header_2x5_P2.54mm
J9: POWER_5V; Header_2x2_P2.54mm
R5, R6, R7, R8: 2.2k; R_Axial_P7.62mm
RN1: 10k_Bussed_SIP9; SIP-9_P2.54mm
U1: SN74HCT244N; DIP-20_W7.62mm

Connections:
+5V: C1.1, C2.1, J9.1, J9.3, U1.20 (VCC); also elsewhere on the board
D0: J1.1, J2.1, J3.1, J4.1, J5.1, J6.1, J7.1, J8.1, RN1.2, U1.2 (1A1)
D1: J1.2, J2.2, J3.2, J4.2, J5.2, J6.2, J7.2, J8.2, RN1.3, U1.4 (1A2)
D2: J1.3, J2.3, J3.3, J4.3, J5.3, J6.3, J7.3, J8.3, RN1.4, U1.6 (1A3)
D3: J1.4, J2.4, J3.4, J4.4, J5.4, J6.4, J7.4, J8.4, RN1.5, U1.8 (1A4)
D4: J1.5, J2.5, J3.5, J4.5, J5.5, J6.5, J7.5, J8.5, RN1.6, U1.11 (2A1)
D5: J1.6, J2.6, J3.6, J4.6, J5.6, J6.6, J7.6, J8.6, RN1.7, U1.13 (2A2)
D6: J1.7, J2.7, J3.7, J4.7, J5.7, J6.7, J7.7, J8.7, RN1.8, U1.15 (2A3)
D7: J1.8, J2.8, J3.8, J4.8, J5.8, J6.8, J7.8, J8.8, RN1.9, U1.17 (2A4)
GND: C1.2, C2.2, D6.1 (K), D7.1 (K), D8.1 (K), J1.9, J1.10, J2.9, J2.10, J3.9, J3.10, J4.9, J4.10, J5.9, J5.10, J6.9, J6.10, J7.9, J7.10, J8.9, J8.10, J9.2, J9.4, RN1.1, U1.10 (GND); also elsewhere on the board
LED_D0_DRIVE: U1.18 (1Y1); also elsewhere on the board
LED_D1_DRIVE: U1.16 (1Y2); also elsewhere on the board
LED_D2_DRIVE: U1.14 (1Y3); also elsewhere on the board
LED_D3_DRIVE: U1.12 (1Y4); also elsewhere on the board
LED_D4_A: R5.2; also elsewhere on the board
LED_D4_DRIVE: R5.1, U1.9 (2Y1)
LED_D5_A: D6.2 (A), R6.2
LED_D5_DRIVE: R6.1, U1.7 (2Y2)
LED_D6_A: D7.2 (A), R7.2
LED_D6_DRIVE: R7.1, U1.5 (2Y3)
LED_D7_A: D8.2 (A), R8.2
LED_D7_DRIVE: R8.1, U1.3 (2Y4)
LED_OE_n: U1.1 (OE1_n), U1.19 (OE2_n); also elsewhere on the board

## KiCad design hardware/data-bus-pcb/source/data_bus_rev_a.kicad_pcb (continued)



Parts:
D1, D2, D3, D4, D5: GREEN; LED_D3.0mm_P2.54mm_Vertical
D9: GREEN; LED_D3.0mm_P2.54mm
R1, R2, R3, R4, R9: 2.2k; R_Axial_P7.62mm
R10: 10k; R_Axial_P7.62mm
SW1: SDA01H0BD_LED_ENABLE; SW_DIP_SPST_1_P2.54_W7.62

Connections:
+5V: R9.1, R10.1; also elsewhere on the board
GND: D1.1 (K), D2.1 (K), D3.1 (K), D4.1 (K), D5.1 (K), D9.1 (K), SW1.2 (GND); also elsewhere on the board
LED_D0_A: D1.2 (A), R1.2
LED_D0_DRIVE: R1.1; also elsewhere on the board
LED_D1_A: D2.2 (A), R2.2
LED_D1_DRIVE: R2.1; also elsewhere on the board
LED_D2_A: D3.2 (A), R3.2
LED_D2_DRIVE: R3.1; also elsewhere on the board
LED_D3_A: D4.2 (A), R4.2
LED_D3_DRIVE: R4.1; also elsewhere on the board
LED_D4_A: D5.2 (A); also elsewhere on the board
LED_OE_n: R10.2, SW1.1 (LED_OE_n); also elsewhere on the board
LED_PWR_A: D9.2 (A), R9.2


Board: 2 copper layers, 235.0 x 40.0 mm, 33 parts (0 on the bottom side), 28 nets.

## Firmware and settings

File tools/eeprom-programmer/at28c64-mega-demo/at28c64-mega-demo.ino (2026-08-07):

/*
 * Demo minimale: programma e verifica alcuni byte su una AT28C64B.
 *
 * Segnali di controllo, tutti attivi a livello basso:
 *
 *   Operazione       /CE  /OE  /WE  Bus dati
 *   Lettura           0    0    1   EEPROM -> Arduino
 *   Scrittura         0    1   0->1 Arduino -> EEPROM
 *   Riposo            1    1    1   alta impedenza
 */

#include <Arduino.h>

static const uint8_t ADDRESS_PINS[13] = {
    22, 23, 24, 25, 26, 27, 28, 29, 30, 31, 32, 33, 34};

static const uint8_t DATA_PINS[8] = {
    35, 36, 37, 38, 39, 40, 41, 42};

static const uint8_t PIN_CE = 43;
static const uint8_t PIN_OE = 44;
static const uint8_t PIN_WE = 45;

/* Tempi volutamente conservativi per una AT28C64B. */
static const uint8_t READ_SETTLE_US = 1;
static const uint8_t WRITE_PULSE_US = 1;
static const uint8_t WRITE_SETTLE_MS = 15;

/*
 * I byte che il demo scrive a partire dall'indirizzo 0000.
 * Ogni cifra binaria corrisponde a una linea del bus, da I/O7 a I/O0:
 *
 *   0b10100110  -> I/O7=1, I/O6=0, I/O5=1, I/O4=0,
 *                  I/O3=0, I/O2=1, I/O1=1, I/O0=0
 *
 * Cambia o aggiungi qui i byte che vuoi passare alla EEPROM.
 */
static const uint8_t DEMO_PROGRAM[] = {
    0b00000000,
    0b00000001,
    0b00000010,
    0b00000011,
    0b01010101,
    0b10101010,
    0b11110000,
    0b00001111,
    0b10100110,
    0b11111111};

/*
 * Imposta A0..A12 della EEPROM.
 * Il bit 0 dell'indirizzo va su A0, il bit 12 va su A12.
 */
static void setAddress(uint16_t address)
{
  for (uint8_t bit = 0; bit < 13; bit++)
  {
    digitalWrite(ADDRESS_PINS[bit], bitRead(address, bit) ? HIGH : LOW);
  }
}

/*
 * Rilascia il bus dati affinche la EEPROM possa pilotarlo durante una lettura.
 * Prima azzera il latch del pin per evitare di abilitare involontariamente le
 * resistenze di pull-up interne dell'Arduino quando il pin diventa INPUT.
 */
static void setDataBusInput() // Lettura dealla EEPROM
{
  for (uint8_t bit = 0; bit < 8; bit++)
  {
    digitalWrite(DATA_PINS[bit], LOW);
    pinMode(DATA_PINS[bit], INPUT);
  }
}

/*
 * Configura I/O0..I/O7 come uscite, cosi Arduino puo presentare un byte alla
 * EEPROM. Va chiamata solo quando /OE e alto, quindi con le uscite EEPROM spente.
 */
static void setDataBusOutput() // Scrittura verso la EEPROM
{
  for (uint8_t bit = 0; bit < 8; bit++)
  {
    pinMode(DATA_PINS[bit], OUTPUT);
  }
}

/* Scrive gli otto bit di value sul bus dati Arduino -> EEPROM. */
static void writeDataBus(uint8_t value)
{
  for (uint8_t bit = 0; bit < 8; bit++)
  {
    digitalWrite(DATA_PINS[bit], bitRead(value, bit) ? HIGH : LOW);
  }
}

/* Legge gli otto bit presenti sul bus dati EEPROM -> Arduino. */
static uint8_t readDataBus()
{
  uint8_t value = 0b00000000;

  for (uint8_t bit = 0; bit < 8; bit++)
  {
    if (digitalRead(DATA_PINS[bit]) == HIGH)
    {
      bitSet(value, bit);
    }
  }

  return value;
}

/*
 * Esegue una scrittura di un byte.
 * Indirizzo e dato sono gia stabili prima dell'impulso basso su /WE; il fronte
 * di risalita di /WE avvia la programmazione interna della EEPROM.
 */
static void writeByte(uint16_t address, uint8_t value)
{
  setAddress(address);

  /* /OE alto: la EEPROM non guida il bus mentre Arduino lo configura. */
  digitalWrite(PIN_OE, HIGH);
  setDataBusOutput();
  writeDataBus(value);

  digitalWrite(PIN_CE, LOW);
  digitalWrite(PIN_WE, LOW);
  delayMicroseconds(WRITE_PULSE_US);
  digitalWrite(PIN_WE, HIGH);
  digitalWrite(PIN_CE, HIGH);

  /* Il massimo dichiarato e 10 ms; 15 ms lascia margine. */
  delay(WRITE_SETTLE_MS);
}

/*
 * Legge un byte dalla EEPROM.
 * Arduino mette il bus in INPUT, seleziona la EEPROM e ne abilita le uscite.
 */
static uint8_t readByte(uint16_t address)
{
  /* La EEPROM e lasciata inattiva da writeByte() o dalla lettura precedente. */
  digitalWrite(PIN_OE, HIGH);
  digitalWrite(PIN_CE, HIGH);
  digitalWrite(PIN_WE, HIGH);

  setDataBusInput();
  setAddress(address);

  digitalWrite(PIN_CE, LOW);
  digitalWrite(PIN_OE, LOW);
  delayMicroseconds(READ_SETTLE_US);

  uint8_t value = readDataBus();

  /* Disabilita le uscite EEPROM prima di una futura scrittura o lettura. */
  digitalWrite(PIN_OE, HIGH);
  digitalWrite(PIN_CE, HIGH);

  return value;
}

/* Stampa un byte come otto bit, dal piu significativo I/O7 al meno significativo I/O0. */
static void printBinaryByte(uint8_t value)
{
  for (int8_t bit = 7; bit >= 0; bit--)
  {
    Serial.print(bitRead(value, bit) ? '1' : '0');
  }
}

/*
 * Scrive tutti i byte di DEMO_PROGRAM e confronta ogni lettura con il byte
 * atteso. Restituisce true solo se tutte le verifiche hanno successo.
 */
static bool writeDemoAndVerify()
{
  bool ok = true;

  for (uint16_t address = 0; address < sizeof(DEMO_PROGRAM); address++)
  {
    uint8_t expected = DEMO_PROGRAM[address];
    writeByte(address, expected);

    uint8_t readBack = readByte(address);
    Serial.print(F("indirizzo "));
    printBinaryByte(address);
    Serial.print(F(": scritto "));
    Serial.print(F(" (0b"));
    printBinaryByte(expected);
    Serial.print(F(")"));
    Serial.print(F(", letto "));
    Serial.print(F(" (0b"));
    printBinaryByte(readBack);
    Serial.print(F(")"));

    if (readBack == expected)
    {
      Serial.println(F(" OK"));
    }
    else
    {
      Serial.println(F(" ERRORE"));
      ok = false;
    }
  }

  return ok;
}

/*
 * Inizializza i pin, porta la EEPROM nello stato sicuro di riposo e avvia il
 * test una sola volta quando Arduino si accende o viene resettato.
 */
void setup()
{
  Serial.begin(115200);

  for (uint8_t bit = 0; bit < 13; bit++)
  {
    pinMode(ADDRESS_PINS[bit], OUTPUT);
    digitalWrite(ADDRESS_PINS[bit], LOW);
  }

  pinMode(PIN_CE, OUTPUT);
  pinMode(PIN_OE, OUTPUT);
  pinMode(PIN_WE, OUTPUT);
  digitalWrite(PIN_CE, HIGH);
  digitalWrite(PIN_OE, HIGH);
  digitalWrite(PIN_WE, HIGH);
  setDataBusInput();

  Serial.println(F("AT28C64B: scrittura demo"));

  if (writeDemoAndVerify())
  {
    Serial.println(F("OK: programma verificato"));
  }
  else
  {
    Serial.println(F("ERRORE: verifica fallita"));
  }
}

/* Il demo ha gia eseguito tutto in setup(), quindi non deve ripetere nulla. */
void loop()
{
}

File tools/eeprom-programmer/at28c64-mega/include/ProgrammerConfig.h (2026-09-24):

#ifndef CPU8_AT28C64_PROGRAMMER_CONFIG_H
#define CPU8_AT28C64_PROGRAMMER_CONFIG_H

#include <Arduino.h>

/*
 * Configurazione hardware del programmatore.
 *
 * Se in futuro cambi cablaggio, questa dovrebbe essere la prima sezione da
 * modificare. La logica in src/EepromBus.cpp usa questi valori senza conoscere
 * direttamente il numero dei pin Arduino.
 */

static const uint16_t EEPROM_SIZE = 8192;
static const uint16_t EEPROM_LAST_ADDRESS = EEPROM_SIZE - 1;

static const uint32_t SERIAL_BAUD = 115200;
static const uint8_t SERIAL_LINE_BUFFER_SIZE = 96;
/* Il caricatore affidabile aspetta un ACK per ogni blocco, quindi non satura RX. */
static const uint8_t UPLOAD_BLOCK_MAX_BYTES = 16;

/*
 * A0..A12 della EEPROM AT28C64.
 * L'indice dell'array corrisponde al bit dell'indirizzo:
 * ADDRESS_PINS[0] -> A0, ADDRESS_PINS[12] -> A12.
 */
static const uint8_t ADDRESS_PINS[13] = {
    22, 23, 24, 25, 26, 27, 28, 29, 30, 31, 32, 33, 34
};

/*
 * I/O0..I/O7 della EEPROM.
 * Anche qui l'indice dell'array corrisponde al bit del byte.
 */
static const uint8_t DATA_PINS[8] = {
    35, 36, 37, 38, 39, 40, 41, 42
};

static const uint8_t PIN_CE = 43;
static const uint8_t PIN_OE = 44;
static const uint8_t PIN_WE = 45;

/*
 * Timing conservativi per byte write.
 * Dopo l'impulso su WE lo sketch aspetta un tempo fisso e poi verifica
 * rileggendo il byte. La AT28C64B dichiara un ciclo di scrittura massimo di
 * 10 ms; 15 ms lascia margine su breadboard.
 */
static const uint8_t READ_SETTLE_US = 1;
static const uint8_t WRITE_PULSE_US = 10;
static const uint8_t WRITE_SETTLE_MS = 15;

#endif

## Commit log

2026-07-13 Improve assembler outputs and AT28C64 programmer docs (#1)
    * Define initial CPU ISA
    * Refine ISA register transfer model
    * Add assembler scaffold and ISA docs
    * Implement initial assembler pipeline
    * Document ISA opcode categories
    * Restore extended ISA opcode tables
    * Add ISA assembly examples
    * Add AT28C64 Arduino Mega programmer
    * Fix AT28C64 programmer timing and docs
    * Add textual binary dump output
    * docs(isa): clarify jump instructions and comparison conditions
    * Improve assembler syntax and teaching examples
    * Order assembly examples by learning progression
    * Remove AT28C64 single-cell demo
    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
    [EepromBus.cpp]
2026-07-13 Add assembly to machine code transcript
2026-08-07 docs: simplify AT28C64 Arduino programmer guide
2026-08-07 docs: update CPU learning materials
2026-10-07 Add ALU rev B and data/address bus rev A PCB projects
    [BOM.csv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]
